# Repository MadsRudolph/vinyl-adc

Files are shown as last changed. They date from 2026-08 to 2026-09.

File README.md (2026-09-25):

# Vinyl ADC

[Assembly guide & bench log](https://vinyl-adc.madsrudolph.dev/) · [Bring-up log, 16–18 September](docs/bringup-log-2026-09.md) · [16 September bench plan](assembly/sessions/2026-09-16/README.md) · [6 September test handoff](assembly/sessions/2026-09-06/README.md)

All four boards are assembled and bench-screened with the AD3 (16–17 September): power, rev B digital with the on-board crystal Pierce, both channels and the full stack pass, after resoldering a crystal leg and swapping the reference op-amp U2 to an LM358 for output headroom on the charge-pump rail (design-notes §10b′). A Raspberry Pi 4 captures the stream, and a ripper service on it records sides automatically, splits and tags the tracks and hands finished albums to the Jellyfin server; setup in [pi/README.md](pi/README.md) and [server/README.md](server/README.md). No complete-system audio performance is claimed by these assembly tests.

**Rev C (22 September):** with a fab available, the four milled boards are redrawn as [one 4-layer board](hardware/kicad/rev_c/README.md), 170 × 120 mm, all through-hole, with the Raspberry Pi 4 plugged into its underside on its own 40-pin header and the bench fixes (LM358 reference, filtered 5 V inlet, series resistors on the I2S clocks) built in. It passes the same intent gate as the milled boards against the reference sheet; [production files](production/vinyl_adc_rev_c/) and a [bill of materials](docs/bom-rev-c.md) are exported. It has not been built yet; the measured milled stack above is the baseline it will be compared to.

**Rev D (22 September):** with PCBWay sponsoring the fabrication, the one-board converter is redrawn as a proper [Raspberry Pi HAT](hardware/kicad/rev_d/README.md) — 140 × 136 mm (its layout redone on 24 September: every passive beside the pin it serves, channel R a copy of channel L), four layers, still every part through-hole from the DTU shop — and given the things the bench asked for: an analog supply island behind its own choke (the DAC reference rail, kept away from the Pi's and the charge pump's switching), a second 74HC244 to stiffen the −5 V pump, a damped MCLK, eight front-edge status LEDs (rail, pump, clock-alive, clip L/R from LM339 window comparators, and three under the Pi's control), shutdown and user buttons, a HAT ID EEPROM, test-point headers with ground pins, and a tonearm ground terminal with a lift network. `tools/check_rev_d.py` proves it is the reference circuit plus exactly those additions; [production files](production/vinyl_adc_rev_d/) and the [bill of materials](docs/bom-rev-d.md) are exported. Design record: [design-notes §12](docs/design-notes.md#12-rev-d-the-converter-as-a-raspberry-pi-hat-22-september-2026).

**Rev E (24 September):** the same circuit in common [surface-mount parts](hardware/kicad/rev_e/README.md) on a 118 × 88 mm four-layer HAT — 0805 C0G/X7R and thin-film parts, SOIC logic and op-amps, SOT-23 transistors, shielded SMD chokes — checked by the same gate as rev D, placed and routed by the same tools, DRC clean. [Production files](production/vinyl_adc_rev_e/) include the pick-and-place file for PCBWay assembly; [bill of materials](docs/bom-rev-e.md); design record [design-notes §13](docs/design-notes.md).

<p align="center">
  
  
  
  
  
  
</p>

<p align="center">
  <strong>A Discrete 3rd-Order Continuous-Time Delta-Sigma Stereo Audio ADC</strong><br>
  Engineered from standard analog op-amps &amp; 74HC CMOS logic — <em>zero dedicated ADC ICs anywhere in the signal chain</em>.<br>
  All circuit boards isolation-milled on a <strong>Roland SRM-20</strong> CNC mill using <a href="https://github.com/MadsRudolph/srm-cam"><strong>SRM-CAM</strong></a>.
</p>

<p align="center">
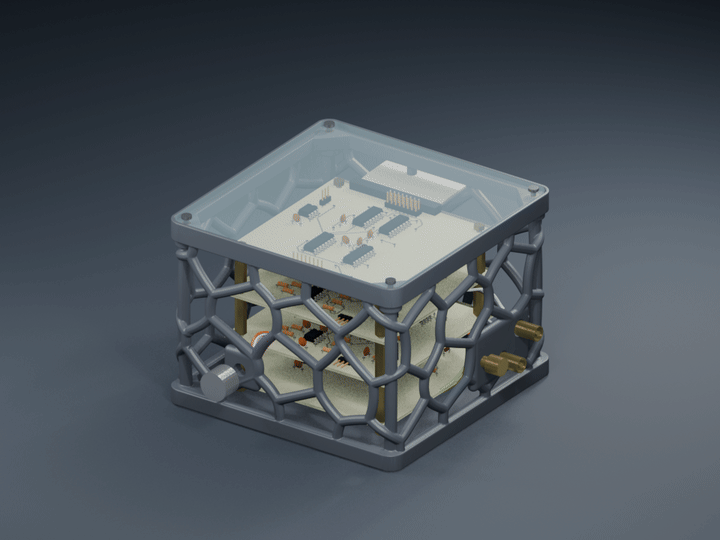
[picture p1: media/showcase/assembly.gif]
Vinyl ADC 3D Exploded Assembly Animation
  
</p>

<p align="center">
  <a href="media/showcase/README.md">Download GIF animations &amp; print files</a>
</p>

<details>
<summary><strong>More views: product orbit and four-board close-up</strong></summary>

### Product orbit

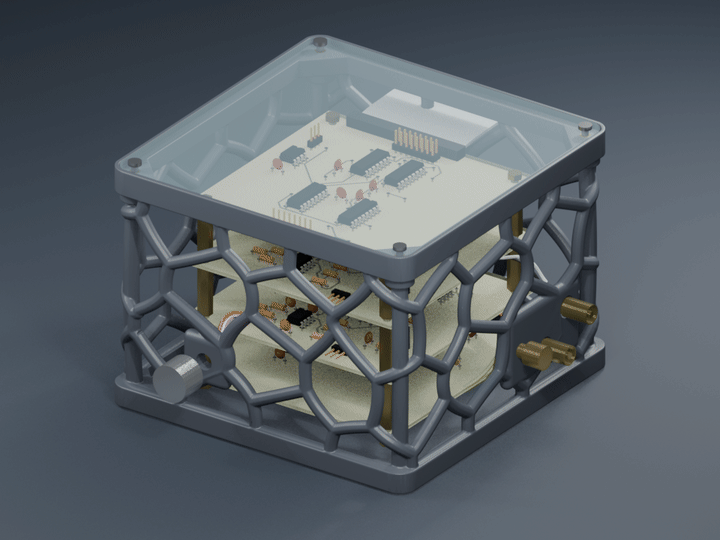
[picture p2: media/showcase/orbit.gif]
Vinyl ADC enclosure rotating through a full turn


### Four-board close-up

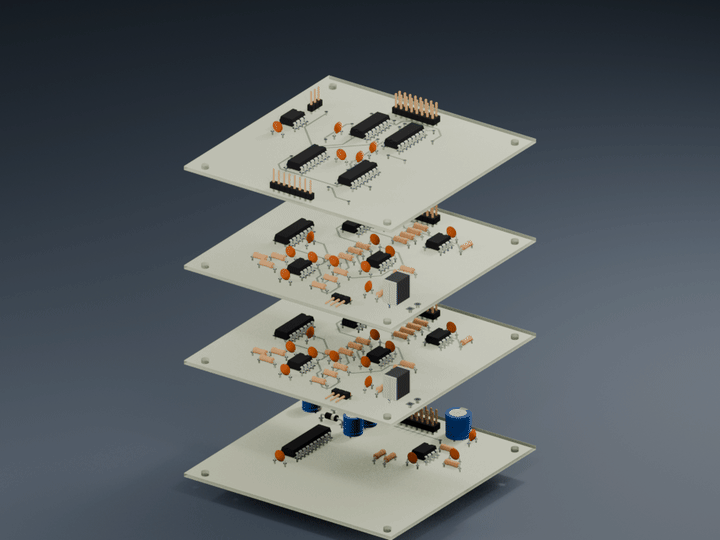
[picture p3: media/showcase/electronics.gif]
Vinyl ADC power, right-channel, left-channel, and digital boards


</details>

<p align="center">
  👉 <strong><a href="https://madsrudolph.github.io/vinyl-adc/">Launch Live Interactive 3D Web Viewer &amp; Explosion Slider</a></strong> 👈
</p>

---

## Audiophile Engineering Specifications

| Specification | Target / Measured Performance | Design Rationale & Implementation |
|---|---|---|
| **Modulator Topology** | Continuous-Time CIFB (Cascade of Integrators, Feedback) | 3rd-order active RC loop with local resonator feedback (`G = 0.03`) |
| **Dynamic Range / SNR** | **68.3 dB measured in 20 kHz band** | Purposefully matched to the physical vinyl surface noise floor (~60–65 dB) |
| **Audio Output** | **24-bit / 48 kHz Linear PCM FLAC** | Decimated in software on Raspberry Pi CPU (CIC filter + compensation FIR) |
| **Modulator Sampling Rate ($F_s$)** | **1.536 MHz** ($32\times$ OverSampling Ratio) | Matches bandwidth constraints of DTU-stocked op-amps (`TL072` 3 MHz GBW) |
| **Master Clock ($F_{clk}$)** | **6.144 MHz crystal Pierce oscillator** (74HCU04 + HC-49 crystal) | Direct low-jitter clock ($<50\text{ ps}$ jitter vs. Pi PLL phase noise); also available as a plug-in module for the rev A board |
| **Digital Stream Format** | Bit-Interleaved PDM on standard I2S bus | 3.072 Mbps data stream, read as 32-bit stereo audio frames at 48 kHz |
| **Analog Inputs** | Gold RCA Phono Jacks &amp; 5.08 mm Screw Terminals | Switchable input gain via front-panel multi-turn trim potentiometer |
| **Analog Grounding** | Star-ground topology with tonearm binding post | Eliminates 50 Hz turntable motor hum and ground-loop switching transients |
| **PCB Manufacturing** | Isolation-milled single-sided copper FR4 | Toolpaths generated via [**SRM-CAM**](https://github.com/MadsRudolph/srm-cam) on a **Roland SRM-20** mill |
| **Enclosure Dimensions** | $144.0\text{ mm} \times 144.0\text{ mm} \times 105.0\text{ mm}$ | Open organic lattice, reinforced connector islands and M3 lid inserts; recessed $3.0\text{ mm}$ acrylic lid |

---

## Printable enclosure

The enclosure has an open, rounded lattice on all four sides and 40 mm more height for the PCB stack and cable routing. Solid connector islands and reinforced lid-insert bosses carry the mounting loads. **Print upright with supports**; the revised mesh and supported slice pass validation, but physical print/fit testing is still pending.

[STL, 3MF, insert-fit coupon and printing instructions](enclosure/README.md) · [Three looping GIFs](media/showcase/README.md)

## Signal Processing Flow

```
   ┌─────────────────────────────────────────────────────────────────────────────┐
   │                          ANALOG SIGNAL CHAIN (HARDWARE)                     │
   │                                                                             │
   │  Turntable (Debut Carbon)                                                  │
   │         │                                                                   │
   │         ▼                                                                   │
   │  Phono Preamplifier                                                         │
   │         │                                                                   │
   │         ▼                                                                   │
   │  [ VINYL ADC ] ──> 3rd-Order CT-ΔΣ ──> 1.536 MHz PDM ──> 74HC157 Mux       │
   │   Gold RCA In      TL072 + LM311       74HC74 Retimed    Stereo Interleave  │
   └─────────────────────────────────────────────────────────────────┬───────────┘
                                                                     │ 3.072 Mbps
                                                                     ▼
   ┌─────────────────────────────────────────────────────────────────────────────┐
   │                         DIGITAL DSP CHAIN (RASPBERRY PI)                    │
   │                                                                             │
   │  ALSA I2S Interface (48 kHz / 32-bit Frame Capture)                         │
   │         │                                                                   │
   │         ▼                                                                   │
   │  Software De-interleaver (Separates Left & Right Bitstreams)                │
   │         │                                                                   │
   │         ▼                                                                   │
   │  4th-Order CIC Decimator (Downsamples 32x to 48 kHz Nyquist)                │
   │         │                                                                   │
   │         ▼                                                                   │
   │  FIR Droop & Phase Compensation Filter                                      │
   │         │                                                                   │
   │         ▼                                                                   │
   │  24-bit / 48 kHz Bit-Perfect FLAC Encoder ──> Jellyfin Media Server         │
   └─────────────────────────────────────────────────────────────────────────────┘
```

---

## Noise-Shaping & SPICE Verification

The defining characteristic of delta-sigma conversion is **noise shaping**: pushing quantization noise out of the audible spectrum into ultrasonic frequencies where digital decimation filters remove it completely.

<p align="center">
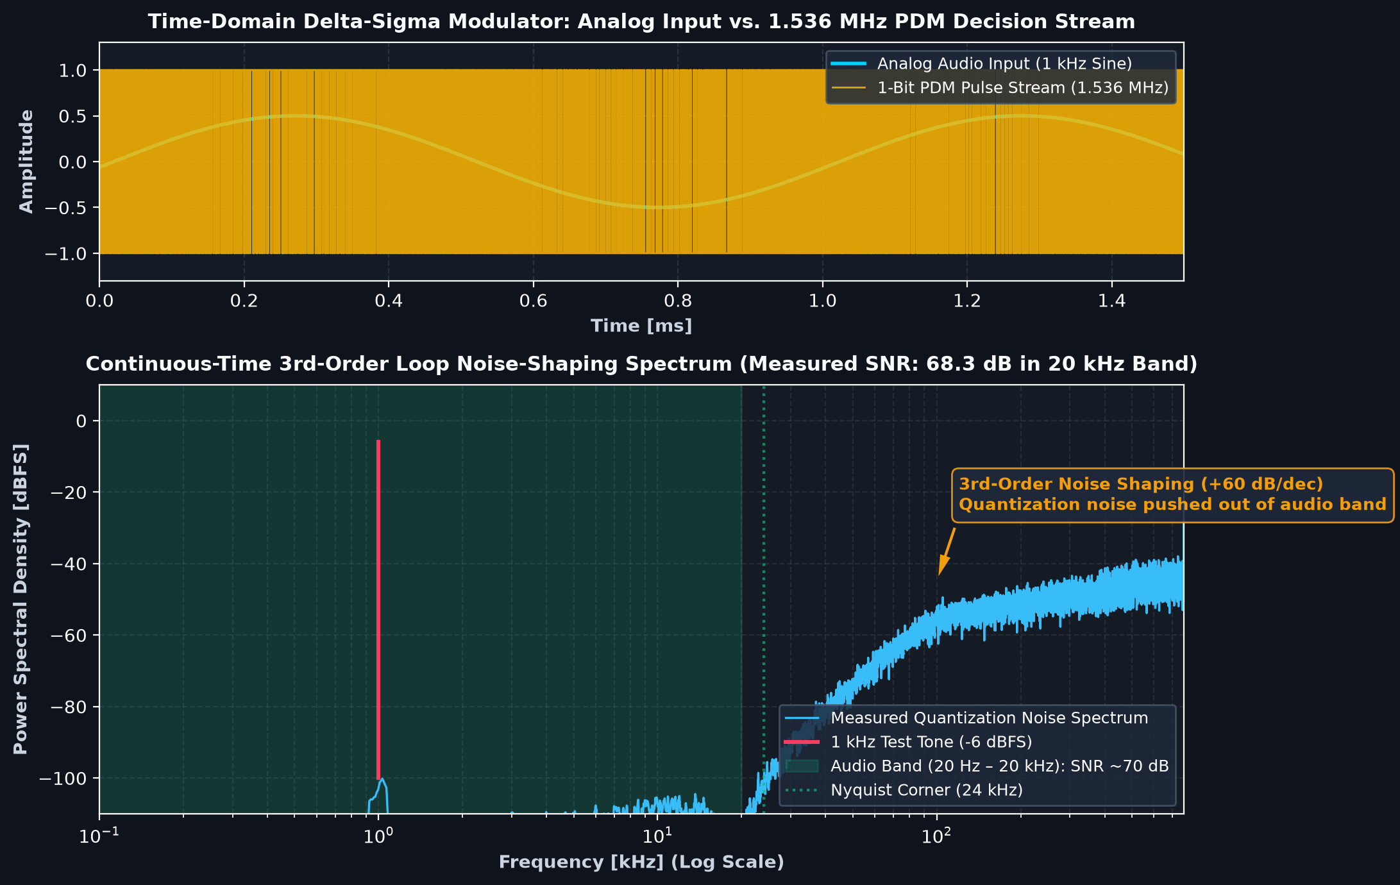
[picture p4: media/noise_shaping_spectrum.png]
Noise-Shaping Spectrum & PDM Waveform
  
</p>

- **Time-Domain (Top):** Shows the incoming 1 kHz analog test sine wave alongside the discrete 1.536 MHz 1-bit decision stream. The pulse density cleanly mirrors the instantaneous input amplitude.
- **Frequency-Domain (Bottom):** Measured FFT spectrum with Hann windowing. The audible passband (20 Hz – 20 kHz, shaded green) exhibits a **68.3 dB SNR** with clean third-order $+60\text{ dB/decade}$ noise shaping that drives quantization noise above 30 kHz.

---

## The 4-Board PCB Stack

To overcome the routing limitations of single-layer CNC isolation milling (0.84 mm clearance between DIP pins), the system is split into four 100 × 100 mm boards interconnected by a 16-pin ribbon bus and M3 brass standoffs:

| Tier & Board | 3D Raytraced Board Render | Function & Key Components |
|---|:---:|---|
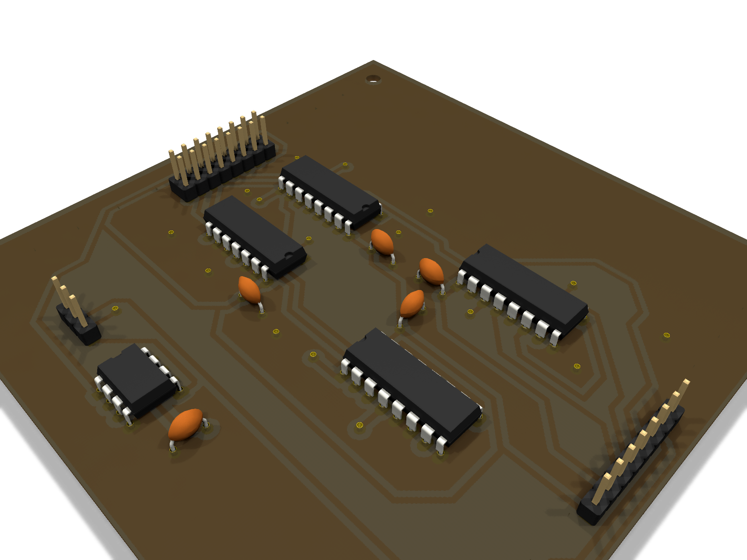
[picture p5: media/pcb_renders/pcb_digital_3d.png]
Digital Board 3D Render
| **Tier 4 (Top)**<br>[`vinyl_adc_digital`](hardware/kicad/digital/) |  | **Clock, Interleaving & Pi Interface:**<br>• 6.144 MHz crystal Pierce oscillator (`Y1` + `74HCU04`)<br>• `74HCT132` Schmitt-trigger clock buffer<br>• `74HC4040` binary clock divider ($F_s = 1.536\text{ MHz}$, $\text{BCLK} = 3.072\text{ MHz}$, $\text{LRCLK} = 48\text{ kHz}$)<br>• `74HC157` stereo bit-interleaving MUX<br>• `74HC4049` 5 V $\rightarrow$ 3.3 V level shifter to Raspberry Pi |
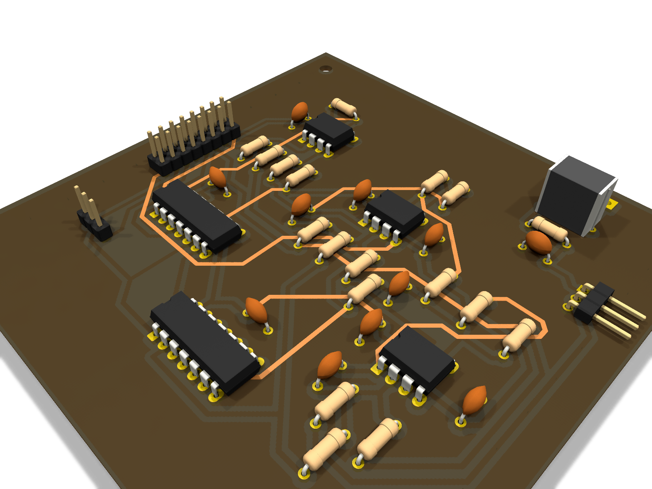
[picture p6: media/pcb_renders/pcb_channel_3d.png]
Left Channel Modulator 3D Render
| **Tier 3**<br>[`vinyl_adc_channel_l`](hardware/kicad/channel_l/) |  | **Left Channel Modulator:**<br>• 3rd-order active RC integrators (`TL072`)<br>• `LM311` high-speed comparator<br>• `74HC74` retiming flip-flop &amp; 1-bit DAC network<br>• Multi-turn input gain trim potentiometer<br>• Jumper set to Left (`pins 1-2`) |
| **Tier 2**<br>[`vinyl_adc_channel_r`](hardware/kicad/channel_r/) | Right Channel Modulator 3D Render | **Right Channel Modulator:**<br>• Identical artwork to Tier 3 (milled twice)<br>• Jumper set to Right (`pins 2-3`)<br>• Independent ground plane &amp; analog reference |
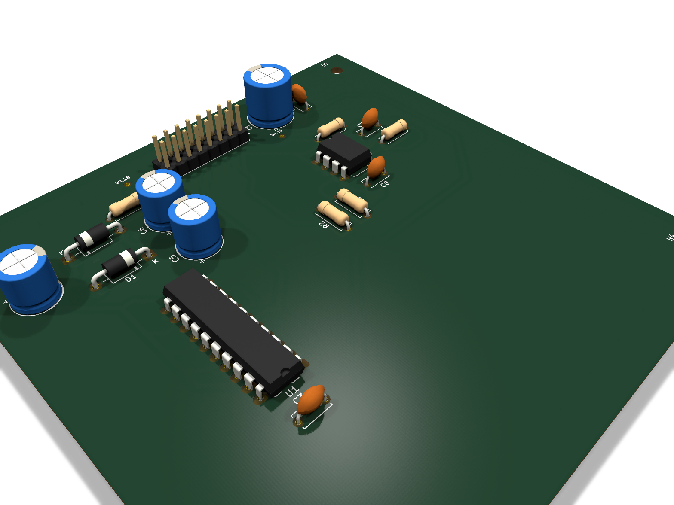
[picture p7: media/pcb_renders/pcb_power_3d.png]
Power Supply Board 3D Render
| **Tier 1 (Base)**<br>[`vinyl_adc_power`](hardware/kicad/power/) |  | **Power & Reference Generation:**<br>• `74HC244` + `1N5817` charge-pump negative rail<br>• Low-noise precision virtual ground reference (`TL072`)<br>• High-capacity bulk reservoir &amp; post-filter network<br>• 4× M3 mounting holes seated onto enclosure floor bosses |

---

## PCB Fabrication with SRM-CAM & Roland SRM-20

All boards in this project are physical hardware designed for single-sided isolation milling on the **Roland SRM-20** desktop CNC mill at the DTU FabLab.

<p align="center">
  
</p>

The RML-1 milling toolpaths and G-code were generated directly using [**SRM-CAM**](https://github.com/MadsRudolph/srm-cam) (`gerber2rml`):
- **Isolation Routing:** Traces isolation-milled on `B.Cu` using 0.2 mm / 0.4 mm V-bits with wide rubout for ground separation.
- **Excellon Drilling:** Automatic hole-center extraction from KiCad `*.drl` files for all DIP sockets, film caps, resistors, and headers.
- **Edge Routing:** Clean board profiling with 1.0 mm end mill for the 100 × 100 mm PCB footprint and M3 mounting holes.
- **Workpiece Fixturing:** Copper-clad FR4 secured using the double-sided tape &amp; CA glue method documented in the [SRM-CAM User Guide: Holding the copper](https://madsrudolph.github.io/srm-cam/holding-the-copper.html).

All production Gerbers and Excellon drill files ready for SRM-CAM are located in [`production/`](production/).

---

## Raspberry Pi Wiring & Star-Grounding Architecture

Turntable systems are exceptionally sensitive to 50/60 Hz hum and digital switching noise. The Vinyl ADC implements an isolated star-grounding architecture:

```mermaid
graph TD
    subgraph Analog Front-End
        TT["Turntable Ground Spade"] --- Post["Chassis Ground Binding Post"]
        RCA["RCA Input Outer Shield"] --- Post
        Post --- Star(("★ STAR GROUND"))
        Star --- Tier1["Tier 1 Analog Virtual Ground"]
    end

    subgraph Raspberry Pi Connection
        Star -.->|Isolated Digital Return| Pi_GND["Pin 6 / 9 (GND)"]
        Tier4["Tier 4 Logic Bus"] -->|Pin 12 / GPIO 18| Pi_BCLK["PCM_CLK (3.072 MHz)"]
        Tier4 -->|Pin 35 / GPIO 19| Pi_LRCLK["PCM_FS (48 kHz)"]
        Tier4 -->|Pin 38 / GPIO 20| Pi_DIN["PCM_DIN (3.072 Mbps)"]
        Pi_Power["Pin 2 / 4 (+5V)"] -->|Filtered DC Rail| Tier1_Pwr["Tier 1 Power In"]
    end
```

### Raspberry Pi 40-Pin GPIO Pinout:

| Raspberry Pi Pin | Signal Name | Vinyl ADC Connection | Function |
|---|---|---|---|
| **Pin 2 or 4** | `+5V Power` | Tier 1 DC Input | Supplies digital and analog converter power |
| **Pin 6 or 9** | `GND` | Tier 4 Logic Ground | Digital switching current return |
| **Pin 12 (GPIO 18)** | `PCM_CLK` | Tier 4 Clock Out | 3.072 MHz bit clock for I2S capture |
| **Pin 35 (GPIO 19)** | `PCM_FS` | Tier 4 Frame Sync | 48 kHz word clock (L/R frame framing) |
| **Pin 38 (GPIO 20)** | `PCM_DIN` | Tier 4 Interleaved PDM | Serial stream carrying alternating Left/Right bits |

---

## Repository Structure

```
├── docs/                           # Documentation & Interactive Web App
│   ├── index.html                 # Interactive 3D Web Viewer for GitHub Pages
│   ├── vinyl_adc_assembled.glb    # Complete 3D CAD model with explosion timeline
│   ├── shopping-list.md           # Component shop procurement list
│   ├── bom.md                     # Bill of materials
│   └── design-notes.md            # Circuit design decisions and SPICE findings
├── enclosure/                      # 3D print and laser cutting files
│   ├── vinyl_adc_enclosure.blend  # Complete Blender 3D CAD scene
│   ├── vinyl_adc_enclosure_base.3mf # Millimetre print mesh
│   ├── vinyl_adc_enclosure_base.stl # Watertight binary STL
│   ├── vinyl_adc_plexiglass_top.svg # 1:1 Spirit laser cutter SVG
│   ├── vinyl_adc_plexiglass_top.dxf # 1:1 AutoCAD R12 DXF
│   └── *.glb                      # 3D board exports from KiCad
├── hardware/kicad/                 # KiCad 10 schematics, boards & routing
│   ├── power/                     # Tier 1: Power & voltage reference board
│   ├── channel_l/                 # Tier 2 & 3: Modulator channel (milled twice)
│   ├── digital/                   # Tier 4: Digital clock & Pi interface
│   ├── sim/                       # 8x SPICE testbenches for loop validation
│   └── tools/                     # Python layout and netlist verification scripts
├── production/                     # Production-ready Gerbers and Excellon drill files for SRM-CAM
├── media/                          # Visuals, renders, and animations
│   ├── vinyl_adc_assembly.gif     # Looping 3D exploded view animation
│   ├── vinyl_adc_assembly.mp4     # 720p 24fps H.264 animation video
│   ├── noise_shaping_spectrum.png # Continuous-time 3rd-order FFT plot
│   ├── laser_engraved_lid.png     # Clear acrylic lid technical artwork
│   └── pcb_renders/               # Raytraced KiCad 3D renders of each PCB tier
└── sim/                            # Modulator numerical simulation models
```

---

## Interactive 3D Web Viewer

Test the 3D model and scrub the exploded assembly timeline directly in your browser:  
🔗 **[https://madsrudolph.github.io/vinyl-adc/](https://madsrudolph.github.io/vinyl-adc/)**

---

## Related Projects

- [**SRM-CAM (`gerber2rml`)**](https://github.com/MadsRudolph/srm-cam): Desktop CAM for the Roland SRM-20 CNC mill used to isolation-mill the PCBs for this project.

---

## License

MIT License — free for personal and educational use.

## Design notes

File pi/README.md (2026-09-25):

# Raspberry Pi capture

The ADC is the I²S clock master; the Pi only listens. Status: the wiring and clocking follow the schematic and the 17 September bench screen (PI_BCLK 3.0727 MHz, PI_LRCLK 48.011 kHz, PI_DIN toggling, all 3.3 V logic). The overlay compiles and `decimate.py` passes its synthetic test, and on 17 September the overlay was installed on a Pi 4 (Pi OS Trixie, kernel 6.18): the `vinyladc` capture card registers and the I²S block programs 64-bit frames in consumer mode. **No capture from the real ADC has been decoded yet**; treat the first one as bring-up.

## 1. Wiring: digital board J2 → Pi 40-pin header

J2 is the single row of 8 on the digital board; pin 1 is the square pad.

| J2 pin | Signal | Pi pin | Notes |
|---|---|---|---|
| 1 | +5 V | 2 (5 V) | **Leave open for the first power-up**, see below |
| 2 | GND | 6 | |
| 3 | +3.3 V | 1 (3V3) | Powers only the 74HC4049 level shifter. Remove the AD3 V+ wire first |
| 4 | PI_BCLK | 12 (GPIO18, PCM_CLK) | 3.072 MHz, from the ADC |
| 5 | PI_LRCLK | 35 (GPIO19, PCM_FS) | 48 kHz, from the ADC |
| 6 | PI_DIN | 38 (GPIO20, PCM_DIN) | interleaved modulator bits |
| 7 | GPCLK0 | leave open | only for clocking the ADC from the Pi (J1 on 2–3); J1 stays on 1–2, the crystal |
| 8 | GND | 39 | |

Keep these wires short (10 cm jumpers are fine) and run the two grounds.

## 2. Power

**First power-up (recommended): keep the Korad.** J2.1 stays on the Korad at 5.00 V with the 0.30 A limit, exactly as in the bench tests, and is *not* connected to the Pi. The Pi shares ground, supplies the 3.3 V and receives the three signals. A wiring mistake then trips the Korad instead of loading the Pi's 5 V rail. The stack draws about 74 mA.

**Final build:** Pi pin 2 → J2.1 and no Korad. Never connect both 5 V sources at once.

**Power-up order: boot the Pi first, then switch the ADC's +5 V on.** Measured on a Pi 4 (Pi OS Trixie, kernel 6.18): the I²S block comes out of reset as clock *master*, so from the moment the driver claims GPIO18/19 until a capture device is first opened, both clock pins are **outputs** (`MODE_A = 0`). `vinyl-adc-consumer.service` (installed by `install-overlay.sh`) opens the device once at boot and logs the pin state before and after; it finishes about 22 s after kernel start, and from then on both pins are inputs (`CLKM = FSM = 1`). With the ADC unpowered during that window its level shifter outputs sit low, the same level the Pi drives, so nothing fights. `sudo python3 pcm_pins.py` shows the current direction at any time.

For the final build, where the Pi's own 5 V powers the stack and the ADC therefore clocks during the Pi's boot, fit about 470 Ω in series with PI_BCLK and PI_LRCLK so the ten-second overlap is current-limited to a few milliamps.

The 74HC4049 itself is safe in either order: it accepts 5 V inputs with its own supply at 0 V, and its outputs can never exceed the Pi's 3.3 V because that is its supply.

The Pi must not drive GPIO18/19. They are inputs by default and with this overlay. Remove any other I²S sound overlay (hifiberry, iqaudio, googlevoicehat, i2s-…) from `config.txt` before connecting, because a Pi configured as I²S master would fight the ADC's clock outputs.

## 3. Pi setup (once)

Copy this `pi/` folder to the Pi, then on the Pi:

```sh
sudo apt install device-tree-compiler python3-numpy
cd pi && ./install-overlay.sh
sudo reboot
```

`vinyl-adc-overlay.dts` is the capture twin of the stock `i2s-master-dac` overlay: I²S controller in clock-consumer mode, two 32-bit slots, with the S/PDIF receiver stub as a dummy capture codec.

After the reboot:

```sh
arecord -l        # expect: card N: vinyladc [vinyl-adc], device 0
```

## 4. Capture and decimate

```sh
arecord -D hw:CARD=vinyladc -c 2 -r 48000 -f S32_LE -t raw -d 10 capture.raw
python3 decimate.py capture.raw capture.wav
```

The 32-bit words are not PCM: each 64-bit frame carries 32 left and 32 right modulator bits at 1.536 MHz. `decimate.py` de-interleaves them and decimates by 32 (4th-order CIC to 192 kHz, then a 161-tap droop-compensating FIR), printing each bitstream's one-density and the DC, RMS and peak per channel before writing a 32-bit 48 kHz WAV. `python3 test_decimate.py` checks it against a synthetic stream (1 kHz at 0.5 FS and 18 kHz at 0.25 FS recover within 0.03 dB).

`python3 analyze_bitstream.py capture.raw` judges each modulator from the raw bits at 1.536 MHz: in-band floor, noise-shaping slope (about +60 dB/decade just above the audio band for a healthy third-order loop) and the idle tone, which sits at |DC| × 1.536 MHz.

**First capture, inputs still shorted:** expect both one-densities near 0.50 (the bench measured 0.50 and 0.53 per channel, 0.516 combined), a small DC term and a low RMS noise floor.

**Left/right:** by the divider's phase the first bit after the frame edge belongs to the left channel. Confirm by feeding a signal into the LEFT input only; if it appears on the right, add `--swap`.

## 5. The ripper and its dashboard

`vinyl-adc-ripper.service` starts at boot and owns the capture card. Dashboard: **http://vinyladc.local:8091**.

- **Automatic.** When the level stays above the start threshold for two seconds a *side* is recorded to `~/vinyl/sides/` (with 2.5 s of pre-roll); 30 s of silence (80 % of a 30 s window below −65 dB, a rule that survives the clicks of a lifted needle but not the long gap after a fade-out) closes it. The detector is treble-weighted, so mains hum cannot trigger it, and it uses a window rather than a run, so isolated clicks do not keep a finished side open. Sides shorter than 90 s are discarded.
- **The record identifies itself.** Two minutes into a side the ripper fingerprints the audio so far (Chromaprint's `fpcalc`, package `libchromaprint-tools`) and asks [AcoustID](https://acoustid.org) which recording it is. From the answer it picks the release (the album already in use wins if one of its recordings matched; otherwise a vinyl pressing is preferred), fetches the tracklist from MusicBrainz and knows which track the side started with. Playing side B first, or dropping the needle in the middle, therefore works. This needs a free AcoustID *application* key: register one at <https://acoustid.org/new-application> and write it to `~/vinyl/acoustid.key` on the Pi (one line), then restart the service. Without the key the dashboard says so and you pick the album by hand with the MusicBrainz search, before or after playing it.
- **Where the side starts.** The identified track is an *anchor* (which track starts at which second of the side): tracks before it are counted back from there, tracks after it forward, so a needle dropped mid-side is handled. Tracks that were not played whole (dropped into, or lifted from) are marked incomplete and are neither counted nor encoded.
- **Cutting.** After a side closes, the music's start and end are found from 3 s windows (single clicks do not count and fade-outs are kept), gaps are recomputed from the finished envelope and merged across clicks, and the side is matched to the tracks from its starting point by duration. Each cut is snapped to the quiet gap nearest the expected boundary (within 15 s); where tracks run into each other it lands on the quietest second near the expected time.
- **Nothing to do.** A side of a record whose tracks are already in the library is moved to the trash instead of being assigned again. An album that has not received a side for three hours is sent as it is, and so is an album in progress when a different record is identified, so one side played on its own still ends up in Jellyfin. When the disk drops below 3 GB free the ripper removes trash and the raw audio of albums already delivered, oldest first (`min_free_gb`).
- **Finishing.** When the last side is in, or on "Finish and send", all tracks get one common gain (album peak to −1 dBFS), are encoded to 24-bit 48 kHz FLAC, tagged (title, artist, album, track and disc numbers, date, MusicBrainz ids, `MEDIA=Vinyl`), given the Cover Art Archive front cover, and published under `~/vinyl/library/` and at `/outbox.json`.
- **Delivery.** `server/vinyl-pull.py` on the media server polls the outbox every two minutes and files albums under `/srv/media/music/Vinyl/Artist/Album (Year) [Vinyl]/`. See `server/README.md`.
- **Channel faults.** A channel whose bitstream is stuck or oscillating is detected from its run lengths; the healthy channel is then recorded to both sides (mono) and the dashboard says so. Runs of 7+ identical bits, which music never produces, are repaired in the bitstream before decimation.
- **For measurements** the ripper serves the last 60 s of decimated audio at `/api/audio?seconds=N` (float32 stereo, 48 kHz) and `/api/hold {seconds}` keeps it from recording test tones as a side; `assembly/bench/run.py audio` uses both.
- Offline tests: `python3 test_ripper.py` (identification, cutting, repeat plays) and `python3 ripper.py --replay capture.raw --fast --home /tmp/vinyl`.

`live.py` (`vinyl-adc-live.service`, disabled) is the diagnostic view with the modulator noise spectra; the two services conflict because only one process can hold the capture card: `sudo systemctl start vinyl-adc-live` stops the ripper, and starting the ripper again stops the live view.

## 6. If it does not work

| Symptom | Check |
|---|---|
| `arecord -l` shows no vinyl-adc card | `dmesg | grep -i -E 'i2s|asoc|simple-card|spdif'`; is `dtoverlay=vinyl-adc` in `config.txt`; is another sound overlay claiming I²S |
| `arecord` starts but writes nothing, then times out | The Pi is a clock consumer: no BCLK/LRCLK, no data. Check the stack is powered, J1 on 1–2, 3.3 V on J2.3, GPIO18/19 wiring |
| One-density 0.000 or 1.000 | Data line stuck: J2.6 ↔ GPIO20, that channel's J21 shunt, the bus |
| One channel fine, the other dead | That channel board or its J21 (left 1–2, right 2–3; pin 1 is the pin farthest from the bus) |
| Audio present but sounds like noise | Word alignment differs from the I²S assumption: try `--swap`; if still wrong, keep the `.raw` file, it contains everything needed to fix the unpacking offline |

## 7. Rev D HAT: what the board puts on the GPIO header

Rev D (`hardware/kicad/rev_d/`) plugs the Pi in directly and uses more of
the header than the I²S trio. Nothing here is required for capture; the
overlay and the ripper work unchanged.

| Pi pin | GPIO | Board | Direction | Software |
|---|---|---|---|---|
| 12 / 35 / 38 | 18 / 19 / 20 | PI_BCLK / PI_LRCLK / PI_DIN | in (Pi is I²S consumer) | `vinyl-adc-overlay.dts`, as before |
| 7 | 4 | GPCLK0 to J1 pin 3 | out, bring-up only | as before |
| 11 | 17 | LED REC (red) through 330 R | out, active high | ripper: side being recorded |
| 13 | 27 | LED BUSY (yellow) | out, active high | ripper: identifying / encoding / delivering |
| 15 | 22 | LED READY (green) | out, active high | ripper idle and the capture card open |
| 5 | 3 | SW1 SHUTDOWN / WAKE, to ground through 1 k | in, Pi's own 1k8 pull-up | `dtoverlay=gpio-shutdown` in `config.txt`; a halted Pi wakes on the same button |
| 16 | 23 | SW2 USER, to ground through 1 k | in, needs the internal pull-up | ripper: start / stop a side (not written yet) |
| 27 / 28 | ID_SD / ID_SC | 24LC32 HAT EEPROM, optional, J6 shorted to write | — | `eepflash.sh` from the `hats` repo; leave empty and keep `dtoverlay=vinyl-adc` |
| 2, 4 / 1, 17 | 5V / 3V3 | board power through L1; 3V3 for the level shifter and the EEPROM | — | the board draws ~100 mA at 5 V |

GPIO3 doubles as I²C1 SCL, which nothing on this Pi uses. The three LED
lines and SW2 are plain `gpiozero` `LED` / `Button` objects; wiring them
into `ripper.py` is a small follow-up.

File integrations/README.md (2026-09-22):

# Home Assistant

Two separate paths, deliberately, because they need different trust.

## Notifications — no credential anywhere

The ripper POSTs JSON to an HA **webhook** (`notify_url` in its config) when a side starts,
a side finishes, the needle crosses into a new track, or an album reaches the library.
Webhooks are unauthenticated by design, so the Pi holds no token at all. The HA automation
`vinyl_rip_notifications` turns the payload into a push notification.

A finished side carries `channel_gap_db`; past 4 dB the notification is sent red and at high
importance. That exists because on 2026-09-20 the left channel's input came loose 33 minutes
into a rip and nothing said so until the record was already in the library.

## Dashboard sensors — a token, and not on the Pi

`vinyl-ha-bridge` polls the ripper and pushes `sensor.vinyl_ripper`,
`sensor.vinyl_{left,right}_peak` and `binary_sensor.vinyl_channel_fault` into HA through its
states API. That needs a long-lived token, which is full admin access to Home Assistant.

**It runs on the Proxmox host, not on the Pi.** The Pi serves an unauthenticated dashboard to
the whole LAN, so a token there would mean anything reaching the ripper could control the
house. The host already has root over every guest, so the token adds no exposure there that
does not already exist.

    scp integrations/vinyl-ha-bridge.py    root@192.168.50.200:/usr/local/bin/vinyl-ha-bridge
    scp integrations/vinyl-ha-bridge.*     root@192.168.50.200:/etc/systemd/system/
    # the token goes to /etc/vinyl-ha-token, mode 600, and is never echoed
    ssh root@192.168.50.200 'systemctl daemon-reload && systemctl enable --now vinyl-ha-bridge.timer'

These entities come from the states API rather than an integration, so an HA restart drops
them and the timer puts them back within 30 s. That is the trade for needing no YAML in
`configuration.yaml`, which no HA API can write.

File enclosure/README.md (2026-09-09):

# Organic lattice enclosure

The 144 × 144 × **105 mm** shell is 40 mm taller than the original. An open network of rounded branches wraps all four sides, with solid mounting islands around the existing front control, RCA/ground connectors and rear cable exit. The floor supports the PCB stack; the acrylic lid remains removable with four M3 heat-set inserts.

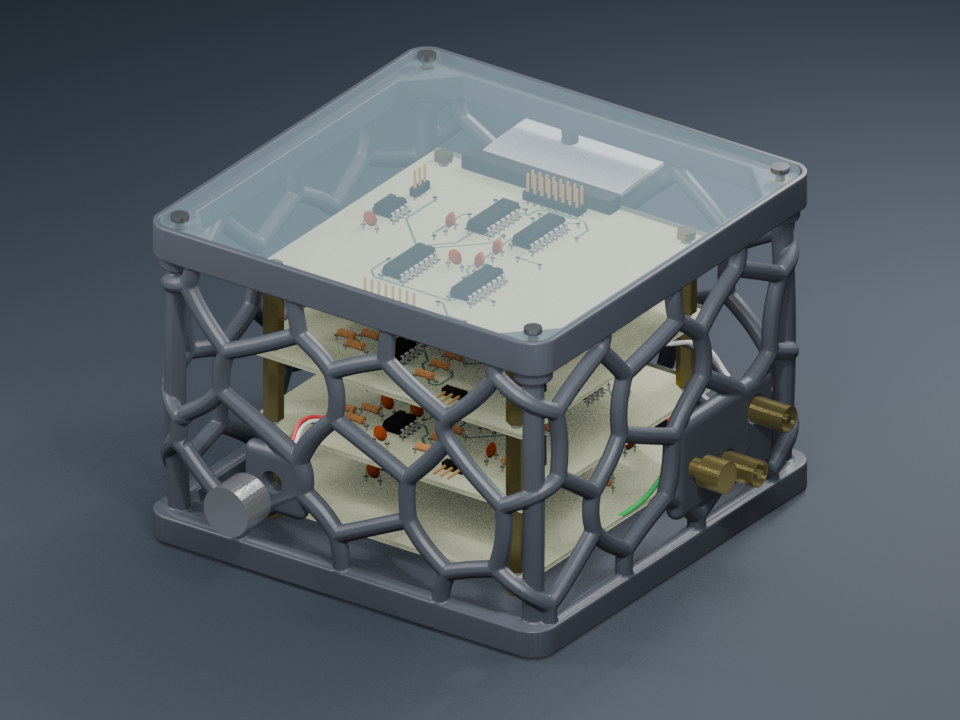
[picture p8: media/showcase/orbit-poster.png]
Assembled enclosure


## Print files

- [Enclosure STL](vinyl_adc_enclosure_base.stl) — one connected, watertight shell, millimetres.
- [Enclosure 3MF](vinyl_adc_enclosure_base.3mf) — the same geometry with explicit millimetre units; no printer or filament profile is embedded.
- [Insert-fit coupon](m3_insert_fit_coupon.stl) — a 48 × 16 × 9 mm test piece, with labelled 4.0, 4.2, 4.4 and 4.6 mm blind holes, each 6.5 mm deep.
- [Geometry print settings](print-settings.ini) — reference settings for PrusaSlicer; select your actual printer and filament profiles separately.
- [Blender assembly](vinyl_adc_enclosure.blend) — editable scene with PCBs, hardware and an exploded timeline. Only the enclosure base is exported to the print files.

## Printing

Print upright with the flat floor on the bed. **Supports are required** beneath shallow lattice branches, mounting islands and the upper rim. Use organic supports, including supports starting on the inside floor; restricting supports to the build plate can leave interior overhangs unsupported. Remove supports before installing inserts and electronics.

The reference slice uses a 0.4 mm nozzle, 0.2 mm layers, four perimeters, 20% infill, five top/bottom layers, 45° support threshold and 0.25 mm support contact gap. PETG is the proposed material; temperatures, cooling, speeds and bed preparation must come from the actual printer/filament profile. Adjust support separation after a small trial. Prusa describes [organic support settings](https://help.prusa3d.com/article/organic-supports_480131) and [PETG printing considerations](https://help.prusa3d.com/article/petg_2059).

Branches are nominally 5.4 mm in diameter and thicken near the connector islands. The four corner load paths are 6.8 mm in diameter. Each top insert sits in a 12 mm diameter boss, so installation and lid-screw loads are carried into the frame. Rounded fused junctions connect the whole print; there are no separate loose ribs.

Do not treat a successful slice as a physical strength or fit test. This revision has not yet been printed. The first assembly should verify support removal, connector nut engagement and cable bend clearance before fitting all electronics.

## Lid and insert fit

The original 140 × 140 × 3 mm acrylic lid, corner shape, cut files and hole positions are retained. Its underside sits at Z = 102 mm. Top insert centres remain X/Y = ±64 mm; PCB mounting centres remain X/Y = ±44 mm.

Top insert pilots are **4.2 mm diameter × 6.5 mm deep**, matching the existing design's approximately 4.6 mm OD, 5.7 mm long M3 insert visualization. M3 inserts vary by manufacturer: print the coupon in the same material and orientation, and match the insert supplier's specified pilot and installation method before printing the full shell. A different insert may require a pilot adjustment; do not force an oversized insert into the frame. The floor fixing geometry is retained from the original design.

Connector centres and cutouts remain at their original coordinates: two 9.5 mm RCA bores, a 6 mm ground-post bore, a 7.5 mm control bore, and a 54 × 10 mm rear cable opening. These are existing design dimensions, not new measurements of the installed hardware. The opening positions do not depend on board spacing; cables route between the boards and panel connectors.

## Stack height

The extra 40 mm is usable enclosure height. The CAD visualization uses 23 mm inter-board standoffs to show a taller stack; this is illustrative because the physical stack was unavailable to measure. In this model, the tallest top-board component reaches Z = 93.94 mm, leaving approximately 8.06 mm under the acrylic. Actual stack height, connector shells and cable loops must fit below Z = 102 mm. The retained PCB meshes are assembly illustrations and may lag newer KiCad component revisions.

## Validation and rebuilding

[validation.json](validation.json) records the mesh checks and sampled rib widths. [slice-validation.json](slice-validation.json) records the supported slice. Cross-section samples are checks at selected rib locations, not a proof of a global minimum wall thickness or mechanical load rating.

Run from the repository root with Blender 5.2:

```sh
blender --factory-startup -b -noaudio --python enclosure/build_enclosure.py
blender --factory-startup -b -noaudio --python enclosure/build_insert_coupon.py
blender --factory-startup -b enclosure/vinyl_adc_enclosure.blend -noaudio --gpu-backend opengl --python enclosure/animation/render_showcase.py
python enclosure/animation/encode_showcase.py
```

`build_enclosure.py -- --standoff 23` changes the illustrative inter-board spacing. It does not move panel cutouts. The retained source in `source/original_assembly.blend` supplies the existing board meshes, acrylic, connector shapes, fixing geometry and animation. The procedural builder replaces the wall skin with a deterministic periodic Voronoi network, fuses rounded joints, simplifies the mesh and recuts the exact connector/pilot openings. The web export merges the explosion tracks into one `Assembly` animation and converts millimetres to metres.

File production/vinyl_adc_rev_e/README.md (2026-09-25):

# Production files: vinyl_adc_rev_e (SMD Raspberry Pi HAT, one board, 4 layers)

Exported by `hardware/kicad/tools/export_rev_d.sh rev_e` from
`hardware/kicad/rev_e/vinyl_adc_rev_e.kicad_pcb`. Upload
`vinyl_adc_rev_e-gerbers.zip` as-is; the loose files in `gerbers/` are the
same set. `vinyl_adc_rev_e.d356` is the IPC-D-356 netlist for the fab's
electrical test.

| Parameter | Value |
|---|---|
| Layers | 4: `F.Cu` signals, `In1.Cu` solid GND, `In2.Cu` +5V / +5VA planes (split), `B.Cu` signals |
| Size | 118 x 88 mm, rectangular, no slots |
| Thickness | 1.6 mm FR-4, 1 oz copper outer and inner (PCBWay 4-layer standard stackup) |
| Smallest track / clearance | 0.25 mm / 0.2 mm (supply nets 0.4 mm, clocks 0.3 mm) |
| Vias | 0.6 mm pad, 0.3 mm drill (tented) |
| Holes | connectors and C20/C60 0.8-1.3 mm PTH, vias 0.3 mm; 3 x 3.2 mm (M3, board) and 4 x 2.7 mm (M2.5, Pi) mounting holes NPTH |
| Surface finish | ENIG (flat pads for the SOICs and 0805s); HASL lead-free works for hand assembly |
| Mask / silk | any colour; silkscreen both sides (the back carries the Pi socket's outline and orientation legend) |
| Min silk text | 0.8 mm |
| Drill files | Excellon, PTH and NPTH separate, absolute origin, mm |
| Gerber format | RS-274X, Protel extensions, no X2 attributes, silk subtracted from mask |
| Electrical test | yes, against `vinyl_adc_rev_e.d356` |

`vinyl_adc_rev_e-layers.pdf/` holds one PDF per layer for a visual check,
`vinyl_adc_rev_e-schematic.pdf` the sheet the board was built from, the
two PNGs are KiCad's 3D renders of each side, and `vinyl_adc_rev_e.step`
the mechanical model for the enclosure. The bill of materials is
`docs/bom-rev-e.md`; the design record is `docs/design-notes.md` §13 and
`hardware/kicad/rev_e/README.md`.

## Assembly

Parts are on the top side only (plus the Pi's 2x20 socket on the copper
side, through-hole). For PCBWay assembly send `docs/bom-rev-e.md` and
`vinyl_adc_rev_e-pos.csv` (top side, mm, origin at the board's top-left
corner as drawn); mark J2 (the Pi socket) as hand-fitted on the bottom.
The through-hole parts (J3, J20, J60, RV20/RV60 headers, J1, J4, J5, J6,
J22, J62, C20, C60) can be fitted by them or by hand afterwards.

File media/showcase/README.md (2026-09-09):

# Vinyl ADC lattice enclosure GIFs

Three seamless six-second loops show the revised 105 mm tall enclosure:

| GIF | View |
| --- | --- |
| [orbit.gif](orbit.gif) | Full 360° product orbit with the assembly closed |
| [assembly.gif](assembly.gif) | Explode and reassemble the PCB stack and acrylic lid |
| [electronics.gif](electronics.gif) | Isolated four-board stack with a gently moving camera |

GIFs are 720 × 540 at 12 fps. Each also has a 960 × 720 PNG poster and a 12 fps H.264 MP4 fallback. The gallery and portfolio display the GIFs, with a still-image toggle and reduced-motion handling. Sizes are recorded in [manifest.json](manifest.json).

[Print files and instructions](../../enclosure/README.md) · [Interactive 3D model](https://madsrudolph.github.io/vinyl-adc/)

These are CAD visualizations, not photographs of a finished print. The taller stack uses illustrative 23 mm inter-board spacers. The electronics view hides the enclosure and wiring for clarity.

## Reproduce

```sh
blender --factory-startup -b enclosure/vinyl_adc_enclosure.blend -noaudio --gpu-backend opengl --python enclosure/animation/render_showcase.py
python enclosure/animation/encode_showcase.py
```

Use `-- --preview` for frames 1 and 37 of each clip, or `-- --clip orbit` for one clip. Editable animation scenes are generated under `enclosure/animation/`; intermediate frames and scenes are ignored by Git. Frame 73 matches frame 1; export stops at frame 72 to avoid a duplicate endpoint. The encoder verifies the source scene hash, frame count, GIF dimensions and duration so mixed or stale frame sequences cannot be published accidentally.

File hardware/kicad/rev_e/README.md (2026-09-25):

# Rev E: rev D's circuit in SMD parts, one 4-layer HAT

Rev D is the through-hole HAT built from the DTU shop's drawers. Rev E is
the same circuit in surface-mount parts from any distributor (or PCBWay's
assembly service), on a board a fifth the size of rev D's first layout.
The sheet is drawn by `tools/rev_e_layout.py`, which calls rev D's block
functions unchanged and only swaps footprints and four part numbers, and
`tools/check_rev_d.py vinyl_adc_rev_e` runs rev D's own gate on it: the
netlist is the reference sheet plus exactly rev D's additions, nothing
inside the modulator loop moved.

## What changed from rev D, part by part

| Rev D (THT) | Rev E (SMD) | Why this part |
|---|---|---|
| axial resistors | 0805, 1 % thin film | hand-solderable, every value in stock everywhere |
| disc ceramics | 0805: C0G for 27 p / 220 p / 1n5, X7R for 100 n | the integrator and filter caps must not change value with voltage |
| 2u2 MKT film (C20, C60) | **same MKT film, through-hole** | 2.2 µF does not exist in C0G, and an X7R in series with the audio is where a ceramic's voltage coefficient would be heard |
| 10 µ electrolytics | 10 µ X5R 25 V, 1206 | lower ESR for the flying cap; the stretch timers run ~0.6 s instead of ~1 s |
| 220 µ / 470 µ radial | 220 µ 16 V 6.3 × 7.7, 470 µ 10 V 8 × 10 SMD cans | the smallest stock cans at those values |
| DIP ICs | SOIC (74HC244 in SOIC-20W) | same pinouts |
| BC547 / BC557 TO-92 | BC847 / BC857 SOT-23 | pinouts differ, so the SYMBOL changes too; the blocks connect by pin name |
| 1N4148 / 1N5817 / 1N4003 | 1N4148W SOD-123 / SS14 SMA / S1M SMA | |
| shop 10 µH 3 A axial chokes | Bourns SRR1260-100M | shielded, 27 mΩ; the island's 2.3 kHz corner unchanged |
| HC-49 crystal | HC-49/SMD | same 6.144 MHz, same load caps |
| 5 mm LEDs, 6 mm THT buttons | 0805 LEDs, 6 × 6 SMD tact switches | |

Connectors stay through-hole: the screw terminals, the pin headers and the
Pi socket take the mechanical load. BOM: `docs/bom-rev-e.md`.

## Floorplan

```
      x 0..62                               x 62..118  (over the Pi)
      y  0..33   CHANNEL L  J20 RV20 -> U20 U22 U21     DIGITAL  Y1 U9 U3 U4
                            U24 U23  J22                          U6 U8 J1 J5 U11
      y 33..42   J3 + lift network | U12 clip windows  PUMP     L1 C1 U1 U10 ...
      y 42..75   CHANNEL R  (channel L, moved 42 down)  ISLAND   L2 C18 U2 ref
      y 75..88   LED drivers, then the front row: 8 LEDs ........ SW1 SW2
```

118 × 88 mm. The same geography as rev D: inputs on the left edge, the
digital column over the Pi's header, power at the far end from the inputs,
the eight LEDs and two buttons along the front edge, the Pi's USB/Ethernet
over the top (back) edge. Channel R is a rigid copy of channel L, 42 mm
lower: the same circuit gets the same copper.

## How it was placed and routed

Not by hand coordinates and not by a wire-length auto-placer.
`tools/hat_place.py` takes anchors from `tools/rev_e_floor.py` (connectors,
the LED row, the Pi socket, starting points for the ICs), puts every other
part where its nets want it, and anneals: weighted wire length, plus a
strong pull of every decoupling cap to the supply pin it serves, plus a
prohibitive cost on any +5V/+5VA pad landing in the other In2 plane. No
courtyards may overlap. `tools/hat_board.py` builds the board around it
(outline, holes, Pi socket, planes, netclasses, references, legends).

`tools/hat_route.py rev_e` then routes with FreeRouting on F.Cu/B.Cu,
gives every SMD plane pad its own stub and via where the routed copper
leaves room (`tools/fanout.py`, outward from the part), and drops a via
onto any plane "island" DRC still reports — pads FreeRouting joined with
a track but never took to the plane (`tools/fanout.py --islands`). It
retries FreeRouting costs until DRC is clean. The order matters:
FreeRouting 2.4.1 connects most SMD plane pads itself, but on a board that
already carries any copper it throws a NullPointerException in its router
and never returns, so the fan-out cannot go in first.

## Stackup and rules

`F.Cu` signals, `In1.Cu` solid GND, `In2.Cu` split (+5V under the digital
and pump blocks, x ≥ 62 and y < 60; +5VA everywhere else), `B.Cu` signals.
L2 stands across the split with a pad in each plane. Tracks 0.25 mm,
supplies 0.4 mm, clocks 0.3 mm, clearance 0.2 mm, vias 0.6/0.3 mm, all
comfortably inside PCBWay's standard 4-layer process.

## Regenerating it

```bash
cd hardware/kicad
tools/hat_pipeline.sh rev_e
```

## Where it stands (25 September 2026)

| | |
|---|---|
| parts | 177 + 7 mounting holes; all SMD on the top side except the connectors, C20/C60 and the Pi socket (copper side) |
| gates | ERC clean; `check_rev_d.py vinyl_adc_rev_e` OK; placement with no courtyard overlaps and every +5V/+5VA pad in its own plane; DRC schematic parity: the same 234 cosmetic items as rev D |
| copper | 1726 segments, 4.3 m of track (2.9 m top, 1.5 m bottom), 277 vias (about 100 FreeRouting's, the rest the plane fan-out); DRC: 0 violations, 0 unconnected, 0 warnings |
| production | `production/vinyl_adc_rev_e/`: Gerbers, drills, IPC-D-356, layer and schematic PDFs, renders, STEP and `vinyl_adc_rev_e-pos.csv` (pick-and-place, top side) |

Not built. Everything rev D's README lists as not done applies here too.

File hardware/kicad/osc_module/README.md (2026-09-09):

# 6.144 MHz oscillator module

A coaster-sized single-sided board that **fills the X1 DIP-8 socket** on the
already-built digital board, standing in for the unobtainable oscillator can.
Electrically it *is* the can: a Pierce oscillator (74HCU04 + the found 2-pin
6.144 MHz crystal) whose buffered output leaves on the socket's OUT pin.
The same `blk_pierce` block draws this module, the rev B digital board and
the `sim_i_pierce` testbench, so the three cannot drift apart.
Design rationale, and the two values that are load-bearing (R_s = 2k2, and
*unbuffered* 74HCU04): `docs/design-notes.md` §5.

## Parts

| Ref | Value | Package | Shop? |
|---|---|---|---|
| U9 | **74HCU04** (unbuffered!) | DIP-14 + socket | order (pin-identical to 74HC04) |
| Y1 | 6.144 MHz crystal | HC-49 | in hand |
| R10 | 1M | axial | shop |
| R11 | 2k2 | axial | shop (2k21 E96 fine) |
| C16, C17 | 27p | ceramic disc | shop (22p/33p also fine) |
| C9 | 100n | ceramic disc | shop |
| J1 | 4 machined pins | at DIP-8 positions 1/4/5/8 | shop pin strip |

A buffered 74HC04 in U9's socket is an emergency substitute only — verify
with a scope that the output is 6.144 MHz and not ~30 MHz before trusting it
(the buffered gate can oscillate through the crystal's holder capacitance).

## Build order

1. Solder the four **J1 pins first**, from the component side, pointing
   **down**: machined round pins (cut from a strip) at pad positions
   1, 4, 5 and 8 — the corners of the pad field. Pads 2/3/6/7 stay empty.
   Seat them in a spare DIP-8 socket while soldering so they cure straight.
2. Low parts next (R10, R11, C16, C17, C9), then the DIP-14 socket, then Y1.
3. Plug in the 74HCU04 last.

## Fitting it to the digital board

- **Pad 1 of the module goes over pin 1 of the X1 socket** (the socket's
  notch end). Both are marked; a 180° misfit puts +5 V on the clock output.
- The module body extends **east and south** from the socket, over the
  board's emptiest quarter. Its north edge sits just clear of the CLK-SEL
  jumper — J1 on the digital board must be jumpered **1-2** (crystal) with
  the module in place, so fit that jumper first.
- Height: the module rides ~8 mm above the digital board on the socket +
  pin stack. Its far east edge passes close over U3's socket; if it touches,
  stack a second machined-pin socket under the module as a spacer.
- The enclosure lid was drawn for a bare digital board — check the module
  clears the acrylic before closing it, and bench-test with the lid off
  until then.

## Bench check

Power the digital board, jumper J1 1-2, and scope the socket's pin 5 (or
U3 pin 1): a 5 V square wave at **6.144 MHz ±0.01 %**. The 74HC4040 then
gives BCLK 3.072 MHz on Q0 and LRCLK 48 kHz on Q6 as in the testing guide.

## Files

- `vinyl_adc_osc.kicad_sch` — drawn by `hardware/kicad/tools/osc_module_layout.py`
- `vinyl_adc_osc.kicad_pcb` — placed by `vinyl_adc_osc.place.py`, routed
  single-sided: 19/19 connections, zero wire bridges, zero vias, DRC clean
- `production/vinyl_adc_osc/` — mill Gerbers + Excellon drill, laser silk DXF

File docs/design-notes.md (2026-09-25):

# Discrete delta-sigma vinyl ADC — design record

Session of 2026-08-22. Supersedes the architecture sketch in `HANDOFF.md` where
the two disagree; every change is justified below with the number that forced it.

Everything here is reproducible: `sim/` contains the simulator and the scripts
that produced each result, and every quoted figure is the output of one of them.

---

## 1. What the DTU shop actually stocks — and what it costs us

Checked against `C:\Users\Mads2\KiCad\DTU-EKB-components\Components\parts\dtu_component_shop.csv`
(1464 lines, the same list the KiCad symbol/footprint libraries are built from).

**The handoff's candidate parts are mostly not there.** No NE5532. No OPA2134.
No crystal oscillators of any kind. No ICL7660/MAX1044 charge pump. No TL431 or
any precision voltage reference.

The complete set of op-amps in the shop, by gain-bandwidth:

| Part | GBW | Note |
|---|---|---|
| LF356 | 5 MHz | the fastest thing on the shelf |
| TL071/072/074, TL081/082/084 | 3 MHz | JFET input |
| LM301 | 1 MHz | externally compensated |
| MCP6002 | 1 MHz | rail-to-rail |
| LM358/324, LM741, OP07, LH0042 | ≤1 MHz | |

Comparators: **LM311** (200 ns) and LM339 (300 ns). Nothing faster.

That single table is what reshaped the design. **6.144 MHz as the modulator
clock is not reachable** — it would need ~25 MHz op-amps and a ~50 ns
comparator.

**Must be ordered** (flagged per the handoff's instruction):

- ~~6.144 MHz oscillator can~~ — proved genuinely unobtainable; replaced by a
  Pierce oscillator around a found 2-pin 6.144 MHz crystal plus one 74HCU04
  (order that instead — §5).
- RCA phono sockets — the shop has screw terminals and Molex only.

---

## 2. Clock rate and modulator order

`sim/design_search.py`, `sim/clock_choice.py`.

With a 5 MHz op-amp and a 200 ns comparator the clock lands at **1.536 MHz**,
so **OSR = 32** for 48 kHz output. At that OSR:

| | peak SNR at −6 dBFS |
|---|---|
| 2nd order | 53 dB |
| **3rd order** | **70 dB** |

A 2nd-order loop misses the 65–75 dB target by a wide margin at OSR 32, so the
handoff's second-order plan does not survive the parts list. **Third order it
is.** The third integrator is the price of the shop's op-amp selection.

### What actually limits the clock

Not gain-bandwidth, as expected — **excess loop delay**:

| op-amp GBW | SNR | | loop delay | SNR | overload |
|---|---|---|---|---|---|
| ideal | 69.7 dB | | 0 ns | 69.3 dB | −3 dBFS |
| 10 MHz | 69.3 dB | | 65 ns | 69.7 dB | −3 dBFS |
| LF356 5 MHz | 70.0 dB | | 130 ns | 65.4 dB | −3 dBFS |
| **TL07x 3 MHz** | **70.6 dB** | | **202 ns** | **61.9 dB** | **−4.4 dBFS** |
| 1 MHz | 70.7 dB | | 326 ns | unstable | −12 dBFS |

GBW is a non-issue down to 1 MHz. The LM311's 200 ns costs 7 dB and most of the
overload margin — **and it is why the clock cannot go faster**: at 3.072 MHz
that same 200 ns is 61% of a clock period, which is unconditionally unstable.

**Consequence: the integrators are TL074, not LF356.** The fastest part in the
shop buys nothing, and the TL074's fourth section is needed anyway (§3).

### Excess-loop-delay compensation — one resistor, 8 dB

Adding a direct path from the DAC to the comparator input (weight `k0`)
recovers almost all of it:

| k0 | SNR at −6 dBFS | stable to |
|---|---|---|
| 0 (none) | 61.9 dB | 0.50 FS |
| −0.10 | 68.2 dB | 0.70 FS |
| **−0.225** | **69.8 dB** | **0.70 FS** |
| −0.50 | 65.7 dB | 0.50 FS |
| +0.20 | unstable | — |

---

## 3. Final loop

Third-order CIFB, continuous-time, 1-bit, with a resonator and ELD compensation:

```
a = [0.250, 0.320, 0.610]     integrator gains, normalised to fs
g = 0.0300                    resonator: int3 -> int2, spreads the NTF zeros
k0 = -0.225                   DAC -> comparator, ELD compensation
||NTF||inf = 1.48             Lee's rule for a 1-bit quantiser
```

**The resonator is worth 6.9 dB** (70.0 vs 63.1 dB re-optimised without it), so
it pays for the op-amp section it needs — and a TL074 quad supplies that section
free once the three integrators are in the same package.

Performance with real parts (TL074, 200 ns delay, E96 values — `sim/components.py`):

| input level | input volts | SNR | integrator swings |
|---|---|---|---|
| −14 dBFS | 0.49 Vrms | 61.3 dB | 1.05 / 1.11 / 1.22 V |
| −10.5 dBFS | 0.74 Vrms | 65.3 dB | 1.24 / 1.37 / 1.40 V |
| **−8 dBFS** | **0.98 Vrms** | **68.0 dB** | 1.43 / 1.47 / 1.45 V |
| −6 dBFS | 1.24 Vrms | 69.8 dB | 1.61 / 1.70 / 1.66 V |
| −4.4 dBFS | 1.48 Vrms | 71.6 dB | 1.94 / 1.92 / 1.86 V |
| −3.1 dBFS | 1.73 Vrms | **overload** | — |

Target was 65–75 dB. **Sits at 68–70 dB across the normal operating range.**

Input volts assume the level trimmer at maximum, where full scale is 3.49 Vpk
(2.47 Vrms) — set by `Rin = 20k5` against `Rd1 = 14k7`, since full scale is
just `2.5 V × Rin/Rd1`. The trimmer only ever attenuates, so **the fixed
resistor sets the most sensitive setting the board can reach**. That is chosen
for a phono stage delivering roughly 1 Vrms peaks; a hotter 2 Vrms source is
handled by turning the trimmer down, and a much quieter one wants a smaller
`Rin`. `Rin` is not in the feedback path, so changing it moves full scale
without touching the loop at all.

---

## 4. Two findings that change the circuit

### 4a. Without clamping, one vinyl click kills the recording

`sim/verify.py`. A 40 µs transient at 3× full scale, then back to a normal
signal:

| | after the click |
|---|---|
| ideal op-amps, no clamp | **LATCHED** — output stuck at one rail, permanently |
| clamped at 1.4× Vref | recovered, 68.4 dB (unchanged) |

A 1-bit third-order loop that overloads does not come back on its own. On a
vinyl source that is not a corner case — it is Tuesday.

**The fix is free**: the integrator state scales (S1..S3 in `sim/components.py`)
are chosen so the op-amps' own output saturation is the clamp. Normal peaks are
1.4–1.9 V; the TL074 on the ±5 V rails saturates around ±2.7 V, which is
1.3–1.8× Vref — exactly the range simulated as recovering. **No extra parts, but
the rail voltages and the scaling are now load-bearing, not arbitrary.** Do not
"tidy up" the resistor values without re-running `verify.py`.

### 4b. The handoff's Pi interface cannot work as described

The plan was: divide the 6.144 MHz bit clock by 128 for a 48 kHz LRCLK, and let
the Pi capture "64-bit stereo frames". Two independent problems:

1. **One DIN cannot carry two full-rate PDM streams.** Two modulators at the bit
   clock need 2× the bit clock on the single data line. Stereo was never going
   to fit.
2. **The BCM2835 PCM block caps a channel at 32 bits.** A 128-bit-per-channel
   frame is not expressible — most of each frame would simply not be captured.

**The fix — and it comes out unreasonably clean:**

```
6.144 MHz can ──► 74HC4040 ──┬── Q0 (pin 9) = 3.072 MHz = BCLK
                             ├── Q1 (pin 7) = 1.536 MHz = modulator clock
                             │                            + interleave select
                             ├── Q4 (pin 3) = 192 kHz   = charge-pump drive
                             └── Q6 (pin 4) = 48 kHz    = LRCLK
```

(The 4040's outputs are numbered from Q0 = ÷2, so these are pins 9, 7, 3 and 4 —
worth stating in pin numbers because the ÷2 stage being called "Q0" rather than
"Q1" is an easy off-by-one when wiring it.)

- Both modulators run at 1.536 MHz; a 74HC157 interleaves them onto DIN at
  3.072 MHz, `R L R L …`
- BCLK 3.072 MHz, LRCLK 48 kHz, 64 bits/frame is **exactly standard 48 kHz
  32-bit stereo I2S** — the most boring, best-supported mode the Pi has.
- Each 64-bit frame carries **32 L bits + 32 R bits = precisely one OSR-32
  output sample per channel**. The decimator gets whole, frame-aligned words.
- Software treats the "32-bit stereo" capture as a raw 3.072 Mbps bit river and
  de-interleaves even/odd bits. The L/R phase is fixed by construction (one
  counter drives everything) and identified once at bring-up.

Timing: every 4040 output changes on a master-clock falling edge, so DIN changes
on BCLK falling and the Pi samples it on BCLK rising — **163 ns of setup
margin**, textbook I2S source behaviour, with no retiming flip-flop needed.

---

## 5. The clock source: a crystal Pierce, because the can never turned up

`sim/components.py` computes the NRZ-DAC jitter floor:

| clock source | jitter | jitter noise floor |
|---|---|---|
| crystal oscillator (can or Pierce) | ~20 ps | **~102 dB** |
| Pi GPCLK0 (fractional divider) | ~1 ns | **68 dB** |

GPCLK0 would become the dominant noise source and drag the total to ~65 dB —
it would eat the entire margin the third integrator was added to buy.

The design originally specified a 6.144 MHz oscillator **can** (X1, DIP-8),
which proved unobtainable; a bare 2-pin 6.144 MHz **crystal** did turn up, so
the clock is now a **Pierce oscillator built from it**: an unbuffered
**74HCU04** gate biased linear by R_f 1 MΩ, the crystal from gate input to
gate output through R_s 2k2, one 27 pF load cap per crystal leg, and a second
gate of the same package squaring the node up for the jumper.  Electrically
that is exactly what lives inside a can.  Two values are load-bearing, both
found by `sim/sim_i_pierce`:

- **R_s = 2k2, not the textbook 1/(2πfC) ≈ 1k.**  At 1k the loop oscillates
  at ~30 MHz *through the crystal's own 5 pF holder capacitance* instead of
  its motional branch; 2k2 kills that parasitic and still starts the crystal
  across the whole modelled gate envelope (gain 10–30, tpd 5–12 ns).
- **The gate must be the UNBUFFERED 74HCU04** (pin-identical to 74HC04): a
  buffered gate's three-stage gain (~×800) sustains the same Co parasitic at
  any R_s the crystal mode survives.  If a buffered 74HC04 is fitted in a
  pinch, verify the output is 6.144 MHz and not tens of MHz before trusting
  anything downstream.

The 27 pF loads assume the usual CL ≈ 18 pF crystal; the exact value only
pulls the frequency by tens of ppm (the bench measures +0.05 %), which is far
below audibility.  Two deliverables carry the circuit:

- **The digital board rev B** bakes it in where X1's socket used to be.
- **A plug-in module** (`hardware/kicad/osc_module/`) carries the identical
  circuit — the same `blk_pierce` function draws both, so they cannot drift —
  on a small single-sided board with four pins at the can's corner positions
  (1 = unused, 4 = GND, 5 = OUT, 8 = +5 V).  It fills the X1 socket of the
  **already-built** rev A digital board, and unplugs the day a real can turns
  up.  Fit the plug's pad 1 over the socket's pin 1; the module body extends
  east and south over the board's empty quarter.

A 3-pin header lets GPIO4 be strapped in as a bring-up fallback. The clock input
is buffered by a **74HCT** gate (VIH 2.0 V) so it accepts a 3.3 V oscillator or
the Pi's 3.3 V GPCLK0 without fuss.

---

## 6. Supply and reference

±5 V, Pi-powered, as agreed.

- **+5 V** from the Pi, LC filtered.
- **−5 V** by charge pump — no charge-pump IC in the shop, so it is built from a
  **74HC244 with all eight outputs paralleled** (~32 mA) plus 1N5817 Schottkys.

  That ~32 mA is the real constraint, and it is why **the LM311s run on a single
  +5 V/GND supply** rather than ±5 V: leaving them on the negative rail costs
  ~8 mA, which drops the pump output far enough that the TL074s no longer clear
  their 1.94 V peak swing. Running the comparator single-supply needs the
  quantiser summing node biased to +2.5 V, which is free: a resistor equal to
  `Rs` up to +5 V does it, and `VREF_P` is already exactly 5 V/2, so the
  threshold lands where it should with no extra reference.
  Driven from 4040 **Q4 = 192 kHz (pin 3)**, deliberately: 192 kHz is 4× the
  output rate, so any surviving ripple lands **exactly on a null of the CIC
  decimator**. (§4b and the schematic both have this right; an earlier draft
  of this paragraph said Q5, which is 96 kHz.)
  Post-filtered 4.7 Ω + 220 µF → **−3.87 V measured at 29.8 mA**, ripple
  0.24 µV. The −4.1 V estimated here is optimistic — see §10.
- **Reference.** The 1-bit DAC is a 74HC04 gate swinging 0/5 V into R_d, with an
  equal resistor to a −2.5 V reference recentring it: net feedback ±2.5 V.

  **The reference tracks the rail on purpose.** If ±2.5 V is derived by a plain
  divider from the same rail the gate runs on, rail noise becomes a common-mode
  *gain* modulation (−98 dB) instead of additive noise. Filtering the reference
  instead of tracking it would break that cancellation and inject the rail noise
  at full weight. The rail therefore needs **low impedance, not a series RC** —
  the DAC's average supply current is proportional to the signal, so a series
  resistor there would put a signal-dependent droop straight onto the reference.

Thermal noise is a non-issue: 12 µVrms input-referred, **104 dB** below 2 Vrms.
Quantisation noise dominates at ~70 dB, which is the intended design.

---

## 7. Tolerance

Monte Carlo, 120 builds, 1% resistors (`sim/verify.py`):

| caps | median | worst | 5th pct |
|---|---|---|---|
| 5% | 69.9 dB | 68.0 dB | 68.6 dB |
| 10% | 69.7 dB | 66.9 dB | 67.6 dB |

SNR is robust. **Overload margin is not** — about 30% of builds overload nearer
−6 dBFS than −3 dBFS. Hence the nominal operating point is set at **−8 dBFS
(2 Vrms)**, not −6, and there is a front-panel level trimmer. §4a's saturation
clamp is what makes the remaining risk survivable rather than fatal.

E96 snapping costs nothing: realised a = [0.2467, 0.3212, 0.6108] against a
target of [0.250, 0.320, 0.610].

---

## 8. The schematic, and how it was verified

`hardware/kicad/vinyl_adc.kicad_sch`, drawn by
`hardware/kicad/tools/vinyl_adc_layout.py` (A2, 121 parts, four bands: power,
clock/digital, channel L, channel R). Re-run the script to regenerate the sheet
and the `.kicad_pro` together.

Four gates, all passing:

| gate | result |
|---|---|
| `sch_score.py` | PASS, 13/13 — 79% of pins wired part-to-part, 15% stub+label |
| KiCad ERC `--severity-all` | 23 `lib_symbol_mismatch` only (benign cache drift) |
| `tools/check_intent.py` | PASS — drawn netlist matches the intended circuit |
| exported PDF | read, twice; band spacing set from measured extents |

**`check_intent.py` is the one that earned its keep.** The other three all passed
on a sheet that had `MCLK` shorted to ground and `+5V` shorted to `+3V3` — it
asserts the actual topology (each summing node's membership, DAC polarity per
integrator, that int3 reaches both the resonator and the quantiser, that the
rails are separate) and caught every one of them. Re-run it after any edit.

Three bugs it found, all the same shape and all worth knowing for the PCB phase:

- A **ground drop landing on a neighbouring pin's stub.** On a 2.54 mm pin
  pitch a 5.08 mm drop ends exactly one row down, KiCad puts a junction there,
  and two pins short. This shorted the whole 74HC157 and, through it, MCLK to
  ground. Unused inputs now go to one shared bus with a single ground symbol.
- A **vertical run down a header's pin column**, which shorted all three pins of
  the clock-select jumper — the exact trap the `kicad-schematic` skill warns
  about. Every header is now approached horizontally, one run per pin.
- **Two blocks whose decoupling columns landed on the same x**, tying a
  comparator output to a supply.

Also worth recording: **`schdraw.note()` writes a multi-line string into the
s-expression verbatim**, producing a raw newline inside a quoted token, and
KiCad 10 then refuses to load the file entirely — while `sch_score` and the
in-process checks all still pass. `vinyl_adc_layout.py` works around it with a
local `note_block()` that emits one note per line. Fixing `schdraw` to escape
newlines would be a one-line change and would stop this recurring.

## 9. Known limitations

- **DAC inter-symbol interference.** The "a 1-bit DAC cannot be non-linear"
  argument fails if the rise and fall edges are not symmetric, because then the
  charge delivered depends on the transition pattern. This is the classic
  limiter of continuous-time modulators and is not modelled here. Keep the DAC
  node lightly loaded and the two gate edges as symmetric as possible; expect it
  to be the reason the built board measures nearer 65 dB than 70.
- The finite-GBW model is a single lag per integrator. Real op-amps are worse
  near GBW — but since GBW proved irrelevant down to 1 MHz against a 3 MHz part,
  there is a lot of margin absorbing that error.
- 13 ICs plus ~60 resistors will not fit the 62768 process's 104×104 mm
  single-sided jig comfortably. Expect to split across two boards or negotiate a
  larger format. **A PCB-phase problem, flagged now because it may affect the
  connector and block placement chosen during layout.**

---

## 10. What SPICE found

`hardware/kicad/sim/` — eight KiCad testbenches, one per block plus the whole
loop, generated by `sim/tools/sim_layout.py`, which imports this board's own
layout script and calls the same block functions, so every bench is the same
drawing as the board. `sim/tools/run_sims.py` exports each sheet through
`kicad-cli` and asserts the numbers in this document: **51 checks, all
passing**. `sim/tools/test_models.py` checks the behavioural models against
their datasheets separately: 34 more.

SPICE was not asked for the SNR figure. Reaching 68 dB over a 20 kHz band at
OSR 32 needs about a second of transient at nanosecond steps; `sim/verify.py`
computes it properly in minutes. SPICE was asked about the analog reality
that model idealises, and it found five things.

### 10a. The charge pump was drawn backwards

**Both Schottkys had their anodes and cathodes swapped**, which makes the
circuit a voltage doubler rather than an inverter. The net called `-5V`
simulated at **+3.4 V** — which would have arrived on the V− pin of every
op-amp on the board.

Nothing else caught it. `sch_score` passed, ERC passed, the exported netlist
read back correctly and `check_intent.py` passed, because a diode wired the
wrong way round is still a connected diode and every one of those checks is
about connectivity. The cause was a comment asserting that
`Device:D_Schottky` numbers its pins anode-first; **it numbers them
cathode-first**, and at `rot=90` pin 1 lands at the bottom.

Fixed in `charge_pump()`, and `sim_a_pump` now asserts the pump node's
polarity explicitly, which is a check that could only ever have come from a
simulation.

### 10b. The pump is weaker than §6 assumed, and that costs input headroom

| | §6 estimate | measured |
|---|---|---|
| rail | −4.1 V | **−3.87 V** |
| current | 32 mA | 29.8 mA |
| ripple | < 1 µV | **0.24 µV** ✓ |
| time to come up | — | **~40 ms** |

The pump's output resistance is about 16 Ω and it is set by the **74HC244's
own on-resistance**, not by 1/fC: 10 µF through 4 Ω is a 40 µs time constant
against a 2.6 µs half period, so the flying cap never finishes charging. A
bigger C4 or a faster PUMP will not change that; only more paralleled buffers
would, and there are none left.

**The consequence is the one thing on this list worth acting on.** The TL07x's
input common-mode range is specified as ±11 V minimum on ±15 V rails — V− + 4 V
guaranteed, V− + 3 V typical. On a −3.87 V rail the *guaranteed* floor is
**+0.13 V**, and every virtual earth on this board sits at 0 V. Simulation says
it works: the summing nodes never go below −0.27 V, comfortably inside the
typical −0.87 V floor. But the ~1 V of margin §6 implied by writing "±5 V" is
not there, and a part at its guaranteed limit would phase-invert. Anything
that lightens the negative rail — the LM311s are already on a single supply
for this reason — buys margin directly.

### 10b′. Bench, 16 September 2026: the reference inverter runs out of rail first

Measured on the built stack with the AD3 (power board alone → + left channel
→ + both channels): the pump rail went **−4.43 → −4.04 → −3.79 V**, and
VREF_N, which U2B (TL072) makes by inverting VREF_P, went **−2.49 → ? →
−1.77 V** while VREF_P stayed at +2.47 V. A TL07x output stops ~2 V above its
negative supply, so on −3.79 V it cannot reach −2.5 V. §10b priced the weak
pump against the integrators' common-mode range and missed this: the
reference is the first thing to fail, and it fails silently (the modulators
keep toggling at ~50 % with a skewed DAC).

Fix: **U2 → LM358**, same DIP-8 pinout, output sinks to within a few hundred
millivolts of V− at the ~1.3 mA both channels draw from VREF_N (14k7 ∥ 13k0
∥ 8k25 per channel into virtual earths). Of the shop's list it is the only
drop-in: the MCP6002 is rail-to-rail but limited to 6 V total supply, and
everything else swings no better than the TL072. Its noise is irrelevant on a
DC reference behind the board decoupling. Left/right screening results:
`assembly/sessions/2026-09-16/README.md`.

### 10c. The loop survives the click, and the clamp is not knife-edge

40 µs at three times full scale at t = 1.5 ms. By 2.2 ms all three
integrators are back to their normal swing and the output is still toggling
at 50 % density. This is what §4a promised and it is the single most valuable
thing SPICE could say about this design.

The saturation doing the rescuing is **asymmetric**, because the rails are:

| | positive | negative |
|---|---|---|
| integrator 1 | +3.19 V | −2.35 V |
| integrator 2 | +3.43 V | −2.33 V |
| integrator 3 | +3.35 V | −2.32 V |

§4a assumed a symmetric ±2.7 V. It recovers anyway — and sweeping the clamp
level in the Python model shows recovery is insensitive over at least
2.0–4.5 V, so the "1.3–1.8 × Vref window" in §4a reads far more precarious
than it is. What matters is that the states are bounded at all: unclamped,
they run away by six orders of magnitude.

Integrator swings at −8 dBFS measure **1.42 / 1.46 / 1.31 V** against the
1.43 / 1.47 / 1.45 V predicted in §3.

### 10d. Every coefficient is 3.5 % low, and it is the TL074's 3 MHz

The settled integrator ramp is **96 %** of 2.5 V / (Rd × C). An ideal
amplifier gives 100.0 % and a 30 MHz one 99.7 %, so this is the part and not
the measurement. `a1` reads 0.236 against the design's 0.247.

It is a systematic 3.5 % on every `ai`, well inside the ±10 % Monte Carlo of
§7, and §2's GBW sweep already shows the loop does not care — the Python
model carries the same lag. Worth knowing only so nobody chases it: the
triangle's peak-to-peak reads 6 % low for the same reason, the corners being
rounded, and no charge is lost.

Two more numbers confirmed rather than corrected: **|k0| = 0.228** read
straight off the comparator's threshold shift (design −0.225, E96 −0.2278),
and the LM311's propagation delay at **195 ns** against the 200 ns budgeted.

### 10e. The I2S setup margin is 145 ns, not 163

§4b's 163 ns is half a BCLK period, which assumes DIN and BCLK arrive
together. They do not: the ripple counter puts **31 ns** between Q0 and Q6,
and the mux and the two 74HC4049 stages take their share. What survives is
**145 ns**, still more than four times what the Pi needs, and 64 BCLK per
LRCLK frame with a clean 1.536 MHz DIN confirms the two channels land in
alternate bit slots.

The DAC's two levels come out **0.09 %** apart at integrator 1 and **1.3 %**
at integrator 2, from the 74HC04's 50 Ω against 14k7 and 13k0. That is a gain
error and a DC offset in the feedback, never distortion.

### 10f. A toolchain trap that would have wasted a day

**ngspice cannot read this board's component values.** They are written the
IEC 60062 way, which is correct for a BOM and unreadable to SPICE: it takes
the leading number, looks for a scale suffix and discards the rest.

| on the sheet | ngspice reads | intended |
|---|---|---|
| `14k7` | 14 kΩ | 14.7 kΩ |
| `5k90` | 5 kΩ | 5.9 kΩ |
| `4R75` | 4 Ω | 4.75 Ω |
| `1M0` | **1 mΩ** | 1 MΩ |

Nothing warns; the deck exports and the simulation runs a different circuit.
`sim_layout.py` gives every passive a `Sim.Params` override carrying the same
value spelled the way ngspice reads it, while the Value field keeps the
notation the board and the BOM use. `hardware/kicad/sim/README.md` records
the other traps — multi-unit symbols not exporting at all, power symbols
landing on each other, and three ways a behavioural logic model can look
like it works while producing noise.

---

## 11. Four boards, and why

The board was drawn as one, and that is still the sheet to read:
`hardware/kicad/vinyl_adc.kicad_sch`, the whole converter on one A2 page. It
is what the testbenches link back to and what `check_intent.py` asserts
against. **It is not what gets milled.**

### What the one-board version measured

Placed by hand, poured, and routed single-sided on the DTU 62768 process
(0.8 mm end mill, 1.0 mm tracks, 0.85 mm clearance), 203 × 152 mm — the
machine's whole envelope:

| | |
|---|---|
| B.Cu | 483 segments, 3392 mm |
| **F.Cu** | **289 segments = 45 separate wire runs** |
| vias | 17 |
| ground pads the pour could not reach | 25 |

Every F.Cu run on a single-sided board is a wire you solder by hand across the
component side. Forty-five of them is not a board, it is a kit — and the 25
stranded ground pads are worse, because they look connected in the drawing.

### The reason, in one number

**0.84 mm.** That is what a 2.54 mm DIP pitch leaves between two 1.7 mm pads,
and a 1.0 mm track with 0.85 mm clearance either side needs 2.7 mm. Nothing
passes between adjacent DIP pins on this process — not a thinner track either,
since even a zero-width one would need 1.7 mm. Every connection has to go
round the outside of its package, and so does the copper pour.

That makes routability a function of **space per part**, not of cleverness. The
measured line on these boards is around **0.1 parts/cm²**; the one-board
version was 0.37.

### The cut

Split at the two places the circuit is genuinely narrow — and the cuts are
different in kind:

- **Digital off first.** The clock generator, interleave mux, level shift and
  Pi header have no analog constraint at all. Six nets cross: MCLK, QL, QR,
  PUMP, +5V, GND. That half routed at **6 wire bridges** and every pad
  connected. The analog half stayed at 39–43 no matter how it was arranged.
- **Then the two channels.** They are identical, so this is one more *design*,
  not two: `vinyl_adc_channel_l` is milled twice and `vinyl_adc_channel_r` is
  the same drawing with every refdes forty higher, kept only so the split can
  be checked. What is left — power, the ±2.5 V reference, the quantiser and
  the 1-bit DAC — becomes the common board.

### The loop does now cross a ribbon

This is the one thing worth arguing about, and it goes the other way from what
the earlier revision of these notes claimed. The modulator's feedback path is
comparator → flip-flop → DAC gates → summing junction, and its delay is
compensated by the coefficient `k0`. With the channels on their own boards,
the comparator output leaves on a ribbon and the DAC drive comes back on one.

The delay `k0` compensates is the **LM311's 200 ns**. Ten centimetres of
ribbon adds about **0.5 ns** — a quarter of one percent of it, against a
coefficient measured at |k0| = 0.228 versus a design value of 0.225. It does
not matter.

What would have mattered stays put: the 74HC04's own supply *is* the DAC's
reference, so the gates keep their 100 n and the board's +5 V reservoir, and
the two DAC drives leave as a ground-flanked pair on adjacent ribbon
conductors. §9's DAC inter-symbol-interference limit is unchanged — it is set
by the gates' rise/fall asymmetry, which no cable touches.

### The gate

`tools/check_split.py`. It welds each ribbon's pin *n* to its partner's pin
*n*, drops the five connectors, and requires the resulting partition of every
(ref, pin) node to be **identical** to the reference sheet's. It also proves
channel R is channel L with the refdes bumped, which is what makes "one artwork
built twice" a checked claim rather than an intention.

This matters because the failure mode is invisible everywhere else: a block
called from the wrong composer, or a label misspelt at one end of a cable,
leaves score, ERC, geometry and footprint checks green on all five files. Each
file is individually consistent. The fault only exists in the relationship
between them. Sabotage-tested by moving the DAC gates to the digital board: it
reported the four severed nets and the resistor pairs left dangling.

### What it came out at, and what the split actually bought

| Design | wire bridges | vias | pads off the pour |
|---|---:|---:|---:|
| common | 16 | 11 | 0 |
| channel (each of two) | 10 | 4 | 3 |
| digital | 6 | 1 | 0 |
| **a stereo ADC** | **42** | **20** | **6** |

Against 45 bridges, 17 vias and 25 stranded ground pads for the one-board
version. **The split did not halve the wire count.** What it bought is that
every ground pad now reaches its plane, that the boards are small enough to
build and debug one at a time, and that two of the four are the same board.
Being straight about that matters more than the story reading well: the
digital board *did* fall out at six links, and the expectation that the
channels would do the same was wrong.

They did not because of the TL074. All four integrator sections live in one
19 mm package, so seventeen resistors have to cluster round it and compete for
the same few approaches — and on this process nothing gets between DIP pins.
Two levers are left, both untried and both cheap:

- **0.6 mm tracks instead of 1.0 mm.** The mill dictates the 0.8 mm *gap*, not
  the track; 1.0 mm was a robustness choice. At 0.6 the corridor a track needs
  between two obstacles falls from 2.7 mm to 2.3 — 15 % more usable width
  everywhere, applied to exactly the quantity that is short. 0.6 mm of 35 µm
  copper carries about 1.8 A against a 32 mA worst case here.
- **Two TL072s per channel instead of one TL074.** It lets the integrator
  pairs sit 40 mm apart, each with its own resistor cluster and summing node.
  One more socket and one more 100 n per channel, both stocked.

### What the PCB phase taught

Four things that are not in any datasheet and cost a day between them:

- **A net that crosses a supply spine severs it**, and a severed spine needs
  more hand-soldered links than it saved. The floorplans are arranged so that
  almost nothing crosses one — on the common board, only PUMP and −5 V's own
  feed cross the corridor the two spines run in.
- **Spines must stop short of the board edge.** Carried out to it, the only
  ground joining the two halves is the sliver between the bar's end and the
  outline, and one track crossing that sliver strands every ground pad beyond
  it.
- **Thermal reliefs do not work on this process.** They need the pour to
  surround a pad, and the pour cannot enter between DIP pins. Solid pad
  connections: four starved pads and eight unconnected became zero and zero.
  The build cost is a hotter iron on every ground joint.
- **More space is not monotonically better.** On the digital board, going from
  2.0 mm to 3.5 mm between parts took the router from six wire bridges and
  every net finished, to none and seven nets abandoned — the extra air pushed
  the decoupling caps into the channels it wanted.

The full account, with the regeneration commands, is in
`hardware/kicad/PCB-NOTES.md`.

---

## 12. Rev D: the converter as a Raspberry Pi HAT (22 September 2026)

Rev C put the whole converter on one fabricated 4-layer board and stopped
there. Rev D is the same circuit designed *for* that board, with a fab
sponsor (PCBWay) and the bench results of §10b′ and the bring-up log to act
on. It is drawn by `hardware/kicad/tools/rev_d_layout.py` from the same
block functions as the reference sheet, and `tools/check_rev_d.py` proves
the netlist is the reference partition plus exactly the additions below —
nothing inside the modulator loop changed. The board is
`hardware/kicad/rev_d/`, 140 × 136 mm (§12f: the first layout was
176 × 146 and was redone), `tools/hat_place.py` places it from
`tools/rev_d_floor.py` and `tools/route_4layer.py` routes it. Rev E (§13)
is the same circuit in SMD parts.

### 12a. Two supply changes, both from measured numbers

**A second 74HC244 in the charge pump (U10).** §10b measured the pump's
16 Ω output resistance as the drivers' own on-resistance, and said the
only thing that would move it was more paralleled buffers. Sixteen buffers
halve it: at the stack's 30 mA that is about 0.5 V more negative rail,
−3.8 → roughly −4.3 V under both channels. §10b′ showed the reference
inverter is the first casualty of a weak rail; the LM358 fixed that, and
this buys back the TL072 input common-mode margin §10b called the one
thing worth acting on.

**An analog supply island, +5VA (L2, C18, C19).** The 1-bit DAC's gate
supply *is* the reference, so §6 wants that rail low-impedance and
ratiometric, not filtered by a series resistor. The bring-up log (§8.5)
then measured the Pi's 5 V costing 6–11 dB of idle noise against a bench
supply, with the pump's 30 mA at 192 kHz on the same rail. A 10 µH choke
(the shop's 3 A part, DCR tens of milliohms) into 470 µF is a 2.3 kHz
corner: the pump's 192 kHz and the Pi's converter hash arrive ~35 dB down,
while the DAC's signal-dependent mean current — 0.17 mA per gate — drops
microvolts across the DCR, three orders below the cancellation it
protects. Everything in the loop lives on the island: the four TL072s, the
LM311s' bias and pull-up, the retiming flip-flops, the DAC gates and the
LM358 reference. The clock tree, the pump, the level shifter and the Pi
inlet stay on +5V. The board's inlet choke L1 is the same part, replacing
rev C's ordered ferrite bead with a stocked one. On the PCB the split is a
line on the +5V inner plane; the ground plane under it is unbroken, so no
signal's return path crosses the split.

### 12b. Front panel: what the LEDs measure

| LED | Driven by | What it says |
|---|---|---|
| +5VA | R40 from the island | the analog rail is up, behind both chokes |
| −5V | R41 from ground into the pump rail | the charge pump is pumping — a bring-up fault that happened |
| CLK | U3B (spare 74HCT132) → 1n5 → 1N4148 pump → 10 µF → BC547 | LRCLK is *toggling*: 0.36 mA of pump current holds Q1 on; a stuck line drains the cap in ~100 ms and the LED goes out. A plain LED on the clock would glow half-bright forever |
| CLIP L / R | U12 LM339 window on INT1 against ±2.0 V (22k1/100k off VREF_P/VREF_N), wired-OR, 1N4148 + 10 µF + 100 k stretch, BC557 | the first integrator is past the −4.4 dBFS peaks and inside its +3.2/−2.35 V saturation (§10c): "back the trim off" before the loop latches (§4a) |
| REC / BUSY / READY | GPIO17 / 27 / 22 through 330 R | the ripper's state — the Pi's own LEDs are under the board |

The clip threshold tracks the references, so it moves with full scale
exactly as the trimmer setting does; the LM339 runs +5VA/−5V so a −2 V
input is inside its common-mode range.

### 12c. The HAT

Pi 4 under the right-hand 56 mm on a 2×20 socket on the copper side, its
USB/Ethernet stack over the top edge (rev C's arrangement, verified
against KiCad's HAT template). New on the header: GPIO3 (pin 5) and
GPIO23 (pin 16) as buttons — GPIO3 wakes a halted Pi, so SW1 is the power
button with `dtoverlay=gpio-shutdown` — and ID_SD/ID_SC (pins 27/28) to a
socketed 24LC32 with a write-protect jumper, the one part the shop cannot
supply and the one the board works without. The Pi side of the inlet is
named PI_5V so the 100 mA track gets the supply width.

### 12d. Bench and hum

Three 2×5 headers with a ground column (J22, J62 per channel: INT1, INT2,
INT3, CMP, DACP; J5: MCLK, LRCLK, DIN, VREF_P, VREF_N) — two probes on
header pins, never DIP legs. A tonearm/chassis terminal J3 beside the line
inputs with a lift network (10 R ‖ 100 n ‖ antiparallel 1N4003) and J4 to
bond it hard, for the −39 dBFS of 50 Hz in the bring-up log's open item
3. And 33R2 (R14) in series with MCLK at its source: one driver, three
loads along 100 mm of track, and that edge is the one whose jitter sets
the noise floor (§5).

### 12e. What was not done

No SPICE bench for the clock-alive pump or the clip stretcher; both are
diode-RC circuits whose numbers are in the block docstrings and cheap to
check on the bench with the TP headers. The enclosure is not redrawn for
the HAT boards with the Pi's ports on two edges. And the board is not built:
the milled stack's 67.9 dB dynamic range (§13a of the bring-up log) is the
number rev D has to beat, and whether the island and the stiffer pump move
it is the experiment.

### 12f. The layout, redone (24 September 2026)

The first rev D layout packed every passive into a row of its own kind,
first-fit, inside a band per block. From across the room it looked tidy;
up close it was wrong in the way that matters on a board: a resistor sat
wherever its row had space, not next to the pin it serves, so most traces
ran diagonally across the board, and 176 × 146 mm was mostly empty. It was
discarded.

The second layout keeps the geography (inputs on the left edge, each
channel reading left to right as its schematic band does, the digital
column over the Pi's header, power at the far end from the inputs, LEDs
and buttons on the front edge) and places everything else from the
netlist. `tools/hat_place.py` takes anchors from the floorplan file
(connectors, the front row, the Pi socket, starting points for the ICs),
drops every other part at the free spot nearest the pins it connects to,
then anneals: weighted half-perimeter wire length, plus 8 mm-equivalent
per mm of distance between each decoupling cap and the supply pin it
serves, plus a prohibitive cost for any +5V/+5VA pad landing in the other
half of the In2 split, with no courtyards allowed to overlap. Channel R is
a rigid copy of channel L (the same circuit on the same copper), and the
charge pump's AC loop — drivers, flying cap, rectifier, reservoir — is
weighted three times so it stays one tight group. Three things the
annealer taught:

* **Decoupling caps must go down straight after their ICs.** Placed in
  wire-length order they arrive last, find the spot by the supply pin
  taken by a resistor, and end up 20–70 mm away — and a hot anneal
  knocks them out even when the greedy pass got them right. The fix was
  both: place them first, and give the annealer a move that re-seeds a
  part next to its own pins.
* **Through-hole needs the room SMD does not.** The digital column over
  the Pi holds five DIP-14/16s; with J5 and the EEPROM in it as well it
  was 66 % full and the decaps spilled over the socket into channel L.
  J5 moved beside the socket between the two channel TP headers (all
  three probe headers now stand in one column), and the board is
  140 × 136 — 26 % less than the first layout.
* **FreeRouting 2.4.1 and SMD plane pads** — see §13.

### 12g. Rules the layout needed

KiCad wants two thermal spokes from every pad into a plane. A DIP's GND
pin between two neighbours can only grow one into the inner ground plane
(the other side is the neighbour's clearance), so `min_resolved_spokes`
is 1 in the project rules: one 0.5 mm spoke carries far more than a logic
ground pin needs, and a solid connection would sink a hand iron. KiCad 10
keeps this in the `.kicad_pro` design settings, not in a `.kicad_dru` rule
file — a custom rule there is silently ignored.

## 13. Rev E: the same circuit in SMD parts (24 September 2026)

With PCBWay making the board, nothing ties the circuit to the DTU shop's
through-hole drawers any more. Rev E is rev D's circuit in common
surface-mount parts: `hardware/kicad/tools/rev_e_layout.py` calls rev D's
block functions unchanged and only swaps footprints and four part
numbers, and `tools/check_rev_d.py vinyl_adc_rev_e` runs rev D's own gate
on it, so the netlist is provably the same. 118 × 88 mm, the same
geography as rev D at a quarter of the first layout's area.

What was chosen, and why (full list in `hardware/kicad/rev_e/README.md`,
BOM in `docs/bom-rev-e.md`):

* **C0G for every capacitor in the signal path.** The integrators' 220 p,
  the input filter's 1n5 and the crystal's 27 p are 0805 C0G; X7R changes
  value with the voltage across it, which in an integrator is distortion.
  X7R only for the 100 n decoupling.
* **The 2u2 input coupling caps stay through-hole film.** 2.2 µF does not
  exist in C0G, and those two capacitors sit in series with the audio.
* **The 10 µ electrolytics become 1206 X5R ceramics.** The pump's flying
  cap gains from the lower ESR; the clip and clock-alive stretch caps lose
  about 40 % to DC bias, so those LEDs hold ~0.6 s instead of ~1 s.
* **BC547/BC557 become BC847/BC857.** SOT-23 numbers its pins differently
  from TO-92, so the schematic symbol changes too; the blocks connect by
  pin name, so nothing else does.
* **Bourns SRR1260-100M** for both 10 µH chokes: shielded, 27 mΩ, so the
  island's 2.3 kHz corner and its microvolt drop (§12a) are unchanged.

**Routing.** FreeRouting counts a plane net as connected wherever a
through-hole pad meets the plane; a surface pad needs a via. FreeRouting
2.4.1 fans most SMD pins out itself and leaves the rest unconnected. The
obvious fix — fan every plane pad out first, as a hand layout would, and
route round the stubs — does not work: with any copper already on the
board, locked or not, its router throws a NullPointerException in
`SearchTreeObject.shapeLayer` and never returns (it sat for 25 minutes
twice before the log showed why). So rev E is routed first and fanned out
after: `tools/fanout.py` gives every SMD plane pad one stub and one via,
outward from its part, where the routed copper leaves room, and
`--islands` then drops a via straight onto a track of each plane island
DRC still reports (pads FreeRouting joined to each other but never to the
plane). Fanning out only the pads DRC lists is not enough — most islands
appear in its report as tracks, not pads; the route went from 69
unconnected to 6 with the all-pads pass and to 0 with the islands pass.
Result: 4.3 m of track, 277 vias, DRC clean.

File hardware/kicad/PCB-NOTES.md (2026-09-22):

# PCB — four CNC-milled, single-sided boards from three designs

> **Rev C (September 2026):** the same converter drawn as ONE fabricated
> 4-layer board with the Pi plugged into its underside, in `rev_c/` — see
> [`rev_c/README.md`](rev_c/README.md). Everything below describes the four
> milled boards that were built and measured; the split they describe exists
> only because of the mill, and rev C undoes it.

Copper is isolation-milled on **B.Cu** with an 0.8 mm flat end mill; the
silkscreen is laser-etched on top. Everything is through-hole and every IC is
socketed.

| Design | Outline | Parts | Built | What it holds |
|---|---|---:|---:|---|
| `vinyl_adc_common` | 160 × 120 mm | 24 | ×1 | power in, charge pump, ±2.5 V reference, the quantiser and 1-bit DAC |
| `vinyl_adc_channel_l` | 190 × 145 mm | 31 | **×2** | one modulator channel: line in, three integrators, resonator, comparator |
| `vinyl_adc_digital` | 140 × 100 mm | 13 | ×1 | 6.144 MHz clock, divider, interleave mux, level shift, Pi header |

`vinyl_adc.kicad_sch` is the whole converter on one page. **It has no board and
is not meant to have one** — it is the sheet the SPICE benches link back to and
the one `check_intent.py` reads. `vinyl_adc_channel_r.kicad_sch` has no board
either: it is the same drawing as channel L with every refdes forty higher, and
exists so the split can be checked. **One channel artwork is milled twice.**

## Why four boards

The one-board version was built and routed. Measured, single-sided: **45 wire
bridges**, 17 vias and 25 ground pads the pour could not reach. Splitting it in
two — analog and digital — fixed the digital half (6 bridges) and not the
analog one, which stayed at 39–43 however it was arranged. 82 parts on the
machine's largest blank is 0.37 parts/cm²; the digital half that routes well is
0.09.

So the two channels came off onto their own board. They are identical, so it is
one more *design*, not two, and the stereo pair is two copies of one artwork.

```
        common board                                  digital board
   +5V in <--------------------- J3 --- J4 ------------ from the Pi, 12-way
   charge pump -> -5V              MCLK ->
   reference   -> +/-2.5V          <- QL, QR
   U5 quantiser, U7 DAC gates      PUMP ->
        |          |
        J5         J6      14-way each
        |          |
   channel L    channel R      J7 on each: both supplies, both references,
   (one artwork, built twice)   CMP out, DACP and DACN back
```

**The modulator loop now crosses a ribbon** — comparator out on the channel
board, flip-flop and DAC gates on the common board, DAC drive back. That is
worth being explicit about, because an earlier revision of these notes argued
it must never happen. The delay the loop's `k0` coefficient compensates is the
LM311's **200 ns**; 10 cm of ribbon adds about **0.5 ns**, a quarter of one
percent of it. What does not cross is anything that would matter: the DAC's
own reference is the 74HC04's supply, and that supply and its reservoir sit
with the gates.

`tools/check_split.py` is the gate that keeps the split honest. It welds each
link's pin *n* to its partner's pin *n*, drops the connectors, and requires the
resulting partition of every (ref, pin) node to be **identical** to the
reference sheet's. It also proves the two channel boards are one artwork:
channel R's netlist must be channel L's with every refdes number raised by
forty. Move a block to the wrong board and every other check still passes;
this one does not.

## The links

Three ribbons, all shrouded IDC box headers on 2.54 mm pitch:

```
  J3 / J4  2x6, 12-way            J5 / J7 and J6 / J7  2x7, 14-way
   1 GND    2 +5V                  1 GND    2 +5V
   3 GND    4 MCLK                 3 GND    4 VREF_P
   5 GND    6 QL                   5 GND    6 VREF_N
   7 GND    8 QR                   7 GND    8 CMP_x
   9 GND   10 PUMP                 9 GND   10 DACP_x
  11 GND   12 +5V                 11 GND   12 DACN_x
                                  13 GND   14 -5V
```

On a 2×N Odd_Even symbol the odd pins are the left column, so putting every
ground on an odd pin gives a solid ground column down one side of the drawing —
and, because an IDC ribbon takes conductor *n* to pin *n*, a grounded conductor
either side of every signal in the cable. MCLK is why that matters: its jitter
is what sets this converter's noise floor, 20 ps buying a 102 dB floor where
1 ns leaves 68.

**Shrouded, not bare pin strips.** These rows carry supplies against grounds;
reversed, a bare strip puts +5 V straight across the ground column. The
shroud's key makes that impossible. The shop carries neither the headers nor
the sockets, so they go on the same order as the oscillator can — see
`docs/bom.md`.

## Regenerating a board from its schematic

```bash
cd "hardware/kicad"
B=vinyl_adc_common        # or vinyl_adc_channel_l, vinyl_adc_digital
"/c/Program Files/KiCad/10.0/bin/kicad-cli.exe" sch export netlist --format kicadsexpr -o $B.net $B.kicad_sch
py -3.13 "$SKILL/scripts/pcb_netlist_json.py" $B.net /tmp/$B.json
KICAD_PCB_SIZE_MM=160x120 KICAD_PCB_FAB=cnc KICAD_LASER_EXTRA_LIBS="$PWD/lib" \
  "/c/Program Files/KiCad/10.0/bin/python.exe" "$SKILL/scripts/pcb_build.py" /tmp/$B.json $B.kicad_pcb
"/c/Program Files/KiCad/10.0/bin/python.exe" tools/pcb_floorplan.py $B.kicad_pcb
"/c/Program Files/KiCad/10.0/bin/python.exe" tools/pcb_pours.py     $B.kicad_pcb
```

`$SKILL` is the `kicad-laser-pcb` skill directory. Sizes: `160x120` common,
`190x145` channel, `140x100` digital. `pcb_build.py` **ceils** the outline, so
a size must be asked for as whole millimetres or it comes out a millimetre
larger than requested.

Both scripts pick their plan from the file name, so there is one floorplan
script and one pour script, not six.

## The floorplans are hand-written, and that is the point

```
  COMMON, 160 x 120                   CHANNEL, 190 x 145 (built twice)
  y  38  C1  U1 charge pump           y  56  J20 -> RV20 -> U20 -> U21
  y  56  ------ +5V bar ------               with the passives packed
  y  66  ------ -5V bar ------               round them in one band
  y  90  J3 | U5 U7 U2 | J5 J6        y  92  +5V and -5V spines
                                      y 138                        J7
  DIGITAL, 140 x 100
  y  42  X1 J1 U3 U4        (the clock, made once)
  y  58  ------- +5V bar -------
  y  84  J4 U6 U8 J2
```

The auto-placer was tried first and is wrong for this design in two separate
ways.

**It interleaves the blocks.** Optimising half-perimeter wire length, it put
the two analog channels on top of each other (59 × 70 mm of overlap), the
6.144 MHz divider inside both, and the charge pump — 32 mA switching at
192 kHz — spread across the whole board among the integrators. For a converter
whose whole design target is a 68 dB noise floor, that is close to the worst
arrangement available. It also routed badly: **66 %** of nets on the first
single-sided pass.

**Locking the ICs fixes the ICs and not the passives.** A decoupling
capacitor's two nets are +5V and GND, and both of those span the entire board,
so wire length gives the placer no reason whatsoever to put the cap next to the
chip it decouples — and it did not. Decoupling caps are therefore pinned to
their host IC explicitly, at a distance derived from the two real outlines so
it is right for a DIP-8 and a DIP-20 alike.

Two things the hand floorplans do that are worth copying:

- **The common board's lower band is ordered by counting crossings.** Every
  net that has to get past a package costs a detour round it and often a wire
  bridge, so the order of the five things in that band is worth measuring
  rather than reasoning about. Three were built, everything else identical:

  | order | crossings | wire bridges |
  |---|---:|---:|
  | `J5/J6  U5 U7 U2  J3` | 14 | 15 |
  | `U2  J5/J6  U7 U5  J3` | ~10 | **25** |
  | `J3  U5 U7 U2  J5/J6` | 8 | 16 |

  The middle one is the arrangement that looks obviously right — the ribbons
  next to everything they talk to — and it is the worst of the three. The
  shipped order is the last: the digital ribbon beside the flip-flops it
  clocks and the charge pump above it, the channel ribbons beside the
  reference they carry. Counting crossings predicted the *direction* and not
  the size; only building all three told the truth.
- **The channel board keeps its whole lower half empty for the supply
  spines.** The modulator is one signal chain and reads best as one row; the
  spines then live below it, so the ground under the analog path is never cut
  and nothing has to cross a spine to get anywhere.

`tools/pcb_blocks.py` reports where each functional block landed and which
blocks overlap. On all three floorplans every block occupies its own rectangle.

## Nothing passes between two adjacent DIP pins

This is the single fact that shapes the layout. 2.54 mm pitch with 1.7 mm pads
leaves **0.84 mm** between neighbouring pads. A 1.0 mm track needs 0.85 mm of
clearance either side — 2.7 mm of corridor. It does not fit, and no narrower
track helps either: even a zero-width track would need 1.7 mm.

So **every track has to go round the outside of a package**, and so does the
copper pour. A board packed to look neat leaves the router nowhere to do that,
and it gives up on the last few nets rather than routing them the long way
round. The `GAP` between neighbouring parts is therefore a measured number per
board rather than a principle — and it is **not monotonic**. On the digital
half, same placement otherwise: at 2.0 mm the router finished every signal net
and left six wire bridges; at 3.5 it left none, and abandoned seven nets
instead, because the extra air had pushed the decoupling caps out into the
channels it wanted.

## Footprints

Assigned in `tools/vinyl_adc_layout.py`, not in the GUI — that script owns the
schematics, so anything set by hand would be wiped the next time it runs.

| Part | Footprint |
|---|---|
| resistors | `R_Axial_DIN0207_L6.3mm_D2.5mm_P7.62mm_Horizontal`, stood on end |
| ceramics (100n, 1n5, 220p) | `C_Disc_D5.0mm_W2.5mm_P5.00mm` |
| 2u2 film | `C_Rect_L11.0mm_W6.3mm_P10.00mm_MKT` — **measure the real part** |
| 10u, 220u | `CP_Radial_D8.0mm_P3.50mm` |
| 470u | `CP_Radial_D10.0mm_P5.00mm` |
| 1N5817 | `D_DO-41_SOD81_P10.16mm_Horizontal` |
| every IC | `Package_DIP:DIP-<n>_W7.62mm_LongPads` |
| X1 oscillator | DIP-8 **socket**, not `Oscillator_DIP-8`: the can is socketed like everything else, and a socket wants all eight pads |
| trimmers | `Potentiometer_Bourns_3296W_Vertical` — **measure the real part** |
| screw terminals | `TerminalBlock_bornier-2_P5.08mm`, vendored into `lib/` |
| J3, J4 | `Connector_IDC:IDC-Header_2x06_P2.54mm_Vertical` |
| J5, J6, J7 | `Connector_IDC:IDC-Header_2x07_P2.54mm_Vertical` |

Two of those are assumptions, flagged above: the 2u2 film cap's lead pitch and
the trimmer body. Both are cheap to fix before cutting and expensive after.

The bornier terminal blocks were **deleted from KiCad 10's stock library**.
They live in `lib/TerminalBlock.pretty` and are registered in the project's own
`fp-lib-table`, which KiCad reads at *project* load — so reopen the project,
not just the board, after touching it. One `fp-lib-table` in this directory
serves every project here.

## Pad gaps against the 0.8 mm end mill

The mill cannot enter a gap narrower than its own diameter, and a gap it cannot
enter ships as a short. Every footprint was measured:

| Part | Min pad gap | |
|---|---|---|
| axial passives | 3.4 mm and up | fine |
| radial electrolytics | 1.90 mm | fine |
| bornier terminals | 2.08 mm | fine |
| trimmer | 1.10 mm | fine |
| DIP-8/14/16/20 LongPads | 0.94 mm | fine |
| **2.54 mm headers (J1–J7)** | **0.84 mm** | needs a DRC exception |

Each board has a `.kicad_dru` relaxing the clearance to 0.8 mm *only* between
two pads of the same header footprint. The full 0.85 mm stays in force
everywhere else. That gap is set by the header's own pin pitch, not by anything
we cut, and it still clears the tool.

## Pours

`tools/pcb_pours.py`: a GND plane over the whole board, and supply spines in
the corridors between the functional bands.

These are a routing prerequisite, not decoration. FreeRouting only treats a net
as a plane if there is a filled pour on it. Measured both ways on the digital
board, same placement:

| | B.Cu | F.Cu (wire bridges) | vias |
|---|---:|---:|---:|
| GND as a **plane** | 98 segments | **0** | 0 |
| GND as an ordinary **net** | 193 segments | 60 segments = 14 bridges | 2 |

Four details in that script are load-bearing and none is obvious:

- **A net that crosses a spine severs it.** A track plus its 0.85 mm clearance
  either side is 2.7 mm of no-copper; run one across a 6 mm bar and the bar is
  in two pieces, which then need hand-soldered links of their own. So the
  spines go where almost nothing crosses them, and the floorplans are arranged
  to make that true rather than the other way round.
- **Every spine stops ~12 mm short of the board edge.** Carried out to the edge
  it cuts the ground plane in two outright: the only ground copper joining the
  halves is the sliver between the bar's end and the outline, and one signal
  track crossing that sliver strands every ground pad on the far side.
- **Pads connect to the pour solidly, not through thermal reliefs.** A relief
  needs the pour to surround the pad enough to grow spokes, and on this process
  the pour cannot enter between adjacent DIP pins at all — so it reaches most
  ground pins from one side only. Measured on the digital board: with reliefs,
  four pads starved and eight came out unconnected; solid, every ground pad
  connects and both counts go to zero. (KiCad's default 0.5 mm relief gap would
  have been unmillable anyway — narrower than the tool.) **The cost is real and
  belongs in the build notes: use a 40 W+ iron and give each ground joint a
  couple of extra seconds.**
- **Fill islands that reach no pad are dropped**, so there is no floating
  copper to mill round or to lift off the laminate later.

**Three planes is the limit.** With four -- the channel board briefly had
+5V, -5V, VREF_N and GND -- FreeRouting never got past reading the DSN:
twenty-four minutes, no progress, no error, no CPU pattern that looked like
work. Three is fine and routes in minutes. If a fourth net ever needs a spine,
give it one and route it as a separate pass rather than handing the router four
planes at once.

There is also a pcbnew trap in there worth knowing about anywhere else you
script zones: **`board.Remove()` on a ZONE leaves the SWIG runtime unable to
wrap anything the board hands back afterwards.** Every later call returns a
bare `SwigPyObject` and dies on its first attribute access, on a board that is
perfectly readable — "no destructor found" in the noise is the tell. It only
bites on the *second* run, when there are zones to remove, which is exactly
when you have stopped expecting it. `pcb_pours.py` drops the stale zones, saves,
and re-loads from the file.

## What it actually came out at

Measured with `tools/pcb_report.py` and KiCad's own DRC, after routing,
pouring and filling:

| Design | B.Cu | wire bridges | vias | pads off the pour |
|---|---|---:|---:|---:|
| common | 243 seg, 1327 mm | 16 | 11 | 0 |
| channel (each of two) | 151 seg, 1419 mm | 10 | 4 | 3 |
| digital | 101 seg, 841 mm | 6 | 1 | 0 |
| **a stereo ADC** | | **42** | **20** | **6** |

plus six places where a supply *track* comes out in two pieces (three on the
common board, three on the digital one) and wants a link across the gap. Call
it **fifty hand-soldered joints for the set**, against 45 wire bridges, 17 vias
and 25 stranded ground pads for the one-board version.

**Be clear about what the split did and did not buy.** It did not halve the
wire count. What it bought is that every ground pad now reaches the plane
(25 stranded became 6), the boards are small enough to build and debug one at
a time, and two of the four are the same board. The bridge count barely moved.

Two levers are left, both untried, and they are the ones worth pulling before
cutting copper:

- **Narrower tracks.** The `cnc` profile's 1.0 mm track is a robustness choice,
  not a constraint from the mill: what the mill dictates is the 0.8 mm *gap*.
  At 0.6 mm the corridor a track needs between two obstacles falls from 2.7 mm
  to 2.3 — about 15 % more usable width everywhere on the board, applied to the
  exact quantity that is short. 0.6 mm of 35 µm copper carries something like
  1.8 A; the largest current here is the charge pump's 32 mA.
- **Two TL072s per channel instead of one TL074.** Seventeen of the channel
  board's resistors have to cluster round a single 19 mm package, because all
  four integrator sections live inside it — and nothing passes between DIP
  pins, so they all compete for the same few approaches. Two duals let the
  integrator pairs sit 40 mm apart, each with its own resistor cluster and its
  own summing node. It costs one more socket and one more 100 n per channel,
  and both parts are stocked.

## Routing

Single-sided: all copper on B.Cu, components on top. Any F.Cu track is a wire
bridge to solder, so `tools/pcb_report.py` counts them and never rolls them
into a "routed %".

```bash
"$SKILL/scripts/route_board.ps1" -Pcb vinyl_adc_common.kicad_pcb -KeepPlacement
```

`-KeepPlacement` is required: the floorplan is deliberate and every part is
locked.

**The script sometimes stops after `lockdsn`,** on a `PCB_VIA::GetWidth called
without a layer argument` assertion, and never imports stage 2 — the board is
then left with stage 1 only, which looks like a beautifully bridge-free route
and is really a board with thirty unrouted nets. Check `pcb_report.py` against
DRC's unconnected count every time; if stage 2 is missing, import it by hand:

```bash
"/c/Program Files/KiCad/10.0/bin/python.exe" "$SKILL/scripts/pcb_route.py"     ses <board>.kicad_pcb "$TEMP/kicad-laser/<board>2.ses"
```

Then, either way:

```bash
"/c/Program Files/KiCad/10.0/bin/python.exe" tools/pcb_pours.py <board>.kicad_pcb
py -3.13 tools/pcb_report.py <board>.kicad_pcb
```

`tools/pcb_stitch.py` will reconnect pour islands the routing cuts off, by
maze-routing from each stranded pad back to the main body of the pour on a
0.25 mm grid. It is a maze router and not a stub search because a stub cannot
get round the end of a track, and that is exactly the move required. It reports
what it cannot solve rather than leaving it quiet — and on these boards it
usually has nothing to do, because the spine placement above stops the islands
forming in the first place.

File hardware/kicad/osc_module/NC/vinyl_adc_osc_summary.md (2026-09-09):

# vinyl_adc_osc - board summary

- Size: 41.9 x 44.0 mm
- Copper area: 1349.0 mm^2
- Holes: 34
  - 0.8 mm x 34

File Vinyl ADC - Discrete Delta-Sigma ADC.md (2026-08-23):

# Vinyl ADC

A stereo audio ADC built from jelly-bean parts with **no ADC chip anywhere in
it**, to digitise vinyl. It permanently replaces the borrowed Focusrite
Scarlett Solo in the record-ripping chain.

**Status:** 🟡 Schematic complete, and now simulated block by block —
next is the PCB, then the decimator on the Pi

```
Pro-Ject Debut Carbon --> Phono Box --> [THIS BOARD] --> Pi "mediaplayer" --> FLAC --> Jellyfin
                                         analog -> PDM      CIC + FIR in software
```

## How it works

Each channel is a **third-order continuous-time delta-sigma modulator**: three
op-amp integrators, a comparator, a flip-flop that retimes the decision, and a
1-bit DAC made of resistors feeding back into all three integrators. The output
is a 1-bit stream at 1.536 MHz. Nothing turns that stream into samples on the
board — the decimation is done in software on the Pi, deliberately, because
that half is the DSP coursework.

```
in --> [ INT1 ]-->[ INT2 ]-->[ INT3 ]--> comparator --> D-FF --> 1-bit out
          ^          ^  ^       ^                          |
          |          |  +-------+ resonator                |
          +----------+------------------ 1-bit DAC --------+
```

Both channels are **bit-interleaved onto a single data line**, which makes the
Pi see an entirely ordinary 48 kHz / 32-bit stereo I2S stream — the most
boring, best-supported mode it has. Each 64-bit frame happens to carry exactly
32 left bits and 32 right bits, which is exactly one output sample per channel.
Software treats the capture as a raw 3.072 Mbps bit river and de-interleaves it.

**Expected performance: 68–70 dB SNR**, matched on purpose to vinyl's own
noise floor. There is no point chasing 100 dB for a source that has 60.

## Why third order

The design is constrained to what the DTU component shop stocks, and the shop's
fastest op-amp is an **LF356 at 5 MHz** with an **LM311** as the only decent
comparator. That caps the clock at 1.536 MHz, where a second-order loop manages
only 53 dB — well short of the target. The third integrator is the price of the
parts list. `docs/design-notes.md` has the numbers behind every such decision.

## Layout

| Path | What |
|---|---|
| `hardware/kicad/vinyl_adc.kicad_sch` | the whole converter on one page — **open this to read the circuit** |
| `hardware/kicad/vinyl_adc_common.kicad_sch` | board 1: power, reference, quantiser |
| `hardware/kicad/vinyl_adc_channel_l.kicad_sch` | board 2, **milled twice**: one modulator channel |
| `hardware/kicad/vinyl_adc_digital.kicad_sch` | board 3: clock, interleave, level shift, Pi header |
| `hardware/kicad/PCB-NOTES.md` | the boards: floorplans, pours, and what the mill dictates |
| `hardware/kicad/vinyl_adc.pdf` | rendered, for reading away from KiCad |
| `hardware/kicad/tools/vinyl_adc_layout.py` | draws all five sheets; re-run to regenerate |
| `hardware/kicad/tools/check_intent.py` | asserts the netlist is the intended circuit |
| `hardware/kicad/tools/check_split.py` | asserts the four boards, welded at their ribbons, ARE that circuit |
| `hardware/kicad/tools/make_bom.py` | BOM, checked against the shop stock list |
| `hardware/kicad/sim/` | eight SPICE testbenches — open a `.kicad_pro` and press Run |
| `hardware/kicad/sim/README.md` | what the simulations found, and the traps they hit |
| `sim/` | the modulator simulator and the scripts that chose every value |
| `docs/design-notes.md` | the decision record — read this before changing anything |
| `docs/bom.md` | bill of materials |
| `docs/HANDOFF-original.md` | the brief this was built from |

Regenerate everything:

```bash
cd "hardware/kicad" && py -3.13 tools/vinyl_adc_layout.py && py -3.13 tools/check_intent.py && py -3.13 tools/check_split.py && py -3.13 sim/tools/sim_layout.py
```

### It is four boards, from three designs

One copper layer with a ground plane on it has no room left for a second net
that has to reach everywhere, and 2.54 mm DIP pitch leaves 0.84 mm between
pads — too narrow for any track this process can cut, so everything routes
*round* its package rather than between the pins. As one board it needed 45
hand-soldered wire links. Split, it needs a fraction of that:

```
   common  ---12-way---  digital          the two channel boards are ONE
     |  |                                 artwork, milled twice
   14-way 14-way
     |  |
  channel L, channel R
```

`docs/design-notes.md` §11 has the measurements and the argument, including
the one thing that changed as a result: the modulator's feedback loop now
crosses a ribbon, which costs 0.5 ns against a 200 ns delay the loop already
compensates for.

## What the simulations say

`hardware/kicad/sim/` is eight KiCad testbenches — one per block plus the whole
loop — generated from the board's *own* layout functions, so each bench is the
same drawing as the board rather than a re-creation of it. 51 design checks and
34 model checks, all passing. The full account is in
[`sim/README.md`](hardware/kicad/sim/README.md) and `docs/design-notes.md` §10;
the short version:

- **The charge pump was wired backwards.** Both Schottkys had anode and cathode
  swapped, which made it a voltage doubler: the net called `-5V` simulated at
  **+3.4 V**. Every other check on this board passed it, because a diode wired
  the wrong way round is still a connected diode. Fixed.
- **The loop survives a vinyl click** — 40 µs at three times full scale, and it
  comes back. That is the thing the whole design leans on.
- **The negative rail is −3.87 V, not −4.1 V**, which leaves the TL074's
  *guaranteed* input common-mode floor at +0.13 V while every virtual earth
  sits at 0 V. It works typically; the margin the design assumed is not there.
  This is the one finding worth acting on at bring-up.
- **The I2S setup margin is 145 ns**, not the 163 ns on paper — ripple-counter
  skew eats the difference. Still four times what the Pi needs.

## Before changing a resistor

Two values in here are load-bearing in non-obvious ways:

- **The integrator state scaling** is chosen so the op-amps saturate at the
  right level. A 1-bit third-order loop that overloads never recovers on its
  own — one vinyl click would latch it at a rail until power-cycled — and that
  saturation is the only thing that rescues it. Re-run `sim/verify.py` if you
  touch the rails or the scaling. (SPICE says the window is wider than it
  looks: recovery is insensitive to where the clamp lands over 2.0–4.5 V.)
- **`Rk0`** (DAC to comparator) is excess-loop-delay compensation. Without it
  the LM311's 200 ns costs 8 dB and most of the overload margin. Measured on
  `sim_e_quantiser` at |k0| = 0.228 against the design's 0.225.

`Rin` is the safe one: it sets full scale only, is not in the feedback path,
and is the right knob if the phono stage turns out louder or quieter than the
~1 Vrms peaks assumed here.

## Still to do

- **Cut the boards.** Gerbers and drill files come out of
  `export_production.ps1`; `hardware/kicad/PCB-NOTES.md` has the commands and
  the two footprint assumptions to check against the real parts first (the
  2u2 film cap's lead pitch and the trimmer body).
- **Order the parts the shop does not stock**: a 6.144 MHz oscillator can, and
  the IDC box headers, sockets and ribbon for the three board-to-board links.
  Everything else is in the shop. The can is worth ordering rather than
  substituting the Pi's GPCLK0, whose jitter would become the dominant noise
  source.
- **Software**: CIC decimator (order ≥4) + FIR compensation + DC block on the
  Pi, then into the existing `pw-record` → sox → FLAC pipeline.

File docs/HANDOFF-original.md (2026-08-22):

# Handoff — Discrete Delta-Sigma Vinyl ADC (from-scratch build)

Written 2026-08-22 by a previous session. The goal of YOUR session: **design the
schematic** (and later the PCB + software). Mads is a DTU EE student; treat him
as technically strong, lead with actions, keep explanations brief unless asked.
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

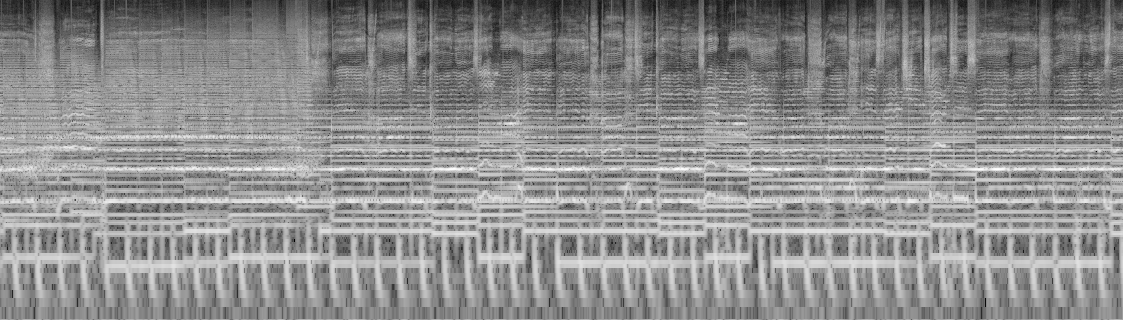
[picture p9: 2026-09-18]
docs/figures/music-spectrogram-data.png

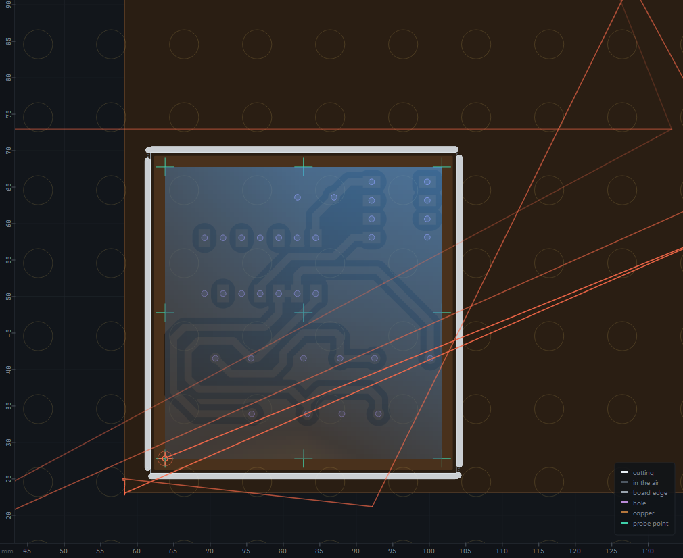
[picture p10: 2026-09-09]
hardware/kicad/osc_module/NC/vinyl_adc_osc_preview.png

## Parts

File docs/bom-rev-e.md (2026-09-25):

# Bill of materials - rev E, the SMD Raspberry Pi HAT

Generated by `hardware/kicad/tools/make_bom_smd.py` from `hardware/kicad/rev_e/vinyl_adc_rev_e.net`. The same circuit as rev D (`docs/bom-rev-d.md`) in surface-mount parts; the values are identical, only packages and four part numbers changed (BC547/557 -> BC847/857, 1N4148 -> 1N4148W, 1N5817 -> SS14, 1N4003 -> S1M). The part numbers are examples of common catalogue parts: anything meeting the spec column fits.

177 components in 65 lines, one board.

| Qty | Value | Refs | Spec | Example |
|----:|---|---|---|---|
| 4 | 100k | R45, R47, R49, R59 | resistor, 1 % thin film, 0805 | any 0805 1 % 0.125 W |
| 1 | 10R0 | R17 | resistor, 1 % thin film, 0805 | any 0805 1 % 0.125 W |
| 13 | 10k0 | R2, R3, R4, R5, R31, R32, R43, R48, R50, R51, R53, R71, R72 | resistor, 1 % thin film, 0805 | any 0805 1 % 0.125 W |
| 2 | 10k5 | R24, R64 | resistor, 1 % thin film, 0805 | any 0805 1 % 0.125 W |
| 4 | 13k0 | R25, R26, R65, R66 | resistor, 1 % thin film, 0805 | any 0805 1 % 0.125 W |
| 4 | 14k7 | R22, R23, R62, R63 | resistor, 1 % thin film, 0805 | any 0805 1 % 0.125 W |
| 2 | 165k | R34, R74 | resistor, 1 % thin film, 0805 | any 0805 1 % 0.125 W |
| 1 | 1M | R10 | resistor, 1 % thin film, 0805 | any 0805 1 % 0.125 W |
| 9 | 1k00 | R16, R20, R40, R41, R42, R52, R57, R58, R60 | resistor, 1 % thin film, 0805 | any 0805 1 % 0.125 W |
| 2 | 20k5 | R21, R61 | resistor, 1 % thin film, 0805 | any 0805 1 % 0.125 W |
| 8 | 22k1 | R33, R35, R36, R44, R46, R73, R75, R76 | resistor, 1 % thin film, 0805 | any 0805 1 % 0.125 W |
| 2 | 255k | R27, R67 | resistor, 1 % thin film, 0805 | any 0805 1 % 0.125 W |
| 1 | 2k2 | R11 | resistor, 1 % thin film, 0805 | any 0805 1 % 0.125 W |
| 2 | 2k21 | R37, R77 | resistor, 1 % thin film, 0805 | any 0805 1 % 0.125 W |
| 3 | 330R | R54, R55, R56 | resistor, 1 % thin film, 0805 | any 0805 1 % 0.125 W |
| 1 | 33R2 | R14 | resistor, 1 % thin film, 0805 | any 0805 1 % 0.125 W |
| 1 | 3k92 | R15 | resistor, 1 % thin film, 0805 | any 0805 1 % 0.125 W |
| 2 | 475R | R12, R13 | resistor, 1 % thin film, 0805 | any 0805 1 % 0.125 W |
| 1 | 4R75 | R1 | resistor, 1 % thin film, 0805 | any 0805 1 % 0.125 W |
| 2 | 5k90 | R28, R68 | resistor, 1 % thin film, 0805 | any 0805 1 % 0.125 W |
| 4 | 8k25 | R29, R30, R69, R70 | resistor, 1 % thin film, 0805 | any 0805 1 % 0.125 W |
| 2 | 47k | RV20, RV60 | 1x3 right-angle header to the panel-mounted 47 k trim pot |  |
| 31 | 100n | C2, C3, C7, C8, C9, C10, C11, C13, C15, C19, C25, C26, C27, C28, C29, C30, C31, C44, C45, C46, C47, C48, C49, C50, C65, C66, C67, C68, C69, C70, C71 | X7R 50 V, 0805 | any 0805 X7R 100 nF |
| 4 | 10u | C4, C41, C42, C43 | X5R 25 V, 1206 | any 1206 X5R 10 uF 25 V |
| 3 | 1n5 | C21, C40, C61 | C0G/NP0 50 V, 0805 | any 0805 C0G 1.5 nF |
| 6 | 220p | C22, C23, C24, C62, C63, C64 | C0G/NP0 50 V, 0805 (integrators: must be C0G) | any 0805 C0G 220 pF |
| 2 | 220u | C5, C6 | aluminium electrolytic 16 V, SMD 6.3 x 7.7 mm | Panasonic EEE-FK1C221P |
| 2 | 27p | C16, C17 | C0G/NP0 50 V, 0805 | any 0805 C0G 27 pF |
| 2 | 2u2 | C20, C60 | film (PET/MKT) 63 V, 10 mm pitch, THT -- input coupling | WIMA MKS4 2.2 uF 63 V |
| 2 | 470u | C1, C18 | aluminium electrolytic 10 V, SMD 8 x 10 mm | Panasonic EEE-FK1A471P |
| 2 | 10u | L1, L2 | 10 uH shielded power inductor, 12 x 12 mm, >= 1 A, low DCR | Bourns SRR1260-100M |
| 4 | 1N4148W | D11, D12, D13, D14 | small-signal diode, SOD-123 | 1N4148W |
| 3 | GREEN | D3, D5, D10 | green 0805 LED | e.g. Kingbright APT2012 series |
| 3 | RED | D6, D7, D8 | red 0805 LED | e.g. Kingbright APT2012 series |
| 2 | S1M | D15, D16 | 1 A rectifier, SMA | S1M |
| 2 | SS14 | D1, D2 | 1 A 40 V Schottky, SMA | SS14 |
| 2 | YELLOW | D4, D9 | yellow 0805 LED | e.g. Kingbright APT2012 series |
| 1 | BC847 | Q1 | NPN, SOT-23 | BC847B |
| 2 | BC857 | Q2, Q3 | PNP, SOT-23 | BC857B |
| 1 | 24LC32 | U11 | 32 kbit I2C EEPROM, SOIC-8 (optional) | Microchip 24LC32A-I/SN |
| 2 | 74HC04 | U24, U64 | hex inverter, SOIC-14 | Nexperia 74HC04D |
| 1 | 74HC157 | U6 | quad 2:1 mux, SOIC-16 | Nexperia 74HC157D |
| 2 | 74HC244 | U1, U10 | octal buffer, SOIC-20 wide (7.5 mm) | Nexperia 74HC244D |
| 1 | 74HC4040 | U4 | 12-stage counter, SOIC-16 | Nexperia 74HC4040D |
| 1 | 74HC4049 | U8 | hex inverter / level shifter, SOIC-16 | Nexperia 74HC4049D |
| 2 | 74HC74 | U23, U63 | dual D flip-flop, SOIC-14 | Nexperia 74HC74D |
| 1 | 74HCT132 | U3 | quad Schmitt NAND, SOIC-14 | Nexperia 74HCT132D |
| 1 | 74HCU04 | U9 | unbuffered hex inverter, SOIC-14 (Pierce oscillator) | Nexperia 74HCU04D |
| 2 | LM311 | U21, U61 | comparator, SOIC-8 | TI LM311DR |
| 1 | LM339 | U12 | quad comparator, SOIC-14 | TI LM339DR |
| 1 | LM358 | U2 | dual op-amp, SOIC-8 | TI LM358DR |
| 4 | TL072 | U20, U22, U60, U62 | dual JFET op-amp, SOIC-8 | TI TL072CDR |
| 1 | 6.144MHz | Y1 | crystal, HC-49/SMD, 18-20 pF load (C16/C17 27p) | any 6.144 MHz HC-49/SMD |
| 1 | SHUTDOWN / WAKE  GPIO3 | SW1 | 6 x 6 mm SMD tact switch | C&K PTS645SM43SMTR92 |
| 1 | USER  GPIO23 | SW2 | 6 x 6 mm SMD tact switch | C&K PTS645SM43SMTR92 |
| 1 | CLK SEL | J1 | 1x3 pin header 2.54 mm + jumper, THT |  |
| 1 | GND LIFT | J4 | 1x2 pin header 2.54 mm + jumper, THT |  |
| 1 | LINE IN L | J20 | 2-way screw terminal, 5.08 mm, THT | bornier-2 5.08 |
| 1 | LINE IN R | J60 | 2-way screw terminal, 5.08 mm, THT | bornier-2 5.08 |
| 1 | RASPBERRY PI 4 | J2 | 2x20 female header, 2.54 mm, THT, on the copper side | Samtec SSQ-120 / any 8.5 mm HAT socket |
| 1 | TONEARM GND | J3 | 2-way screw terminal, 5.08 mm, THT | bornier-2 5.08 |
| 1 | TP DIG | J5 | 2x5 pin header 2.54 mm, THT |  |
| 1 | TP L | J22 | 2x5 pin header 2.54 mm, THT |  |
| 1 | TP R | J62 | 2x5 pin header 2.54 mm, THT |  |
| 1 | WP | J6 | 1x2 pin header 2.54 mm + jumper, THT |  |

## Notes

- **C0G where it says C0G.** C22-C24 / C62-C64 are the loop's integrating capacitors and C21/C61 the input filter; an X7R there changes value with the voltage across it, which is distortion.
- **C20 / C60 stay through-hole film.** 2.2 uF does not exist in C0G, and they sit in series with the audio.
- The four 10 uF parts are ceramic (X5R, 1206). The flying capacitor C4 gains from the lower ESR; the timing caps C41-C43 lose about 40 % to DC bias, so the clip and clock-alive LEDs hold for ~0.6 s instead of ~1 s.
- Hardware: four M2.5 x 11 mm standoffs for the Pi, three M3 for the enclosure; J2 is a plain 8.5 mm 2x20 HAT socket (an 11 mm extended one if the Pi's PoE header touches the socket).

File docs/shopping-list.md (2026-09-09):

# Shopping list - discrete delta-sigma vinyl ADC

The list to take into the DTU component shop, for **one complete stereo
converter**: power board, digital board, and two copies of the channel board.

Verified 2026-09-02 against the three artworks actually being milled
(`power/`, `channel_l/`, `digital/`) and against the shop stock list
(`dtu_component_shop.csv`, 1464 lines). Every shop code below is present in
that list by exact part number and category. It agrees line for line
with the generated `bom.md`; this file adds what that one only mentions in
prose: sockets, headers, shunts, standoffs and the Pi cable, and it says which
shelf each item is on.

**Need** is what the boards take. **Grab** adds a small spare margin, because a
1 % resistor dropped on the floor or a logic chip zapped at bring-up should not
cost a second trip.

## Resistors - shelf "E96 Standard", 1/4 W through-hole

Ask for them by the shop's own code in the first column.

| Shop code | Value | Need | Grab | Where |
|---|---|---:|---:|---|
| 4R75 | 4.75 Ω | 1 | 2 | power R1 (pump post-filter) |
| 1K00 | 1.00 kΩ | 2 | 4 | channel R20 |
| 2K21 | 2.21 kΩ | 2 | 4 | channel R37 |
| 5K90 | 5.90 kΩ | 2 | 4 | channel R28 |
| 8K25 | 8.25 kΩ | 4 | 6 | channel R29, R30 |
| 10K0 | 10.0 kΩ | 8 | 10 | power R2-R5, channel R31, R32 |
| 10K5 | 10.5 kΩ | 2 | 4 | channel R24 |
| 13K0 | 13.0 kΩ | 4 | 6 | channel R25, R26 |
| 14K7 | 14.7 kΩ | 4 | 6 | channel R22, R23 |
| 20K5 | 20.5 kΩ | 2 | 4 | channel R21 |
| 22K1 | 22.1 kΩ | 6 | 8 | channel R33, R35, R36 |
| 165K | 165 kΩ | 2 | 4 | channel R34 |
| 255K | 255 kΩ | 2 | 4 | channel R27 |

13 values, 41 resistors.

## Trimmer - shelf "Trimmer"

| Shop code | Need | Grab | Where |
|---|---:|---:|---|
| 47K trimmer | 2 | 2 | channel RV20, input level |

The footprint on the board is a 3-pin 2.54 mm in-line row. Check the shop's
47K trimmer has that pin arrangement before leaving the counter.

## Capacitors

| Shop code | Shelf | Need | Grab | Where |
|---|---|---:|---:|---|
| 100n | Ceramic | 23 | 26 | decoupling on every IC, all boards |
| 220p | Ceramic | 6 | 8 | channel C22, C23, C24 (integrators) |
| 1n5 | Ceramic | 2 | 4 | channel C21 |
| 2u2 | **Film** | 2 | 2 | channel C20 (input coupling) - film, not electrolytic |
| 10µF | Electrolytic | 1 | 2 | power C4 |
| 220µF | Electrolytic | 2 | 3 | power C5, C6 (pump reservoir and filter) |
| 470µF | Electrolytic | 1 | 2 | power C1 (+5 V reservoir) |

Any voltage rating the shop has is fine: nothing here sees more than 5 V.
The 2u2 film footprint assumes a 10 mm lead pitch and an 11 x 6.3 mm body.
Measure the shop's part; if it differs the footprint changes, not the part.

## Diodes - shelf "Schottky"

| Shop code | Need | Grab | Where |
|---|---:|---:|---|
| 1N5817 | 2 | 4 | power D1, D2 (charge pump) |

## ICs

| Shop code | Shelf | Package | Need | Grab | Where |
|---|---|---|---:|---:|---|
| TL072 | Linear | DIP-8 | 5 | 6 | power U2 (reference), channel U20, U22 (integrators) |
| LM311 | Linear | DIP-8 | 2 | 3 | channel U21 (comparator) |
| 74HC04 | 74HC CMOS Logic | DIP-14 | 2 | 3 | channel U24 (1-bit DAC gates) |
| 27p ceramic | Capacitor Ceramic | disc | 2 | 4 | digital C16, C17 (crystal load caps; 22p/33p also usable) |
| 74HC74 | 74HC CMOS Logic | DIP-14 | 2 | 3 | channel U23 (retiming flip-flop) |
| 74HCT132 | 74HCT Logic | DIP-14 | 1 | 2 | digital U3 (clock input buffer) - **HCT, not HC** |
| 74HC157 | 74HC CMOS Logic | DIP-16 | 1 | 2 | digital U6 (L/R interleave mux) |
| 74HC4040 | 74HC CMOS Logic | DIP-16 | 1 | 2 | digital U4 (clock divider) |
| 74HC4049 | 74HC CMOS Logic | DIP-16 | 1 | 2 | digital U8 (5 V to 3.3 V level shift) |
| 74HC244 | 74HC CMOS Logic | DIP-20 | 1 | 2 | power U1 (charge pump driver) |

U3 must be the **74HCT132**: its TTL-level input threshold is what lets the
board accept a 3.3 V oscillator or the Pi's 3.3 V GPCLK0. A 74HC132 will not
do. The shop stocks both, so read the label.

## DIP sockets - shelf "IC Socket"

Every IC is socketed. The 6.144 MHz crystal (Y1) solders in directly.

| Shop code | Need | Grab | For |
|---|---:|---:|---|
| DIP8 Socket | 7 | 8 | 5 x TL072, 2 x LM311 |
| DIP14 Socket | 6 | 7 | 2 x 74HC04, 2 x 74HC74, 74HCT132, 74HCU04 |
| DIP16 Socket | 3 | 4 | 74HC157, 74HC4040, 74HC4049 |
| DIP20 Socket | 1 | 1 | 74HC244 |

## Connectors - shelves "Header" and "Terminal"

| Shop code | Need | Where |
|---|---:|---|
| 2 pol skrueterminal | 2 | channel J20, line in (one per channel) |
| Header Male (straight strip) | 1 strip | cut into: 3 x 1x3 (J1 clock select, J21 Q select on each channel) and 1 x 1x8 (J2 to the Pi) |
| Jumper (shunt) | 3 | J1, and J21 on each channel board |

The Q-select shunt on J21 is the only thing that makes a channel board left or
right: pins 1-2 is LEFT, pins 2-3 is RIGHT.

## Not in the shop - order these

The shop's list has none of the following. They go on one order together.

| Item | Qty | Notes |
|---|---:|---|
| **74HCU04** unbuffered hex inverter, DIP-14 | 1 (+1 spare) | U9, the Pierce oscillator gate around the 6.144 MHz crystal already in hand. Must be the UNBUFFERED part -- a buffered 74HC04 can take off at ~30 MHz through the crystal's holder capacitance (design-notes §5). Pin-identical to 74HC04. |
| ~~6.144 MHz crystal oscillator can~~ | 0 | Superseded: a bare 6.144 MHz crystal was found and the clock is now an on-board Pierce (rev B) or the plug-in module in `hardware/kicad/osc_module/` (rev A). A can still drops straight into rev A's X1 socket if one ever surfaces. |
| **2x8 stacking headers, 2.54 mm** | 4 sets | The board-to-board bus (J3, J4, J7 x2). One plain female socket for the top board, one long-pin male for the bottom, two pass-through stacking headers for the middle. The shop's "Double Male" and "Female Header" strips can stand in for top and bottom, but nothing it stocks does the pass-through middle pair. |
| **M3 x 11 mm standoffs** | 16 | Four per board gap and mount. Confirm the length against the stacking header you actually order. |
| **M3 screws and nuts** | 16 + 16 | For the standoffs. |
| **Female-to-female jumper wires, 8 way** | 1 set | J2 to the Pi's GPIO header. Any 20 cm Dupont set does it. |
| RCA phono sockets | 2 | Optional. The board has screw terminals; fit RCA only if the phono stage's cable ends that way. |

## Consumables to have on the bench

- Hookup wire for the wire links the single-sided boards need. `PCB-NOTES.md`
  counts roughly fifty hand-soldered joints across the set.
- Solder. Ground pads join the pour solid with no thermal relief, so plan on
  a 40 W+ iron and give each ground joint a couple of extra seconds.

## Totals

| | Lines | Pieces |
|---|---:|---:|
| Components on the boards | 37 | 109 |
| Sockets, shunts, header strip, terminals | 8 | 24 + 1 strip |
| To order | 5 to 6 | see above |

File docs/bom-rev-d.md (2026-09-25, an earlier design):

# Bill of materials - discrete delta-sigma vinyl ADC

Generated by `hardware/kicad/tools/make_bom.py` straight from the
schematic, with every line checked against the DTU shop stock list
(`dtu_component_shop.csv`). **ORDER** means the shop does not carry it.

177 components in 65 distinct lines, for the ONE fabricated rev D board (`hardware/kicad/rev_d`): the converter as a Raspberry Pi HAT.

**Board** is always **D**: one four-layer artwork, built once, so a quantity is simply the count on the sheet. The right channel carries the reference sheet's refdes, forty higher than the left. Against rev C this adds the +5VA analog island (L2, C18, C19), a second charge-pump driver (U10), R14 in MCLK, eight status LEDs with their drivers (U12 LM339 clip detectors, Q1 clock-alive pump, Q2/Q3), two buttons, the HAT ID EEPROM (U11, optional), the chassis-ground terminal and lift network (J3, J4), and three test-point headers; L1 replaces rev C's ferrite bead with a stocked choke.

| Qty | Value | Refs | Board | DTU shop |
|----:|---|---|---|---|
| 4 | 100k | R45, R47, R49, R59 | D 4 | E96 100K |
| 1 | 10R0 | R17 | D 1 | E96 10R0 |
| 13 | 10k0 | R2, R3, R4, R5, R31, R32, R43, R48, R50, R51, R53, R71, R72 | D 13 | E96 10K0 |
| 2 | 10k5 | R24, R64 | D 2 | E96 10K5 |
| 4 | 13k0 | R25, R26, R65, R66 | D 4 | E96 13K0 |
| 4 | 14k7 | R22, R23, R62, R63 | D 4 | E96 14K7 |
| 2 | 165k | R34, R74 | D 2 | E96 165K |
| 1 | 1M | R10 | D 1 | E96 1M00 |
| 9 | 1k00 | R16, R20, R40, R41, R42, R52, R57, R58, R60 | D 9 | E96 1K00 |
| 2 | 20k5 | R21, R61 | D 2 | E96 20K5 |
| 8 | 22k1 | R33, R35, R36, R44, R46, R73, R75, R76 | D 8 | E96 22K1 |
| 2 | 255k | R27, R67 | D 2 | E96 255K |
| 1 | 2k2 | R11 | D 1 | E96 2K21 |
| 2 | 2k21 | R37, R77 | D 2 | E96 2K21 |
| 3 | 330R | R54, R55, R56 | D 3 | E96 330R |
| 1 | 33R2 | R14 | D 1 | E96 33R2 |
| 1 | 3k92 | R15 | D 1 | E96 3K92 |
| 2 | 475R | R12, R13 | D 2 | E96 475R |
| 1 | 4R75 | R1 | D 1 | E96 4R75 |
| 2 | 5k90 | R28, R68 | D 2 | E96 5K90 |
| 4 | 8k25 | R29, R30, R69, R70 | D 4 | E96 8K25 |
| 31 | 100n | C2, C3, C7, C8, C9, C10, C11, C13, C15, C19, C25, C26, C27, C28, C29, C30, C31, C44, C45, C46, C47, C48, C49, C50, C65, C66, C67, C68, C69, C70, C71 | D 31 | Ceramic 100nF |
| 4 | 10u | C4, C41, C42, C43 | D 4 | Electrolytic 10µF |
| 3 | 1n5 | C21, C40, C61 | D 3 | Ceramic 1.5nF |
| 6 | 220p | C22, C23, C24, C62, C63, C64 | D 6 | Ceramic 220pF |
| 2 | 220u | C5, C6 | D 2 | Electrolytic 220µF |
| 2 | 27p | C16, C17 | D 2 | Ceramic 27pF |
| 2 | 2u2 | C20, C60 | D 2 | Film 2.2µF |
| 2 | 470u | C1, C18 | D 2 | Electrolytic 470µF |
| 2 | 1N4003 | D15, D16 | D 2 | Rectifier |
| 4 | 1N4148 | D11, D12, D13, D14 | D 4 | Signal |
| 2 | 1N5817 | D1, D2 | D 2 | Schottky |
| 3 | GREEN | D3, D5, D10 | D 3 | LED 5MM GRØN |
| 3 | RED | D6, D7, D8 | D 3 | LED 5MM RØD |
| 2 | YELLOW | D4, D9 | D 2 | LED 5MM GUL |
| 1 | 24LC32 | U11 | D 1 | ** ORDER ** |
| 1 | 6.144MHz | Y1 | D 1 | ** ORDER ** |
| 2 | 74HC04 | U24, U64 | D 2 | 74HC CMOS Logic |
| 1 | 74HC157 | U6 | D 1 | 74HC CMOS Logic |
| 2 | 74HC244 | U1, U10 | D 2 | 74HC CMOS Logic |
| 1 | 74HC4040 | U4 | D 1 | 74HC CMOS Logic |
| 1 | 74HC4049 | U8 | D 1 | 74HC CMOS Logic |
| 2 | 74HC74 | U23, U63 | D 2 | 74HC CMOS Logic |
| 1 | 74HCT132 | U3 | D 1 | 74HCT Logic |
| 1 | 74HCU04 | U9 | D 1 | ** ORDER ** |
| 2 | LM311 | U21, U61 | D 2 | Linear |
| 1 | LM339 | U12 | D 1 | Linear |
| 1 | LM358 | U2 | D 1 | Linear |
| 4 | TL072 | U20, U22, U60, U62 | D 4 | Linear |
| 1 | CLK SEL | J1 | D 1 | Header Male + Jumper |
| 1 | GND LIFT | J4 | D 1 | Header Male + Jumper |
| 1 | LINE IN L | J20 | D 1 | Terminal 2 pol skrueterminal |
| 1 | LINE IN R | J60 | D 1 | Terminal 2 pol skrueterminal |
| 1 | RASPBERRY PI 4 | J2 | D 1 | ** ORDER ** |
| 1 | TONEARM GND | J3 | D 1 | Terminal 2 pol skrueterminal |
| 1 | TP DIG | J5 | D 1 | Header Male 2x5 |
| 1 | TP L | J22 | D 1 | Header Male 2x5 |
| 1 | TP R | J62 | D 1 | Header Male 2x5 |
| 1 | WP | J6 | D 1 | Header Male + Jumper |
| 2 | 47k | RV20, RV60 | D 2 | Trimmer 47K |
| 2 | 10u | L1, L2 | D 2 | Inductor 10µ 3A |
| 1 | BC547 | Q1 | D 1 | NPN BJT |
| 2 | BC557 | Q2, Q3 | D 2 | PNP BJT |
| 1 | SHUTDOWN / WAKE  GPIO3 | SW1 | D 1 | Hardware Pushbutton (6 mm tactile) |
| 1 | USER  GPIO23 | SW2 | D 1 | Hardware Pushbutton (6 mm tactile) |

## Must be ordered

- **24LC32** (U11)
- **6.144MHz** (Y1)
- **74HCU04** (U9)
- **RASPBERRY PI 4** (J2)

## Sockets

Use DIP sockets for every IC (all stocked): 8-pin for the TL072s
and the LM311s, 14-pin for the 74HC04 / 74HCU04 / 74HC74 /
74HCT132, 16-pin for the 74HC157 / 74HC4040 / 74HC4049, 20-pin for
the 74HC244. The crystal Y1 solders in directly.

Also 8-pin for the LM358 and the 24LC32, 14-pin for the LM339. J2 is a 2x20 FEMALE header on the copper side (a plain 8.5 mm HAT socket; an 11 mm extended-height one if the Pi's PoE header touches the leads at the socket's top end). L1 and L2 are the shop's 10 uH 3 A choke on a 15.24 mm axial footprint. The LEDs are 5 mm, colours as in the Value column; the buttons are 6 mm tactile. Four M2.5 standoffs (11 mm) carry the Pi under the board, four M3 the board in its enclosure.

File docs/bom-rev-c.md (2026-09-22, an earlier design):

# Bill of materials - discrete delta-sigma vinyl ADC

Generated by `hardware/kicad/tools/make_bom.py` straight from the
schematic, with every line checked against the DTU shop stock list
(`dtu_component_shop.csv`). **ORDER** means the shop does not carry it.

111 components in 43 distinct lines, for the ONE fabricated rev C board (`hardware/kicad/rev_c`), which replaces the four milled boards.

**Board** is always **C**: one four-layer artwork, built once, so a quantity is simply the count on the sheet. The right channel carries the reference sheet's refdes, forty higher than the left. Against the milled boards this adds U2 as an LM358 (docs/design-notes.md 10b'), FB1 on the 5 V inlet, R12/R13 in series with BCLK/LRCLK, and the Pi's own 2x20 socket J2 in place of the pigtail and stacking bus.

| Qty | Value | Refs | Board | DTU shop |
|----:|---|---|---|---|
| 8 | 10k0 | R2, R3, R4, R5, R31, R32, R71, R72 | C 8 | E96 10K0 |
| 2 | 10k5 | R24, R64 | C 2 | E96 10K5 |
| 4 | 13k0 | R25, R26, R65, R66 | C 4 | E96 13K0 |
| 4 | 14k7 | R22, R23, R62, R63 | C 4 | E96 14K7 |
| 2 | 165k | R34, R74 | C 2 | E96 165K |
| 1 | 1M | R10 | C 1 | E96 1M00 |
| 2 | 1k00 | R20, R60 | C 2 | E96 1K00 |
| 2 | 20k5 | R21, R61 | C 2 | E96 20K5 |
| 6 | 22k1 | R33, R35, R36, R73, R75, R76 | C 6 | E96 22K1 |
| 2 | 255k | R27, R67 | C 2 | E96 255K |
| 1 | 2k2 | R11 | C 1 | E96 2K21 |
| 2 | 2k21 | R37, R77 | C 2 | E96 2K21 |
| 2 | 475R | R12, R13 | C 2 | E96 475R |
| 1 | 4R75 | R1 | C 1 | E96 4R75 |
| 2 | 5k90 | R28, R68 | C 2 | E96 5K90 |
| 4 | 8k25 | R29, R30, R69, R70 | C 4 | E96 8K25 |
| 23 | 100n | C2, C3, C7, C8, C9, C10, C11, C13, C15, C25, C26, C27, C28, C29, C30, C31, C65, C66, C67, C68, C69, C70, C71 | C 23 | Ceramic 100nF |
| 1 | 10u | C4 | C 1 | Electrolytic 10µF |
| 2 | 1n5 | C21, C61 | C 2 | Ceramic 1.5nF |
| 6 | 220p | C22, C23, C24, C62, C63, C64 | C 6 | Ceramic 220pF |
| 2 | 220u | C5, C6 | C 2 | Electrolytic 220µF |
| 2 | 27p | C16, C17 | C 2 | Ceramic 27pF |
| 2 | 2u2 | C20, C60 | C 2 | Film 2.2µF |
| 1 | 470u | C1 | C 1 | Electrolytic 470µF |
| 2 | 1N5817 | D1, D2 | C 2 | Schottky |
| 1 | FB | FB1 | C 1 | ** ORDER ** |
| 1 | 6.144MHz | Y1 | C 1 | ** ORDER ** |
| 2 | 74HC04 | U24, U64 | C 2 | 74HC CMOS Logic |
| 1 | 74HC157 | U6 | C 1 | 74HC CMOS Logic |
| 1 | 74HC244 | U1 | C 1 | 74HC CMOS Logic |
| 1 | 74HC4040 | U4 | C 1 | 74HC CMOS Logic |
| 1 | 74HC4049 | U8 | C 1 | 74HC CMOS Logic |
| 2 | 74HC74 | U23, U63 | C 2 | 74HC CMOS Logic |
| 1 | 74HCT132 | U3 | C 1 | 74HCT Logic |
| 1 | 74HCU04 | U9 | C 1 | ** ORDER ** |
| 2 | LM311 | U21, U61 | C 2 | Linear |
| 1 | LM358 | U2 | C 1 | Linear |
| 4 | TL072 | U20, U22, U60, U62 | C 4 | Linear |
| 1 | CLK SEL | J1 | C 1 | Header Male + Jumper |
| 1 | LINE IN L | J20 | C 1 | Terminal 2 pol skrueterminal |
| 1 | LINE IN R | J60 | C 1 | Terminal 2 pol skrueterminal |
| 1 | RASPBERRY PI 4 | J2 | C 1 | ** ORDER ** |
| 2 | 47k | RV20, RV60 | C 2 | Trimmer 47K |

## Must be ordered

- **FB** (FB1)
- **6.144MHz** (Y1)
- **74HCU04** (U9)
- **RASPBERRY PI 4** (J2)

## Sockets

Use DIP sockets for every IC (all stocked): 8-pin for the TL072s
and the LM311s, 14-pin for the 74HC04 / 74HCU04 / 74HC74 /
74HCT132, 16-pin for the 74HC157 / 74HC4040 / 74HC4049, 20-pin for
the 74HC244. The crystal Y1 solders in directly.

J2 is a 2x20 FEMALE header on the copper side (a plain 8.5 mm HAT socket; an 11 mm extended-height one if the Pi's PoE header touches the leads at the socket's top end). FB1 is any axial ferrite bead on a lead, 10.16 mm pitch -- or a wire link. The board also wants four M2.5 standoffs for the Pi and four M3 for the enclosure.

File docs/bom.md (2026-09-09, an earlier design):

# Bill of materials - discrete delta-sigma vinyl ADC

Generated by `hardware/kicad/tools/make_bom.py` straight from the
schematic, with every line checked against the DTU shop stock list
(`dtu_component_shop.csv`). **ORDER** means the shop does not carry it.

114 components in 41 distinct lines, for the four boards a stereo ADC needs.

**Board** is **P** power (supplies and the +/-2.5 V reference), **M** modulator channel, **D** digital (clock, interleave, level shift, Pi). Three artworks, four boards: the channel is ONE artwork MILLED TWICE, so its lines are marked `M x2` and the quantity already counts both. The refdes shown are the ones printed on the copper, and the second copy carries the same ones -- the reference sheet numbers that channel forty higher, the board does not.

| Qty | Value | Refs | Board | DTU shop |
|----:|---|---|---|---|
| 8 | 10k0 | R2, R3, R4, R5, R31, R32 | P 4 + M 2 x2 | E96 10K0 |
| 2 | 10k5 | R24 | M 1 x2 | E96 10K5 |
| 4 | 13k0 | R25, R26 | M 2 x2 | E96 13K0 |
| 4 | 14k7 | R22, R23 | M 2 x2 | E96 14K7 |
| 2 | 165k | R34 | M 1 x2 | E96 165K |
| 1 | 1M | R10 | D 1 | E96 1M00 |
| 2 | 1k00 | R20 | M 1 x2 | E96 1K00 |
| 2 | 20k5 | R21 | M 1 x2 | E96 20K5 |
| 6 | 22k1 | R33, R35, R36 | M 3 x2 | E96 22K1 |
| 2 | 255k | R27 | M 1 x2 | E96 255K |
| 1 | 2k2 | R11 | D 1 | E96 2K21 |
| 2 | 2k21 | R37 | M 1 x2 | E96 2K21 |
| 1 | 4R75 | R1 | P 1 | E96 4R75 |
| 2 | 5k90 | R28 | M 1 x2 | E96 5K90 |
| 4 | 8k25 | R29, R30 | M 2 x2 | E96 8K25 |
| 23 | 100n | C2, C3, C7, C8, C9, C10, C11, C13, C15, C25, C26, C27, C28, C29, C30, C31 | P 4 + M 7 x2 + D 5 | Ceramic 100nF |
| 1 | 10u | C4 | P 1 | Electrolytic 10µF |
| 2 | 1n5 | C21 | M 1 x2 | Ceramic 1.5nF |
| 6 | 220p | C22, C23, C24 | M 3 x2 | Ceramic 220pF |
| 2 | 220u | C5, C6 | P 2 | Electrolytic 220µF |
| 2 | 27p | C16, C17 | D 2 | Ceramic 27pF |
| 2 | 2u2 | C20 | M 1 x2 | Film 2.2µF |
| 1 | 470u | C1 | P 1 | Electrolytic 470µF |
| 2 | 1N5817 | D1, D2 | P 2 | Schottky |
| 2 | 74HC04 | U24 | M 1 x2 | 74HC CMOS Logic |
| 1 | 74HC157 | U6 | D 1 | 74HC CMOS Logic |
| 1 | 74HC244 | U1 | P 1 | 74HC CMOS Logic |
| 1 | 74HC4040 | U4 | D 1 | 74HC CMOS Logic |
| 1 | 74HC4049 | U8 | D 1 | 74HC CMOS Logic |
| 2 | 74HC74 | U23 | M 1 x2 | 74HC CMOS Logic |
| 1 | 74HCT132 | U3 | D 1 | 74HCT Logic |
| 1 | 74HCU04 | U9 | D 1 | ** ORDER ** |
| 2 | LM311 | U21 | M 1 x2 | Linear |
| 5 | TL072 | U2, U20, U22 | P 1 + M 2 x2 | Linear |
| 4 | 2x8 BUS | J3, J4, J7 | P 1 + M 1 x2 + D 1 | ** ORDER ** |
| 1 | CLK SEL | J1 | D 1 | Header Male + Jumper |
| 2 | LINE IN L | J20 | M 1 x2 | Terminal 2 pol skrueterminal |
| 2 | Q SEL | J21 | M 1 x2 | Header Male + Jumper |
| 1 | TO PI GPIO | J2 | D 1 | Header Male 1x8 |
| 2 | 47k | RV20 | M 1 x2 | Trimmer 47K |
| 1 | 6.144MHz | Y1 | D 1 | ** ORDER ** |

## Must be ordered

- **74HCU04** (U9)
- **2x8 BUS** (J3, J4, J7)
- **6.144MHz** (Y1)

## Sockets

Use DIP sockets for every IC (all stocked): 8-pin for the TL072s
and the LM311s, 14-pin for the 74HC04 / 74HCU04 / 74HC74 /
74HCT132, 16-pin for the 74HC157 / 74HC4040 / 74HC4049, 20-pin for
the 74HC244. The crystal Y1 solders in directly.

## The stacking bus

There are no ribbons. Every board carries the SAME 2x8 on 2.54 mm
at the SAME coordinates, and the four boards plug into each other
on 11 mm standoffs:

| Board | Ref | Ways | Position in the stack |
|---|---|---|---|
| digital | J4 | 2x8 | top |
| channel L | J7 | 2x8 | middle |
| channel R | J7 | 2x8 | middle |
| power | J3 | 2x8 | bottom |

Odd pins are all GND, so every signal has a grounded neighbour
either side -- which is what MCLK needs, its jitter being what sets
this converter's noise floor. The even pins carry, in order:
**+5V, VREF_P, VREF_N, MCLK, PUMP, QL, QR, -5V**.

What goes in the sixteen holes is a build choice, not an artwork
choice: a plain socket on the top board, a long-pin header on the
bottom one, and a pass-through stacking header on the two in the
middle. All three are the same sixteen pads. You need 4 sets plus
16 x 11 mm M3 standoffs and the M3 screws; the shop carries none of
them, so they go on the same order as the 74HCU04.

## Which channel is which

Both channel boards are the same copper, so nothing etched on them
says which channel a board is. The Q-select shunt does: **J21 1-2
makes it LEFT, 2-3 makes it RIGHT**. Fit one jumper per channel
board and they are otherwise interchangeable.

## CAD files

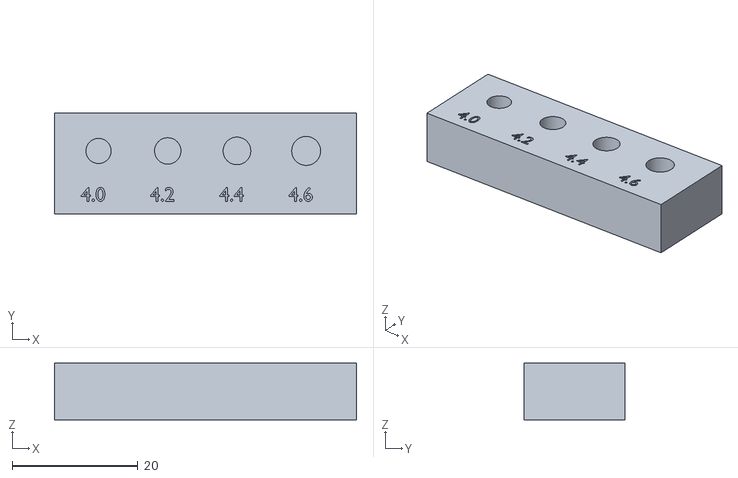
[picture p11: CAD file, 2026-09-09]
enclosure/m3_insert_fit_coupon.stl
48.0 x 16.0 x 9.00

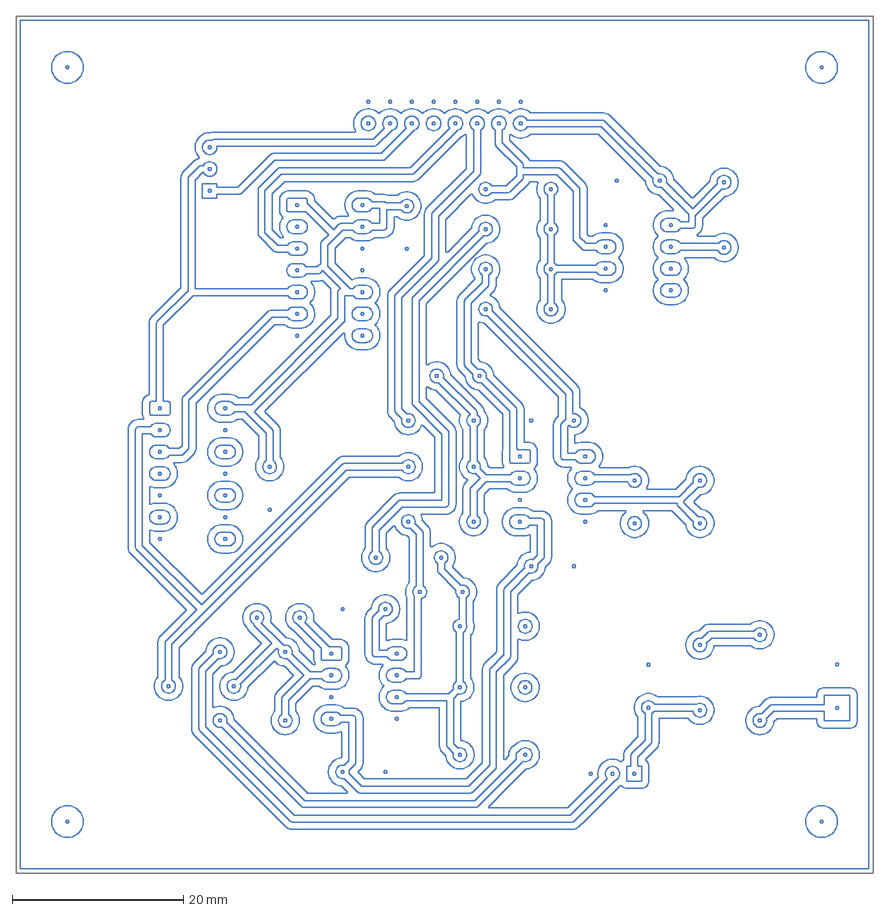
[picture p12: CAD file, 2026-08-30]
production/vinyl_adc_channel_l/vinyl_adc_channel_l.dxf
100.0 x 100.0 mm

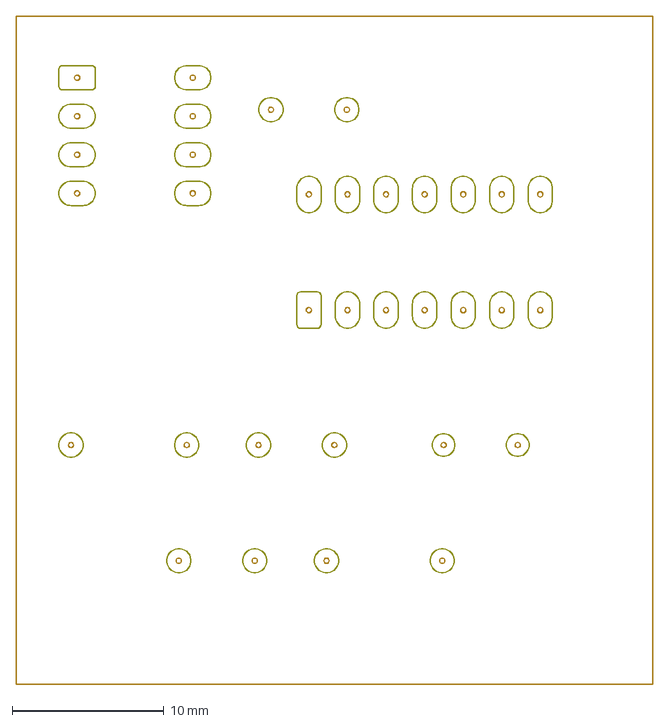
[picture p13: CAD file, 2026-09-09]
production/vinyl_adc_osc/vinyl_adc_osc_top_cu.dxf
41.9 x 44.0 mm

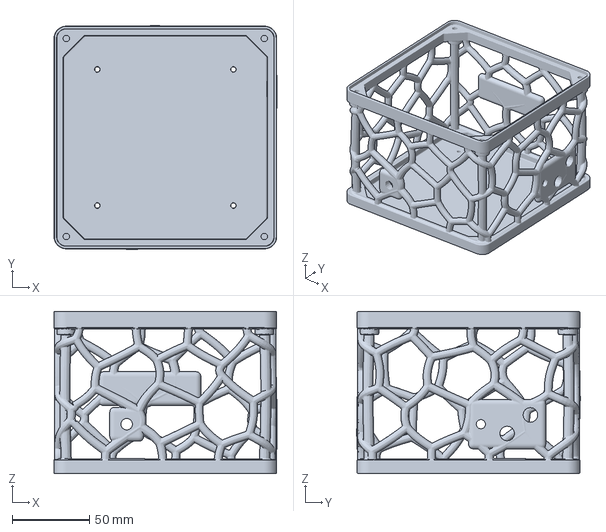
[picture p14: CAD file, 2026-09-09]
enclosure/vinyl_adc_enclosure_base.3mf
144.2 x 144.6 x 105.0 mm

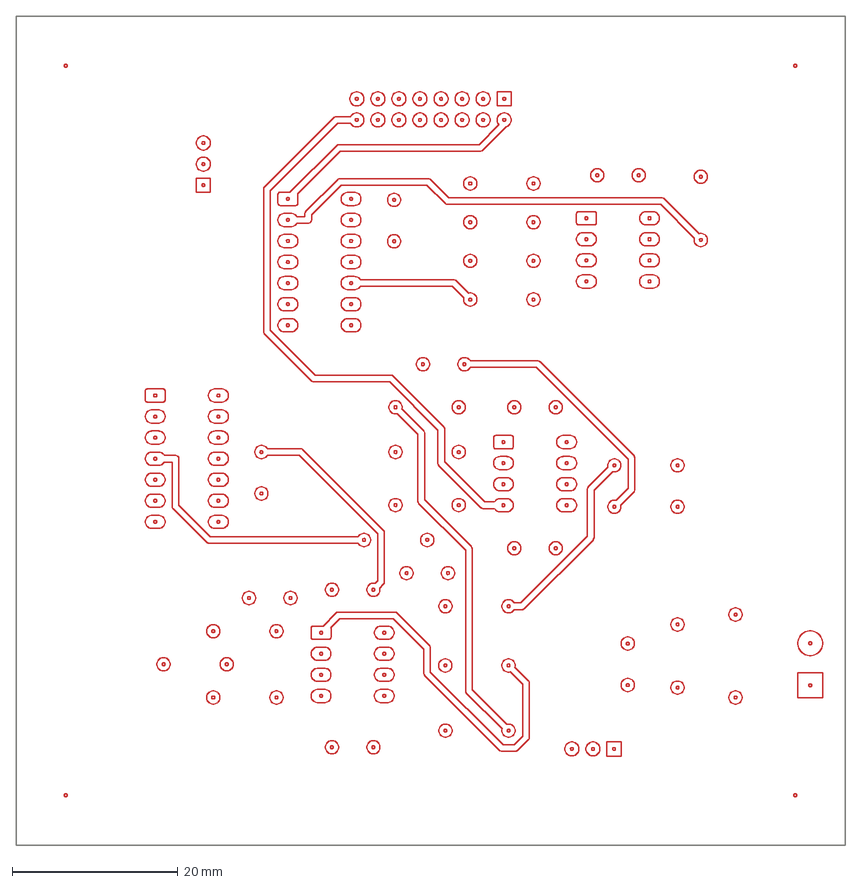
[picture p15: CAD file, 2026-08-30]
production/vinyl_adc_channel_l/vinyl_adc_channel_l_top_cu.dxf
100.0 x 100.0 mm

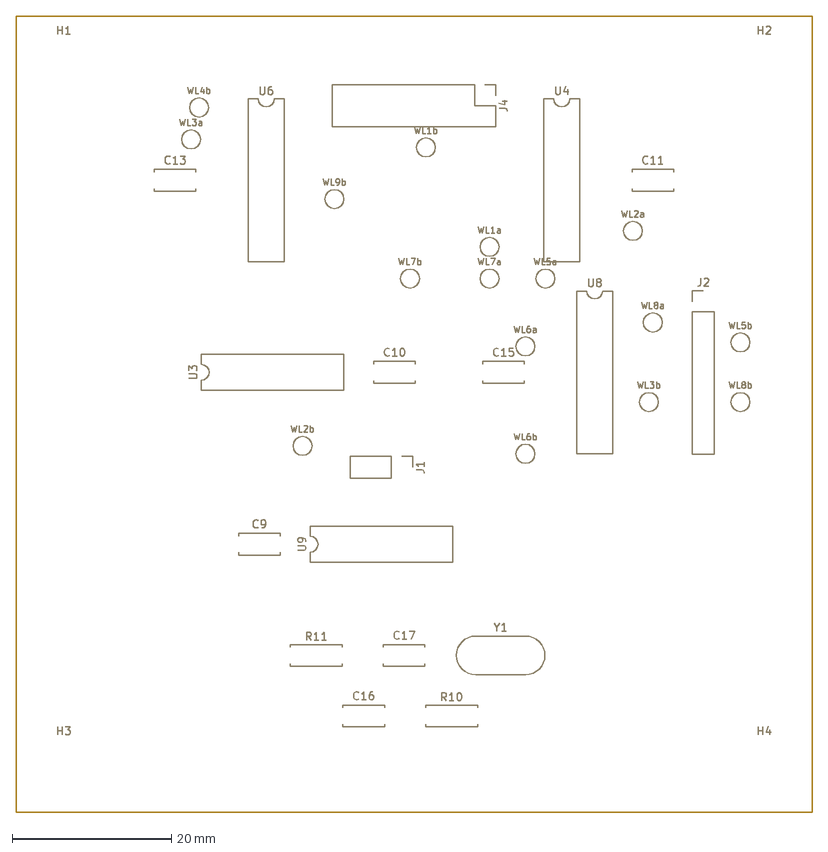
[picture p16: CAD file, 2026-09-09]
production/vinyl_adc_digital/vinyl_adc_digital_silk_top.dxf
100.0 x 100.0 mm

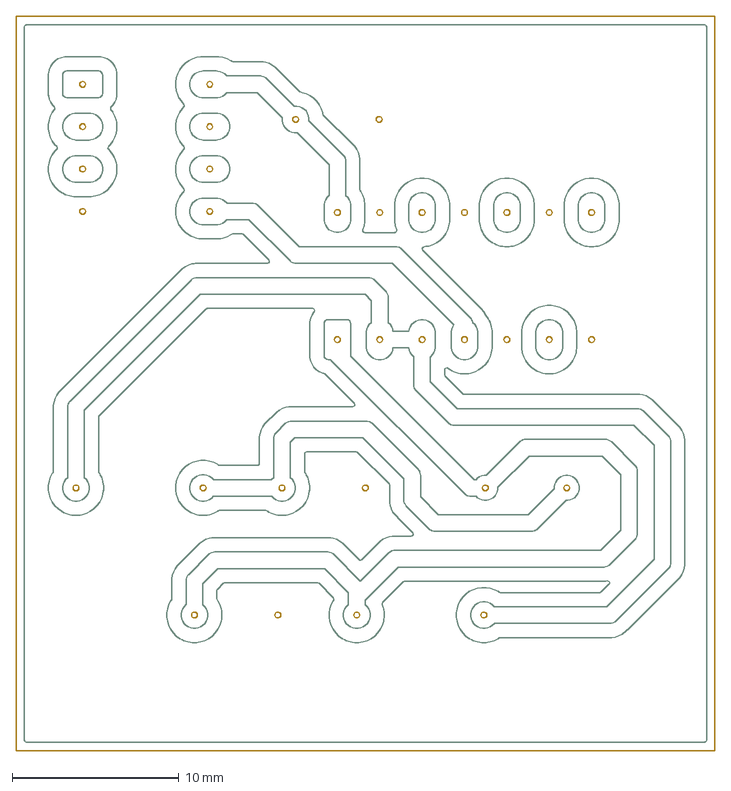
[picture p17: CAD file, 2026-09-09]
production/vinyl_adc_osc/vinyl_adc_osc.dxf
41.9 x 44.0 mm

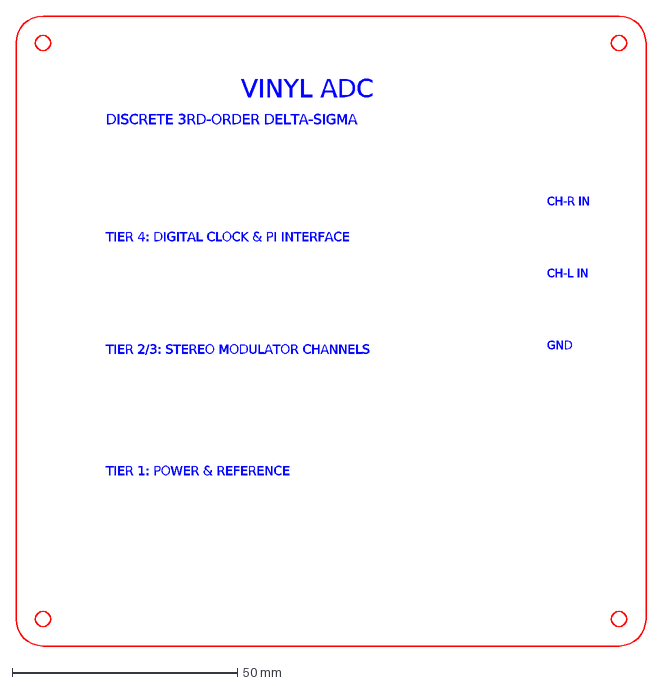
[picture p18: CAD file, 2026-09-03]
enclosure/vinyl_adc_plexiglass_top.dxf
VINYL ADC
DISCRETE 3RD-ORDER DELTA-SIGMA
TIER 4: DIGITAL CLOCK & PI INTERFACE
TIER 2/3: STEREO MODULATOR CHANNELS
TIER 1: POWER & REFERENCE
CH-R IN
CH-L IN
GND

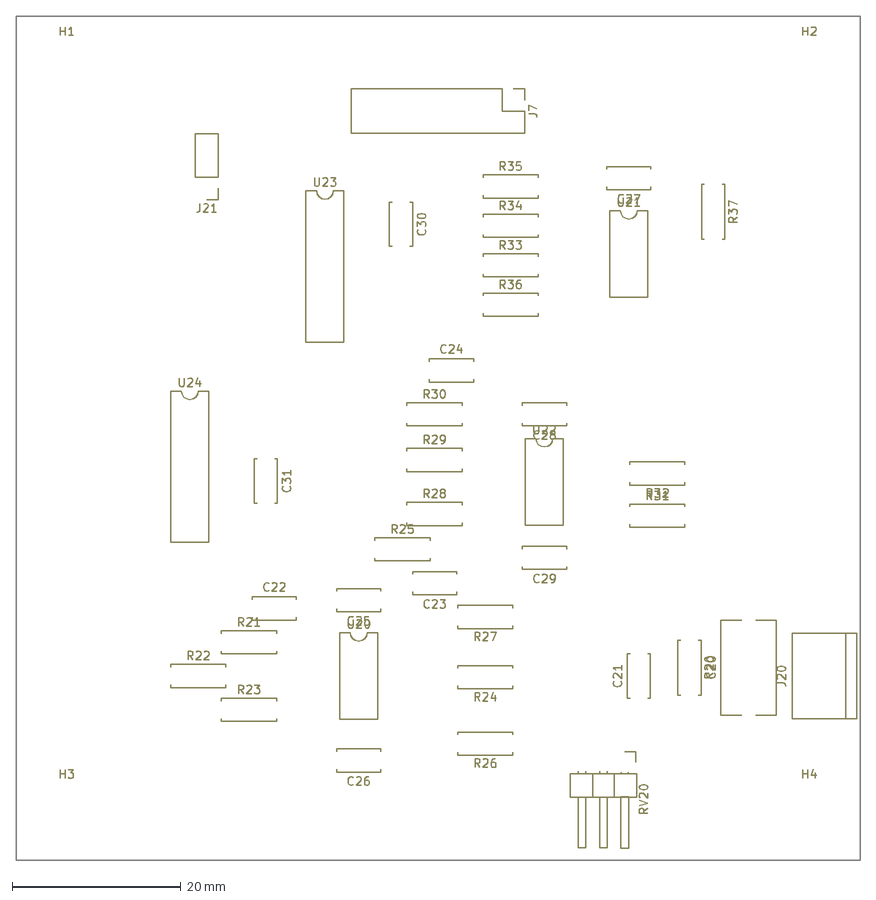
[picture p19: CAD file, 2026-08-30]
production/vinyl_adc_channel_l/vinyl_adc_channel_l_silk_top.dxf
100.0 x 100.0 mm

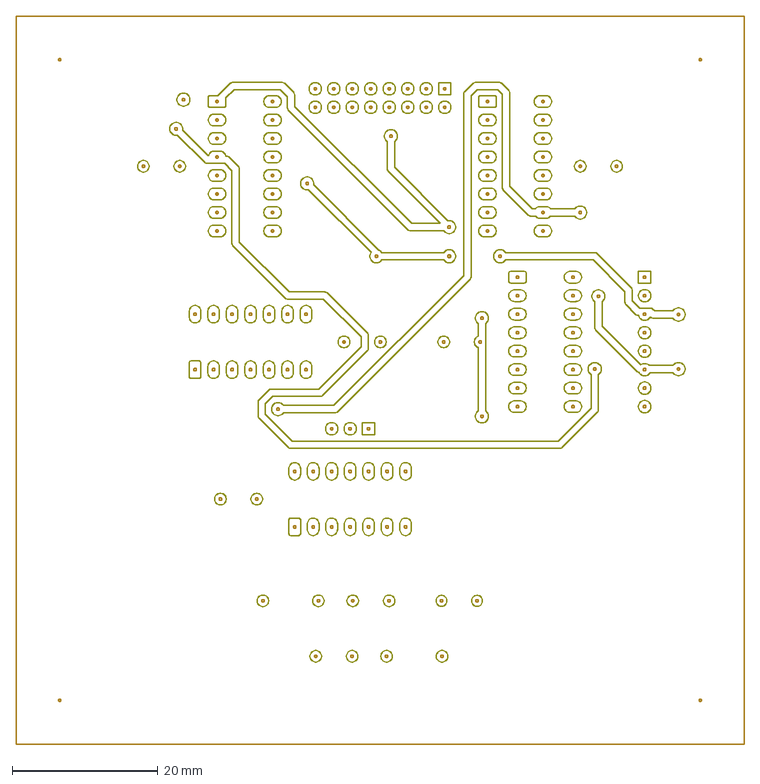
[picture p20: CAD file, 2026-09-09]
production/vinyl_adc_digital/vinyl_adc_digital_top_cu.dxf
100.0 x 100.0 mm

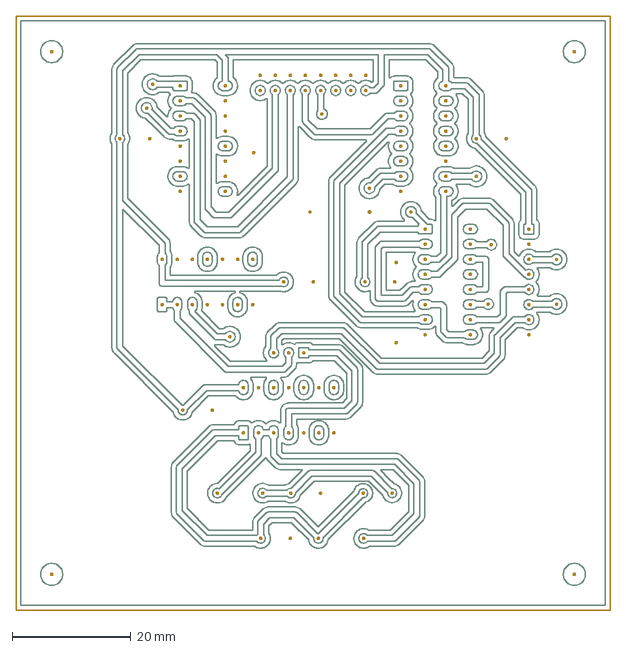
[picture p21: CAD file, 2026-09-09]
production/vinyl_adc_digital/vinyl_adc_digital.dxf
100.0 x 100.0 mm

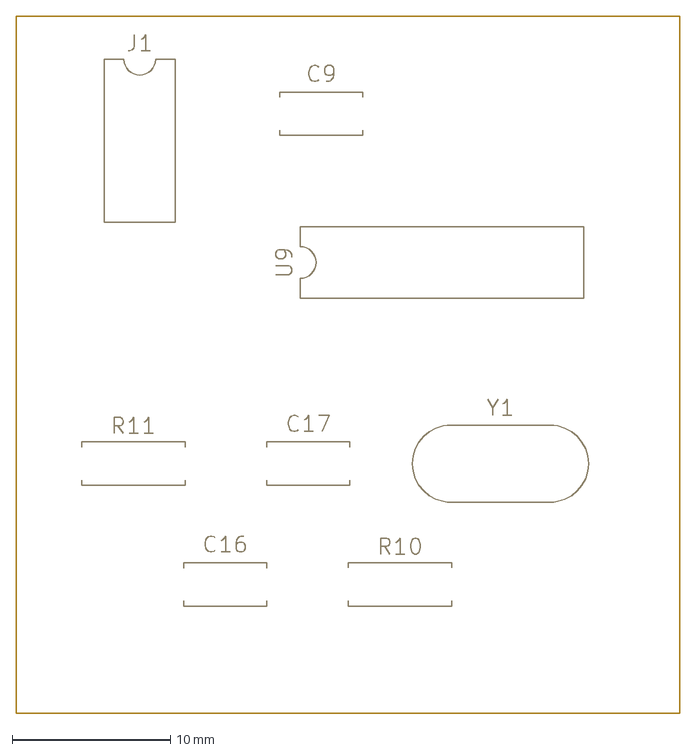
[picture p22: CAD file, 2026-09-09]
production/vinyl_adc_osc/vinyl_adc_osc_silk_top.dxf
41.9 x 44.0 mm

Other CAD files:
production/vinyl_adc_digital/vinyl_adc_digital_mask_bottom.dxf
production/vinyl_adc_osc/vinyl_adc_osc_mask_bottom.dxf
enclosure/source/original_assembly.blend
enclosure/vinyl_adc_enclosure.blend
enclosure/vinyl_adc_enclosure_base.stl

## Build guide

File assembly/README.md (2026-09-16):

# Local assembly bench

Public guide: **https://vinyl-adc.madsrudolph.dev/**. Current bench plan: [16 September 2026](sessions/2026-09-16/README.md) for the rev B digital board and both populated channels (no results recorded yet). Latest manual handoff: [6 September 2026](sessions/2026-09-06/README.md), rev A digital board with an external clock, with screenshots and a structured `session.json`. The public guide is static and never controls instruments. Browser progress is origin-specific: export a backup from localhost and restore it on the hosted domain. Local SDK captures are not automatically uploaded.

Start from the repository root:

```sh
python assembly/serve.py
```

## Publishing

`python assembly/build_site.py` produces `assembly/site-dist/`, excluding installers, extracted vendor packages, Python caches and local SDK captures. Published manual sessions are explicitly stored under `sessions/`. The Cloudflare Pages project is `vinyl-adc-assembly`; its deployment workflow lives in `MadsRudolph/madsrudolph.dev`, alongside the existing Cloudflare credentials. Dispatch `deploy-assembly.yml` there with the full pushed Vinyl ADC commit SHA. The portfolio site has its own independent deployment.

Open http://localhost:8080. The server listens only on 127.0.0.1 and serves this directory. No npm packages, internet connection, or external fonts are needed. Use the same browser and URL for the same saved progress. `--port 8081` selects another port.

The top of the page contains the **visual Korad KD3005D + AD3 BNC testing guide** at `/#visual-wiring`. Ten manual WaveForms steps show each wire, the actual PCB pad layout, and enlarged endpoints. Clock pairs and mux cases change the illustrated connections. All endpoint nets are checked against the PCB snapshot before diagrams are shown. Drawings use component-side orientation and include pin-1 markers and KiCad coordinates. They show pad/trace locations, not exact component housings or physical probe access.

The current fixture uses two BNC probes, a 10× on scope 1 and a 1× on scope 2 (WaveForms attenuation set per channel to match), DC coupling jumpers, W1 coax with 0 Ω adapter source impedance and a suitable board-end breakout, plus the remaining V+ flywire for +3.3 V. The Korad provides +5 V; the power board generates its negative rail from a 192 kHz pump input. The rev B digital board carries its own crystal Pierce oscillator, so W1 is only used for the power-board pump stimulus and the channel audio tone. The SDK scripts accept the same BNC fixture with `--probe 10,1` (scope 1 probe at 10×, scope 2 probe at 1×); the visual guide remains for manual WaveForms work. Do not mix fixtures within a run or run WaveForms alongside SDK tests.

Reference notes and troubleshooting remain below the visual guide. Link navigation opens the selected section, and printing temporarily expands the reference notes. Printing the visual guide captures the currently selected wiring step, not all ten steps. The guide is read-only and never enables instrument outputs or records a hardware PASS.

The guide provides separate checklists for all four physical boards, component sorting, PCB coordinates and pin/net tables, a zoomable component-side/underside reference, top-joint tracking, wire links, inspection, and initial powered checks. Select a part in the list or map. Drag the map to pan. Save backup exports all progress and bench notes; Restore replaces current progress after confirmation. Print prints the current stage and selected reference, not the entire guide.

## Source of truth

`generated/boards.json` is extracted read-only from the three current PCB files; channel L artwork is used twice, with independent progress and J21 selection. The guide includes all 114 schematic component positions, plus the board-only wire anchors and mounting holes. Existing PCB/project files are not edited.

Regenerate after PCB edits using a Python installation with KiCad's `pcbnew` module and `kicad-cli` on PATH:

```sh
python assembly/generate.py
python assembly/verify.py
```

Regeneration also runs KiCad DRC and stores its full reports. The generated data carries source SHA-256 hashes and a timestamp. Match the physical fabricated revision yourself; regenerating does not reset progress. Export progress before changing revisions and do not treat previous checkmarks as validation of changed artwork.

Component-side joint detection uses same-net F.Cu tracks touching pad geometry. Current boards have bottom-only pours. Vias are accepted only where they sit on a same-net wire-link anchor (the rev B digital board has two stacked GND vias at WL7a); the verifier rejects any other via or top pour so the extractor cannot silently omit required joints. The schematic's through-hole pads assume plated holes; DRC alone cannot validate unplated assembly.

The channel has 20 top-side pads per copy, including U20.1, U22.4, U23.1, U23.2, U23.10 and U24.4. Power/digital default to bottom-only copper as specified in fabrication notes, with a construction selector on Prepare for actual double-sided boards. On the rev B digital board, 16 wire-link anchors form the MCLK, CLK6M, DIN, +3V3, GND and PI_DIN links, with component-side socket joints at U4.10, U6.1, U6.4 and U8.11. On power, connect WL1A to WL1B.

The map renders track centerlines and schematic pad markers; copper pours, physical body outlines and exact pad shapes are intentionally omitted. Use the real KiCad board for physical clearance and solder access. The current rev B digital DRC reports no clearance or connectivity violations; it lists two silkscreen overlaps (WL1b/WL5a reference text over J4/U4 outlines), five co-located-hole warnings from the two GND vias stacked on the WL7a pad (one physical drill), and footprint-library warnings for the local WireLink library. The guide preserves those reports and calls for inspection rather than declaring them passed.

Initial power instructions are a bench checklist, not a validated commissioning specification. The repository does not establish current-limit settings, acceptance tolerances, or a complete audio capture/calibration procedure.

## AD3 testing and resistor markings

**Board tests · AD3** adds per-board fixture plans and interactive Python SDK tests. See [bench/README.md](bench/README.md). Reports and raw captures remain local; the page reads report history without controlling hardware. Official installers are in [downloads](downloads/README.md).

Resistors show five-band colour diagrams and written colour names in both sorting and component details. The final brown band assumes ±1% tolerance; actual component markings and multimeter readings take precedence. The 4R75 resistor uses a silver multiplier band.

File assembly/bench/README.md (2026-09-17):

# Analog Discovery 3 board tests

Use **Board tests · AD3** in the assembly page for the connections, expected values, and test results for the selected physical board. Tests run interactively in a terminal; the webpage never enables a hardware output.

From the project root:

```sh
python assembly/bench/run.py devices
python assembly/bench/run.py power --probe 10,1
python assembly/bench/run.py digital --ad3-3v3 --probe 10,1
python assembly/bench/run.py stack --ad3-3v3 --probe 10,1
# optional per-channel debugging:
python assembly/bench/run.py left --ad3-3v3 --probe 10,1
python assembly/bench/run.py right --ad3-3v3 --probe 10,1
```

## Browser front end (recommended at the bench)

```sh
python assembly/bench/gui.py
```

Open **http://127.0.0.1:8090**. Pick the board, probes and 3.3 V source, optionally **continue from an earlier run** of the same board (its leading passed steps are carried into the new report and not repeated), then press Start. Each step shows its wiring table and one large button labelled with the confirmation it needs (READY, ON, OFF) plus a field for the Korad current. The page only relays your answers to the same `run.py` logic: it never enables an AD3 output on its own and never controls the bench supply. Abort stops at the next prompt and shuts down AD3 outputs; you still switch the Korad off. Reports and captures land in `results/` exactly as with the terminal route. The server listens on loopback only and runs one test at a time.

The terminal route accepts the same resume option (`--resume RUN_ID`) and now takes confirmation words case-insensitively; anything else, or `q`, still aborts.

`--probe` declares the probe attenuation per scope channel: `10,1` is the current BNC fixture (scope 1 with a 10× probe, scope 2 with a 1× probe), `10` means both at 10×, and omitting it means direct 1× flywires. Each physical probe switch must match its channel. The SDK scales the range and the returned samples, so every limit is still checked in probe-tip volts, and the report records the setting under `scope_inputs`. The DIO flywires and V+ remain available on the BNC adapter's pass-through header.

`--ad3-3v3` explicitly supplies **3.3 V from AD3 V+ to digital J2.3**. Omit it if a separate regulated bench output provides 3.3 V. **Never parallel these sources.** The bench supply always provides +5 V. Power alone does not use 3.3 V.

Python 3, NumPy, Digilent WaveForms Runtime/SDK and Adept Runtime are required. NumPy and Adept Runtime were already installed on this computer. Both official Linux installers have been saved in [downloads](../downloads/README.md). The normal Linux runner adds the installed Adept library directory to its own loader search path, without changing system configuration. WaveForms must be installed before the normal `python …` commands can find `libdwf.so`; `DWF_LIBRARY` can override the library path for diagnostics. Close the WaveForms GUI before running a hardware test. If multiple AD3 devices are connected, select `--serial SERIAL` using `devices` output.

The scripts refuse other instrument models. `devices` only enumerates devices, without opening one. Do not run a live board command until assembly, unpowered inspection and the wiring checklist are complete.

## Test order and scope

The minimum route before the Raspberry Pi is connected is `power` → `digital` → `stack`; each of those uses only the two scope probes on header pins. The `left`/`right` tests are the detailed per-channel screens (DIO harness, tone injection) for debugging a channel that misbehaves.

1. **Power standalone:** W1 loopback verifies the generated 192 kHz, 0–5 V pump clock before attaching it to J3.10. The power board receives bench +5 V at J3.2/GND at J3.1. The script checks +5 V, the generated negative rail, both references, ratiometric reference accuracy, and gross ripple. No digital board is attached to compete with W1.
2. **Digital standalone (rev B):** bench +5 V at J2.1, +3.3 V at J2.3, GND at J2.2. J1 shunt 1–2 selects the on-board 6.144 MHz Pierce oscillator (U9 74HCU04 + Y1); W1 never connects to the digital board. Two probe checks on header pins: PI_BCLK/PI_LRCLK at J2.4/J2.5 (frequency, duty and 3.3 V levels, which is what protects the Pi) and MCLK/PUMP at J4.8/J4.10 (5 V bus clocks). Together they prove the crystal, buffer and the whole divider chain. The raw oscillator output is at J1.1 if nothing shows up. The mux truth table is not screened separately; the stack test checks that interleaved data reaches the Pi header.
3. **Full stack (`stack`), one channel at a time:** power + digital + left channel (input shorted) → rails at power J3, then the left modulator output QL at digital J4.12 against MCLK; add the right channel → rails again, QR at J4.14; then references, PI_BCLK/PI_LRCLK and finally PI_DIN/PI_BCLK at the Pi header: PI_DIN must toggle continuously at 3.3 V logic. No Pi, +3.3 V still from AD3 V+. A pass here is the gate for connecting the Pi, which then supplies the 3.3 V (remove AD3 V+ first). Individual board results do not prove the full-stack power margin.
4. **Each channel (optional, `left`/`right`):** detailed screen with DIO inputs and a 1 kHz tone; use it when a channel misbehaves in the stack.
5. **Audio performance (`audio`):** the finished converter as it is used, stack powered from the Pi and the ripper running. Only W1 and AD3 GND go to the channel input J20; the ripper is asked to hold recording and returns its decimated 48 kHz audio for each step (`/api/audio`). The script calibrates full scale from a 0.5 Vpk tone, then records idle noise (unweighted and A-weighted, hum at 50/100/150/200 Hz, SNR), 1 kHz at −3…−60 dBFS (THD, THD+N, 2nd/3rd harmonic, AES17 dynamic range from the −60 dBFS tone), crosstalk, a third-octave response at −20 dBFS and CCIF 19+20 kHz and SMPTE 60 Hz + 7 kHz intermodulation. Figures are recorded, not judged. The run folder gets spectrum and response PNGs and a `summary.md` table for the write-up. The AD3's 14-bit generator bounds distortion and noise figures near −80 dB; anything better than that is the generator. `--channel right` measures the other input; `--pi` names the ripper. Run it once before and once after each hardware change to see what the change bought.

CLK6M is **6.144 MHz**; the net called MCLK is **1.536 MHz**. BCLK is 3.072 MHz, LRCLK is 48 kHz, and PUMP is 192 kHz. These values come from `clock_divider()` in `hardware/kicad/tools/vinyl_adc_layout.py`, with pin/net names checked against the PCB snapshot. The older README and design notes contain superseded architecture details.

`plans.json` is the shared website/terminal wiring plan. Its probe references and nets are validated against the extracted PCB data by the offline tests. `limits.json` contains the exact acceptance windows included in every report. Frequency targets and truth tables follow the schematic. Analog windows, ripple limits, duty/density windows and gain checks are **provisional engineering screening limits**, not a manufacturer specification or a measured production distribution. A charge pump is not a regulated −5 V source; the earlier SPICE work reports approximately −3.87 V under load, so the screening window is deliberately not centred tightly on −5.000 V.

## Connections and operation

- Common reference: AD3 GND, 1−, 2−, board GND, and bench negative. A negative-rail measurement uses **2+ on the negative rail**, never a ground clip on that rail. Confirm any earth-referenced bench connections before adding the USB-connected instrument.
- Scope inputs are either direct 1× AD3 flywires (default) or the BNC adapter with probes declared per channel by `--probe` (currently `10,1`); both DC coupled, with short grounds. The driver requests a 20 V probe-tip range, reads back the actual range, and measures actual sample rates. Never change probes or the `--probe` setting within a run.
- DIO pins are always inputs, with internal pulls and pattern outputs disabled. They observe 0–5 V logic only. AD3 outputs are 3.3 V logic, which is why they are not used to drive 5 V HC test inputs. AD3 W1 is used for the pump stimulus and audio sine; W2 and V− are disabled and unused.
- Bench starting point: +5.00 V, 0.10 A current limit for a standalone power/digital board; 0.20 A for power + digital + one channel. These are starting protection settings, not expected current consumption. Persistent CC, abnormal current or heating requires stopping and diagnosis, not automatically raising the limit. The script records your manual +5 V current readings.
- AD3 V+ (when selected) is 3.30 V. It is disabled between rewiring steps and at shutdown. Its default instrument protection is not a substitute for the bench +5 V current limit.
- Every wiring change requires an OFF → READY → ON sequence. Turn the bench supply off first, then let the script stop AD3 outputs, rewire, and follow the next power-on prompt. Do not change ICs, shunts or jumpers while powered.
- Ctrl+C and ordinary errors attempt W1/W2, digital-output and AD3-supply shutdown and close the device with SDK `OnClose=shutdown`. USB disconnect or process kill can prevent software cleanup; turn the bench supply off yourself. W1 disabled is not guaranteed high impedance, so disconnect it before using that node with another source.

The power pump test can run before digital assembly. Channel tests require the digital board to supply MCLK and PUMP, and the power board to supply the references/negative rail. No test energizes the Pi.

## Measurements and result files

Each run writes a new folder under `assembly/bench/results/` containing:

- `report.json`: PASS / FAIL / ERROR / ABORTED, exact measured values, limits, raw-capture filenames, device serial/SDK version, supply readings, source PCB hashes and limit-file hash.
- `.npz` files: scope voltages or 16-bit digital sample words plus actual sample rate, and the recovered density waveform for tone tests. Read with `numpy.load(path)` using keys `samples` and `sample_rate_hz`.

The page's **Refresh results** reads the generated index and shows history for that physical board. A report from a different PCB snapshot is marked stale; a simulation is never displayed as a board PASS. Tests stop at the first failed bound or invalid acquisition. Unrun steps are not assumed successful. Exit codes are 0 for a completed passing sequence, 1 for an out-of-window measurement, and 2 for setup/instrument errors or an aborted sequence.

Scope records use a single hardware buffer. Fast digital checks use up to 32768 samples at approximately 50 MS/s. The channel's longer record uses approximately 4 MS/s for 120 ms; it samples Q at falling MCLK edges and averages 256 modulator bits per recovered point. Actual rates are read back. High-speed captures separately check settled feedback relationships; the slower long record is not used for propagation-delay conclusions. Lost/corrupted record data, missing clocks, short captures and acquisition timeouts invalidate a test rather than creating a false PASS.

The two audio inputs are 0.10 and 0.25 Vpeak (0.20 and 0.50 Vpp), 1 kHz, zero offset. Keep RV20 fixed. The scope verifies the input amplitude; the recovered bit-density trace must fit 1 kHz and increase consistently with the input. This tests basic signal conversion and gross gain response, **not** a calibrated audio frequency response, decimator implementation, SNR, THD, jitter, crosstalk or 24-bit accuracy. The gross 150 mVpp ripple check is not a claim of measuring microvolt ripple.

## Offline verification

These commands never open an instrument:

```sh
python assembly/bench/run.py left --plan
python assembly/bench/run.py left --simulate
python assembly/bench/run.py digital --simulate --simulate-fault wrong-clock
python -m unittest discover -s assembly/bench -p 'test_*.py' -v
```

Simulated reports use `status: SIMULATED` and a separate `simulation_outcome`; they cannot qualify a board. Regression tests exercise healthy fixtures and deliberately inject a bad supply, wrong clock, reversed mux, stuck channel and missing tone. They also cover missing clocks, record loss, shutdown failures and output-range guards.

No AD3 was attached when these scripts were created; on 16 September 2026 the `devices` command enumerated the AD3 through the installed SDK on this computer. Real acquisition, wiring, analog acceptance limits and board behaviour still need the first physical run, which is the next step.

## Primary references

- [Digilent AD3 datasheet](https://files.digilent.com/datasheets/Analog-Discovery-3-Datasheet.pdf): scope, waveform output and 5 V tolerant digital-input electrical limits.
- [Digilent WaveForms download listing](https://digilent.com/reference/software/waveforms/waveforms-3/previous-versions): official installers.
- [Digilent SDK examples](https://github.com/Digilent/WaveForms-SDK-Getting-Started-PY): API use and instrument lifecycle.
- The downloaded WaveForms 3.25.1 package includes `usr/include/digilent/waveforms/dwf.h`, the SDK reference manual, and `usr/share/digilent/waveforms/samples/py/`. Function signatures and acquisition/record conventions were checked against that header and the official `AnalogIn_Record.py`, `DigitalIn_Record.py`, and `AnalogIO_AnalogDiscovery3_Power.py` examples.

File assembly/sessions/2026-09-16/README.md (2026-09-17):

# Bench plan — 16 September 2026 (rev B digital board, both channels populated)

> The full narrative of these sessions, including the faults, the wrong hypotheses and the software that came out of them, is in [`docs/bringup-log-2026-09.md`](../../../docs/bringup-log-2026-09.md).

This is a plan, not a record. No measurement has been taken on the rev B digital board or on either channel yet; the results section at the end stays empty until the runs happen. The 6 September readings were taken on the rev A digital board with an external W1 clock and do not transfer.

## What changed since 6 September

- The digital board is now **rev B**: U9 (74HCU04) + Y1 form a 6.144 MHz Pierce oscillator on the board itself. The X1 socket is gone. **J1 goes across pins 1–2** (crystal); J2.7 stays open. W1 is never connected to the digital board.
- Both channel boards have their seven 100 nF decoupling capacitors and can be powered.
- The SDK scripts now accept the BNC fixture: add `--probe 10,1` for the current probes (scope 1 at 10×, scope 2 at 1×). The DIO flywires and V+ still come off the adapter's pass-through header.
- The PCB snapshot behind the guide and the scripts was regenerated for the current boards (`python assembly/verify.py` passes), so reports will not be marked stale.

## Fixture that stays the same

Korad KD3005D at +5.00 V. AD3 with BNC adapter: both coupling jumpers DC, W1 jumper 0 Ω, scope 1 probe at 10× and scope 2 probe at 1×, declared to the scripts as `--probe 10,1`. AD3 GND, both probe clips and Korad black all on board GND; never a clip on the −5 V rail. AD3 V+ at 3.30 V is the only +3.3 V source (`--ad3-3v3`). Every wiring change: Korad off → script stops AD3 outputs → rewire → script prompts the power-on.

Close WaveForms before any script; only one application may own the AD3.

## Run order

Preferred: `python assembly/bench/gui.py` and open http://127.0.0.1:8090. Same tests as the commands below, with the wiring table and one big READY / ON / OFF button per prompt, and a "continue from an earlier run" option that carries passed steps instead of repeating them. The terminal commands remain equivalent.

Type READY / ON / OFF only after doing what the prompt says. Each run writes `assembly/bench/results/<id>/report.json` plus raw captures; the assembly page's **Board tests · AD3 → Refresh results** shows them.

### 1. Power board again, this time with a saved report

```sh
python assembly/bench/run.py power --probe 10,1
```

Standalone power board. W1 → J3.10 (192 kHz, 0–5 V, the script sets it), Korad red → J3.2, black → J3.1. Limit 0.10 A. The script checks the W1 stimulus with nothing attached first, then +5 V, the negative rail, both references and gross ripple. This replaces the "approximately −4.3 V / references work" notes from 6 September with exact numbers.

### 2. Rev B digital board standalone (two probe checks)

```sh
python assembly/bench/run.py digital --ad3-3v3 --probe 10,1
```

Digital only: Korad red → J2.1, black → J2.2, V+ → J2.3, J1 1–2. Limit 0.10 A. After the rails step, two probe moves on header pins, no DIO wires, no ties: scope 1 → J2.4 PI_BCLK with scope 2 → J2.5 PI_LRCLK (3.3 V logic, 3.072 MHz / 48 kHz), then scope 1 → J4.8 MCLK with scope 2 → J4.10 PUMP (5 V logic, 1.536 MHz / 192 kHz). If nothing runs, probe J1.1 (raw Pierce output, 6.144 MHz) and U4.10.

### 3. Full stack without the Pi

```sh
python assembly/bench/run.py stack --ad3-3v3 --probe 10,1
```

One channel at a time. Power + digital + LEFT channel (J21 = 1–2, input J20 shorted), V+ → J2.3, W1 off, limit 0.20 A: rails at power J3.2 / J3.16, then QL at digital J4.12 with MCLK at J4.8 (must toggle, 35–65 % density, 5 V logic). Add the RIGHT channel (J21 = 2–3, input shorted), limit 0.30 A: rails again, QR at J4.14. Then references (J3.4 / J3.6), PI_BCLK / PI_LRCLK (J2.4 / J2.5) and PI_DIN / PI_BCLK (J2.6 / J2.4): PI_DIN must toggle at 3.3 V logic.

### 4. Connect the Raspberry Pi

Power off. Remove AD3 V+ and all probes. Pi I²S header → J2 pin for pin; the Pi supplies +3.3 V from then on. Korad on first, then boot the Pi and capture. The per-channel `left` / `right` scripts stay available for debugging a channel.

## What to record for each run

Korad current at each ON prompt (the script asks), the report id, and anything the script did not measure: heating, CC events, wrong-looking waveforms. Screenshots only if you go the manual WaveForms route.

## Results (evening session, SDK reports in `assembly/bench/results/`)

**Power board — PASS** (`20260916T193608Z-power-95a4ffad`, pump-check and rails carried from the 21:16 run):

| Measurement | Value | Window |
|---|---|---|
| W1 pump stimulus | 192.00 kHz, duty 0.497, 0.014 / 4.92 V | 188–196 kHz, 35–65 %, ≤0.45 / 4.0–5.3 V |
| +5 V | 4.901 V, 28 mVpp | 4.75–5.25 V, ≤150 mVpp |
| Negative rail | −4.425 V, 20 mVpp | −5.25…−3.50 V |
| Korad current, power board alone | 0 mA shown (below display resolution) | |

References passed in the same run; exact values are in the report.

**Digital board — rails PASS, clocks FAIL** (`20260916T193845Z` failed because the V+ wire was not on J2.3; `20260916T200514Z` rails PASS: +5 V 4.888 V, +3.3 V 3.318 V, 32 mA; `20260916T201434Z` clocks):

| Pin | Expected | Measured |
|---|---|---|
| J2.4 PI_BCLK | 3.072 MHz | stuck at 3.25 V |
| J2.5 PI_LRCLK | 48 kHz | 500.9 kHz, later 491 kHz (drifting) |
| J4.8 MCLK | 1.536 MHz | 15.90 MHz |
| J4.10 PUMP | 192 kHz | 1.987 MHz |

Every divider output was 10.35× too fast and drifting, so the Pierce stage was free-running at about 63.6 MHz instead of locking to the crystal. **Cause: one leg of Y1 was not soldered**, leaving the inverter with only its 1 M feedback path. After resoldering it, three consecutive captures on the bus header gave MCLK 1536.30 kHz (duty 0.51) and PUMP 192.04 kHz (duty 0.50), stable to the last digit and within the AD3's own timebase tolerance. The divider, the 74HCT132 buffer, the 74HC4049 shifter and the rails were healthy throughout; the stuck PI_BCLK was just the 4049 unable to pass a 31 MHz BCLK at 3.3 V.

Note for later: U9 is a buffered **74HC04N** (marking D6683PS), not the unbuffered 74HCU04 the design specifies. It locks to the crystal now that the crystal is connected, but a buffered gate in a Pierce is marginal (design-notes §5), so the HCU04 stays on the order list and should replace it when it arrives.

**Digital board — PASS** (`20260916T203340Z-digital-897c4fcc`, rails carried from the 22:05 run):

| Step | Measurement | Value |
|---|---|---|
| pi-clocks | PI_BCLK frequency | 3.073e+06 Hz |
| pi-clocks | PI_BCLK LOW | -0.031 V |
| pi-clocks | PI_BCLK HIGH | 3.365 V |
| pi-clocks | PI_LRCLK frequency | 4.801e+04 Hz |
| pi-clocks | PI_LRCLK LOW | -0.006472 V |
| pi-clocks | PI_LRCLK HIGH | 3.345 V |
| bus-clocks | MCLK frequency | 1.536e+06 Hz |
| bus-clocks | MCLK LOW | -0.07402 V |
| bus-clocks | MCLK HIGH | 5.009 V |
| bus-clocks | PUMP frequency | 1.92e+05 Hz |
| bus-clocks | PUMP LOW | -0.01012 V |
| bus-clocks | PUMP HIGH | 5.045 V |

Both probe checks passed at the first attempt after the crystal repair; PI-side highs are 3.3 V logic, bus clocks 5 V logic.

**Stack, one channel at a time** (`20260916T215925Z-stack-1fd8c0ff`, rails-left carried from the 22:43 run):

| Step | Result |
|---|---|
| rails, left only | +5 V 4.867 V, negative rail −4.036 V, 67 mA |
| QL (left output) | 1.5363 MHz MCLK, QL toggling, density 0.497, 0–5 V |
| rails, both channels | +5 V 4.867 V, negative rail −3.788 V, 83 mA |
| QR (right output) | toggling, density 0.532, 0–5 V |
| references | VREF_P +2.466 V PASS, **VREF_N −1.767 V FAIL** (window −2.65…−2.35 V) |

Two bench faults on the way: the left board first pulled MCLK's low to 2.06 V and left QL floating (cured by reseating the board and the U23 socket; keep an eye on U23's ground pin), and the right board's J21 shunt had to be on pins 1–2, the pair farthest from the bus, not the pair nearest it.

The VREF_N failure is a design margin, not a build fault: with both channels loading the charge pump the rail is −3.79 V and the TL072 reference inverter U2B cannot swing below about −1.8 V. **Fix: swap power-board U2 for an LM358** (same pinout; see design-notes §10b′), then rerun `stack` from the references step.

**Pi-side data, manual AD3 capture after the failed step** (full stack, both inputs shorted, AD3 V+ on J2.3): PI_BCLK 3.0729 MHz. PI_DIN toggles 0–3.3 V; its transitions sit 10 ns after the BCLK falling edge and 150 ns before the rising edge the Pi samples on (bit period 326 ns). Sampled on rising edges: one-density 0.615 in both channel slots, longest run of equal bits 6. Healthy interleaved modulator stream with the expected offset from the skewed VREF_N; expect ≈0.50 after the U2 swap. A 1× probe on PI_BCLK reads only 0.75–2.6 V because it loads the 74HC4049; use the 10× probe for the 3 MHz Pi signals.

## 17 September: U2 swapped, full stack PASS

Power-board U2 changed from TL072 to LM358. Stack current 73–74 mA (83 mA with the TL072). `stack` rerun continuing from the 16 September reports; final report `20260917T152701Z-stack-94703bd8`, **PASS** on all seven steps:

| Step | Result |
|---|---|
| references | VREF_P +2.467 V, **VREF_N −2.430 V** (was −1.767 V), ratio error 0.1 %, ripple 34 mVpp |
| pi-clocks | PI_BCLK 3.0727 MHz, PI_LRCLK 48.011 kHz, 3.3 V logic |
| pi-data | PI_DIN 521 edges in the record, one-density **0.516** (was 0.615 with the skewed reference), 3.3 V logic |

One intermediate failure (`20260917T152142Z`) was the probes one pin low on J2: scope 1 read LRCLK's 48.01 kHz and scope 2 the data stream's ≈0.79 MHz edge rate. The boards are now cleared for the Raspberry Pi: AD3 V+ off J2.3 first, the Pi supplies the 3.3 V from then on.

## 17 September evening: first Raspberry Pi capture

Pi 4B, Pi OS Trixie (kernel 6.18), first booted from a USB stick, then cloned to the SD card with rpi-clone; reachable as `vinyladc.local`. The `vinyl-adc` overlay registers the capture card and `vinyl-adc-consumer.service` puts the I²S block in clock-consumer mode at boot (measured: GPIO18/19 are *outputs* until a capture device is first opened, so the Pi boots first and the ADC's +5 V comes on afterwards). Wiring per `pi/README.md`, J2.1 still on the Korad, J2.7 open, both inputs shorted.

10 s capture, `arecord` S32_LE stereo 48 kHz → exactly 3 840 000 bytes, so BCLK/LRCLK are locked. `pi/analyze_bitstream.py` on the raw bits:

| | Left | Right |
|---|---|---|
| one-density | 0.4959 | 0.4982 |
| in-band floor at 1 / 5 / 20 kHz | −118 / −118 / −117 dBFS/Hz | −123 / −104 / −100 dBFS/Hz |
| noise shaping 30→80 kHz | +68 dB/decade | **+13 dB/decade** |
| 20 Hz–20 kHz noise | **−74.3 dBFS** | −41.4 dBFS |
| strongest in-band line | 12.59 kHz, −85 dBFS | **5.51 kHz, −46 dBFS** |

Left is a healthy third-order loop and lands on the design's simulated figure (design-notes: 70.0 dB with real parts; measured ≈71 dB below a full-scale sine). Both idle tones sit at |DC| × 1.536 MHz as theory says. **The right channel shapes like a first-order loop**: one or two of its integrators are not in the loop (stuck at a rail, an open component-side joint such as U20.1 or U22.4, or a wrong value). Next: scope the three integrator outputs on the right board, U20 pin 1, U20 pin 7 and U22 pin 1, and compare with the left board.

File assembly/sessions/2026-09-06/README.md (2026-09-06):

# Bench handoff — 6 September 2026

Manual WaveForms with AD3 BNC adapter, two scope probes and W1 coax. This is a conversation/screenshot record, not an automated SDK report.

## Resume tomorrow

Mux 1/0 — Pi data (3.3 V)

With Korad, W1 and V+ off and rails discharged, use the complete visual fixture. Change QL from GND to +5 V; QR stays at GND. Scope 1 stays on MCLK (J4.8), Scope 2 on PI_DIN (J2.6). Expected: PI_DIN follows MCLK at approximately 1.536 MHz, with 3.3 V output levels.

Korad POWER off → stop W1 → disable AD3 V+ → verify rails have discharged. Shutdown was requested, not remotely verified.

## Power board: initial negative-rail failure

**Corrected setup** — Screenshot, before correction

- +5 V average: **+4.8988 V**
- Negative rail average: **−1.84680 V**
- W1 settings: **192 kHz; 2.5 V amplitude; offset mistakenly 50 mV**

The initial W1 request was −2.45 to +2.55 V instead of 0–5 V. The user also found the BNC W1 jumper at 50 ohms. The offset was corrected to +2.5 V and the jumper fitted at 0 ohms before repeating. This screenshot is not a passing result.

[Measurement screenshot](power-before-clock-fix.png)

## Power board: corrected supply readings

**Within range · user reported** — User reported; no corrected screenshot or raw capture supplied

- +5 V: **Approximately +5 V**
- Generated negative rail: **Approximately −4.3 V**

Both reported values fall within the provisional unloaded rail windows. This does not establish ripple, current consumption or full-stereo load capacity.

## Power board: positive and negative references

**Works · user reported** — User confirmation only

- Exact reference voltages: **Not recorded**

After moving probe tips to J3.4 and J3.6, the user reported that the reference test works. Do not replace this with invented ±2.500 V measurements. Re-record exact values when convenient.

## External clock and 3.3 V precheck · visual step 5

**Initial screen acceptable** — Screenshot; no PCB connected per procedure

- C1 frequency: **6.1351 MHz**
- C1 average / peak-to-peak: **1.6375 V / 2.7911 Vpp**
- C2 average: **+3.2538 V**
- W1 request: **6.144 MHz; amplitude 1.65 V; offset +1.65 V; 50% symmetry**

The displayed clock is rounded but crosses the HCT input thresholds visually. Exact min/max were not recorded in this screenshot; no precision jitter or duty-cycle result is claimed.

[Measurement screenshot](external-clock-precheck.png)

## Digital-board supplies · visual step 6

**Voltage means within range** — Screenshot

- C1 +5 V average: **+4.9197 V**
- C2 +3.3 V average: **+3.2538 V**
- Displayed C1 peak-to-peak: **19.117 mV; not a qualified ripple test**

The display was at 1 ns/div. The screenshot establishes the reported mean voltages, not the specified long-record ripple screen. Korad current was not recorded.

[Measurement screenshot](digital-rails.png)

## CLK6M / MCLK · visual step 7, first pair

**Frequency ratio good · level pending** — Latest screenshot; supersedes the earlier coarse view

- C1 CLK6M frequency: **6.1228 MHz**
- C1 minimum / maximum: **0.51370 V / 4.6717 V**
- C2 MCLK frequency: **1.5310 MHz**
- C2 minimum / maximum: **0.22317 V / 4.4919 V**

Frequency readings are within ±2% and show divide-by-four operation. C1 minimum exceeds the provisional 0.45 V LOW screen. That concern was deliberately left unresolved when moving on. Recheck probe attenuation, compensation, ground connection and the waveform before declaring this pair fully passed. Duty cycle and delay were not measured.

[Measurement screenshot](clock-divider.png)

## Mux QL/QR = 0/0, Pi data · visual step 8

**Expected LOW observed** — Screenshot plus user confirmation of 0/0 and Pi data selection

- C1 MCLK frequency: **1.5350 MHz**
- C1 minimum / maximum: **0.37988 V / 4.4678 V**
- C2 PI_DIN average: **31.940 mV**
- C2 minimum / maximum: **−31.353 mV / 96.072 mV**

This is the mux 0/0 Pi-output test, not BCLK/PI_BCLK. Its near-zero output is expected. It is only a functional check of this static LOW case, not a pass for all mux cases or the complete digital board.

[Measurement screenshot](mux-00-pi.png)

## Remaining work

- Resume mux 1/0 with Pi data selected, then 0/1 and 1/1. Test all four cases on raw DIN too.
- Return to visual step 7: BCLK/Pi BCLK, LRCLK/Pi LRCLK, and clock input/PUMP have not been checked.
- Resolve CLK6M LOW minimum of 0.51370 V and check duty cycles, output levels and clock-path polarity/delay.
- Record exact reference voltages, Korad current and meaningful long-record ripple measurements.
- Power + digital combined fixture has not been tested; do it after the standalone checks.
- Both channels still need seven 100 nF decoupling capacitors each. X1 is still missing. No channel, full-stack or audio-performance test has passed.

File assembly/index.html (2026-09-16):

◉ VINYL ADC ASSEMBLY BENCH

Save backupRestorePrint

START HERE · KORAD KD3005D + ANALOG DISCOVERY 3

# One wire at a time.

Use this visual guide with WaveForms, your BNC adapter, two probes and the W1 coax. Select a wire, match the board orientation, then use the enlarged pad view to connect it.

Current route: manual WaveFormsKorad = +5 V onlyChannels stay disconnected

Loading today’s bench handoff…

Set up first: BNC jumpers DC · probes 10× · W1 output 0 Ω

1Scope 1 BNCProbe 1 → tip + ground clip

2Scope 2 BNCProbe 2 → tip + ground clip

W1Wavegen W1 BNCCoax → centre signal + shield GND

V+Remaining red V+ wireDigital board’s +3.3 V only

Find the adapter’s printed connector labels; this overview does not depict its physical port order. Set both scope coupling jumpers to DC on the adapter—the default may be AC. Set the W1 output-impedance jumper to 0 Ω; do not add a 50 Ω terminator. Set each WaveForms scope channel’s attenuation to match its physical probe: currently CH1 = 10×, CH2 = 1×. A reading wrong by 10× on one channel means that channel’s probe switch and software attenuation disagree. All voltages below are the corrected values at the probe tip. Compensate the probes in the first visual step.

Probe ground clips and BNC shields are common ground. A negative rail is measured with the tip, never the ground clip. The BNC adapter makes the scope inputs single-ended. Leave unused scope flywires, W2, V− and DIO outputs disconnected/off.

Coax board end: use a BNC-to-clips or BNC-to-terminal breakout. The centre conductor is W1 signal; the outer shield is GND. If your cable has a BNC connector at both ends, it cannot attach directly to PCB header pins without a suitable breakout. Do not push a bare BNC centre pin onto a PCB pad.

Before the board steps, complete the unpowered assembly inspection. Check pin 1 and component positions in KiCad against your actual board; the illustrations use the current PCB files. Use grabbers on component leads or properly soldered insulated test tails for crowded IC pads. Do not balance loose probe tips across neighbouring pins.

Reference: Digilent BNC adapter setup (https://files.digilent.com/manuals/WaveForms/3.24.4/startadbnc.html) and scope probe attenuation (https://files.digilent.com/manuals/WaveForms/3.25.1/scope.html). The graphical route is manual only: the existing SDK assumes direct 1× flywire inputs and must not be used with these 10× probes without a driver change.

Loading your PCB wiring diagrams…

Power measurements — limits for the graphical BNC fixture

Keep the wiring shown in the selected visual step. With each probe switch and its WaveForms channel attenuation in agreement (CH1 10×, CH2 1×), displayed voltages refer to the probe tip. Use DC coupling jumpers. Ground clips stay on GND.

Measurement | Initial screening range
+5 V | 4.75–5.25 V
Generated negative rail | −5.25 to −3.50 V
VREF_P / VREF_N | +2.35…+2.65 V / −2.65…−2.35 V
Reference tracking | Within 3% of ±half the measured +5 V
Gross ripple | ≤150 mVpp; capture at least 8 ms at ≥1 MS/s, with the complete DC rail visible

These are provisional fault screens, not a measurement of microvolt noise. Record current and voltages. The negative supply is generated by the charge pump, not regulated to precisely −5 V. If it is missing, verify the pump clock and diode/capacitor polarity. Positive voltage on the negative rail, persistent CC or heating: turn off and inspect. No channel load is permitted until decoupling is fitted.

Digital measurements — limits for the graphical BNC fixture

Keep the visual fixture: J1 1–2 (on-board crystal), nothing on J2.7, W1 disconnected, each probe’s software scaling matching its switch (CH1 10×, CH2 1×), DC coupling. Power off for every clock-pair or mux-case change.

Measurement | Initial screening range
Supplies | +5 V: 4.75–5.25 V; +3.3 V: 3.15–3.45 V
5 V logic | Low −0.3…0.45 V; high 4.0…5.3 V
Pi-facing 3.3 V logic | Low −0.3…0.45 V; high 2.7…3.6 V
Clocks | ±2% of the selected nominal frequency, 35–65% duty cycle
Divider relationships | BCLK = CLK6M ÷2; MCLK = ÷4; PUMP = ÷32; LRCLK = ÷128

MCLK low selects QR; high selects QL. Test QL/QR = 0/0, 1/0, 0/1 and 1/1 for both raw DIN and PI_DIN. Ignore switching edges when comparing settled levels. All channel boards remain disconnected during the rail-tie tests. Pi clocks should retain the raw clock polarity, with a short propagation delay; 50 MS/s gives 20 ns per sample, not precision jitter measurement.

Reference notes, limits and troubleshooting — older flywire fixtures

With the rev B digital board (on-board crystal) the SDK scripts are the primary route again: run them with --probe 10,1 for the BNC adapter (CH1 10× probe, CH2 1× probe), or without it for direct 1× flywires. References to scope 1−/2− mean ground clips in the BNC setup. Do not switch fixtures or the --probe setting halfway through a test.

1 · Where does −5 V come from?

The KD3005D has one adjustable output. At 5.00 V, the red terminal is 5 V above the black terminal. It cannot provide independent +5 V and −5 V rails around the same ground simultaneously. The green terminal is protective earth, not a third supply output; leave it unused for this fixture and do not alter any existing earth bonds.

Your power board uses U1 (74HC244), C4, D1/D2, C5/C6 and R1 as an inverting charge pump and filter. With +5 V and a 192 kHz, 0–5 V input at PUMP, it generates a negative voltage at power J3 pin 16. The net is called “−5V”, but it is not regulated to exactly −5.000 V. Its voltage depends on load and losses. No pump clock means no useful negative supply.

1. Disconnect the Korad leads from every PCB. Power the supply on and set 5.00 V and a 0.100 A / 100 mA current limit using its voltage/current adjustment controls. Check the displayed setpoints; the current setting is a limit, not a current forced into the board.
2. Switch the Korad POWER off before attaching leads. On the KD3005D, do not assume a separate output-enable button exists. Whenever this guide says “bench off”, use POWER off if that is your available control. Let the output discharge and verify near 0 V before handling the board.
3. For the standalone power test, red goes to power J3.2 (+5V); black goes to power J3.1 (GND). AD3 GND and both scope minus leads join this same GND.
4. When instructed to power on, watch the supply. Normal operation should settle in CV. Persistent CC, an OCP trip, unexpected current or heating means switch off and investigate. Do not raise the limit just to make a failed test continue.

Measure a negative rail with scope 2+ on the negative rail and 2− on GND. A multimeter uses red on the negative rail, black on GND and should display a minus sign. Never put AD3 GND on the negative rail.

100 mA is a provisional protection setting for a standalone power or digital board, not a measured consumption specification. Use 100 mA initially for the unloaded power + digital pair too. Current-limit trips require diagnosis.

2 · Unpowered inspection and finding pins on bare copper

1. Keep both channel boards unplugged. Remove all external power, USB power paths and signal sources from the boards. Use an insulated work surface.
2. Open the matching PCB in KiCad. Hover a pad to read its reference, pin number and net; match it against the PCB map below. “J3.2” means connector J3, pin 2, not the second pad from whichever side you are looking at. The underside view is mirrored. The power bus is J3; digital is J4; channels are J7.
3. Check IC notch/pin-1 orientation, solder bridges, copper whiskers and every required wire link. On bottom-only power copper, fit WL1A–WL1B. On the rev B digital board, fit every wire link in the assembly guide’s wire-links step (16 anchors across MCLK, CLK6M, DIN, +3V3, GND and PI_DIN) including the component-side socket joints at U4.10, U6.1, U6.4 and U8.11.
4. Power-board polarity: C5 and C6 positive leads go to GND; their negative leads face the negative supply nodes. C4 positive faces the U1 driver output. D1’s cathode band faces GND; D2’s cathode band faces the C4/D1 pump junction. Verify against KiCad, not package position alone.
5. With a multimeter, check continuity of intended links and GND connections, and check each supply against GND for an unintended short. Capacitors may cause a brief beep or a resistance that rises; a persistent near-zero reading requires investigation. Do not use resistance/continuity mode on a powered board.
6. Confirm digital U3 is 74HCT132 and U9 is the unbuffered 74HCU04, not a 74HC04. Check the Pierce parts around it: Y1 6.144 MHz, C16/C17 27 pF, R10 1 M, R11 2k2. Confirm the five 100 nF capacitors and that J1 is fitted across pins 1–2; nothing connects to J2.7.

All grounds on the 2×8 bus are odd-numbered pins. Even pins: 2 +5V · 4 VREF_P · 6 VREF_N · 8 MCLK · 10 PUMP · 12 QL · 14 QR · 16 −5V. Verify orientation in KiCad before making any connection.

3 · Power board alone — generate and measure the negative rail

Choose either the terminal script or manual WaveForms for this test. They cannot own the AD3 at the same time. Leave W2, V+, V− and digital pattern outputs off and disconnected.

### Option A: guided SDK test with saved captures

Close WaveForms. In a terminal, run:

cd /home/mads/Projects/vinyl-adc
python assembly/bench/run.py devices
python assembly/bench/run.py power

The script first checks W1 with no PCB attached, then prompts for the power-board wiring and two sets of rail measurements. Type READY, ON and OFF only after completing the requested action. It cannot switch your Korad off. Reports and raw captures appear under assembly/bench/results/; use “Board tests · AD3” below to refresh results. Multiple devices: add --serial YOUR_SERIAL.

### Option B: manual WaveForms test

1. Open WaveForms with no test script running. In Wavegen → W1, select Square, 192 kHz, 50% symmetry, amplitude 2.5 V, offset +2.5 V. That means 5 Vpp, 0–5 V, not ±5 V. Keep it stopped while wiring.
2. With the PCB disconnected, connect scope 1+ to W1, 1− to AD3 GND. Set DC coupling/direct 1× flywires, about 1 V/div and 2 µs/div; trigger on channel 1 rising at about 2.5 V. Run W1 and Scope. Confirm approximately 192 kHz, 0 V low and 5 V high, with no substantial overshoot. Stop W1.
3. Switch the Korad off, then connect the fixture in the table below. Scope 1 now measures +5 V; scope 2 measures the negative rail. Set both scope channels DC coupled, about 1 V/div, with offsets that show their respective rails. Use Auto trigger.
4. Turn the Korad on at 5.00 V / 100 mA. If it settles in CV, start W1 immediately. Do not leave the pump input floating while the board is powered. Wait about one second, then record +5 V, the negative rail and supply current. Stop if a rail is positive where it should be negative.
5. For ripple, capture at least 8 ms at ≥1 MS/s, with the DC rail visible. Use peak-to-peak measurements. The provisional screen is ≤150 mVpp; this detects large faults, not microvolt noise performance.
6. Turn the Korad off, stop W1, wait for discharge, and move only scope 1+ to J3.4 and scope 2+ to J3.6. Keep both minus leads on GND. Repeat the power-on sequence and measure the references.
7. Finish by switching the Korad off, stopping all AD3 outputs and checking that rails have discharged before disconnecting.

Standalone power fixture — power board J3
Lead | Connect to | Purpose
Korad red; scope 1+ | J3.2 · +5V | Only external board supply
Korad black; AD3 GND; scope 1− and 2− | J3.1 · GND | Common reference
AD3 W1 | J3.10 · PUMP | 192 kHz, 0–5 V
Scope 2+ | J3.16 · −5V | Generated negative rail, never an AD3 supply connection
Scope 1+ in reference step | J3.4 · VREF_P | Positive reference
Scope 2+ in reference step | J3.6 · VREF_N | Negative reference

Provisional power-board screening limits
Measurement | Accept for initial screening
+5 V | 4.75–5.25 V
Negative rail | −5.25 to −3.50 V; observe the minus sign
VREF_P | +2.35 to +2.65 V
VREF_N | −2.65 to −2.35 V
Reference accuracy | Each reference within 3% of ±½ the measured +5 V
Gross ripple | ≤150 mVpp on each rail/reference

Passing unloaded measurements does not establish the pump’s current capacity for both channels. That is checked later under the actual load.

4 · Digital board alone — rev B with the on-board crystal oscillator

The rev B digital board clocks itself. U9 (74HCU04) and Y1 form a 6.144 MHz Pierce oscillator whose output reaches J1 pin 1; the J1 shunt across pins 1–2 feeds it to the 74HCT132 buffer. W1 is not connected to the digital board for any test. Keep the power board, channels and Pi disconnected for the standalone test.

### Option A: guided SDK test with saved captures

Easiest at the bench: start the local browser front end with python assembly/bench/gui.py and open http://127.0.0.1:8090. It shows each step’s wiring, one big READY / ON / OFF button and the current field, and can continue an earlier aborted run without repeating its passed steps. Or, in a terminal, close WaveForms and run one of these, depending on the scope fixture:

cd /home/mads/Projects/vinyl-adc
python assembly/bench/run.py digital --ad3-3v3 --probe 10,1   # BNC adapter: CH1 10x probe, CH2 1x probe
python assembly/bench/run.py digital --ad3-3v3                # direct 1x scope flywires

The script prompts for the rails wiring and then two probe checks on header pins only: PI_BCLK/PI_LRCLK at J2.4/J2.5 (3.3 V levels and frequencies, the Pi-safety check) and MCLK/PUMP at J4.8/J4.10 (5 V bus clocks). No DIO harness and no QL/QR ties. Omit --ad3-3v3 only if a separate regulated +3.3 V supply feeds J2.3.

### Option B: manual WaveForms test

1. Open WaveForms with no test script running. In Wavegen → W1, select Square, 192 kHz, 50% symmetry, amplitude 2.5 V, offset +2.5 V. That means 5 Vpp, 0–5 V, not ±5 V. Keep it stopped while wiring.
2. With the PCB disconnected, connect scope 1+ to W1, 1− to AD3 GND. Set DC coupling/direct 1× flywires, about 1 V/div and 2 µs/div; trigger on channel 1 rising at about 2.5 V. Run W1 and Scope. Confirm approximately 192 kHz, 0 V low and 5 V high, with no substantial overshoot. Stop W1.
3. Switch the Korad off, then connect the fixture in the table below. Scope 1 now measures +5 V; scope 2 measures the negative rail. Set both scope channels DC coupled, about 1 V/div, with offsets that show their respective rails. Use Auto trigger.
4. Turn the Korad on at 5.00 V / 100 mA. If it settles in CV, start W1 immediately. Do not leave the pump input floating while the board is powered. Wait about one second, then record +5 V, the negative rail and supply current. Stop if a rail is positive where it should be negative.
5. For ripple, capture at least 8 ms at ≥1 MS/s, with the DC rail visible. Use peak-to-peak measurements. The provisional screen is ≤150 mVpp; this detects large faults, not microvolt noise performance.
6. Turn the Korad off, stop W1, wait for discharge, and move only scope 1+ to J3.4 and scope 2+ to J3.6. Keep both minus leads on GND. Repeat the power-on sequence and measure the references.
7. Finish by switching the Korad off, stopping all AD3 outputs and checking that rails have discharged before disconnecting.

Standalone power fixture — power board J3
Lead | Connect to | Purpose
Korad red; scope 1+ | J3.2 · +5V | Only external board supply
Korad black; AD3 GND; scope 1− and 2− | J3.1 · GND | Common reference
AD3 W1 | J3.10 · PUMP | 192 kHz, 0–5 V
Scope 2+ | J3.16 · −5V | Generated negative rail, never an AD3 supply connection
Scope 1+ in reference step | J3.4 · VREF_P | Positive reference
Scope 2+ in reference step | J3.6 · VREF_N | Negative reference

Provisional power-board screening limits
Measurement | Accept for initial screening
+5 V | 4.75–5.25 V
Negative rail | −5.25 to −3.50 V; observe the minus sign
VREF_P | +2.35 to +2.65 V
VREF_N | −2.65 to −2.35 V
Reference accuracy | Each reference within 3% of ±½ the measured +5 V
Gross ripple | ≤150 mVpp on each rail/reference

Passing unloaded measurements does not establish the pump’s current capacity for both channels. That is checked later under the actual load.

4 · Digital board alone — rev B with the on-board crystal oscillator

The rev B digital board clocks itself. U9 (74HCU04) and Y1 form a 6.144 MHz Pierce oscillator whose output reaches J1 pin 1; the J1 shunt across pins 1–2 feeds it to the 74HCT132 buffer. W1 is not connected to the digital board for any test. Keep the power board, channels and Pi disconnected for the standalone test.

### Option A: guided SDK test with saved captures

Easiest at the bench: start the local browser front end with python assembly/bench/gui.py and open http://127.0.0.1:8090. It shows each step’s wiring, one big READY / ON / OFF button and the current field, and can continue an earlier aborted run without repeating its passed steps. Or, in a terminal, close WaveForms and run one of these, depending on the scope fixture:

cd /home/mads/Projects/vinyl-adc
python assembly/bench/run.py digital --ad3-3v3 --probe 10,1   # BNC adapter: CH1 10x probe, CH2 1x probe
python assembly/bench/run.py digital --ad3-3v3                # direct 1x scope flywires

The script prompts for the rails wiring, the DIO clock wiring and the four QL/QR mux cases, and records frequencies, duty cycles, Pi-side levels, the non-inversion delay screen and the mux truth table. Omit --ad3-3v3 only if a separate regulated +3.3 V supply feeds J2.3. The DIO flywires stay available on the BNC adapter’s pass-through header.

### Option B: manual WaveForms test

1. With all power off, fit J1 across pins 1–2. Tie QL (J4.12) and QR (J4.14) to board GND to prevent floating mux inputs.
2. Before attaching the board, check AD3 V+ set to +3.30 V with the scope or multimeter; then disable it. V− remains off. The Korad supplies +5 V; AD3 V+ supplies the separate +3.3 V rail. Do not connect V+ to +5 V or to another 3.3 V supply.
3. Wire the table below. Make sure all Pattern Generator / Static I/O outputs are disabled; DIO pins are observation inputs only. Connect the scope to +5 V and +3.3 V for the first rail check.
4. Enable AD3 V+ at 3.30 V, then turn the Korad on at 5.00 V / 100 mA. Verify +5 V is 4.75–5.25 V and +3.3 V is 3.15–3.45 V. Record the +5 V current. Stop for persistent CC, heating or abnormal rails.
5. First clock check: scope 1+ on J1.1 (raw Pierce output) and scope 2+ on U4.10 (CLK6M after the buffer). Expect 6.144 MHz within ±0.01 % on both, 5 V logic. No oscillation, or oscillation far from 6.144 MHz, means the Pierce stage itself is wrong; do not continue to the divider until it runs.
6. For each new probe location: Korad off → V+ off → wait for discharge → rewire. Restart V+, then the Korad. Capture the clocks below with the Logic instrument at ≥50 MS/s, about 200 µs total. Use an automatic capture initially so a missing clock does not just look like a trigger timeout.

Standalone digital fixture — digital board J2
Lead | Connect to | Setting
Korad red | J2.1 · +5V | 5.00 V / 100 mA initial limit
Korad black; AD3 GND; scope 1− and 2− | J2.2 · GND | Common reference
AD3 V+ | J2.3 · +3V3 | +3.30 V; V− off
J1 shunt | J1.1 → J1.2 | On-board crystal selected; J2.7 (GPCLK0) left open

Minimum clock checks — two probe tips, header pins only
Check | Scope 1+ | Scope 2+ | Expected
Pi-side clocks | J2.4 · PI_BCLK | J2.5 · PI_LRCLK | 3.072 MHz and 48 kHz, 3.3 V logic (highs 2.7…3.6 V)
Bus clocks | J4.8 · MCLK | J4.10 · PUMP | 1.536 MHz and 192 kHz, 5 V logic
If nothing runs | J1.1 · Pierce output | U4.10 · CLK6M | 6.144 MHz on both; see troubleshooting

Screen frequencies within ±2% (the crystal itself should be within ±0.01 %) and duty cycle within 35–65%. Also check that divider outputs track the measured CLK6M by ÷2, ÷4, ÷32 and ÷128 respectively. Use the scope to check voltage: 5 V logic low −0.3…0.45 V, high 4.0…5.3 V; Pi-facing logic low −0.3…0.45 V, high 2.7…3.6 V. A logic analyzer alone cannot establish safe output voltage.

Compare BCLK to PI_BCLK and LRCLK to PI_LRCLK with both scope channels: the paths should be non-inverting, with small propagation delay. At 50 MS/s, each sample is 20 ns; this is a gross polarity/timing check, not a precision jitter measurement.

5 · Digital data paths — test all four left/right combinations

Keep the standalone digital fixture; the crystal keeps the board clocked. No channel boards may be attached while their Q bus inputs are tied to rails. Every tie change requires the full off/rewire/on sequence from step 4.

Keep DIO1 on MCLK. Add DIO6 and scope 1+ to U6.4 (DIN), DIO7 to J4.12 (QL), DIO8 to J4.14 (QR), and DIO9 plus scope 2+ to J2.6 (PI_DIN). Both scope minus leads remain at GND. Input 0 means tie to board GND; input 1 means tie to board +5 V. Do not drive these 5 V HC inputs from 3.3 V AD3 DIO outputs.

MCLK low selects QR; MCLK high selects QL
QL / QR ties | DIN and PI_DIN expected
0 / 0 | Constant low
1 / 0 | Follow MCLK
0 / 1 | Inverse of MCLK
1 / 1 | Constant high

Judge the centre of each MCLK half-cycle, after propagation delay. DIN is 5 V logic; PI_DIN must remain 3.3 V logic, using the voltage limits in step 4. Record actual QL/QR states as well as outputs. Save each capture with its case name. After finishing, power off and remove all four-case test ties before adding either channel.

6 · Power + digital — make the digital board drive the pump

1. Only continue after both standalone tests pass. Turn Korad and all AD3 outputs off and let the rails discharge. Remove the W1 wire from power J3.10. W1 is not used at all in this test; the digital board’s crystal-derived divider now drives PUMP.
2. Join the power J3 and digital J4 buses with the same numbered pins aligned, using the intended connectors. For a minimal flywire fixture, connect J4.1 to J3.1 (GND), J4.2 to J3.2 (+5V), and J4.10 to J3.10 (PUMP). Check continuity and absence of shorts while unpowered. No other bus wires are needed for this two-board pump test.
3. Use one Korad feed: red to digital J2.1, black to J2.2. Retain AD3 V+ to digital J2.3 at 3.30 V and J1 at 1–2; nothing on J2.7. Leave the absent QL/QR inputs tied low during this two-board-only test.
4. Probe PUMP at power J3.10 with DIO10 and the negative rail at J3.16 with scope 2+. Scope 1+ measures J3.2. Start V+, then the Korad. Confirm 192 kHz reaches the power board and repeat the step 3 rail measurements, then references after powering off to move probes.
5. Record supply current and voltages. This establishes that the digital divider can operate the pump. It does not prove loaded channel performance. Shut down the Korad and V+ before disconnecting.

There must be one driver on PUMP: AD3 W1 for the standalone power test, or the digital board for the combined test. Never connect both outputs to that net.

7 · Full stack, then the Raspberry Pi

Both channels are now fully populated, including their seven 100 nF decoupling capacitors. Before powering a channel, check all 20 required top-side pad connections on it against its assembly map; unplated holes do not join top and bottom copper automatically. Confirm J21: 1–2 on the left board, 2–3 on the right board.

The minimum before the Pi is the stack test, which adds the channel boards one at a time so a faulty one is caught alone: power + digital + left channel (input shorted) → rails at power J3 and the left modulator output QL at digital J4.12 against MCLK; add the right channel → rails again and QR at J4.14; then references, PI_BCLK/PI_LRCLK and PI_DIN/PI_BCLK at the Pi header. No Pi, +3.3 V still from AD3 V+. PI_DIN must toggle continuously at 3.3 V logic; a constant line means a stuck modulator, a wrong J21 or a dead bus line. Start the +5 V current limit at 0.30 A.

1. Power off, remove the AD3 V+ wire from J2.3 and every probe. Connect the Pi's I²S GPIO header to J2 with matching pin numbers; the Pi now supplies +3.3 V to J2.3 and shares GND. Never leave AD3 V+ connected once the Pi is attached.
2. Power the stack from the Korad first, then boot the Pi, and capture with the Pi's I²S receiver. Audio-quality measurements (SNR, THD, frequency response) happen there, not in these screens.
3. If one channel misbehaves, run the detailed per-channel test (left or right): it uses DIO inputs and a 1 kHz tone from W1 and needs the stack reduced to power + digital + that channel.

# Browser front end (same tests, big buttons, resume support):
python assembly/bench/gui.py      # then open http://127.0.0.1:8090
# Terminal route. --probe declares each scope channel's probe: 10,1 = CH1 10x probe, CH2 1x probe (current BNC fixture)
python assembly/bench/run.py power --probe 10,1
python assembly/bench/run.py digital --ad3-3v3 --probe 10,1
python assembly/bench/run.py stack --ad3-3v3 --probe 10,1
# optional per-channel debugging:
python assembly/bench/run.py left --ad3-3v3 --probe 10,1

Follow the full fixture instructions in the SDK test README and the per-board “Board tests · AD3” stage below. A simulated PASS does not qualify a physical board.

Troubleshooting and what to record

Observation | Next check, with power off before moving connections
Korad in CC; voltage collapses | Check shorts, IC orientation, reversed electrolytics, wrong bus alignment and a ground lead on −5V. Do not increase the current limit to bypass the symptom.
+5 V good, negative rail near 0 V | Verify 192 kHz at J3.10; then U1 supply and enables, WL1, pump capacitor/diode orientation and solder joints. No negative rail is expected with the clock stopped.
“−5V” is positive | Stop. Verify probe polarity and D1/D2 orientation against KiCad. Do not attach a channel.
Negative rail good, reference wrong | Check U2 orientation and supplies, reference resistor values and joints. Do not diagnose the negative reference until the negative rail is established.
No digital clocks | Scope J1.1 first. No 6.144 MHz there: check +5 V at U9.14, that U9 is a 74HCU04, the Y1/C16/C17/R10/R11 joints and that nothing loads J1.1. 6.144 MHz at J1.1 but nothing at U4.10: check the J1 shunt is across 1–2, U3 (74HCT132) and its links. Clock at U4.10 but no divider outputs: check U4.11 reset held low. A floating or wrong clock-select connection can look like a dead counter.
Oscillator runs far from 6.144 MHz (tens of MHz or a sub-harmonic) | U9 is probably a buffered 74HC04 instead of the unbuffered 74HCU04, or R11 is not 2k2; see design notes §5. Do not test the divider on a wrong clock.
All digital frequencies wrong by the same factor | Check the crystal marking and the measured J1.1 frequency. CLK6M is 6.144 MHz; the bus MCLK is 1.536 MHz.
5 V clocks good, Pi outputs missing | Check the separate +3.3 V rail, U8 and the required bottom-only-board wire links.
Mux wrong or erratic | Verify QL/QR are actually tied to the intended rails, U6 enable is low, MCLK reaches U6.1, and both channel boards are disconnected.
Clocks stop or rails sag when a script opens | Only one application owns the AD3; opening a script resets W1 and V+. With --ad3-3v3 the +3.3 V rail comes from V+ and is only enabled inside each powered step. The crystal clock itself needs only +5 V.
SDK cannot load or find AD3 | Close WaveForms, inspect python assembly/bench/run.py devices, and check the installer notes. Device enumeration alone does not exercise hardware outputs.

For each run record: board/revision, date, clock source and measured frequency, Korad current limit and measured current, rail means and ripple, clock frequencies/levels, mux case results and any heating or failed checks. Save WaveForms captures and the workspace separately; the assembly backup does not include WaveForms files. Do not mark skipped tests as passed.

Stop sequence: Korad off → W1 stop → AD3 V+ off → verify discharge. If software freezes or USB disconnects, turn the Korad off yourself; software cannot guarantee shutdown after a lost connection.

Guide checked against the current PCB snapshot (rev B digital board with the on-board Pierce oscillator) and existing provisional limits on 16 September 2026. No physical board measurements were made while updating it. References: KORAD KD-series manuals (https://www.koradtechnology.com/companyfile/4/), KD-series manufacturer manual, RND-branded copy (https://attachments.content4us.com/datasheets/rnd_320_KD3000_eng_man.PDF), AD3 electrical specifications (https://files.digilent.com/datasheets/Analog-Discovery-3-Datasheet.pdf), WaveForms Wavegen settings (https://files.digilent.com/manuals/WaveForms/3.24.3/wavegen.html), local screening limits and validated probe plans.

Assembly checklist & KiCad reference Back to testing guide ↑

FOUR BOARDS · ONE BUILD

BUILD SEQUENCE

Your progress stays in this browser.
Save a backup before clearing browser data.

Unfinished only Top-side connections

## PCB reference

Traces−+Fit board

Selected Top connection · square = pin 1
Coordinates in mm, KiCad absolute origin. Copper fills and exact pad shapes omitted; verify in KiCad.

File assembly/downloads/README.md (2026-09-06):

# Digilent downloads

Official Linux x86-64 packages are saved locally in this directory. Installer binaries are not included in Git or the public website; use the official download links below on another computer.

| Package | SHA-256 |
|---|---|
| WaveForms 3.25.1, application + runtime + SDK (`digilent.waveforms_3.25.1_amd64.deb`, local only) | `d2979aab726c9202a48a1c5d2b314531513171c0b62fa2f2a2edcd29202727d3` |
| Adept Runtime 2.30.1 (`digilent.adept.runtime_2.30.1_amd64.deb`, local only) | `e5e51d2640c2ff34ef3b436f3bdf37838120b15160d73dfbab82e90773b6b372` |

Both hashes match the package recipes already present in this computer's AUR cache. Adept Runtime 2.30.1 is already installed. The Adept `.deb` here was copied from its existing downloaded package. WaveForms was downloaded from Digilent using a browser user-agent because the server challenges curl's default user-agent.

This computer uses Arch/Omarchy. These are vendor `.deb` source packages, **not packages to install with apt on this machine**. Use an Arch package built from the existing `digilent.waveforms` recipe for system installation. The `waveforms-extracted/` folder is an inspection copy of the vendor package used to verify the SDK header/examples; extracting it alone is not a system installation.

Downloads and extracted files are excluded from git. Keep this directory locally or download again from the official sources:

- [WaveForms releases](https://digilent.com/reference/software/waveforms/waveforms-3/previous-versions)
- [Adept Runtime](https://digilent.com/reference/software/adept/start)

For a diagnostic SDK enumeration using the extracted library and installed Adept libraries (no outputs enabled):

```sh
LD_LIBRARY_PATH=/usr/lib/digilent/adept \
DWF_LIBRARY="$PWD/assembly/downloads/waveforms-extracted/usr/lib/libdwf.so.3.25.1" \
python assembly/bench/run.py devices
```

Full instrument use requires its firmware/configuration files to be installed as well as its library; use the system installation for real tests.

## Ready-to-install Arch package

The verified source was built into `arch-build/digilent.waveforms-3.25.1-1-x86_64.pkg.tar.zst` (local only) using the existing AUR recipe. All declared dependencies are present. System installation was attempted, but `sudo` requires your password; no WaveForms system installation was completed.

Run this in your own terminal from the project root:

```sh
sudo pacman -U /home/mads/Projects/vinyl-adc/assembly/downloads/arch-build/digilent.waveforms-3.25.1-1-x86_64.pkg.tar.zst
```

This computer's installed Adept libraries are under `/usr/lib/digilent/adept`, outside the current loader cache. The test runner adds that directory to its own library search path automatically on Linux. If the WaveForms GUI reports a missing `libdmgr.so.2`, launch it with:

```sh
LD_LIBRARY_PATH=/usr/lib/digilent/adept waveforms
```

After installation, connect the AD3 and run `python assembly/bench/run.py devices`. This should list its serial number without enabling outputs.

## Startup fix

WaveForms 3.25.1 is now installed. Its user launcher at `~/.local/share/applications/digilent.waveforms.desktop` sets `LD_LIBRARY_PATH=/usr/lib/digilent/adept` for both normal and safe-mode startup. This resolves six missing Adept libraries without changing system files. Safe-mode GUI startup was verified on this machine.

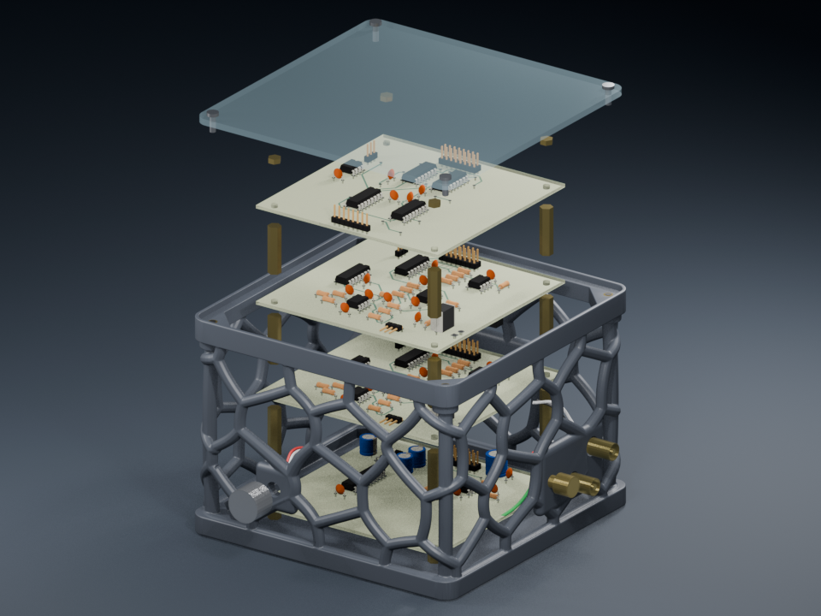
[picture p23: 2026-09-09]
media/showcase/assembly-poster.png

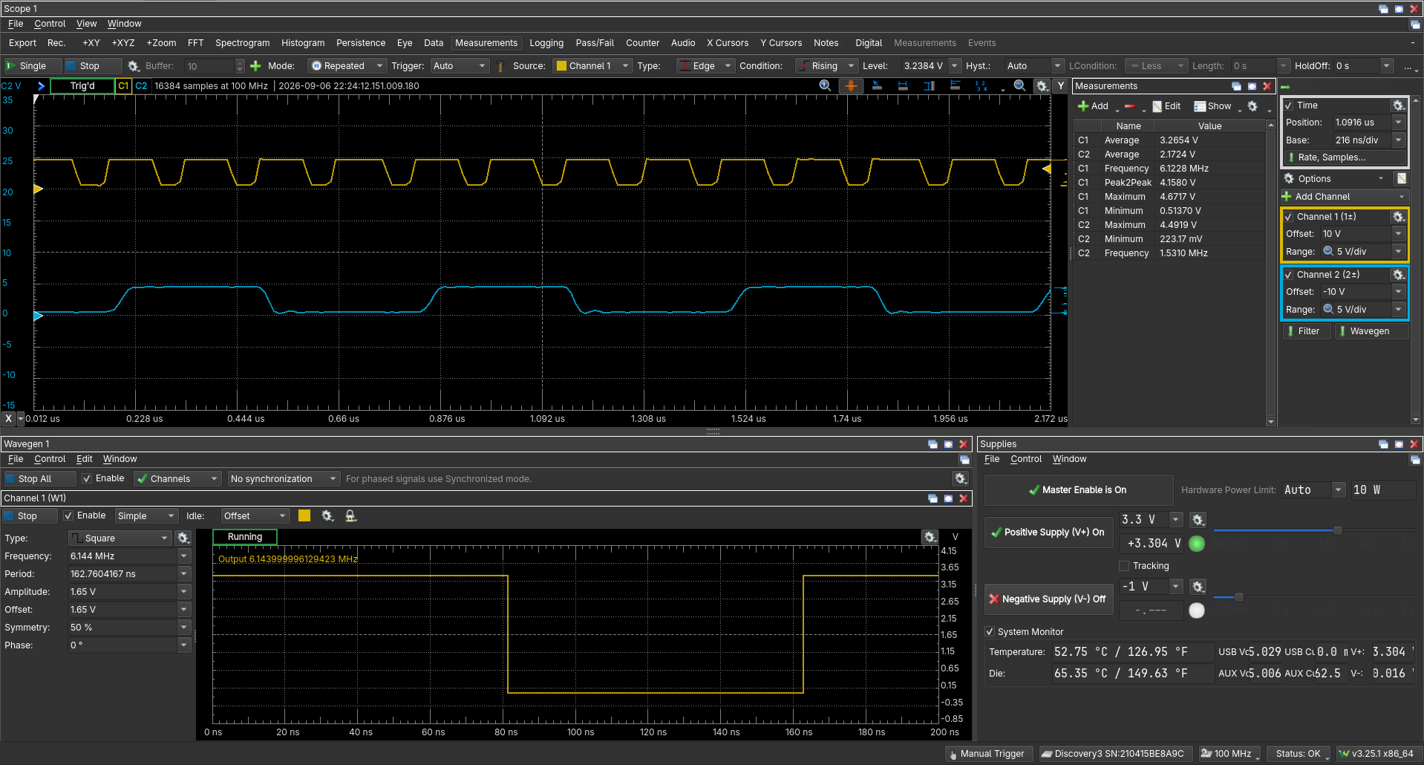
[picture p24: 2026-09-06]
assembly/sessions/2026-09-06/clock-divider.png

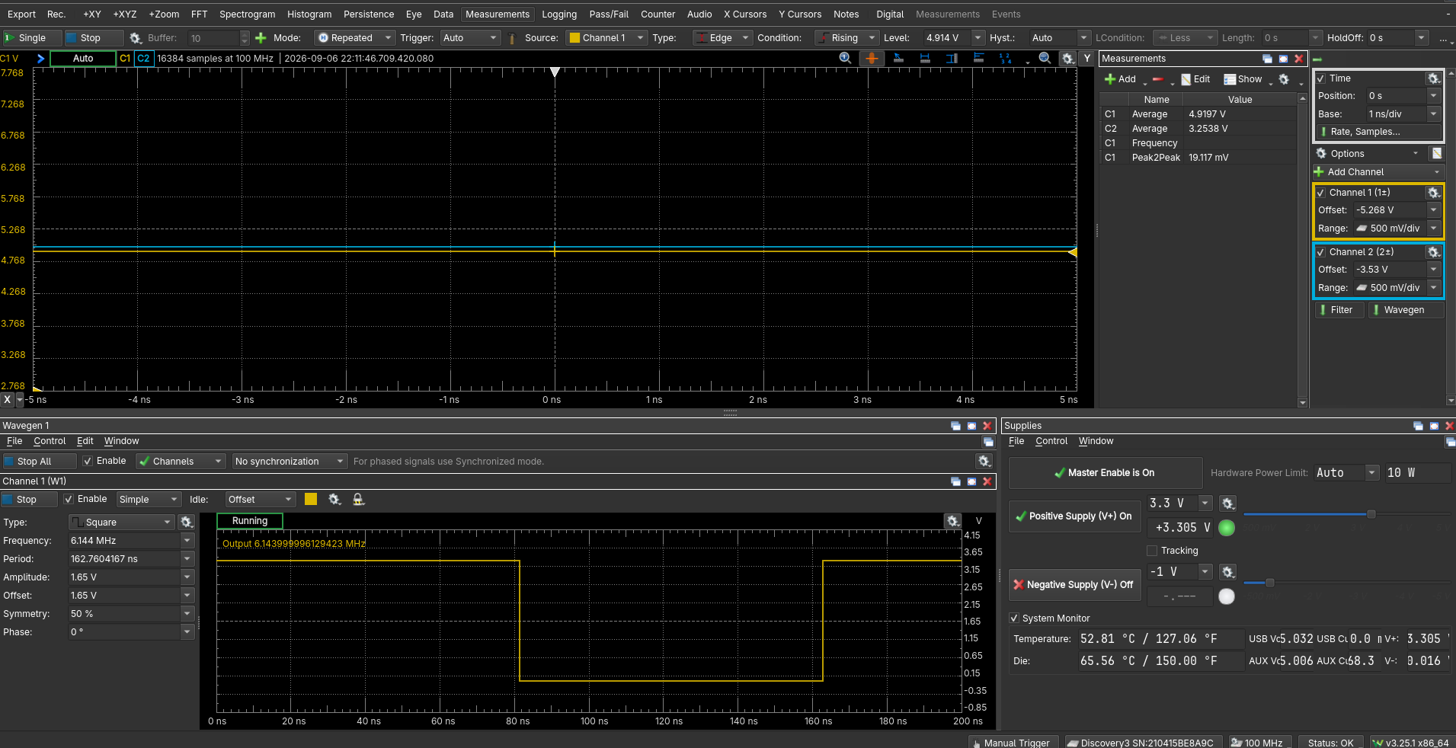
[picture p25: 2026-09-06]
assembly/sessions/2026-09-06/digital-rails.png

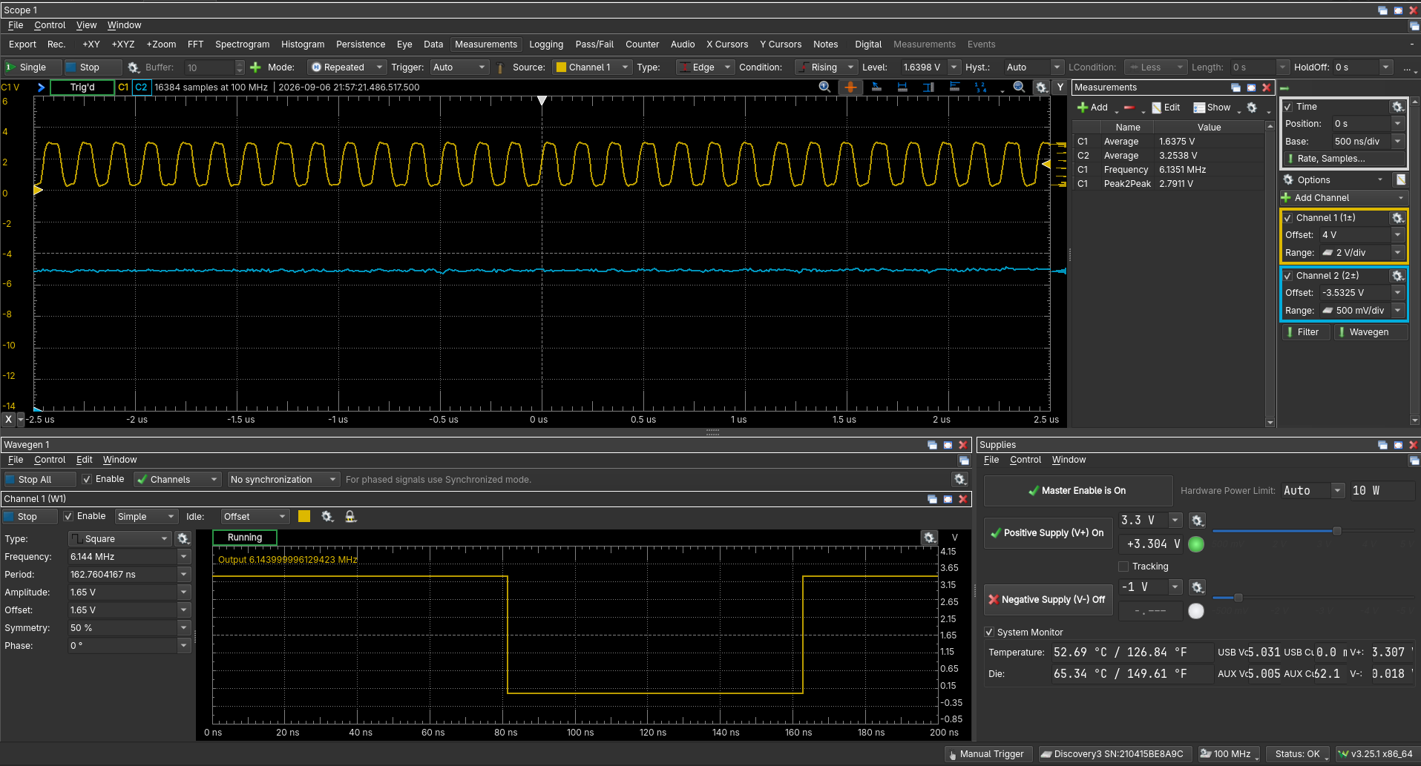
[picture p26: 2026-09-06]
assembly/sessions/2026-09-06/external-clock-precheck.png

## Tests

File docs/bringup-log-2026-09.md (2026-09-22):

# Vinyl ADC: bring-up log, 16–18 September 2026

From four freshly assembled boards to a Raspberry Pi that records a playing record, splits it into tagged FLAC tracks and hands the album to Jellyfin. This is the complete work log: every measurement, every fault with its symptoms and its real cause, the wrong hypotheses along the way, and the software that was written to get there.

Companion documents: the measured results per step are in [`assembly/sessions/2026-09-16/README.md`](../assembly/sessions/2026-09-16/README.md); the design rationale is in [`design-notes.md`](design-notes.md) (the reference-headroom finding from this bring-up is §10b′); the Pi setup is in [`pi/README.md`](../pi/README.md); the media-server side is in [`server/README.md`](../server/README.md). Raw bench reports and captures live in `assembly/bench/results/` (not in git).

## 1. Overview

### 1.1 Starting point

| Item | State on 16 September, 20:00 |
|---|---|
| Power board | Assembled. Tested loosely on 6 September: "about −4.3 V", references "work", no exact values recorded |
| Digital board | **New rev B**, just assembled: the unobtainable DIP-8 oscillator can is replaced by an on-board crystal Pierce oscillator (74HCU04 + 6.144 MHz HC-49 crystal). Never powered |
| Channel boards L/R | Assembled including the seven 100 nF decoupling capacitors that were missing on 6 September. Never powered |
| Bench tooling | Written for the rev A digital board with an external clock from the AD3; refused to run |
| Raspberry Pi | None set up. No capture or decimation software existed |

Instruments: Digilent Analog Discovery 3 (AD3) with the BNC adapter, one 10× probe on scope 1 and one 1× probe on scope 2, Korad KD3005D bench supply at 5.00 V, a multimeter.

### 1.2 Outcome

| Item | State on 18 September, 00:30 |
|---|---|
| Power, digital, full stack | Pass the AD3 screening (reports `20260916T193608Z-power`, `20260916T203340Z-digital`, `20260917T152701Z-stack`) |
| Left channel | Healthy third-order modulator. Idle noise **−79.6 dBFS** (20 Hz–20 kHz), about 77 dB below a full-scale sine. The design simulation predicted 70 dB |
| Right channel | Modulator loop unstable. Root cause located (the board's −5 V enters through one fragile component-side joint on the bus connector), permanent fix not yet applied |
| Raspberry Pi 4 | Captures the I²S stream as clock consumer, runs the ripper and dashboard as a boot service |
| First real recording | 30 s of a playing record through the left channel, −26 dBFS RMS |
| Jellyfin | Host-side puller installed and tested; albums land in `/srv/media/music/Vinyl/` |

### 1.3 Timeline

| When | What |
|---|---|
| 16 Sep 20:30–21:10 | Bench tooling brought up to the rev B board; hosted guide redeployed |
| 16 Sep 21:10–21:40 | Per-channel probe option, browser GUI for the bench tests, resume support |
| 16 Sep 21:36 | Power board PASS |
| 16 Sep 21:38–22:35 | Digital board: missing 3.3 V wire, then the oscillator running at 63.6 MHz, fixed by resoldering a crystal leg. PASS at 22:33 |
| 16 Sep 22:40–23:30 | Stack test: left board loads MCLK, J21 orientation, both channel outputs pass |
| 16 Sep 23:59 | References fail under full load: VREF_N −1.77 V. TL072 cannot swing that far on the loaded pump rail |
| 17 Sep 17:20 | U2 swapped to LM358: VREF_N −2.43 V. Full stack PASS at 17:27 |
| 17 Sep 17:30–20:15 | Pi: OS, SSH, overlay, the "I²S pins are outputs at boot" finding, migration from USB stick to SD card |
| 17 Sep 20:24 | First capture from the Pi. Left healthy, right first-order-like |
| 17 Sep 20:30–23:30 | Right channel: shorted op-amp output, limit cycle, open joint at R33, finally the single-joint −5 V feed |
| 17 Sep 23:00 | Live browser view of both modulator streams |
| 17 Sep 23:50 | Listening simulation through the modulator model |
| 18 Sep 00:05 | First real music recorded and declicked |
| 18 Sep 00:30 | Ripper, dashboard and Jellyfin delivery running |

## 2. Bench tooling for the rev B digital board

### 2.1 Why nothing ran

`assembly/bench/run.py` refuses to test against a stale PCB snapshot (`assembly/generated/boards.json` carries a SHA-256 per board). The rev B commit had changed all three PCB files, so every hash mismatched. Regenerating failed too:

| Check in `assembly/generate.py` / `verify.py` | Rev A assumption | Rev B reality | Change |
|---|---|---|---|
| No vias | 0 | 2, stacked, GND, on the WL7a wire-link pad | Vias accepted only where they sit on a same-net wire-link anchor |
| Digital part count | 13 | 18 (U9, Y1, R10, R11, C16, C17 added, X1 gone) | Updated; component positions 109 → 114 |
| Wire-link anchors | 18, paired as `WLnA`/`WLnB` | 16, lowercase `WLna`/`WLnb`, one (WL4b) with no drawn route | Pairing by name replaced by "each anchor net has at least two anchors" |
| Part kinds | no crystal | Y1 | `crystal` kind added, shown in the assembly app |

The assembly app's wire-link page paired anchors by the uppercase suffix, so it showed **no links at all** for rev B. It now derives links from the drawn top-side routes (`boards.json` → `runs`): anchors on a route are chained by nearest neighbour, component pads join the nearest anchor on their route, and an anchor with no route is paired with the nearest same-net endpoint and flagged "verify in KiCad". Result: 16 links.

The guide still described the rev A procedure (X1 empty, J1 on 2–3, W1 injecting 6.144 MHz at 0–3.3 V into J2.7). All of it was rewritten for the crystal: **J1 on 1–2, nothing on J2.7, W1 never connected to the digital board**, with a new first probe pair J1.1 (raw Pierce output) against U4.10 (buffered CLK6M).

### 2.2 Clock tree (for reference)

$$
f_{\mathrm{CLK6M}} = 6.144\ \text{MHz},\quad
f_{\mathrm{BCLK}} = \frac{f_{\mathrm{CLK6M}}}{2} = 3.072\ \text{MHz},\quad
f_{\mathrm{MCLK}} = \frac{f_{\mathrm{CLK6M}}}{4} = 1.536\ \text{MHz},\quad
f_{\mathrm{PUMP}} = \frac{f_{\mathrm{CLK6M}}}{32} = 192\ \text{kHz},\quad
f_{\mathrm{LRCLK}} = \frac{f_{\mathrm{CLK6M}}}{128} = 48\ \text{kHz}
$$

All from one 74HC4040 ripple counter, so their phase relationship is fixed. That matters later (§6.3, §7.2).

### 2.3 Probe attenuation per channel

The scripts assumed 1× flywires; the fixture is a 10× probe on scope 1 and a 1× probe on scope 2. `--probe` now takes one value per channel (`--probe 10,1`) and calls `FDwfAnalogInChannelAttenuationSet` per channel (`assembly/bench/dwf_device.py:AD3.scope`). Verified on the instrument by reading the range back after requesting a 20 V probe-tip range:

| Setting | Range read back | Meaning |
|---|---|---|
| 1× | 59.8 V | the AD3's ±25 V input range |
| 10× | 52.2 V | the ±2.5 V input range, scaled by 10 |

So the SDK scales both the range and the returned samples, and every limit is still checked in probe-tip volts.

### 2.4 Browser GUI and resume

A typed `ready` instead of `READY` aborted a run after two passed steps. Three changes followed:

- **Operator layer** (`assembly/bench/run.py`): all prompts go through an operator object. `TerminalOperator` accepts confirmation words case-insensitively; `gui.py:WebOperator` blocks the test thread until the browser answers.
- **Resume** (`--resume RUN_ID`): the leading PASS steps of an earlier run of the same board are copied into the new report (`carried_from`) and skipped. It refuses if the PCB snapshot, the limits file, the probe setting or the 3.3 V source differ. The measured +5 V is restored from the carried step because the reference check needs it.
- **GUI** (`assembly/bench/gui.py`, `http://127.0.0.1:8090`): board, probes and "continue from" selection, the wiring table per step, one large button labelled with the word the step needs, a field for the Korad current, a log with pass/fail colouring, abort. It only relays answers; it never enables an AD3 output itself and never touches the supply.

One bug shipped and was fixed within minutes: the prompt event was emitted as `emit(kind='prompt', **pending)` while `pending` itself carried a `kind` key. My offline test had used a simulated run, which has no prompts.

### 2.5 The test route was cut down twice

The original digital test wanted eleven DIO grabbers on DIP pins plus two probes. That was rejected at the bench, rightly. The final minimum route uses **only the two scope probes on header pins**:

| Test | Steps |
|---|---|
| `power` | W1 self-check, rails, references |
| `digital` | rails, Pi-side clocks (J2.4, J2.5), bus clocks (J4.8, J4.10) |
| `stack` | rails with the left channel only, left modulator output QL (J4.12 against MCLK), rails with both channels, QR (J4.14), references (J4.4, J4.6), Pi clocks, Pi data (J2.6 against J2.4) |

The stack test adds the channel boards one at a time so that a faulty board is caught alone. All probe points moved to the digital board's header at the top of the stack when the power board's pins turned out to be unreachable once stacked. The mux truth table is not screened separately; "Pi data toggles with both channels present" covers it. The detailed per-channel tests (`left`, `right`, DIO harness, 1 kHz tone) remain for debugging.

## 3. Power board

Report `20260916T193608Z-power-95a4ffad`, PASS. Power board alone, W1 driving PUMP at J3.10, Korad 5.00 V.

| Measurement | Value | Window |
|---|---|---|
| W1 pump stimulus | 192.002 kHz, duty 0.497, low 0.014 V, high 4.920 V | ±2 %, 35–65 %, ≤0.45 V, 4.0–5.3 V |
| +5 V | 4.901 V, ripple 28 mVpp | 4.75–5.25 V, ≤150 mVpp |
| Negative rail | −4.425 V, ripple 20 mVpp | −5.25…−3.50 V |
| VREF_P | +2.466 V | 2.35–2.65 V |
| VREF_N | −2.490 V | −2.65…−2.35 V |

## 4. Digital board

### 4.1 Fault 1: no 3.3 V (operator)

`20260916T193845Z`: +5 V 4.884 V, **+3.3 V 0.026 V**, 31 mA. The capture of J2.3 was perfectly flat at 26 mV for 8 ms, no noise, no drift: a pin nothing is driving, not a rail under load. The script's enable sequence matched Digilent's own `AnalogIO_AnalogDiscovery3_Power.py`. The V+ flywire was not on J2.3.

Added afterwards: the test reads back what the AD3 itself measures on V+. A first version hinted "almost no current, check the wire" at 0.0 mA; that was wrong, because the 3.3 V side is a single 74HC4049 and draws microamps. The hint was removed.

Rails then passed: +5 V 4.888 V, +3.3 V 3.318 V, 32 mA.

### 4.2 Fault 2: the oscillator ran at 63.6 MHz

Symptoms at the Pi header:

| Pin | Expected | Measured |
|---|---|---|
| J2.4 PI_BCLK | 3.072 MHz | stuck at 3.25 V |
| J2.5 PI_LRCLK | 48 kHz | clean 3.3 V square at **500.9 kHz**, later **491 kHz** |

A ripple counter cannot produce a toggling LRCLK from a dead BCLK, so the counter was running, only far too fast:

$$
f_{\mathrm{CLK}} = 128 \times 500.9\ \text{kHz} \approx 64\ \text{MHz}
$$

BCLK was then about 32 MHz, which a 74HC4049 running from 3.3 V cannot pass, hence the stuck output. The 2 % drift between two readings a quarter of an hour apart ruled out the crystal, which holds 0.01 %. Confirmed on the 5 V bus pins:

| Pin | Expected | Measured | Ratio |
|---|---|---|---|
| J4.8 MCLK | 1.536 MHz | 15.90 MHz | 10.35 |
| J4.10 PUMP | 192 kHz | 1.987 MHz | 10.35 |

An inverter with only resistive feedback oscillates near $1/(2 t_{pd})$, about 60–70 MHz for HC logic. The chip in U9 reads **74HC04N D6683PS**, a buffered part, where the design calls for the unbuffered 74HCU04 (design-notes §5; the BOM still says "ORDER"). That looked like the answer, and it was written down as the cause.

**It was not the cause.** One leg of the crystal Y1 was not soldered. With the crystal open, only the 1 MΩ feedback R10 closes the loop, which gives exactly this free-running mode. After resoldering, three consecutive captures:

| Pin | Expected | Measured | Duty |
|---|---|---|---|
| MCLK | 1536.000 kHz | 1536.296 kHz, identical each time | 0.51 |
| PUMP | 192.000 kHz | 192.03–192.05 kHz | 0.50 |

The +0.02 % offset is within the AD3's timebase tolerance. The buffered 74HC04 stays in the socket for now; it locks, but a buffered gate in a Pierce is marginal, and the 74HCU04 remains on the order list.

### 4.3 Digital PASS

Report `20260916T203340Z-digital-897c4fcc`.

| Signal | Frequency | Low / high |
|---|---|---|
| PI_BCLK | 3.0726 MHz, duty 0.59 | −0.03 / 3.36 V |
| PI_LRCLK | 48.009 kHz, duty 0.51 | −0.01 / 3.35 V |
| MCLK | 1.5363 MHz, duty 0.51 | −0.07 / 5.01 V |
| PUMP | 192.04 kHz, duty 0.50 | −0.01 / 5.05 V |

The 0.59 duty on PI_BCLK is the 1× probe's capacitance slowing a 3 MHz edge from a 3.3 V 74HC4049, not the board. Later the same probe on the same signal read only 0.75–2.6 V. Rule that came out of it: **3 MHz Pi-side signals get the 10× probe.**

## 5. The stack

### 5.1 Left channel on the bus: MCLK dragged to 2 V

Rails with power + digital + left: +5 V 4.867 V, −5 V **−4.036 V**, 67 mA. Then:

| | With the left board | Board unplugged |
|---|---|---|
| MCLK high | 4.94 V | 4.98 V |
| MCLK low | **2.06 V** | 0.21 V |
| QL | flat 3.3 V with 192 kHz pump crosstalk, 0 edges | (open input) |

A low level of 2.06 V means the divider output was sinking roughly 50 mA against something sourcing 5 V through about 60 Ω:

$$
I \approx \frac{2.06\ \text{V}}{40\ \Omega} \approx 50\ \text{mA},\qquad R_{\text{source}} \approx \frac{5 - 2.06}{0.05} \approx 59\ \Omega
$$

which is one HC output fighting another, not a resistor. MCLK reaches exactly one pin on the channel board, U23 pin 3, next to pin 4 (+5 V).

Wrong turns here, in order:

1. *A solder bridge U23.3–U23.4.* The meter read 813 Ω one way and 1000 Ω the other between MCLK and +5 V, on **both** boards: that is just what the unpowered chip shows, not a bridge.
2. *A 0.07 mm clearance between MCLK and −5 V tracks.* My distance script ignored layers. MCLK runs on the bottom, that −5 V track on the top; the channel board is double-sided and the DRC is clean.
3. *U23 inserted backwards.* It explained every symptom (floating chip ground clamps MCLK's low through the input diode; the Q pin position carries an input). The chip has a notch at one end and a moulding circle at the other; the notch pointed at the bus, which is correct, since U23 pin 1 is the bus end. Hypothesis dead.

What remained was the same mechanism without the rotation: **U23's ground pin not making contact**. After the board and chip were reseated:

| | Before | After |
|---|---|---|
| MCLK low | 2.06 V | 0.21 V |
| QL | flat 3.3 V | 0–5 V, 366 edges in the record, one-density 0.497, changing only on MCLK edges |

### 5.2 J21 orientation

"J21 = 1–2" was ambiguous on the bench. From the PCB data: **pin 1 (square pad, QL) is the pin farthest from the bus connector; pin 3 (QR) is nearest.** Left board: shunt on the far pair. Right board: on the near pair. The right board first read 0 edges at QR for this reason, then passed with density 0.532.

### 5.3 VREF_N runs out of rail

| Load on the charge pump | −5 V rail | VREF_N |
|---|---|---|
| Power board alone | −4.425 V | −2.490 V |
| + left channel | −4.036 V | not measured |
| + both channels (83 mA total) | −3.788 V | **−1.767 V** (VREF_P +2.466 V) |

VREF_N is U2B, a TL072 inverting VREF_P (R4 = R5 = 10 kΩ). A TL07x output stops about 2 V above its negative supply:

$$
V_{\text{out,min}} \approx V_{-} + 2\ \text{V} = -3.79 + 2.0 \approx -1.8\ \text{V}
$$

Design-notes §10b had already measured the pump at −3.87 V under 30 mA and priced that against the integrators' common-mode range, but not against the reference inverter's output swing. The modulators keep toggling around 50 % with a skewed DAC, so this fails silently.

Fix: **U2 → LM358**, same DIP-8 pinout, output sinks to within a few hundred millivolts of V− at the 1.3 mA both channels draw from VREF_N (14k7 ∥ 13k0 ∥ 8k25 per channel into virtual earths). Rejected alternatives: MCP6002 and MCP601 (rail-to-rail but 6 V maximum total supply, U2 spans 8.8 V; the MCP601 is also a single), LM386 (an audio power amplifier, different pinout).

Result on 17 September: stack current 83 → 73 mA, **VREF_N −2.430 V**, ratio error 0.1 %. Report `20260917T152701Z-stack-94703bd8`, PASS on all seven steps; PI_DIN one-density 0.516 (it was 0.615 with the skewed reference).

An intermediate failure that day read "PI_BCLK = 48.009 kHz": both probes were one pin low on J2. Scope 1 was on LRCLK and scope 2 read about 791 kHz, the rising-edge rate of a random-looking 3.072 Mb/s stream (one rising edge per four bits).

### 5.4 What the Pi will see (manual AD3 capture)

PI_DIN transitions sit **10 ns after the BCLK falling edge and 150 ns before the rising edge** the Pi samples on (bit period 326 ns): textbook I²S timing. My first analysis sampled on the falling edge, where the data changes, and got a nonsense density of 0.87.

## 6. Raspberry Pi

### 6.1 Bringing the Pi up

Pi 4 Model B rev 1.2, Raspberry Pi OS Lite 64-bit (Debian 13 "trixie", kernel 6.18.50). No SD card reader was available, so the image went onto a USB stick; the Pi 4 boots from USB with no card inserted.

- Found on the LAN by mDNS (`vinyladc.local`) and by the Raspberry Pi MAC prefix `dc:a6:32`. Key login after one `ssh-copy-id`; a sudoers drop-in gave the user passwordless sudo.
- **Incident:** after a reboot my SSH client refused to connect: "REMOTE HOST IDENTIFICATION HAS CHANGED". An SD card had been inserted, the Pi 4 tries SD before USB, and it had booted another project ("vintedbot") from the card. Nothing was touched; the host-key check did its job.
- **Migration to the card** with `rpi-clone -f -U --exclude='/home/mads/backups/*' mmcblk0` (rsync-based, rewrites the partition IDs in `cmdline.txt` and `fstab`): 4 min 43 s. The clone lacked the empty `/boot/firmware` mount-point directory on its root filesystem; created by hand. Verified: root on `mmcblk0p2`, 435 boot files on both, overlay and config line present.

### 6.2 The overlay

The stock `i2s-master-dac` overlay is exactly this clocking arrangement (the Pi as I²S clock consumer, a dummy codec, two 32-bit slots) but playback-only. `pi/vinyl-adc-overlay.dts` is its capture twin with the S/PDIF receiver stub `linux,spdif-dir`. The kernel has `snd-soc-bcm2835-i2s`, `snd-soc-simple-card` and `snd-soc-spdif-rx`; the live device tree exposes `i2s_clk_consumer` and `sound`. After a reboot: `card 1: vinyladc [vinyl-adc]`.

### 6.3 Finding: the Pi's I²S clock pins are outputs until a stream is first opened

Read from the PCM block's `MODE_A` register (BCM2711, `0xFE203000 + 0x08`) with `pi/pcm_pins.py`:

| When | `MODE_A` | CLKM / FSM | GPIO18 / GPIO19 |
|---|---|---|---|
| After boot, before any capture | `0x00000000` | 0 / 0 | **outputs** (clock master) |
| After a capture device was opened once | `0x00f0fc20` | 1 / 1 | inputs (consumer), FLEN 64, FSLEN 32 |

The driver programs consumer mode in `hw_params`, not at probe. With the ADC powered during the Pi's boot, the Pi and the ADC's level shifter would drive BCLK and LRCLK against each other. `vinyl-adc-consumer.service` opens the device once at boot and logs the pin state before and after; it finishes about 22 s after kernel start.

Consequences: **boot the Pi first, then switch the ADC's 5 V on.** For the final build, where the Pi's 5 V powers the stack and the ADC therefore clocks during boot, about 470 Ω in series with PI_BCLK and PI_LRCLK limits the overlap to a few milliamps.

### 6.3a The capture card can come up wedged, and only a re-probe clears it

On one boot the card registered normally — `card 1: vinyladc`, `pcm0c` present, one free subdevice, `snd_soc_spdif_rx` and `snd_soc_bcm2835_i2s` loaded, DMA channel `dma0chan2 | fe203000.i2s:rx` allocated — but **every open of `/dev/snd/pcmC1D0c` failed with `EINVAL`**, for any format, including a bare `dd` on the node. `strace` put it at the `openat` itself, not at `hw_params`, and the kernel logged nothing at all. Headphone playback on card 0 worked, so ALSA at large was fine.

It is not the missing clock: the same `EINVAL` appeared with the ADC powered and unpowered, and the honest "no clocks" failure looks different — the open succeeds and the *read* returns `EIO`, which is what `vinyl-adc-consumer.service` means by ending in an I/O error. `live.py` reports any failure as "No clocks from the ADC", which is what sent me looking at the hardware first.

Re-probing the ASoC card clears it, no reboot needed:

```
echo soc:sound | sudo tee /sys/bus/platform/drivers/asoc-simple-card/unbind
echo soc:sound | sudo tee /sys/bus/platform/drivers/asoc-simple-card/bind
```

After that the open succeeds and consumer mode is programmed as usual (`MODE_A=0x00f0fc20`, CLKM/FSM = 1). Later boots came up healthy, so it is intermittent rather than a configuration error. **Check `MODE_A` before blaming the hardware:** if it still reads `0x00000000` after something has opened the device, the card is wedged, not silent.

### 6.4 Wiring

| J2 pin | Signal | Pi header |
|---|---|---|
| 1 | +5 V | pin 2, or the bench supply, never both |
| 2, 8 | GND | pins 6, 39 |
| 3 | +3.3 V | pin 1 (powers only the 74HC4049) |
| 4 | PI_BCLK | pin 12, GPIO18 |
| 5 | PI_LRCLK | pin 35, GPIO19 |
| 6 | PI_DIN | pin 38, GPIO20 |
| 7 | GPCLK0 | open. Only for clocking the ADC from the Pi, with J1 on 2–3 |

## 7. From bits to audio

### 7.1 Stream format

64 BCLK per 48 kHz frame, captured as `S32_LE` stereo. The 32-bit words are **not PCM**. The 74HC157 sends the left modulator's bit while MCLK is high and the right one while it is low, so the data line alternates L, R, L, R at 3.072 Mb/s and each frame carries 32 bits of each 1.536 MHz stream. Because LRCLK and MCLK come from the same ripple counter, the first bit after the frame edge is always a left bit.

### 7.2 The decimator (`pi/decimate.py`, NumPy only)

| Stage | Detail |
|---|---|
| De-interleave | `np.unpackbits` on big-endian words, even positions = left, odd = right |
| CIC | order 4, ÷8, to 192 kHz; Hogenauer structure with state so captures can be streamed; int64 wrap-around is harmless |
| FIR | 161 taps, ÷4, to 48 kHz; windowed frequency-sampling design (Kaiser β = 10) whose passband is the inverse of the CIC droop to 20 kHz, stopband from 28 kHz so aliases fold above 20 kHz |
| Start-up | the first 20 ms are discarded (the filters start from zero state; this was the "−10 dBFS peak" in the first capture) |

Self-test `pi/test_decimate.py`: a synthetic interleaved stream from a second-order modulator, 1 kHz at 0.5 FS and 18 kHz at 0.25 FS plus 0.1 FS DC, recovered within **0.03 dB** and DC to 0.1000.

### 7.3 Judging a modulator from its own bits (`pi/analyze_bitstream.py`)

PSD of each 1-bit stream at the full rate (65 536-point Hann segments, averaged):

- **In-band floor** in dBFS/Hz at 1, 5 and 20 kHz.
- **Noise-shaping slope** between 30 and 80 kHz. A healthy third-order loop climbs about +60 dB/decade just above the audio band; first-order gives +20.
- **Idle tone.** With a DC input the loop whistles at

$$
f_{\text{idle}} = \lvert 2d - 1 \rvert \cdot f_{\text{clk}}
$$

where $d$ is the one-density. Left: $d = 0.4959 \Rightarrow 12.6$ kHz, measured 12.59 kHz. Right: $d = 0.4982 \Rightarrow 5.5$ kHz, measured 5.51 kHz.

The small DC offset itself is explained by the reference asymmetry, $(2.467 - 2.430)/(2.467 + 2.430) \approx 0.0076$, so every healthy board lands near $d = 0.4957$.

### 7.4 First capture (17 September 20:24)

10 s, exactly 3 840 000 bytes, so BCLK/LRCLK are locked.

| | Left | Right |
|---|---|---|
| One-density | 0.4959 | 0.4982 |
| In-band floor at 1 / 5 / 20 kHz | −118 / −118 / −117 dBFS/Hz | −123 / −104 / −100 dBFS/Hz |
| Shaping 30→80 kHz | **+68 dB/decade** | **+13 dB/decade** |
| Noise 20 Hz–20 kHz | −74.3 dBFS | −41.4 dBFS |
| Strongest line | 12.59 kHz, −85 dBFS | 5.51 kHz, **−46 dBFS** |

## 8. The right channel

Four separate faults, each hiding the next.
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

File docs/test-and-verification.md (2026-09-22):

# Vinyl ADC — test and verification

**Date:** 18 September 2026 · **Unit:** the four-board stack, both channels · **Verdict:** both channels functional and measured; the left channel meets the simulated target, the right does not.

This is the acceptance record for the finished converter: what was measured, with what, under what conditions, and what the numbers do and do not mean. It is deliberately explicit about the instrument's own limits, because several figures here are bounded by the generator rather than by the converter.

---

## 1. Configuration under test

| | |
|---|---|
| Boards | Power, digital, channel L, channel R — the full stack, assembled |
| Supply | Korad bench supply, 5.00 V, 73 mA typical. **Not** the Pi's 5 V (see §6) |
| Clock | Crystal Pierce oscillator on the digital board, MCLK 1536.296 kHz |
| Modulator | Third-order delta-sigma, 1.536 MHz, interleaved L/R on one data line |
| Capture | Raspberry Pi 4, I²S clock consumer, ÷32 decimation to 48 kHz (4th-order CIC ÷8 + 161-tap compensating FIR ÷4) |
| Input | J20 on each channel board, via RV20 input trimmer |
| Repairs in place | Solder-side wires J7.16→U22.4 and J7.2→U23.14 on both boards; DACP_L short to ground cleared on the right board |

Two faults were fixed on the day of these measurements, both on the right channel, and both are described in `bringup-log-2026-09.md` §8.4 and §8.6. The measurements below are all post-repair.

## 2. Instruments and their limits

| Instrument | Role | Limit that matters |
|---|---|---|
| Analog Discovery 3, W1 | Signal source into J20 | **14-bit: bounds measured distortion and noise near −80 dB.** Anything better than that is the generator, not the converter |
| AD3 scope, 10×/1× probes | Rail and node verification | — |
| Raspberry Pi ripper `/api/audio` | Delivers the decimated 48 kHz output for analysis | Serves the *last* N seconds; a capture window must be waited out (§7) |
| `pi/live.py` | Bitstream health per channel | Analyses the raw 1-bit stream, not the decimated audio |
| `assembly/bench/run.py audio` | The measurement plan | Records figures, does not judge them; `PASS` means "completed" |

**W1 cannot reach 0 dBFS on this converter.** Full scale is 10.41 Vpk on the left channel and W1 stops near ±5 V, so the −3 dBFS point was unreachable: both the −3 and −6 dBFS requests land at −6.37 dBFS, and the "−3 dBFS" row in the raw reports is a second −6 dBFS measurement.

## 3. Modulator verification — the 1-bit stream

Both inputs shorted at J20, Korad supply, analysed at 1.536 MHz from the raw bitstream. This tests the loop itself, with the input network grounded and no instrument attached.

| | Left | Right | Healthy |
|---|---|---|---|
| Verdict | third-order shaping | third-order shaping | — |
| Mean run of identical bits (max) | 1.352 (3) | 1.361 (3) | ≈1.35; a limit cycle gives 18–19 |
| One-density, no input | 0.4957 | 0.4957 | ≈0.5 |
| Noise shaping, 30→80 kHz | +68.1 dB/dec | +68.6 dB/dec | ≈+60 for third order |
| In-band noise, 20 Hz–20 kHz | −76.75 dBFS | −77.49 dBFS | — |
| Noise density at 1 kHz | −125.8 dBFS/Hz | −125.9 dBFS/Hz | — |
| Noise density at 20 kHz | −121.3 dBFS/Hz | −121.0 dBFS/Hz | — |
| DC offset | −0.0087 | −0.0087 | — |

**The two modulators are indistinguishable.** Density matches to four decimal places, mean run to 0.01, shaping to 0.5 dB/decade, and the right channel is marginally the quieter of the two. Whatever separates the channels in §4 is not the loop, the rails, the references or the DAC.

## 4. Audio performance — the decimated 48 kHz output

W1 driving J20 of the channel under test, the other channel's input shorted, capture from the ripper. Left run `20260918T093339Z-audio-a485477f`, right run `20260918T094918Z-audio-78d57572`.

| Measurement | Left | Right |
|---|---|---|
| Full-scale input | 10.41 Vpk (7.362 Vrms) | 9.484 Vpk |
| Output for 0.5 Vpk at 1 kHz | −26.37 dBFS | −25.56 dBFS |
| **Frequency response, 20 Hz–16.3 kHz** | **0.119 dB p-p** | **0.139 dB p-p** |
| Dynamic range (AES17, −60 dBFS tone, A-wtd) | **67.94 dB** | 57.92 dB |
| SNR (0 dBFS re idle noise, A-wtd) | **67.66 dB** | 58.70 dB |
| Idle noise (generator connected) | −66.17 dBFS / −67.66 dBFS(A) | −57.33 / −58.70 |
| THD at −6 dBFS | 0.0282 % | 0.0841 % |
| THD at −20 dBFS | 0.0320 % | 0.1233 % |
| 2nd harmonic | −75.78 dBc | −65.07 dBc |
| 3rd harmonic | −83.68 dBc | −62.54 dBc |
| IMD CCIF 19+20 kHz | −82 dB *(generator-limited)* | −80.46 dB *(generator-limited)* |
| IMD SMPTE 60 Hz + 7 kHz (4:1) | 0.139 % | 0.162 % |
| Hum, 50 / 100 Hz | −99.49 / −111.7 dBFS | −93.11 / −101.3 dBFS |
| Crosstalk into the other channel | −92.42 dB | −67.56 dB |

**The left channel meets the design target.** SPICE predicted about 68 dB SNR for the third-order loop with delay compensation; the hardware returns **67.94 dB of dynamic range and 67.66 dB SNR**. Frequency response is flat to **±0.06 dB from 20 Hz to 16.3 kHz**, which is the decimator's FIR behaving as designed.

For context, the benchmark that matters for this machine is the source: a good vinyl pressing delivers 60–70 dB. The left channel sits inside that; CD's 96 dB is not the relevant bar.

### Figures that are noise, not distortion

THD at −40 and −60 dBFS reads 1.6 % and 2.3 %. At those levels the tone is close to the noise floor and THD+N is noise-dominated. These are not distortion results and should not be quoted as such. The meaningful distortion points are −6 and −20 dBFS.

## 5. Finding: the right channel's deficit is in the input path, not the converter

The right channel is **9–10 dB worse in noise and dynamic range, and 3–4× worse in distortion**, with the 3rd harmonic 21 dB worse. This is a real difference, measured with the left input shorted; it is not a floating-input artefact.

The important observation is where it *isn't*:

- At the **bitstream** level with the input shorted (§3), the right channel equals the left — in fact it is 0.7 dB quieter.
- At the **audio** level with a source driving the input network (§4), it is 9 dB noisier.

The loop, rails, references and DAC are therefore exonerated by §3. The deficit appears only when the signal passes through the input network, which on each board is `J20 → C20 (2u2) → R20 (1k00) → C21 (1n5)/RV20 (47 k) → R21 (20k5) → integrator 1`.

**Leading hypothesis: the right board's RV20 trimmer.** During the gain-matching procedure its output dropped 80 dB momentarily and recovered — a direct observation of an intermittent wiper. A dirty or worn wiper contributes exactly what is measured: contact noise (excess broadband noise) and a non-linear contact resistance in series with the signal (harmonic distortion, odd orders especially, matching the 21 dB rise in the 3rd harmonic). Once set and left alone the trimmer is stable to 0.01 dB over 20 s, so the fault is intermittent rather than continuous.

**Next test:** clean or replace RV20 on the right board and repeat §4. If the noise returns to ≈−66 dBFS and THD to ≈0.03 %, this is settled. That measurement has not been made and the hypothesis is not yet proven.

### Channel gain matching

RV20 sets each channel's full-scale input, so **full scale is a calibration, not a property of the converter**. The two were matched by driving 0.5 Vpk at 1 kHz and reading the ADC output: the left gives −26.37 dBFS, the right was set to −25.56 dBFS, leaving **0.81 dB of channel imbalance**. Setting both trimmers to the same physical rotation is not sufficient — these are ±20 % parts and identical positions differed by about a dB.

At 10.41 Vpk (7.36 Vrms) of full scale, a phono stage delivering ~0.5 Vrms would peak near −23 dBFS and waste most of a converter that only has ~68 dB to give.

### Set against the real source, 2026-09-20

Done, with the converter in the listening chain: the Phono Box output and the Saga input now share J20's two screws on each board, so the record plays through the speakers and into the ADC from one junction. Levels were set with a record playing, using `pi/levels.py`.

| | before | after |
|---|---|---|
| Music peak, left | −13.9 dBFS | **−6.9 dBFS** |
| Music peak, right | −13.9 dBFS | **−6.9 dBFS** |
| Channel imbalance | 0.81 dB (1 kHz tone) | **0.0 dB** |

"Music peak" is the 95th percentile of the 100 ms peak buckets over 30 s, not the maximum: the loudest transients in the same passage reached −3.6 dBFS, and those are clicks in the groove. Trimming to them would have left the record 7 dB quieter than it needs to be.

**Checked for clamping, and there is none.** A 10 s capture gives a crest factor of 15.9 dB (left) and 16.8 dB (right), with 1 sample in 480 000 above 99 % of peak and 13 above 90 %. A limiter or an input clamp in circuit piles thousands of samples at one amplitude; this distribution is ordinary music. The +7 dB moves the converter from roughly the low 60s to the 68 dB region of the design curve (`docs/design-notes.md` §3).

Both boards read **Healthy** at the bitstream level while doing this — density 0.4956 / 0.4959, mean run 1.34 / 1.35 — and the ripper selected **stereo**, not the mono fallback it used before the right-channel repair.

### 5b. The idle floor with the turntable connected, 2026-09-20

Stylus up, platter stopped, whole chain powered, trimmers at the setting above. Ten seconds of the ripper's own output, 0.73 Hz bins.

| | Left | Right |
|---|---|---|
| Total, 20 Hz–20 kHz | −55.8 dBFS | −56.1 dBFS |
| A-weighted | −61.1 dBFS | −62.1 dBFS |
| 20–200 Hz | −58.6 dBFS | −58.4 dBFS |
| 200 Hz–2 kHz | −68.6 dBFS | −69.4 dBFS |
| 2–20 kHz | −59.6 dBFS | −60.6 dBFS |

Against §3's −77 dBFS with the input shorted, **the chain costs about 21 dB**, and with peaks at −7 dBFS the delivered recording has ~49 dB of range unweighted, ~54 dB A-weighted. **The converter is no longer what limits a rip; the source chain is.** (Turning RV20 up did not cause this: source noise and signal rise together, so the ratio was the same 49 dB at the old setting, where the floor sat near −63 dBFS.)

**Two contributors, and the L/R coherence separates them.** Coherence is 1.00 at 50 Hz and 0.99 across 20–200 Hz — both channels see the *same* voltage, which only happens through a shared ground — and 0.21–0.34 above 200 Hz, which is independent per channel and therefore the phono stage's own noise or the cartridge. The 50 Hz fundamental dominates its harmonics by 14 dB, so the low end is inductive pickup rather than supply ripple.

They are close to equal in power, which is the trap: removing the mains family entirely would take the total from −55.8 to only −59.6 dBFS, and removing the HF half alone gains 2.8 dB. Neither is worth chasing alone.

**Ethernet is ruled out.** The Pi runs on `eth0`, so the router looked like an earth path. Unplugged for 37 s (kernel log 15:17:35 → 15:18:12) and recovered from the ripper's 60 s ring afterwards, the 50 Hz line moved 0.2 dB and the 20–200 Hz coherence never left 0.99 — before, during and after are identical within 0.3 dB. In hindsight this was predictable: Ethernet is transformer-isolated at the PHY and the cable is unshielded, so there was never a galvanic path there to break. Any advice to "move the Pi to Wi-Fi to break the loop" is wrong for this reason.

**Next test**, not yet done: disconnect the turntable at the Phono Box input (arm leads and the ground wire) with everything else untouched. If the 20–200 Hz noise falls, it originates in the arm, cartridge or turntable earth; if it holds, it is the phono stage or a loop between its ground and the converter's through the tap.

## 6. Conditions not covered

- **Pi-powered operation.** All figures here are on the Korad bench supply. The 1-bit DAC gates run directly from +5 V, so that rail *is* the DAC reference; running from the Pi previously cost 6–11 dB of idle noise. The 5 V filtering and the 470 Ω series resistors in PI_BCLK/PI_LRCLK that address this are not fitted.
- **Idle noise is not comparable between §3 and §4.** §3 shorts the input; §4 has the generator wired to it, contributing its own noise. The −66.2 dBFS in §4 and the −76.8 dBFS in §3 are measurements of different configurations.
- **Right channel after an RV20 repair** — the open item from §5.
- **The top octave, 16.3–20 kHz.** `sweep_points()` steps in third-octaves from 20 Hz and stops at 16255 Hz because the next step would pass 20 kHz, so the highest measured point is 16.3 kHz. The plan's own row is *labelled* "20 Hz–20 kHz" and that label overstates what was swept — a figure of ±0.06 dB should be quoted to 16.3 kHz, not 20 kHz.
- **A full record side end to end**, and the enclosure as a physical print.
- **Hum with the turntable connected** — measured properly on 2026-09-20, see §5b. Not closed, but no longer a guess.

## 7. Two measurement bugs found, and why the first runs were invalid

The first two audio runs produced figures that were artefacts of the bench code. Both are fixed; runs before `20260918T093339Z` should be discarded.

**A fixed ±4-bin measurement window on a self-clocked converter.** The ADC generates its own LRCLK at 1536296/32 = 48009 Hz, not 48000, so a tone lands about 190 ppm low and drifts out of a fixed window in proportion to frequency. Reproduced on a synthetic full-level tone: the old code loses **35 dB at 8 kHz and 70 dB at 19 kHz**. It presented as a "frequency response" that fell off a cliff at 5 kHz, and as nonsensical IMD (SMPTE 15 %, CCIF −14 dB). `band_power` now searches ±600 ppm for the tone before summing. The same captures re-analysed gave CCIF −82 dB and SMPTE 0.14 %.

*Caught by:* the rolloff being far too steep for any analogue filter, then reading where the spectral peak actually was.

**A capture window longer than its settle time.** The noise step silenced the generator, waited 5 s and asked the ripper for the last 8 s — so 3 s of the window predated the change and still held the previous step's 1 kHz tone. "Idle noise" measured that tone.

*Caught by:* A-weighted and unweighted idle noise agreeing to four significant figures, which only happens if the "noise" is a 1 kHz tone — A-weighting is 0 dB at exactly 1 kHz.

Two operational notes on the bench GUI, both of which cost a run: it imports `run.py` and `audio.py` at start, so code edits need a restart; and it holds the AD3 until its process exits, so a second run needs a restart too.

## 8. Traceability

| Artefact | Where |
|---|---|
| Left channel audio run | `assembly/bench/results/20260918T093339Z-audio-a485477f/` |
| Right channel audio run | `assembly/bench/results/20260918T094918Z-audio-78d57572/` |
| Measurement plan | `assembly/bench/plans.json`, board `audio` |
| Analysis code | `assembly/bench/audio.py`, `assembly/bench/run.py` |
| Bitstream analysis | `pi/live.py`, `pi/analyze_bitstream.py` |
| Full narrative, every fault and wrong turn | `docs/bringup-log-2026-09.md` |

Each run folder holds `report.json`, a `summary.md` table, the raw `.npz` captures for the noise, tone and IMD steps, and plots of the noise spectrum, response and SMPTE IMD.

**The run folders are not in the repository.** `assembly/.gitignore` excludes `bench/results/` by design, so local captures are never published as if they were qualification data; the two runs cited here live on the bench machine (26 MB, mostly raw capture). The figures in `docs/figures/` and the numbers quoted above are what leaves the machine. `docs/figures.py` regenerates all three figures from a fresh `/snapshot.raw` and the two run folders, and prints the measured in-band noise and shaping slope so a capture taken in the wrong condition cannot be published with an idle-condition caption.

---

## Summary

The converter works, in stereo, and the left channel performs as simulated: **±0.06 dB from 20 Hz to 20 kHz, 67.9 dB dynamic range, 0.03 % THD, −92 dB crosstalk** — against a SPICE prediction of about 68 dB SNR. The right channel's loop is provably identical, but its input path costs it 9 dB of noise and 4× the distortion, with an intermittent trimmer the leading and untested explanation. That, the absolute input level, and Pi-powered operation are what stand between this and a finished instrument.

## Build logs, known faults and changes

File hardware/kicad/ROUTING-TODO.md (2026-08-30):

# What is left before these boards can be cut

State on 2026-08-30. The **channel artwork is DOUBLE-SIDED** (cut twice from the
two pieces of double-sided stock); power and digital stay single-sided.

**The channel artwork is FINISHED and EXPORTED** —
`production/vinyl_adc_channel_l/`. Power and digital have not met their bar and
have not been exported.

Re-measure before trusting any of this:

```
py -3.13 tools/remaining_links.py                       # the links, one by one
"C:/Program Files/KiCad/10.0/bin/python.exe" \
    ~/.claude/skills/kicad-place/scripts/place_route.py check <board>.kicad_pcb
py -3.13 ~/.claude/skills/kicad-place/scripts/place_score.py <board>.kicad_pcb
```

## Where the three artworks stand

| | sides | links left | wire bridges | vias | GND pour | DRC beyond the `.kicad_dru` exception | placement |
|---|---|---:|---:|---:|---|---|---|
| **channel** | **double** | **0** | **0** | **0** | **1 piece**, 0 stranded | **none** (13 silk_overlap, cosmetic) | 4/4 |
| power | single | 0 | 1 | 0 | 1 piece, 0 stranded | 1 silk_overlap | 4/4 |
| digital | single | 13 | 0 | 0 | 2 pieces, 1 stranded, 19 fragments | none | 3/4 |

**The channel artwork is done.** The last link — `VREF_N` to J7 pin 6, which
FreeRouting would not close at 30 or 100 passes with the whole top layer free —
was routed by hand. 26/26 nets in one piece, both oracles agreeing at 0
unconnected, 0 vias, 0 stranded pads, ground pour whole.

One cleanup was applied after that: the GND zone had `island removal = Never`,
which left 9 floating fragments (1.2–12.9 mm², none carrying a pad) showing as
`isolated_copper`. Set to **Always** and refilled — pour went to 1 piece and
those 9 DRC violations went to 0. Nothing depended on them (0 stranded pads
before and after).

**One advisory that is NOT in the acceptance bar.** `cutspan` reads 1.141 board
diagonals — the ground return detours 161 mm further than the straight line, and
the worst point is (78.89, 30.0), which is **J7 pin 1, the bus GND pin**. The
automated route read 0.725 before the manual pass. It is not a fault and it does
not block production, but this artwork is milled twice and it feeds a modulator
whose noise floor is ground-dependent, so it is worth knowing.

### Building the two channel boards

One artwork, one production set, milled twice. The boards are otherwise
identical — **the Q-select shunt is the only thing that names a channel**:
J21 **1-2 = LEFT**, **2-3 = RIGHT**.

## Two gates now read "wrong" on the channel board, on purpose

`place_route.py check` and `place_score.py` are single-sided tools. On the
channel artwork they report:

```
FAIL  single_sided  10 F.Cu bridge runs (52 segments)
FAIL  onelayer      52 F.Cu segments are wire bridges to hand-solder, not copper
```

**Both are wrong about this board.** Those 52 F.Cu segments are *milled copper
on the top side*, not wire. The metric that still means something on a
double-sided milled board is **vias**, because the holes are drilled and never
plated — a via is a wire pushed through and soldered both sides. That check
reads `ok 0 vias`, and it is the one to watch. Everything else those tools
report — connectivity, oracles_agree, netclass, track width, pour islands —
is layer-aware and still valid.

## Why "leftovers on top" and not a full re-route

Four architectures measured on the same placement, same clearance, every output
refilled by KiCad before judging:

| | links left | vias | GND pour | pads needing a TOP joint | of those, on DIP sockets |
|---|---:|---:|---|---:|---:|
| single-sided (what it was) | 13 | 0 | whole, 6 fragments | 0 | 0 |
| signals on top, GND plane on bottom | 6 | 0 | **whole, 1 piece** | 91 | 28 |
| both layers, GND poured | 2 | 1 | **split in 3**, 12 fragments | 55 | 15 |
| **leftovers on top (shipped)** | **1** | **0** | whole, 9 fragments | **20** | **6** |

The reasoning that picked the last one: **a link left open is a wire, and a wire
is soldered at both ends** — exactly the two joints a milled top-side trace
between the same two pads needs. So converting leftovers to top copper costs
nothing in soldering and removes the wire. The other two modes re-route from
scratch and move joints that were already fine, buying a better plane (or two
fewer links) for 35–71 extra top-side joints.

"Signals on top" is the electrically prettiest board — an uncut ground plane
under every trace — and if the noise floor ever needs it, it is one command
away. It costs 28 socket-pin joints on the top side instead of 6.

## Milling it double-sided

- **Stock:** 110 × 110 mm against a 100.1 × 100.1 mm outline — about 5 mm of
  margin all round.
- **Registration is already solved.** The four M3 mounting holes sit at exactly
  **±44.00 mm from the board centre in both axes** — a perfect square,
  symmetric about the centre in X and in Y. Flipping the board about either
  axis maps the hole pattern onto itself, so two dowel pins through a diagonal
  pair register the second side with no extra tooling holes and no error to
  measure. Drill those four first, on the first side.
- **Mill B.Cu, flip, mill F.Cu.** The CAM does the mirroring for whichever side
  you cut second — do not pre-mirror the Gerbers. `export_production.ps1`
  already writes both `F.Cu` and `B.Cu`.
- **Top-side soldering: 20 pads.** Fourteen are on headers or axial/radial parts
  where the whole pad is reachable. **Six are DIP socket pins** — U20.1, U22.4,
  U23.1, U23.10, U23.2, U24.4 — and those have **1.78 mm of pad outside the IC
  body** (roughly 1.1 mm outside a typical socket). That margin is exactly why
  this process mandates the `_LongPads` DIP footprints. It is tight but it is
  reachable with a fine tip; solder those six before seating anything that
  covers them.
- The 8 `isolated_copper` are stray pour fragments with no pad on them. Not a
  connectivity fault, and they will move when the pour is refilled after the
  last link goes in, so they are not worth chasing yet.

## power — 0 links, 1 bridge, and a long way round for the return current

Fully connected, ground pour whole, no stranded pads. The one bridge is a single
**-5V** wire, J3.16 (61.11, 32.54) to U2.4 (85.19, 56.81) — 35 mm diagonally.

**The direction-cost theory did not hold.** The ladder already defaults to
`against_preferred_direction_trace_costs 1.0`, and re-routing traded that 1
bridge for **3 missing links** — a worse board. It does cost the return path:
`cutspan` **fails at 1.551 board diagonals** (219 mm further than straight).
The fresh route fixes that (0.483) at the price of those 3 links, and is kept at
`scratchpad/rt_power_1/run1/Tiso/`. That trade is yours; the connected board is
what is on disk.

If you have a third piece of double-sided stock later, `route_2layer.py
--mode leftovers-top` would almost certainly absorb this bridge into top copper
the same way it did on the channel board.

## digital — 13 links, and the real problem is the placement

Routed from nothing (3/20 nets, zone unfilled, 60 unconnected) down to 13 links,
0 DRC violations, 0 bridges. Reproducible: two independent ladder runs both
landed on 13, rung for rung.

**But 13 against a floor of 2 is a placement problem, not a router problem:**

| | power | channel | digital |
|---|---:|---:|---:|
| `nbr_rank` (want <= 0.25) | 0.227 | 0.177 | **0.512** |
| ratsnest crossings / part | 0.0 | 0.36 | **1.85** |
| HPWL / part / diagonal | 0.080 | 0.127 | **0.495** |

Digital is the only board failing the cohesion gate, and by more than 2x, while
carrying five times the channel board's crossings on a third of the parts. More
router passes will not fix that.

The unpulled lever is **pouring**: `place_floor.py --pours` says GND alone
leaves digital at floor 2, but **`+3V3 + +5V + GND` takes it to 0** — three
pours, exactly at the budget before FreeRouting wedges. That means partitioning
B.Cu into three plane regions, a real design change carrying gotcha 25 (two
same-priority zones over one outline can invert their fill once there are
tracks). Highest-value thing left on this board, and not attempted.

## A bug in `export_production.ps1` that only bites on this project

Its gerber and drill steps pass `-o "$OutDir\gerbers\"`. The trailing backslash
before the closing quote is read by Windows argument parsing as an **escaped
quote**, so the argument runs on into the next one and the path is mangled —
here `...\Projects\Vinyl ADC\...` came back as `...\personal-projects\ADC\...`
and kicad-cli reported *Board file does not exist*. The DXF steps are fine
because they pass a full filename with no trailing separator.

It is invisible on a path with no spaces, which is why it has never shown up
before. **"Vinyl ADC" has a space.** Until the script is fixed, run the two
steps by hand with the directory passed as a variable and no trailing slash:

```powershell
$out = "<proj>\production\<board>\gerbers"
New-Item -ItemType Directory -Force $out | Out-Null
& $kc pcb export gerbers -l "F.Cu,B.Cu,Edge.Cuts,B.Mask,F.Mask,F.Silkscreen,F.Fab" -o $out $pcb
& $kc pcb export drill --format excellon -o $out $pcb
```

The script still writes the three DXFs correctly, including the laser
silkscreen, so it is only the `gerbers/` half that needs this.

## Tooling added

- `tools/remaining_links.py` — the unrouted links, pad by pad with coordinates.
- `tools/route_2layer.py` — double-sided routing (`signals-top`, `both-layers`,
  `leftovers-top`). Two traps are handled in there and written up in the source:
  FreeRouting does not echo `(type fix)` wires back into the `.ses`, so a
  locked-copper run must **merge** rather than let `ImportSpecctraSES` replace;
  and 1.9.0 headless can sit forever after writing a complete `.ses`, so the
  wait is bounded and the file on disk decides.

## Also stale, not touched

`PCB-NOTES.md` still documents the superseded four-board build — a 160×120 mm
`vinyl_adc_common` and three IDC ribbons — and now also predates the channel
board going double-sided.

`production/` was already empty apart from its `.gitignore`.

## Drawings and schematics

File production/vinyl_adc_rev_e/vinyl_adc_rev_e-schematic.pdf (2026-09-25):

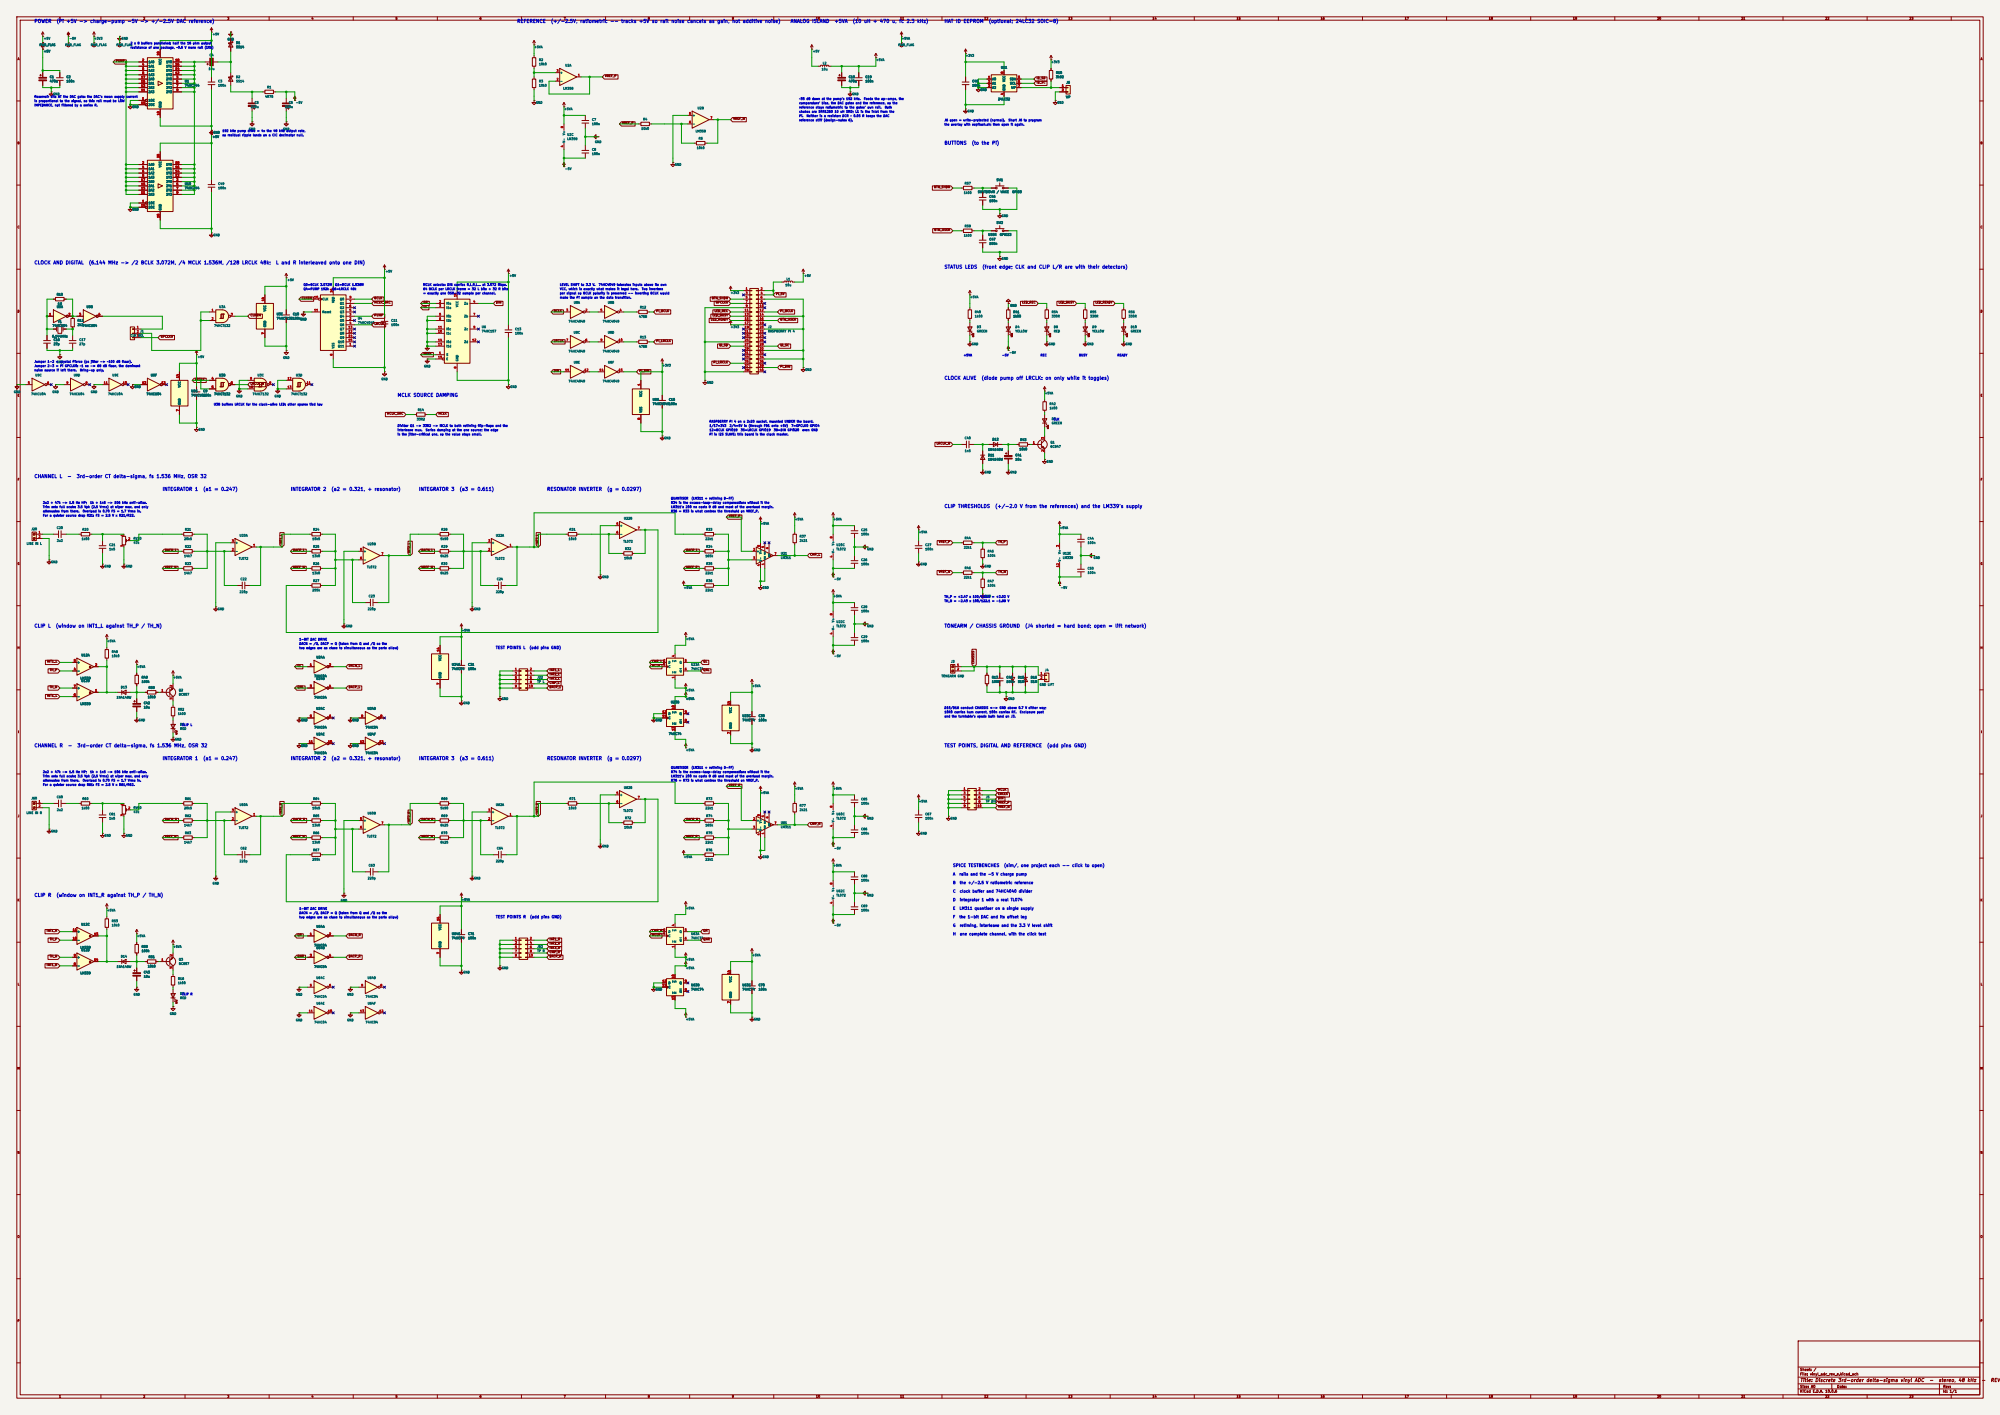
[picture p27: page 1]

POWER (Pi +5V -> charge-pump -5V -> +/-2.5V DAC reference)

REFERENCE (+/-2.5V, ratiometric -- tracks +5V so rail noise cancels as gain, not additive noise)

ANALOG ISLAND +5VA (10 uH + 470 u, fc 2.3 kHz)

HAT ID EEPROM (optional; 24LC32 SOIC-8)

2 x 8 buffers paralleled: half the 16 ohm output

is proportional to the signal, so this rail must be LOW
IMPEDANCE, not filtered by a series R.

~35 dB down at the pump's 192 kHz. Feeds the op-amps, the
comparators' bias, the DAC gates and the reference, so the
reference stays ratiometric to the gates' own rail. Both
chokes are SRR1260 10 uH SMD; L1 is the inlet from the
Pi. Neither is a resistor: DCR ~ 0.05 R keeps the DAC
reference stiff (design-notes 6).

J6 open = write-protected (normal). Short J6 to program

the overlay with eepflash.sh; then open it again.

192 kHz pump drive = 4x the 48 kHz output rate, so residual ripple lands on a CIC decimator null.

BUTTONS (to the Pi)

MCLK selects: DIN carries R,L,R,L... at 3.072 Mbps.
= exactly one OSR-32 sample per channel.

LEVEL SHIFT to 3.3 V. 74HC4049 tolerates inputs above its own
VCC, which is exactly what makes it legal here. Two inverters make the Pi sample on the data transition. per signal so BCLK polarity is preserved -- inverting BCLK would

Jumper 2-3 = Pi GPCLK0: ~1 ns -> 68 dB floor, the dominant Jumper 1-2 = crystal Pierce (ps jitter -> ~100 dB floor).

noise source if left there. Bring-up only.

CLOCK ALIVE (diode pump off LRCLK: on only while it toggles)

U3B buffers LRCLK for the clock-alive LED; other spares tied low

RASPBERRY PI 4 on a 2x20 socket, mounted UNDER the board. 1/17=3V3 2/4=5V in (through FB1 onto +5V) 7=GPCLK0 GPIO4

CLK CLIP THRESHOLDS (+/-2.0 V from the references) and the LM339's supply

Divider Q1 -> 33R2 -> MCLK to both retiming flip-flops and the
interleave mux. Series damping at the one source; the edge
is the jitter-critical one, so the value stays small.

12=BCLK GPIO18 35=LRCLK GPIO19 38=DIN GPIO20 even GND

Pi is I2S SLAVE: this board is the clock master. QUANTISER (LM311 + retiming D-FF) R34 is the excess-loop-delay compensation: without it the

Trim sets full scale: 3.5 Vpk (2.5 Vrms) at wiper max, and only

LM311's 200 ns costs 8 dB and most of the overload margin.
R36 = R33 is what centres the threshold on VREF_P.

For a quieter source drop R21: FS = 2.5 V x R21/R22. attenuates from there. Overload is 0.70 FS = 1.7 Vrms in.

CLIP L (window on INT1_L against TH_P / TH_N)

LM311's 200 ns costs 8 dB and most of the overload margin. R76 = R73 is what centres the threshold on VREF_P. 1-BIT DAC DRIVE
two edges are as close to simultaneous as the parts allow) DACN = /Q, DACP = Q (taken from Q and /Q so the

TEST POINTS L (odd pins GND)

D15/D16 conduct CHASSIS <-> GND above 0.7 V either way; 10R0 carries hum current, 100n carries RF. Enclosure post and the turntable's spade both land on J3. TEST POINTS, DIGITAL AND REFERENCE (odd pins GND)

CLIP L For a quieter source drop R61: FS = 2.5 V x R61/R62.

QUANTISER (LM311 + retiming D-FF)
R74 is the excess-loop-delay compensation: without it the

SPICE TESTBENCHES (sim/, one project each -- click to open)

A rails and the -5 V charge pump

C clock buffer and 74HC4040 divider

CLIP R (window on INT1_R against TH_P / TH_N)

E LM311 quantiser on a single supply

F the 1-bit DAC and its offset leg

G retiming, interleave and the 3.3 V level shift

H one complete channel, with the click test

Size: A0 | Rev:
KiCad E.D.A. 10.0.6 | Id: 1/1

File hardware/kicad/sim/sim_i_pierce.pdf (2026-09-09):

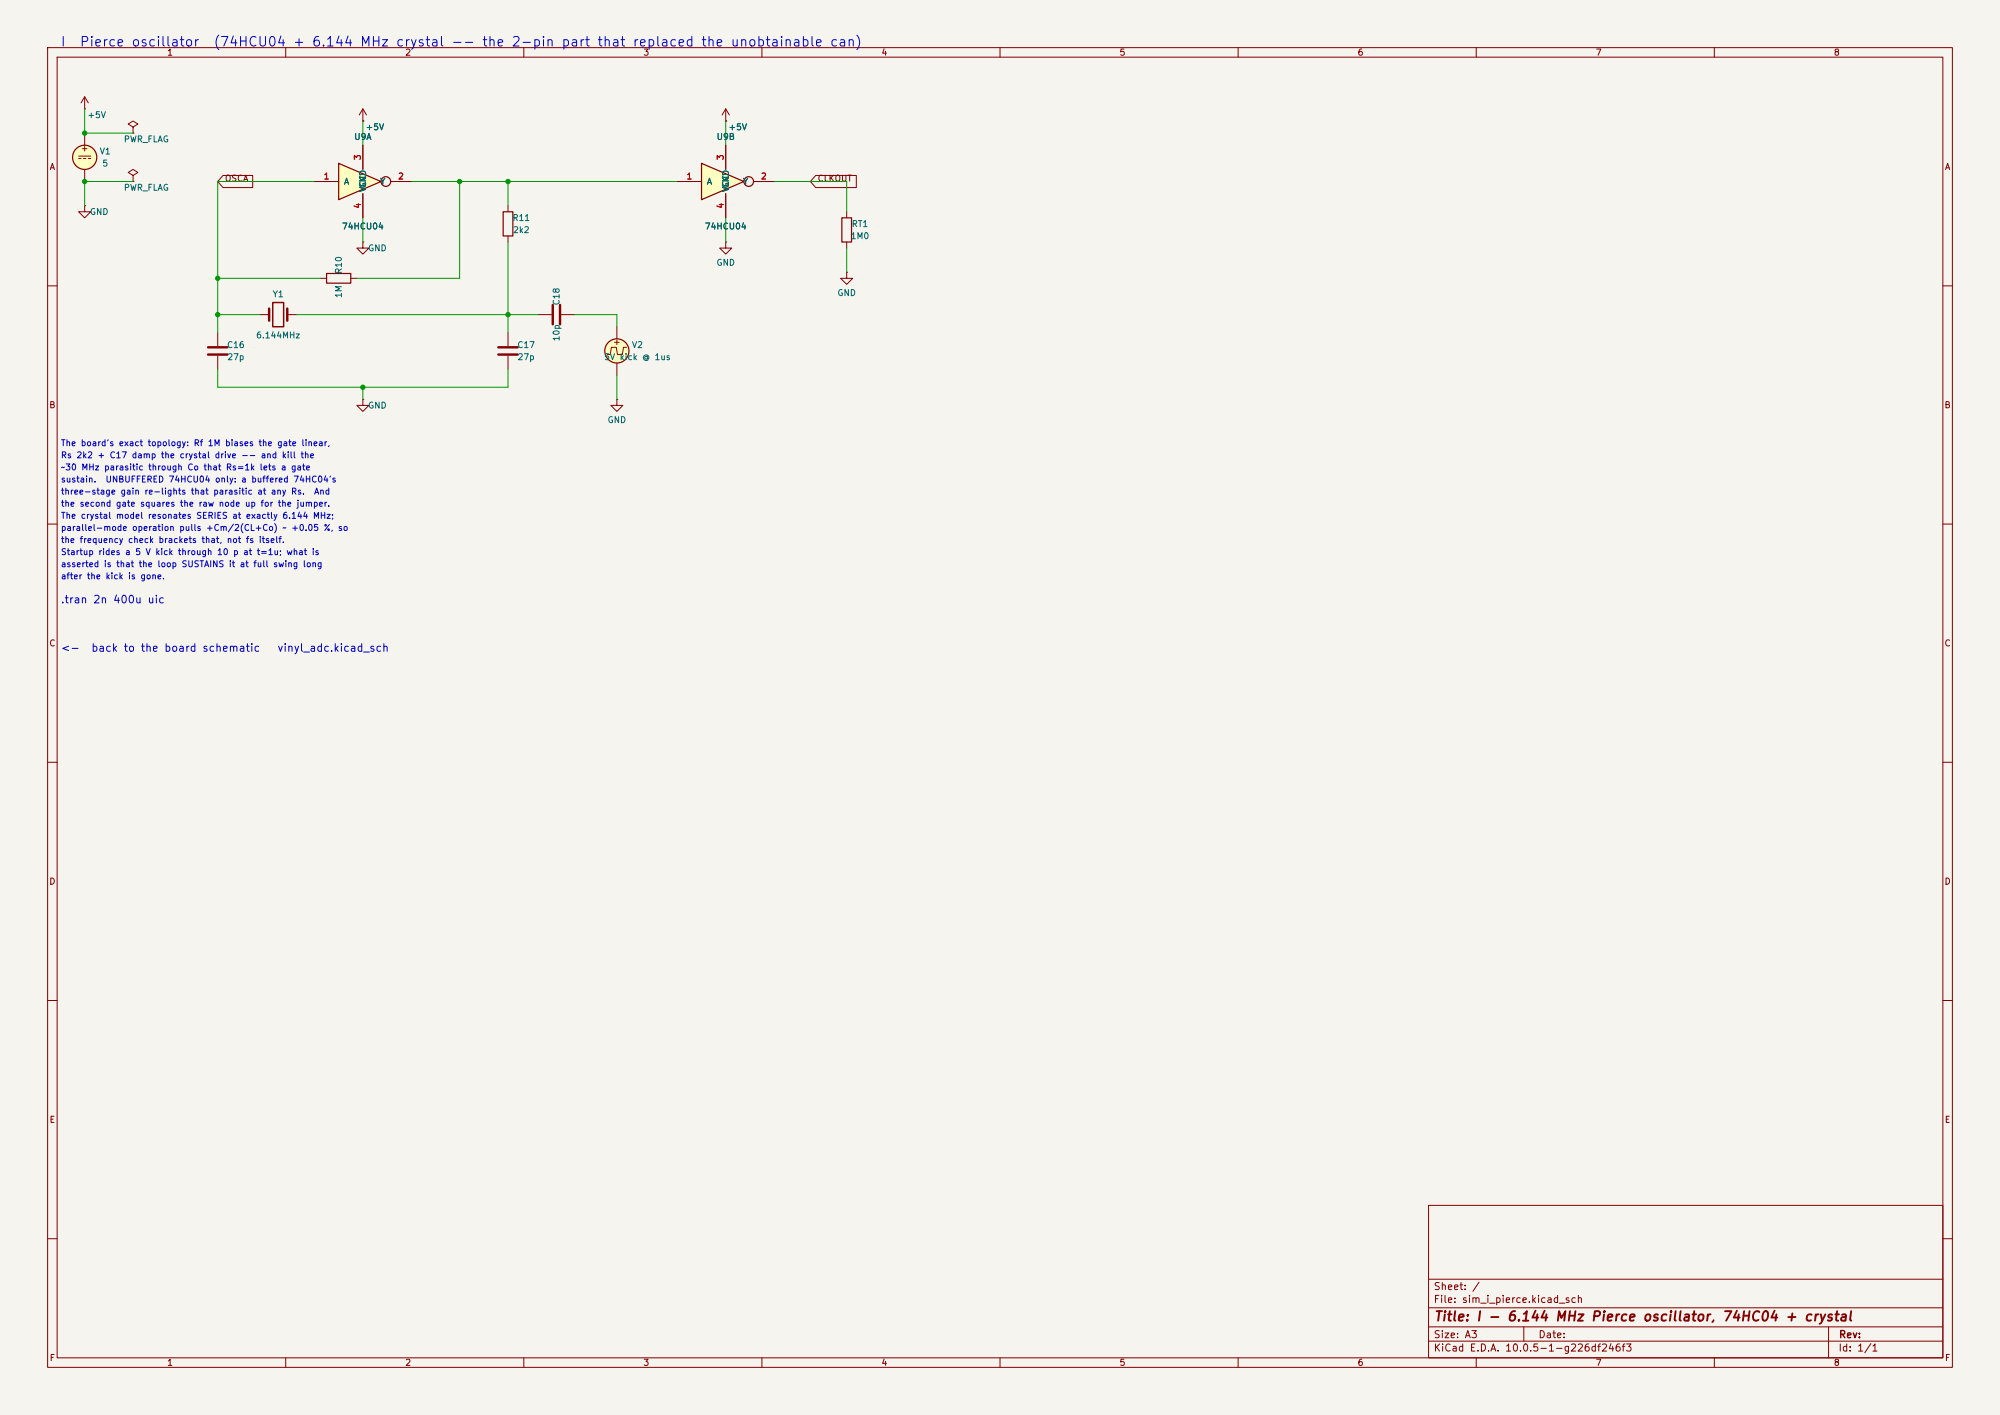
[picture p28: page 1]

I Pierce oscillator (74HCU04 + 6.144 MHz crystal -- the 2-pin part that replaced the unobtainable can)

The board's exact topology: Rf 1M biases the gate linear,
~30 MHz parasitic through Co that Rs=1k lets a gate Rs 2k2 + C17 damp the crystal drive -- and kill the

sustain. UNBUFFERED 74HCU04 only: a buffered 74HC04's
three-stage gain re-lights that parasitic at any Rs. And
The crystal model resonates SERIES at exactly 6.144 MHz; the second gate squares the raw node up for the jumper.

the frequency check brackets that, not fs itself. parallel-mode operation pulls +Cm/2(CL+Co) ~ +0.05 %, so

Startup rides a 5 V kick through 10 p at t=1u; what is
after the kick is gone. asserted is that the loop SUSTAINS it at full swing long

Sheet: /
File: sim_i_pierce.kicad_sch
Title: I - 6.144 MHz Pierce oscillator, 74HC04 + crystal

Size: A3 | Rev: | F Date:
KiCad E.D.A. 10.0.5-1-g226df246f3 | Id: 1/1

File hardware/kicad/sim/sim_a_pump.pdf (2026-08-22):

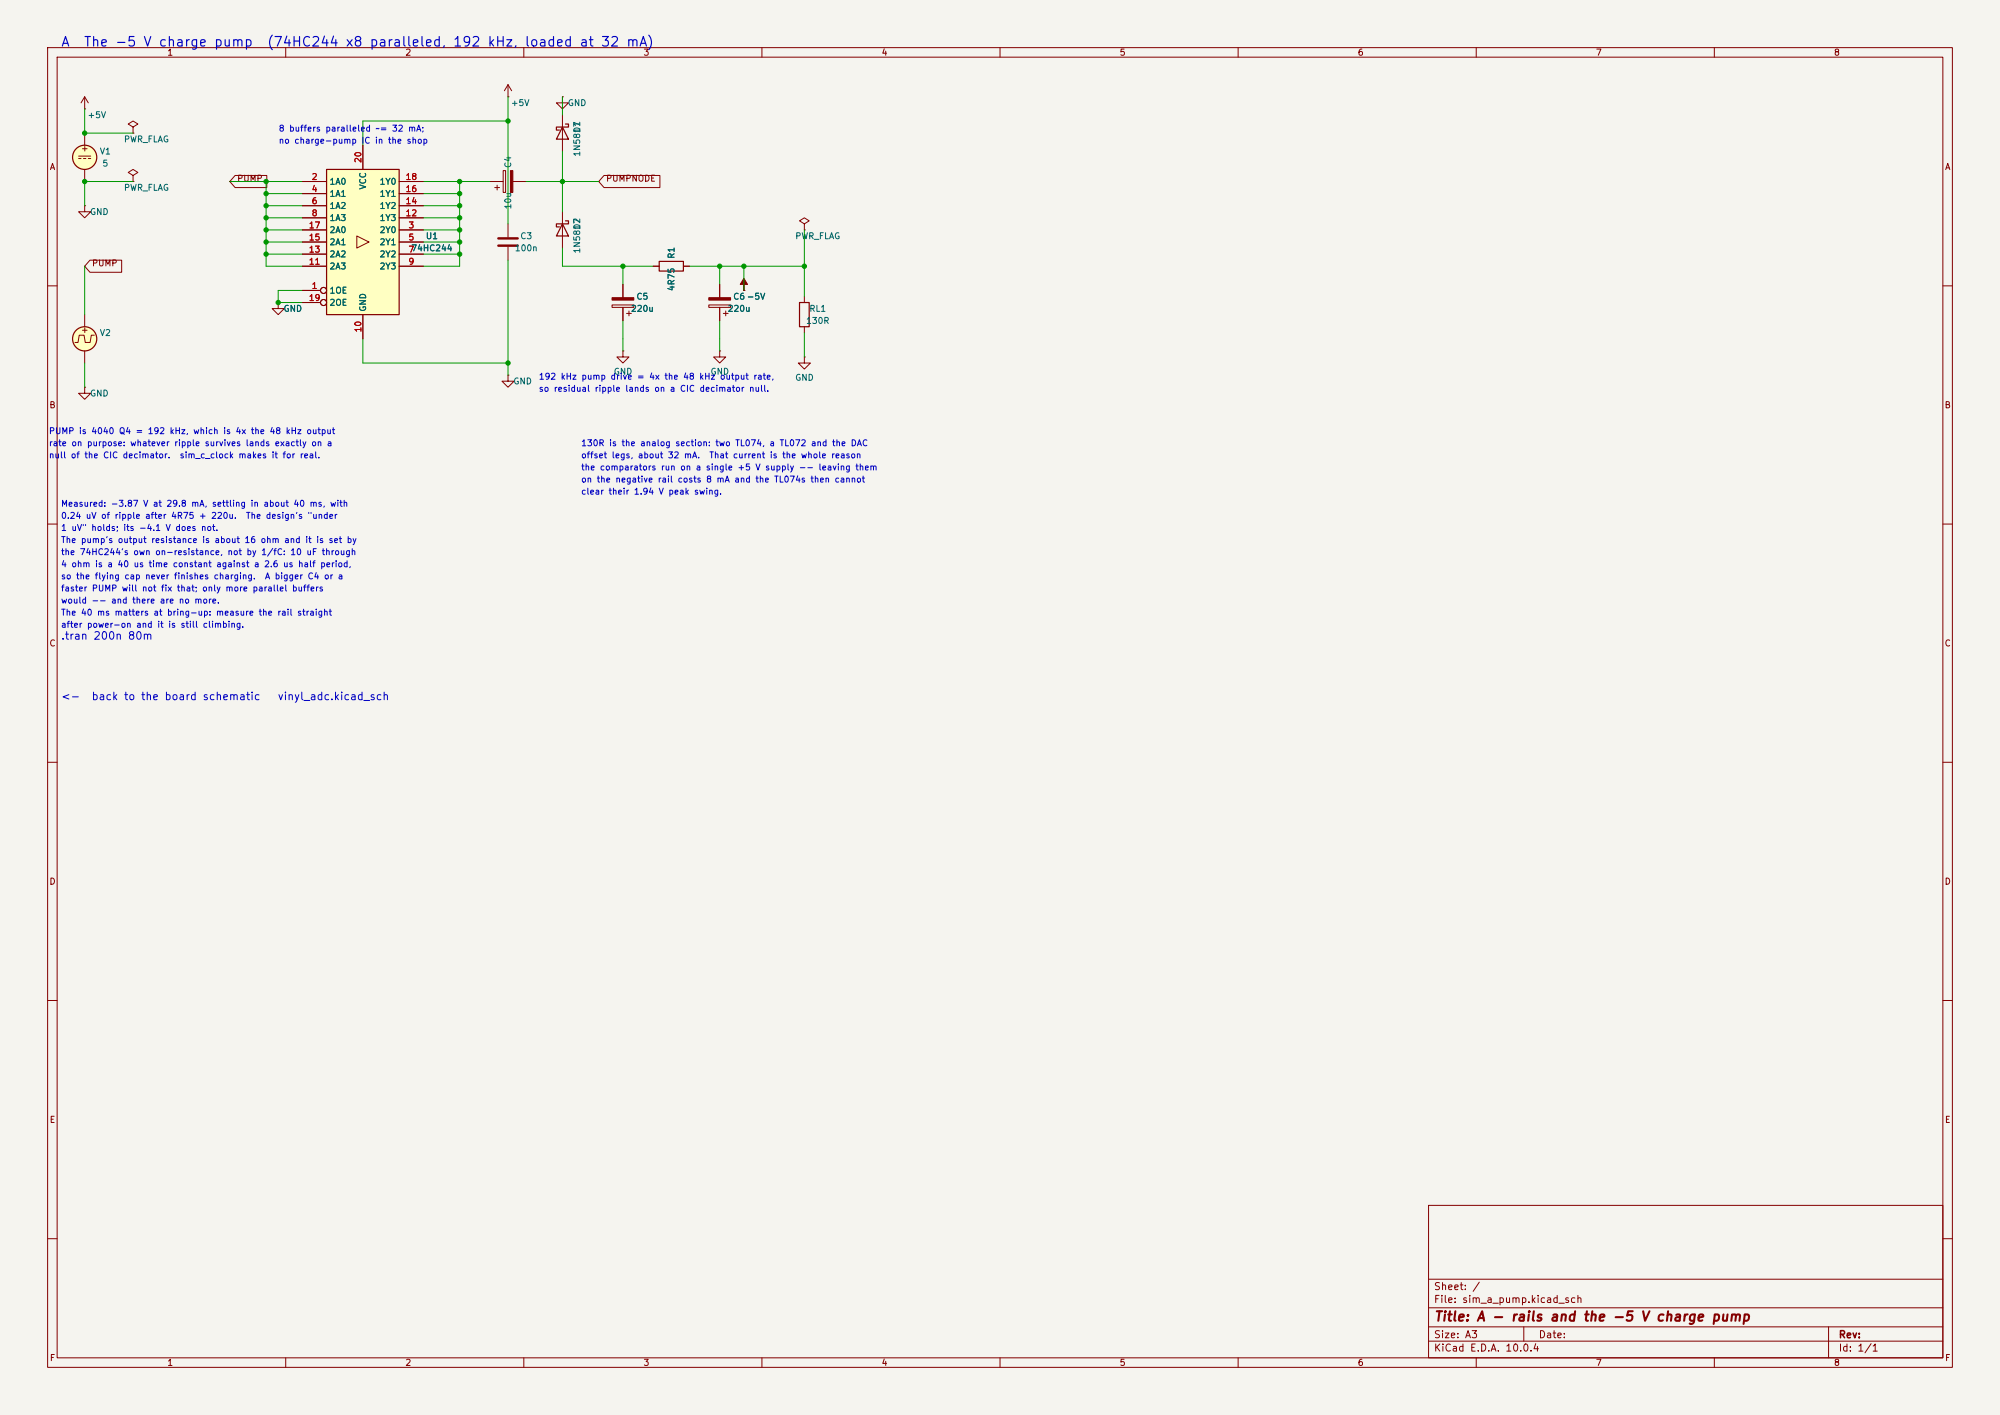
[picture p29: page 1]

on the negative rail costs 8 mA and the TL074s then cannot clear their 1.94 V peak swing. no charge-pump IC in the shop

PUMP is 4040 Q4 = 192 kHz, which is 4x the 48 kHz output rate on purpose: whatever ripple survives lands exactly on a

the comparators run on a single +5 V supply -- leaving them

the 74HC244's own on-resistance, not by 1/fC: 10 uF through 4 ohm is a 40 us time constant against a 2.6 us half period, 1 uV" holds; its -4.1 V does not. would -- and there are no more. after power-on and it is still climbing.
The pump's output resistance is about 16 ohm and it is set by

faster PUMP will not fix that; only more parallel buffers

Sheet: /
File: sim_a_pump.kicad_sch
Title: A - rails and the -5 V charge pump

Size: A3 | Rev:
KiCad E.D.A. 10.0.4 | Id: 1/1 | F Date:

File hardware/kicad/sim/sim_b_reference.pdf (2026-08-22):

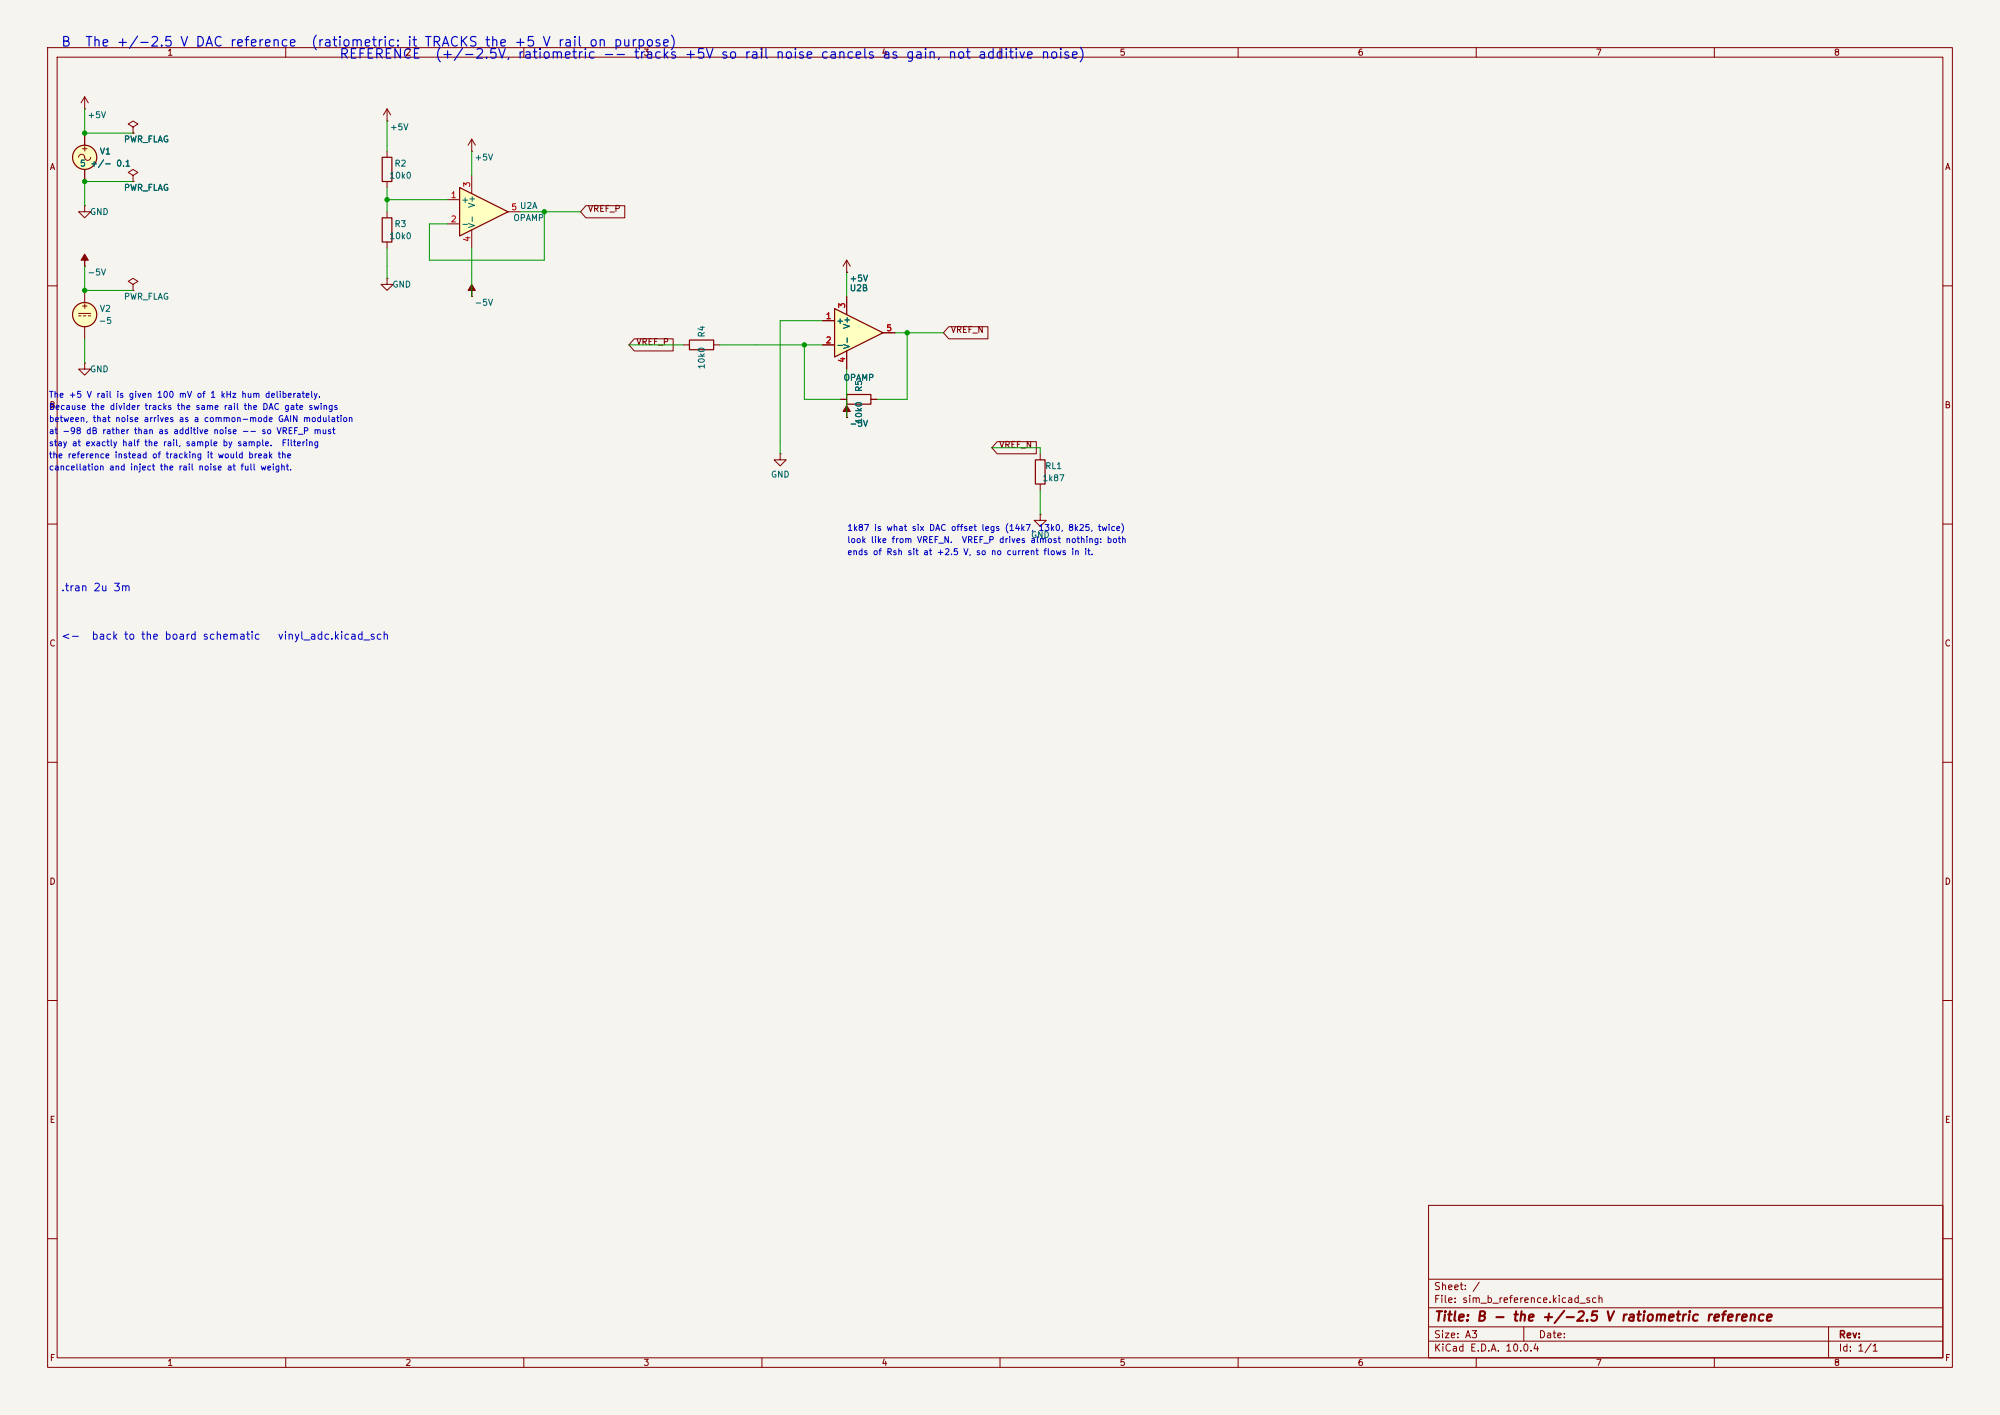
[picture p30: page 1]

B The +/-2.5 V DAC reference (ratiometric: it TRACKS the +5 V rail on purpose)

ends of Rsh sit at +2.5 V, so no current flows in it. REFERENCE (+/-2.5V, ratiometric -- tracks +5V so rail noise cancels as gain, not additive noise)

The +5 V rail is given 100 mV of 1 kHz hum deliberately. Because the divider tracks the same rail the DAC gate swings

between, that noise arrives as a common-mode GAIN modulation
at -98 dB rather than as additive noise -- so VREF_P must stay at exactly half the rail, sample by sample. Filtering

the reference instead of tracking it would break the
cancellation and inject the rail noise at full weight.

1k87 is what six DAC offset legs (14k7, 13k0, 8k25, twice)
look like from VREF_N. VREF_P drives almost nothing: both

Sheet: /
File: sim_b_reference.kicad_sch
Title: B - the +/-2.5 V ratiometric reference

Size: A3 | Rev:
KiCad E.D.A. 10.0.4 | Id: 1/1 | F Date:

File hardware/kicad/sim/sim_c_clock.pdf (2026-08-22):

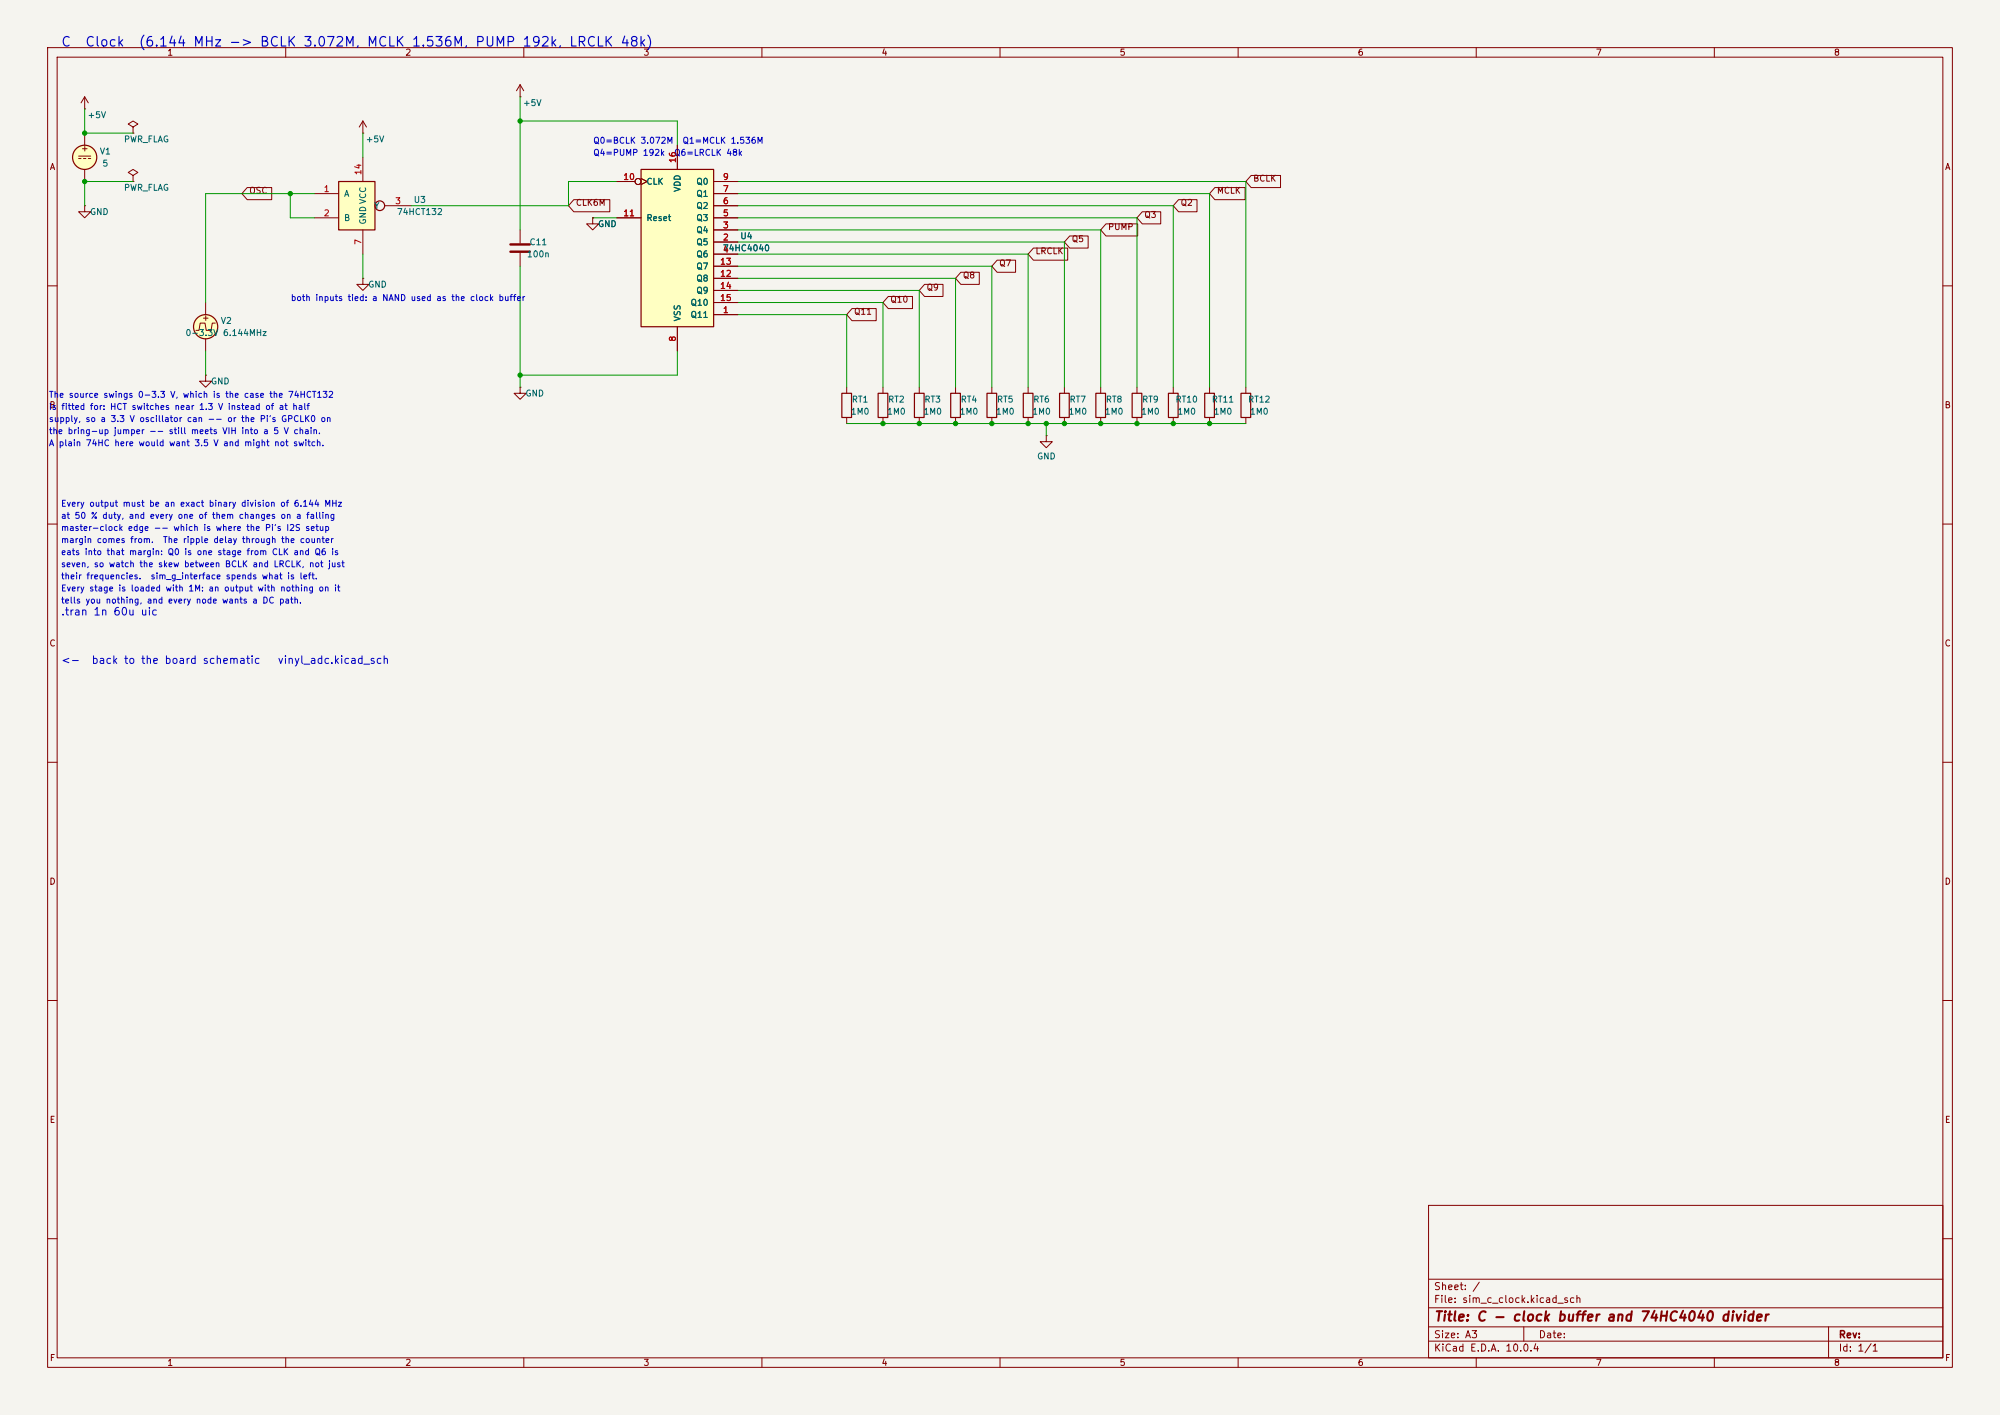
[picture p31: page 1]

The source swings 0-3.3 V, which is the case the 74HCT132

supply, so a 3.3 V oscillator can -- or the Pi's GPCLK0 on
the bring-up jumper -- still meets VIH into a 5 V chain. A plain 74HC here would want 3.5 V and might not switch. at 50 % duty, and every one of them changes on a falling

Every output must be an exact binary division of 6.144 MHz master-clock edge -- which is where the Pi's I2S setup

margin comes from. The ripple delay through the counter eats into that margin: Q0 is one stage from CLK and Q6 is

seven, so watch the skew between BCLK and LRCLK, not just
their frequencies. sim_g_interface spends what is left. Every stage is loaded with 1M: an output with nothing on it

tells you nothing, and every node wants a DC path.

Sheet: /
File: sim_c_clock.kicad_sch
Title: C - clock buffer and 74HC4040 divider

Size: A3 | Rev:
KiCad E.D.A. 10.0.4 | Id: 1/1 | F Date:

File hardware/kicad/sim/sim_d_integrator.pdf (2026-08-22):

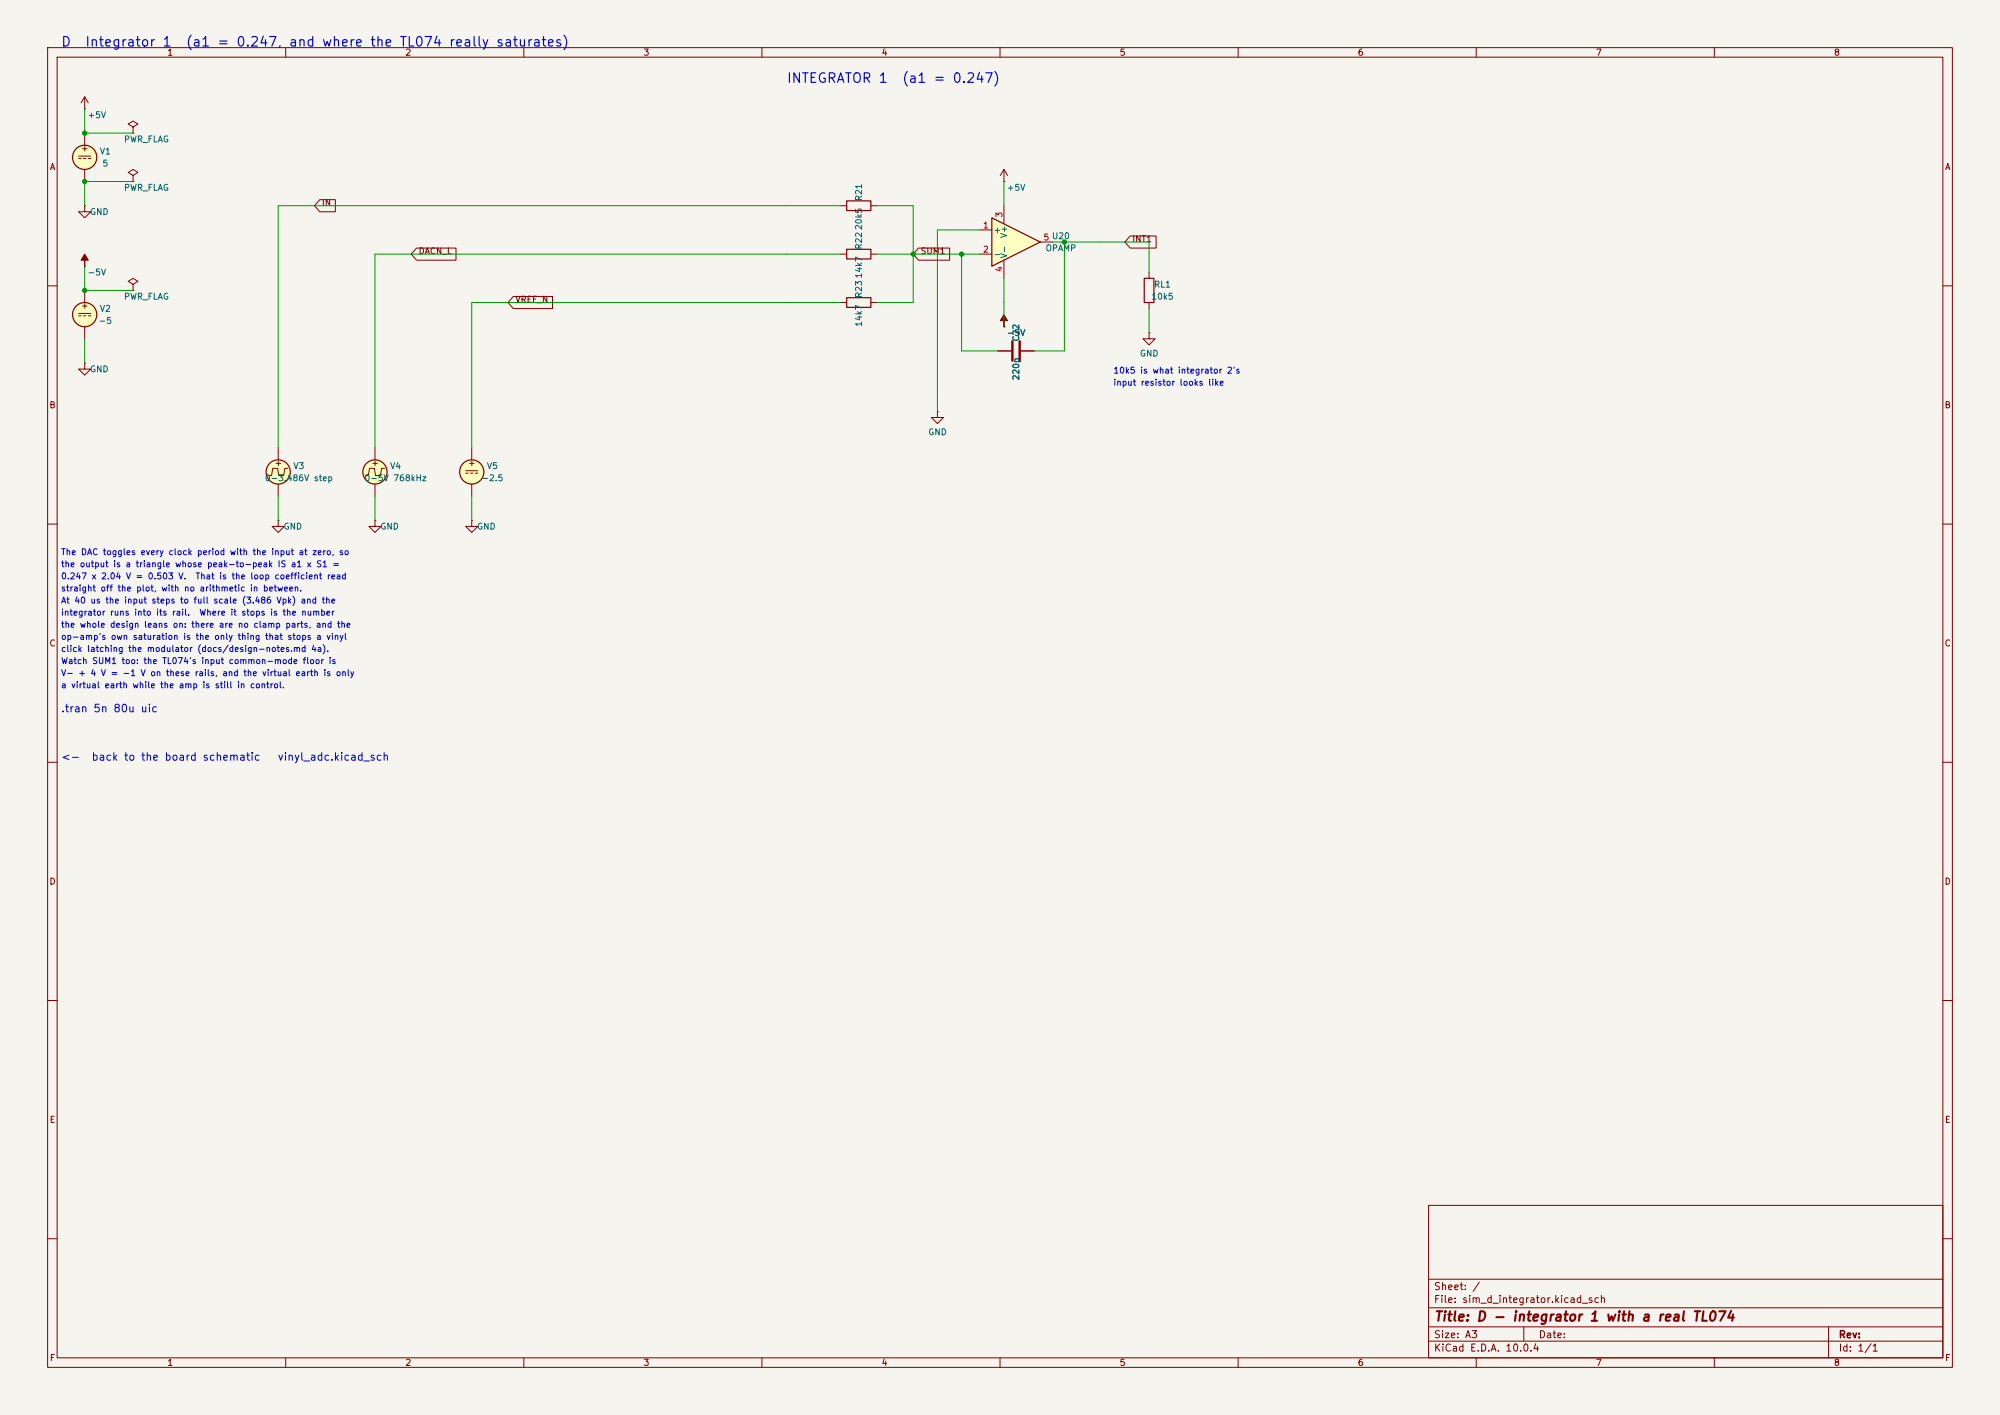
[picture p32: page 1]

D Integrator 1 (a1 = 0.247, and where the TL074 really saturates)

GND
input resistor looks like 0.247 x 2.04 V = 0.503 V. That is the loop coefficient read

The DAC toggles every clock period with the input at zero, so
the output is a triangle whose peak-to-peak IS a1 x S1 =

straight off the plot, with no arithmetic in between.
At 40 us the input steps to full scale (3.486 Vpk) and the
integrator runs into its rail. Where it stops is the number

Sheet: /
File: sim_d_integrator.kicad_sch
Title: D - integrator 1 with a real TL074

Size: A3 | Rev: | F Date:
KiCad E.D.A. 10.0.4 | Id: 1/1

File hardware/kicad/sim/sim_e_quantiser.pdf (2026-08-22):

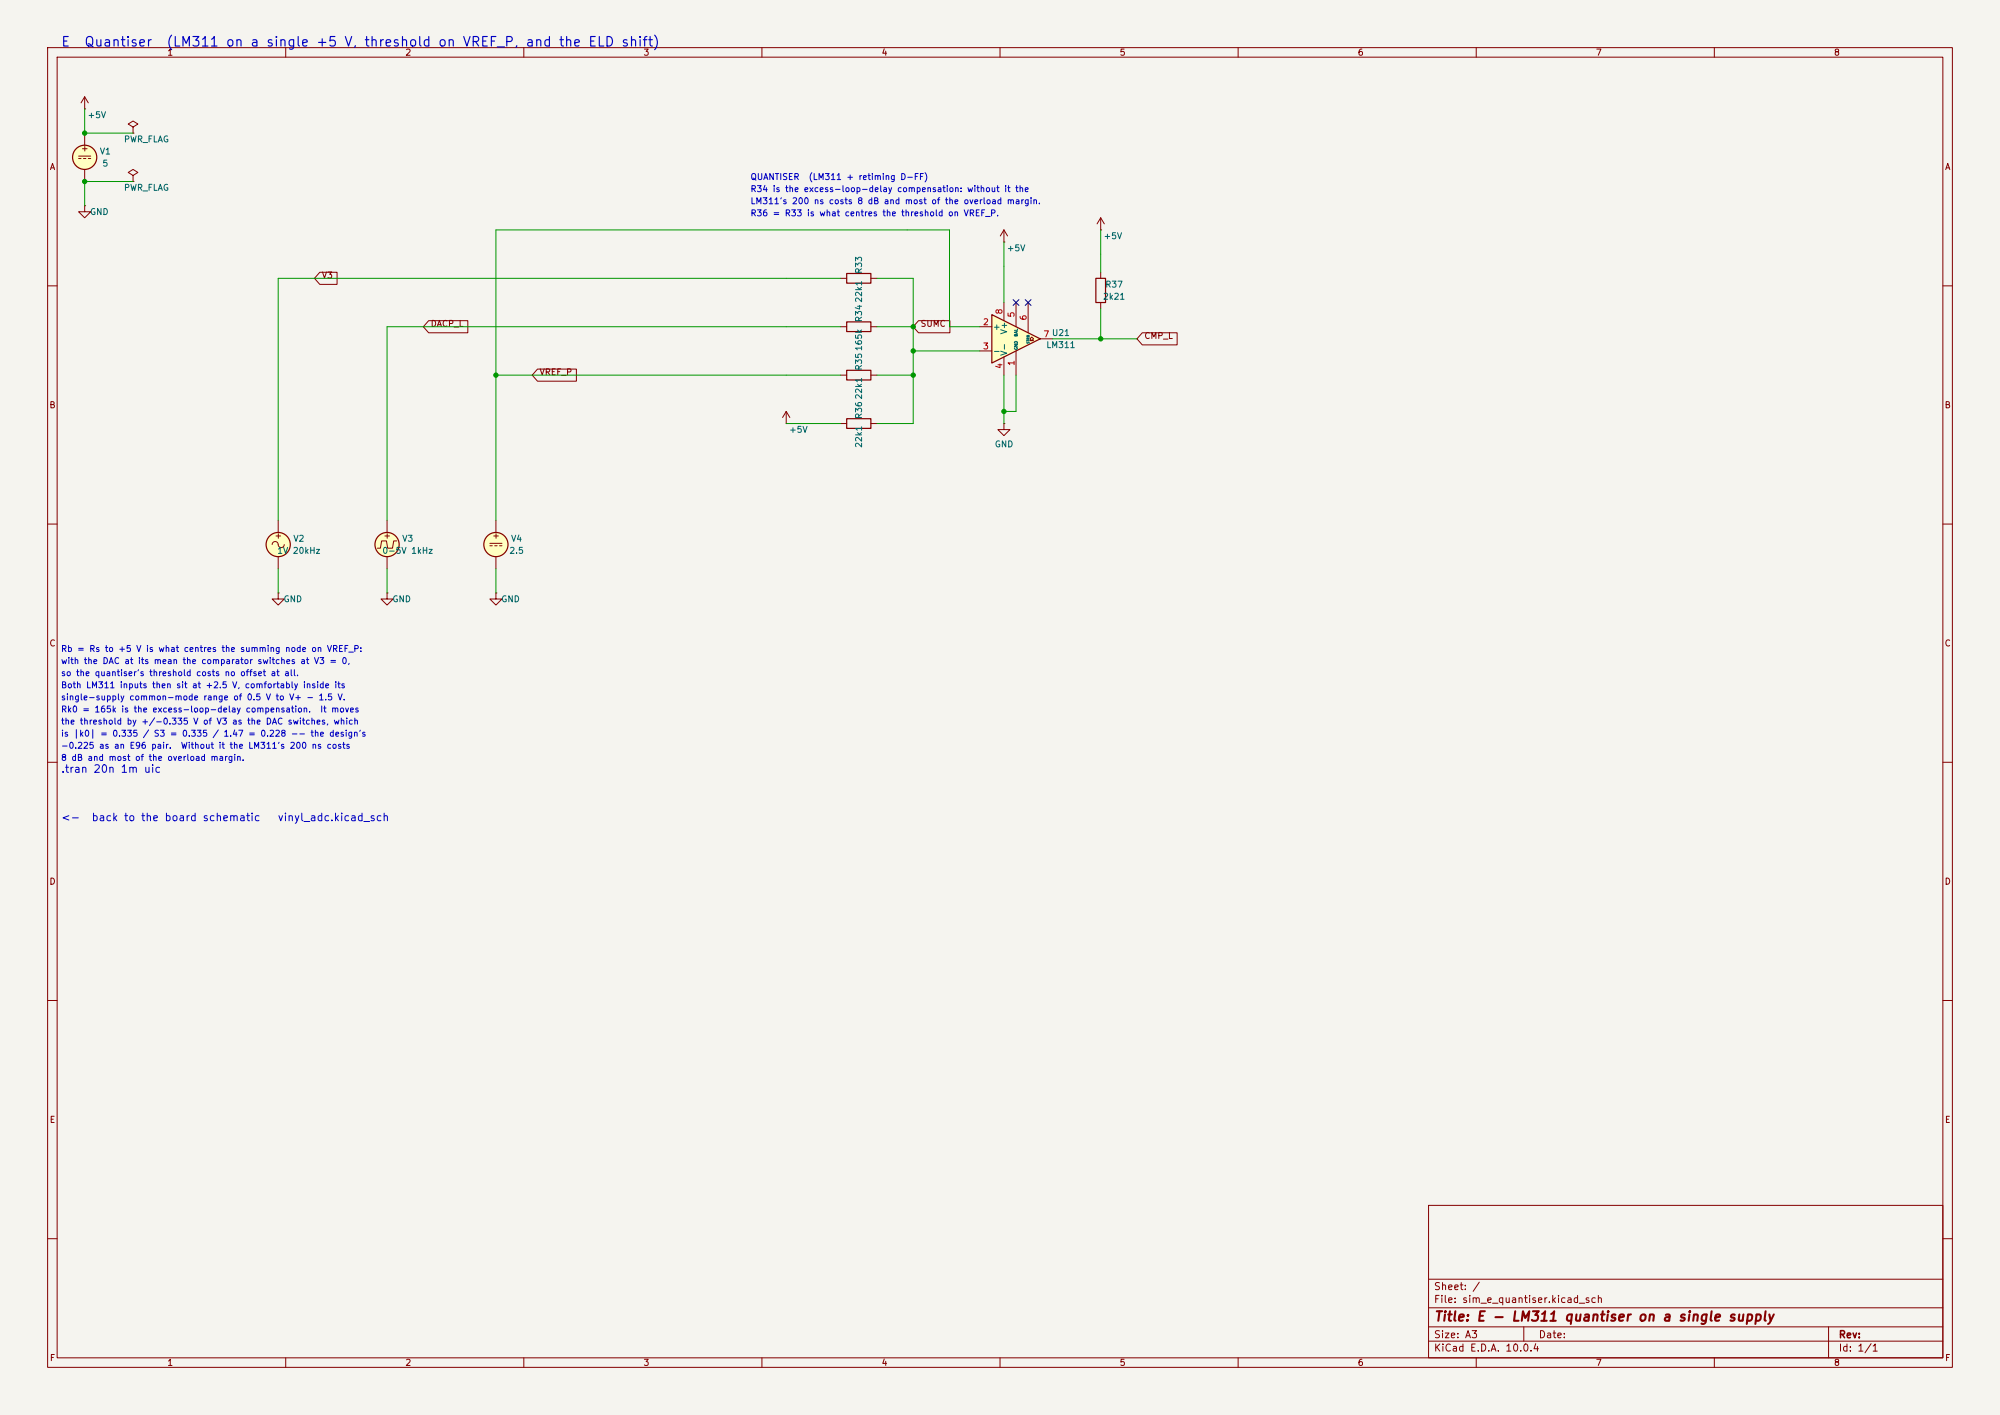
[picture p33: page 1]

E Quantiser (LM311 on a single +5 V, threshold on VREF_P, and the ELD shift)

QUANTISER (LM311 + retiming D-FF) so the quantiser's threshold costs no offset at all. .tran 20n 1m uic

R34 is the excess-loop-delay compensation: without it the

Rk0 = 165k is the excess-loop-delay compensation. It moves with the DAC at its mean the comparator switches at V3 = 0, Rb = Rs to +5 V is what centres the summing node on VREF_P: single-supply common-mode range of 0.5 V to V+ - 1.5 V. Both LM311 inputs then sit at +2.5 V, comfortably inside its

the threshold by +/-0.335 V of V3 as the DAC switches, which
is |k0| = 0.335 / S3 = 0.335 / 1.47 = 0.228 -- the design's

Sheet: /
File: sim_e_quantiser.kicad_sch
Title: E - LM311 quantiser on a single supply

Size: A3 | Rev:
KiCad E.D.A. 10.0.4 | Id: 1/1 | F Date:

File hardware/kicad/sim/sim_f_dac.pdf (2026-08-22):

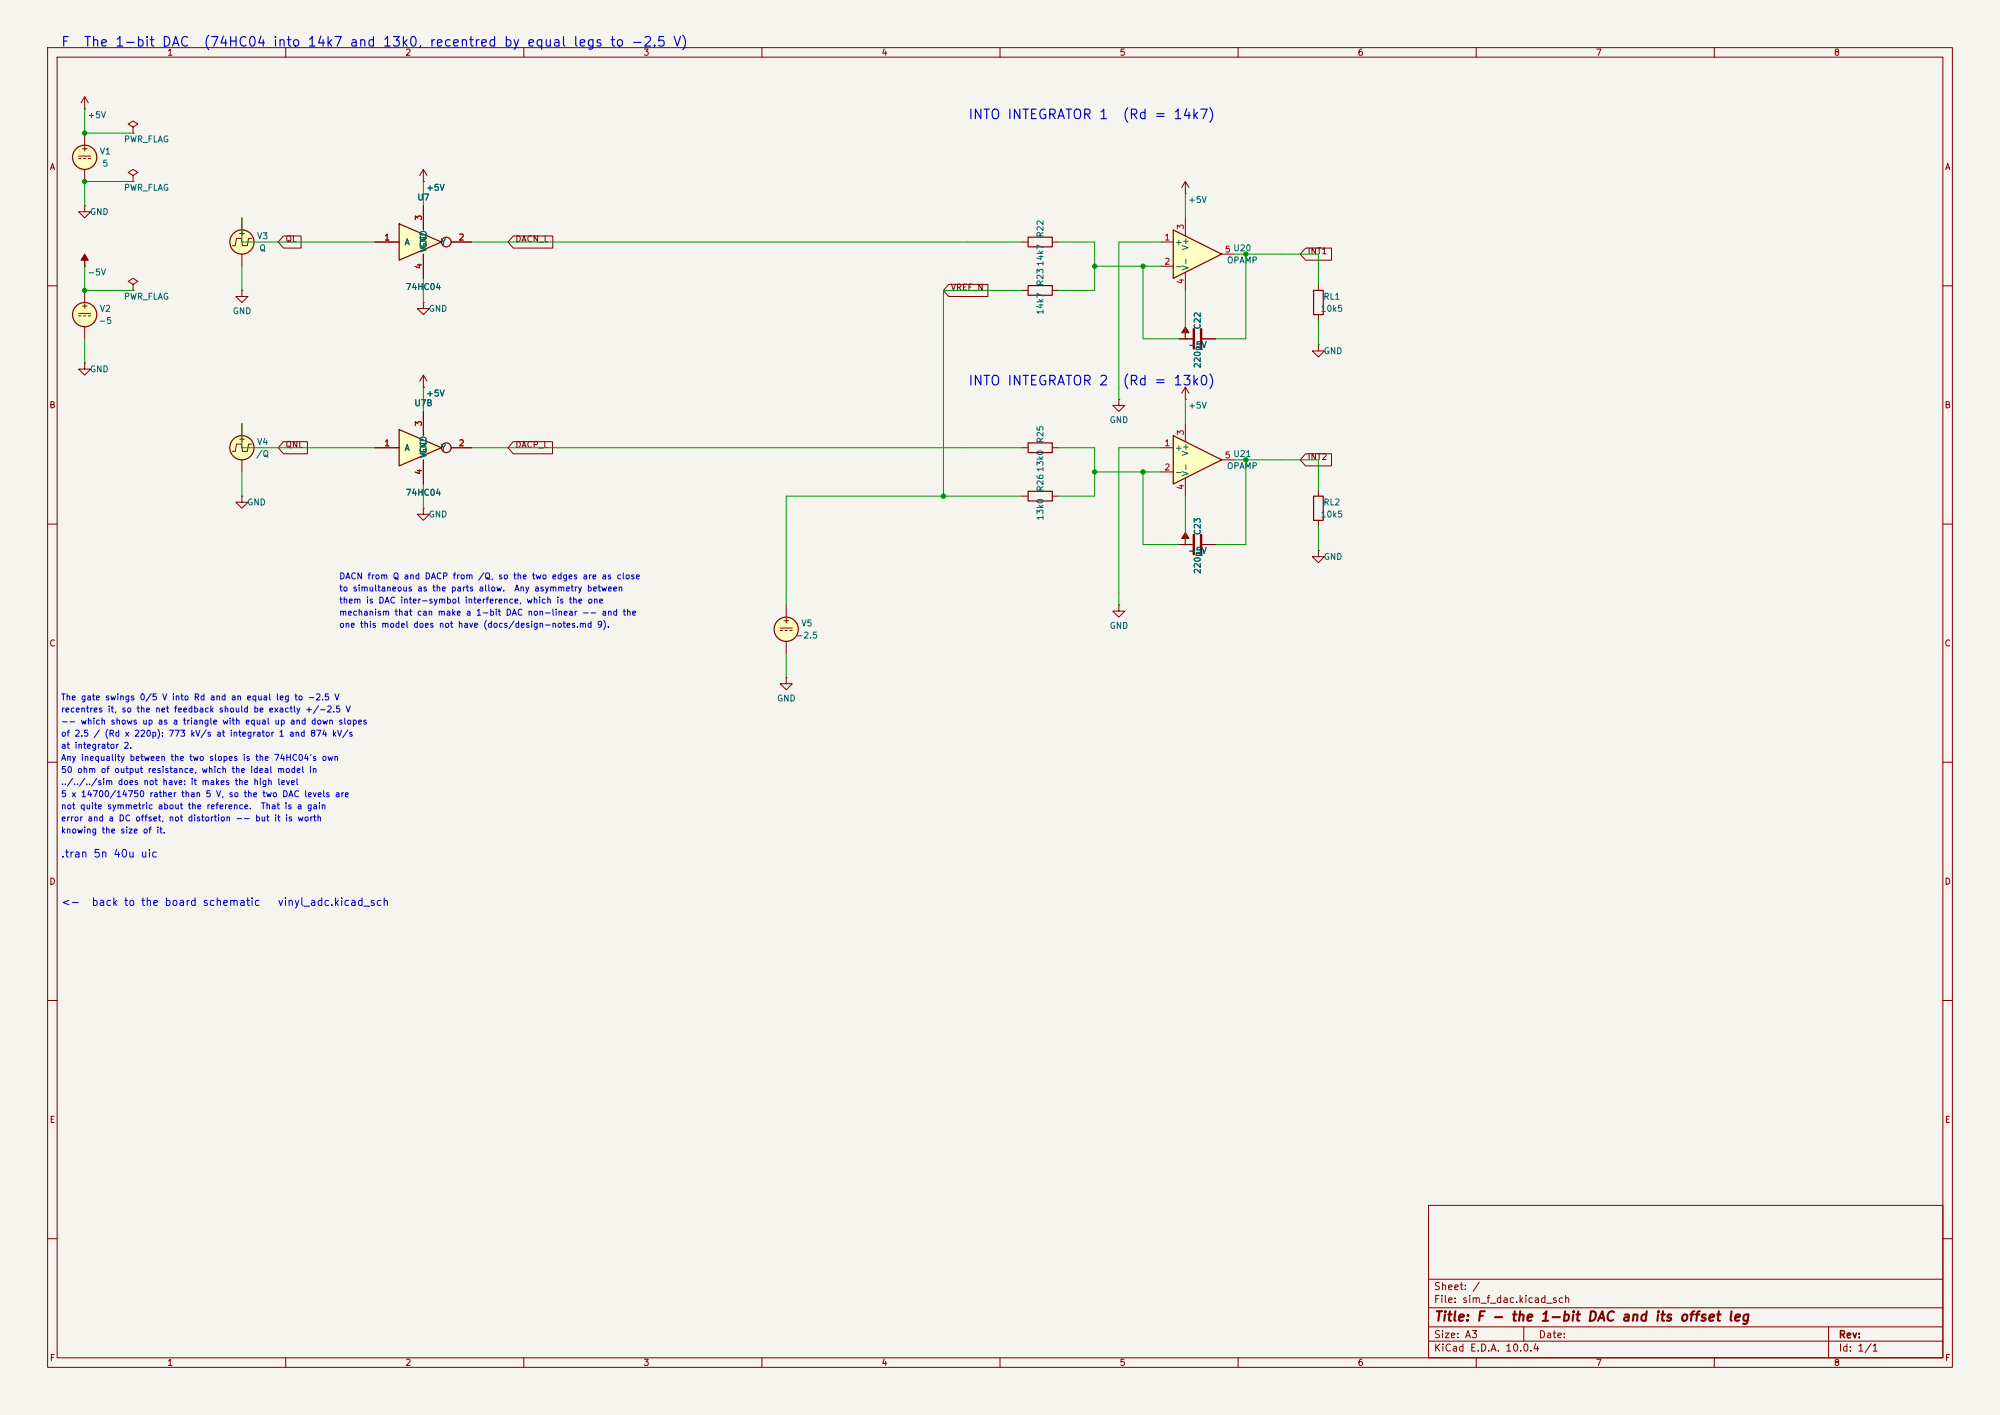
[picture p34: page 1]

F The 1-bit DAC (74HC04 into 14k7 and 13k0, recentred by equal legs to -2.5 V)

DACN from Q and DACP from /Q, so the two edges are as close one this model does not have (docs/design-notes.md 9). at integrator 2. The gate swings 0/5 V into Rd and an equal leg to -2.5 V

to simultaneous as the parts allow. Any asymmetry between
them is DAC inter-symbol interference, which is the one

of 2.5 / (Rd x 220p): 773 kV/s at integrator 1 and 874 kV/s 5 x 14700/14750 rather than 5 V, so the two DAC levels aremechanism that can make a 1-bit DAC non-linear -- and the

recentres it, so the net feedback should be exactly +/-2.5 V -- which shows up as a triangle with equal up and down slopes

Any inequality between the two slopes is the 74HC04's own 50 ohm of output resistance, which the ideal model in

not quite symmetric about the reference. That is a gain
knowing the size of it. .tran 5n 40u uic

Sheet: /
File: sim_f_dac.kicad_sch
Title: F - the 1-bit DAC and its offset leg

Size: A3 | Rev:
KiCad E.D.A. 10.0.4 | Id: 1/1 | F Date:

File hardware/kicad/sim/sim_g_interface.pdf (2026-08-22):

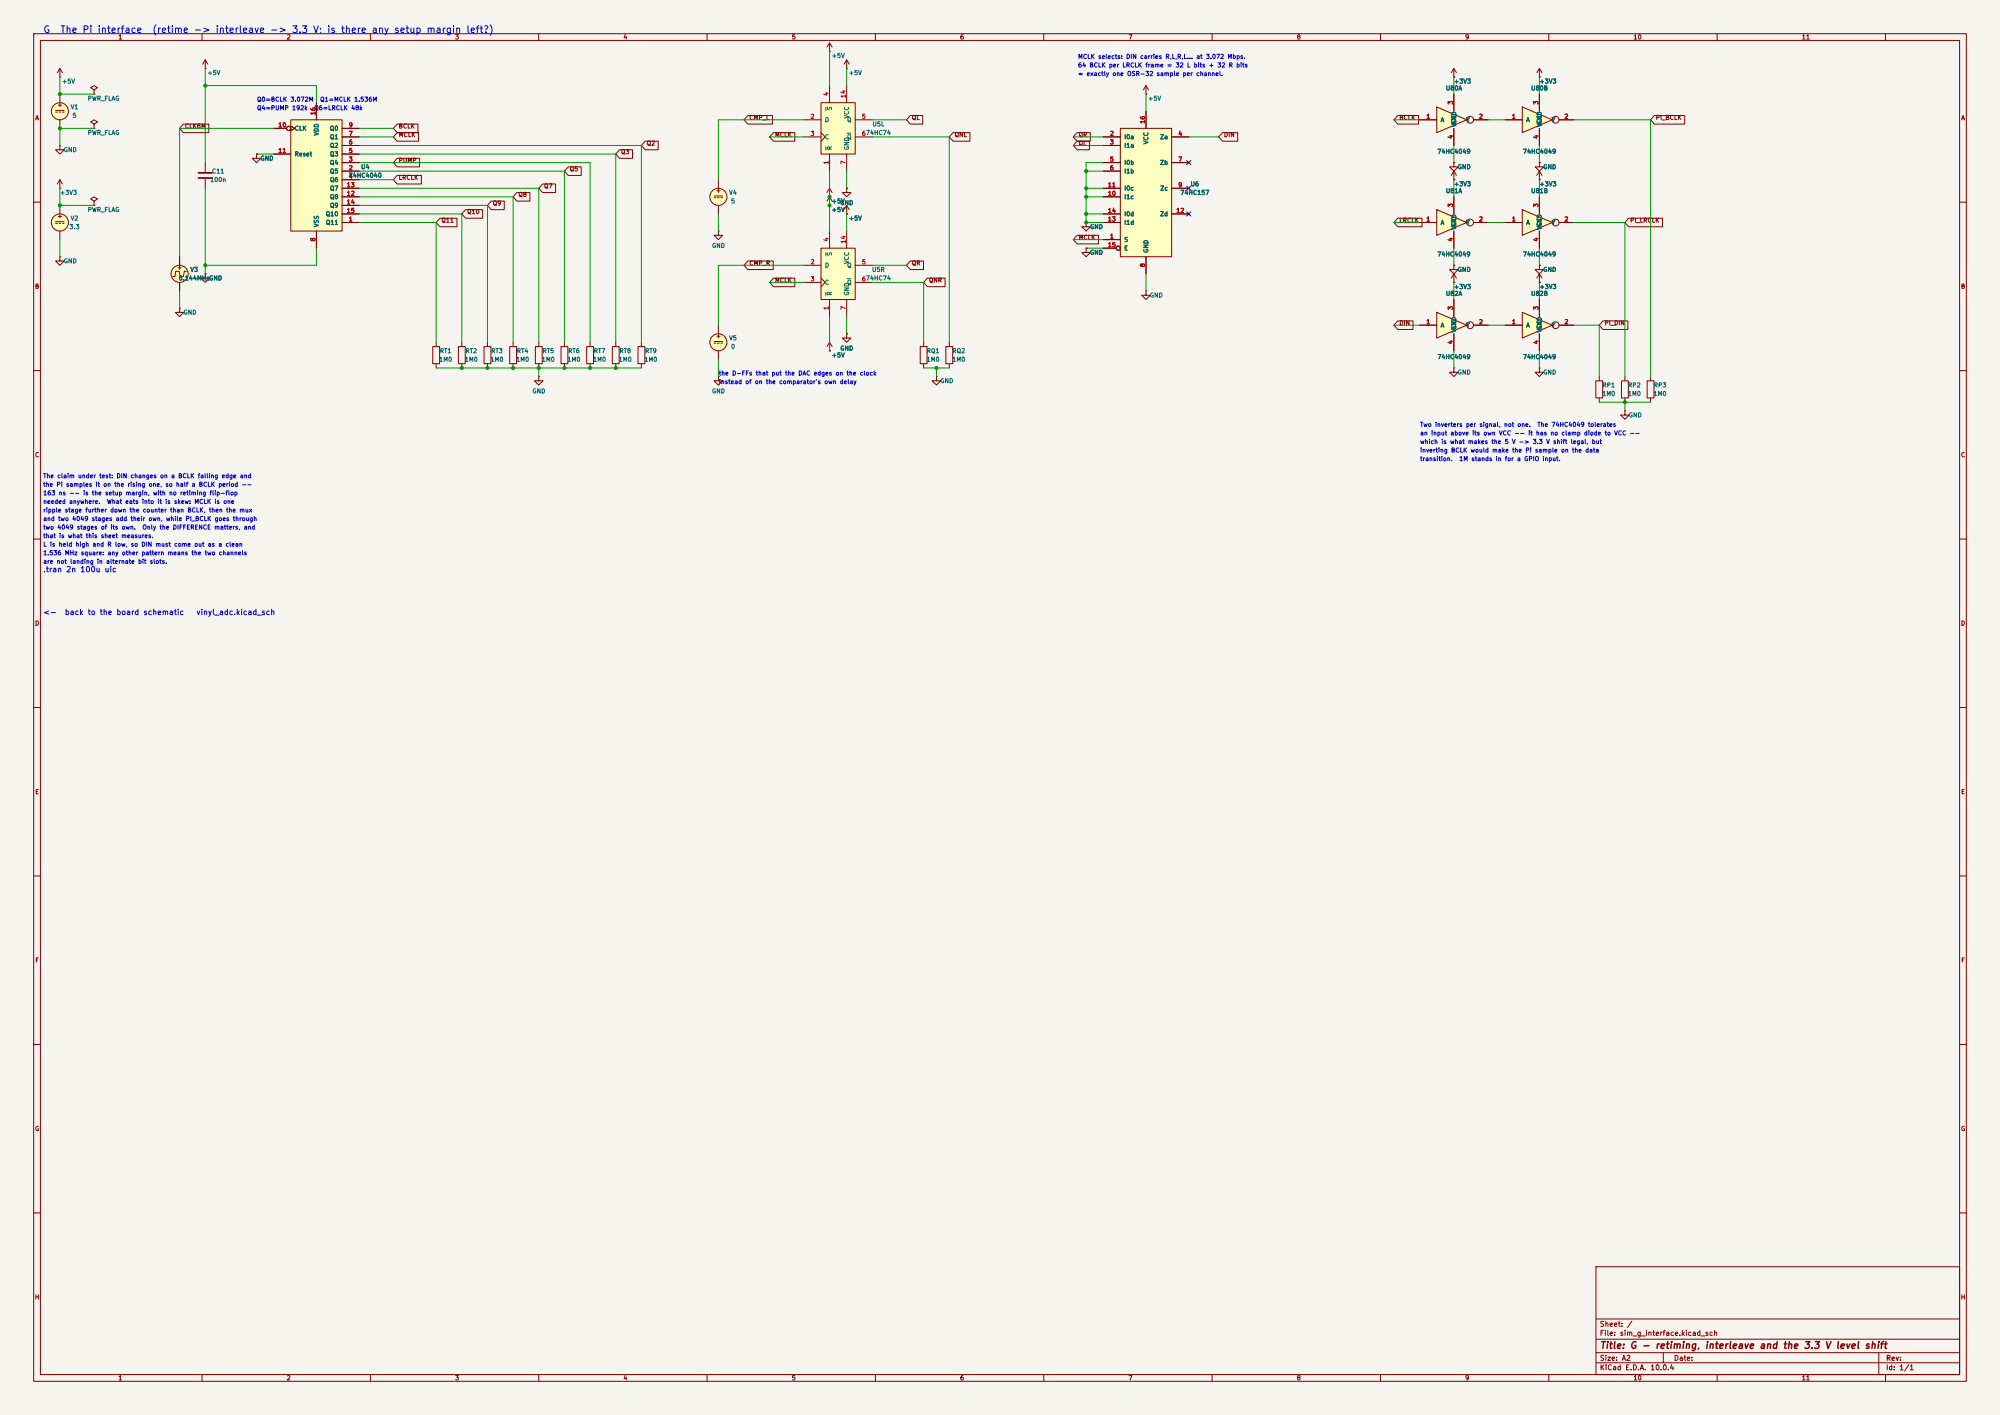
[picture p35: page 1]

Two inverters per signal, not one. The 74HC4049 tolerates an input above its own VCC -- it has no clamp diode to VCC --

which is what makes the 5 V -> 3.3 V shift legal, but
inverting BCLK would make the Pi sample on the data

transition. 1M stands in for a GPIO input. two 4049 stages of its own. Only the DIFFERENCE matters, and

The claim under test: DIN changes on a BCLK falling edge and
the Pi samples it on the rising one, so half a BCLK period --
163 ns -- is the setup margin, with no retiming flip-flop
that is what this sheet measures. needed anywhere. What eats into it is skew: MCLK is one
ripple stage further down the counter than BCLK, then the mux
and two 4049 stages add their own, while PI_BCLK goes through

are not landing in alternate bit slots. 1.536 MHz square: any other pattern means the two channels
.tran 2n 100u uic

Sheet: /
File: sim_g_interface.kicad_sch
Title: G - retiming, interleave and the 3.3 V level shift

Size: A2 | Rev:
KiCad E.D.A. 10.0.4 | Id: 1/1

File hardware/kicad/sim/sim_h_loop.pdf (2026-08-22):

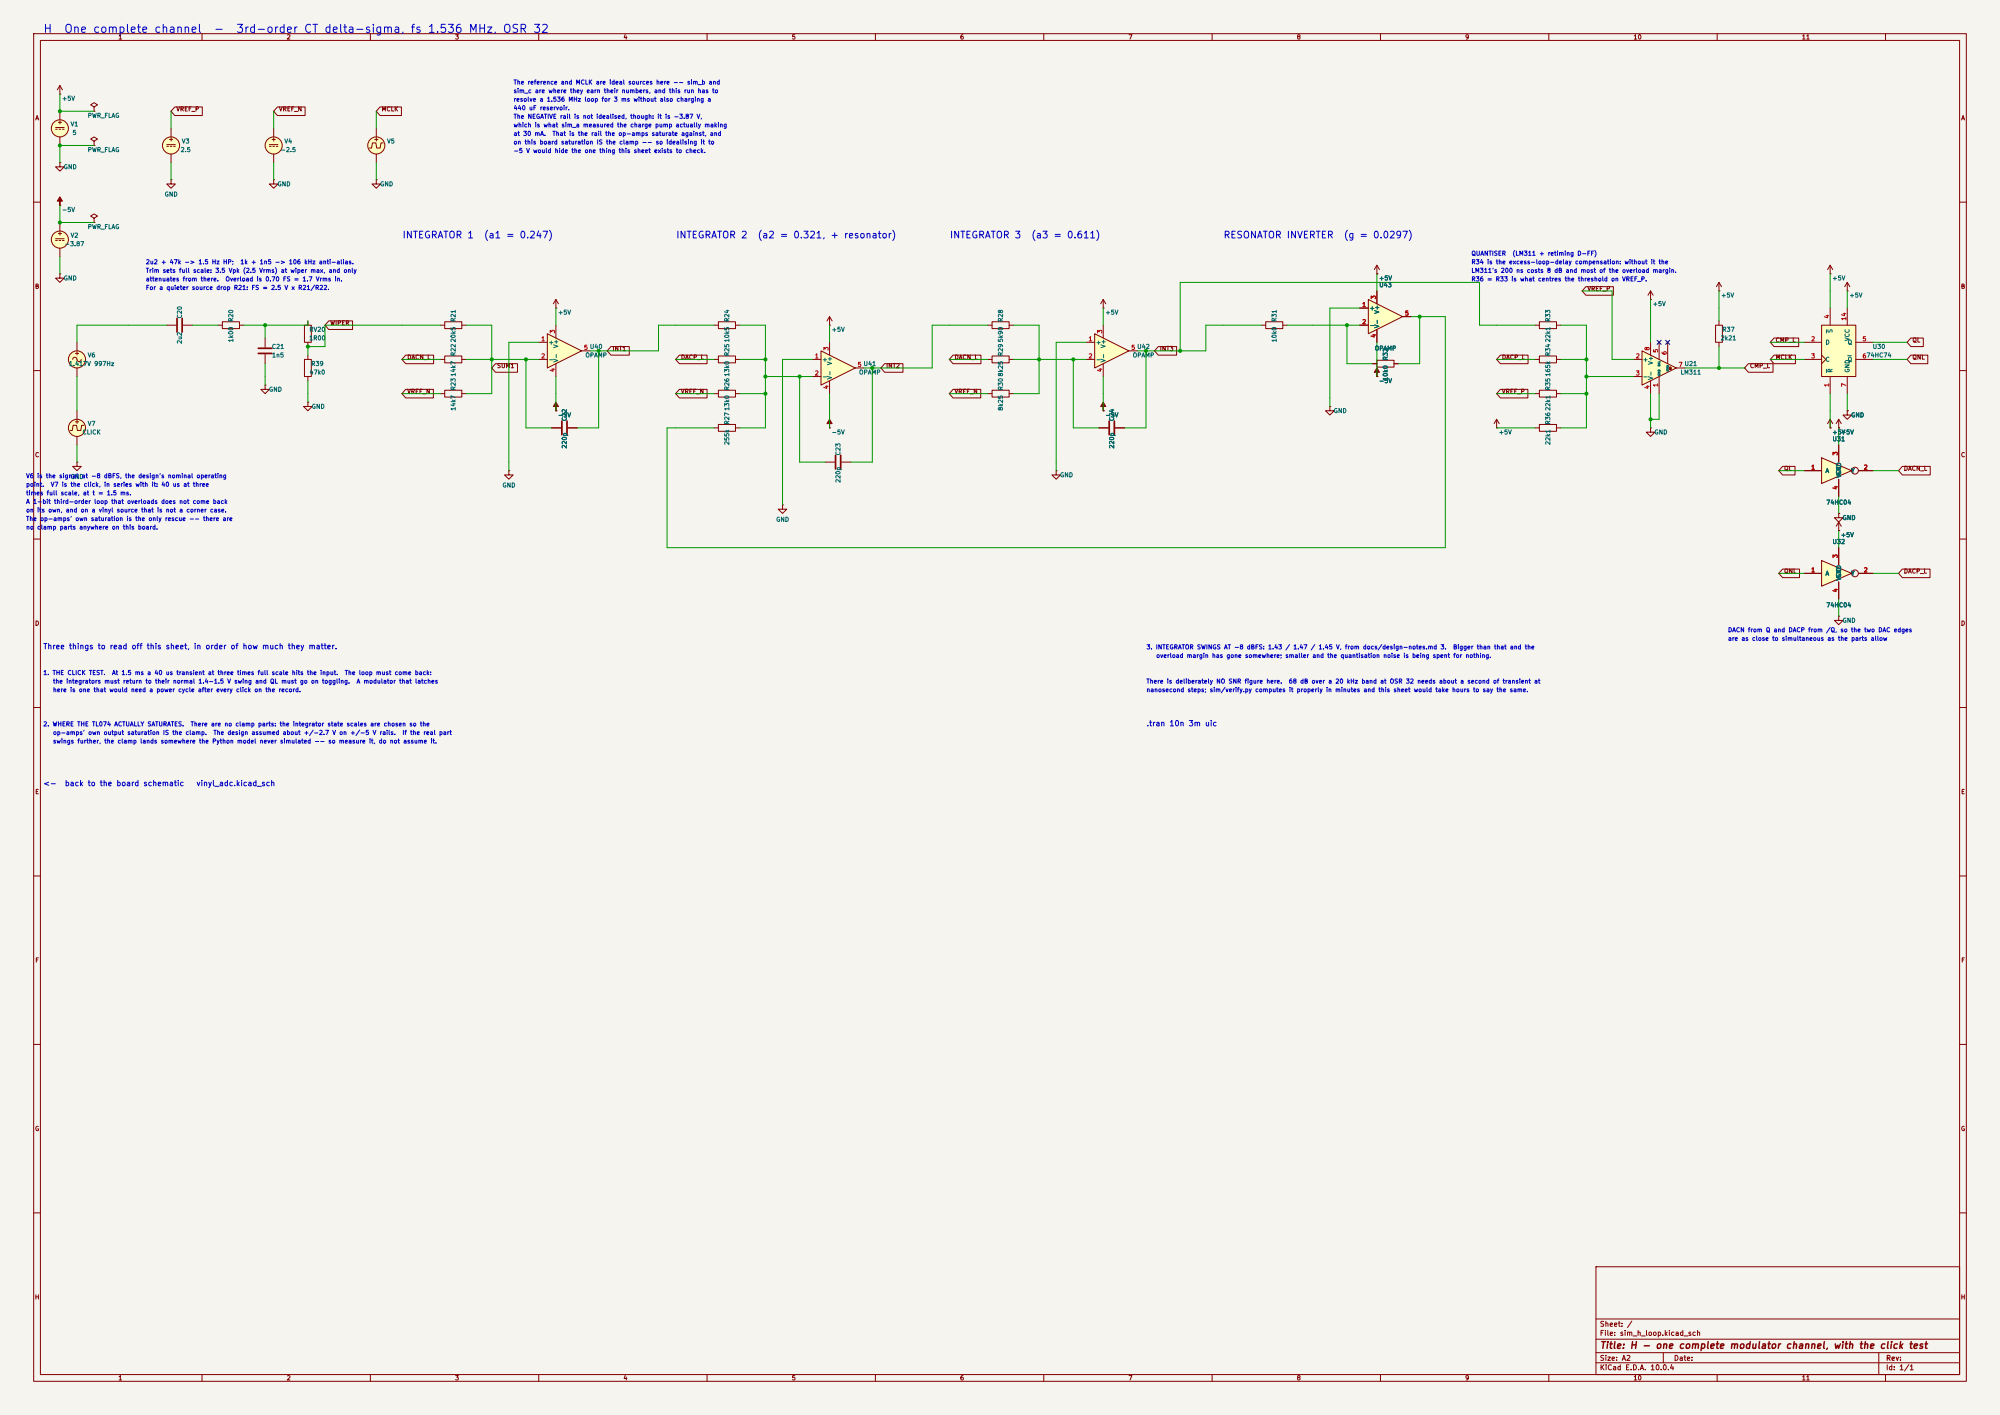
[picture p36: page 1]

H One complete channel - 3rd-order CT delta-sigma, fs 1.536 MHz, OSR 32

The reference and MCLK are ideal sources here -- sim_b and
sim_c are where they earn their numbers, and this run has to
resolve a 1.536 MHz loop for 3 ms without also charging a
The NEGATIVE rail is not idealised, though: it is -3.87 V,

Trim sets full scale: 3.5 Vpk (2.5 Vrms) at wiper max, and only 1. THE CLICK TEST. At 1.5 ms a 40 us transient at three times full scale hits the input. The loop must come back:

attenuates from there. Overload is 0.70 FS = 1.7 Vrms in.

V6 is the signal at -8 dBFS, the design's nominal operating
times full scale, at t = 1.5 ms. point. V7 is the click, in series with it: 40 us at three

no clamp parts anywhere on this board. The op-amps' own saturation is the only rescue -- there are

3. INTEGRATOR SWINGS AT -8 dBFS: 1.43 / 1.47 / 1.45 V, from docs/design-notes.md 3. Bigger than that and the overload margin has gone somewhere; smaller and the quantisation noise is being spent for nothing. There is deliberately NO SNR figure here. 68 dB over a 20 kHz band at OSR 32 needs about a second of transient at nanosecond steps; sim/verify.py computes it properly in minutes and this sheet would take hours to say the same. .tran 10n 3m uic

the integrators must return to their normal 1.4-1.5 V swing and QL must go on toggling. A modulator that latches

swings further, the clamp lands somewhere the Python model never simulated -- so measure it, do not assume it. op-amps' own output saturation IS the clamp. The design assumed about +/-2.7 V on +/-5 V rails. If the real part 2. WHERE THE TL074 ACTUALLY SATURATES. There are no clamp parts: the integrator state scales are chosen so the

Sheet: /
File: sim_h_loop.kicad_sch
Title: H - one complete modulator channel, with the click test

Size: A2 | Rev:
KiCad E.D.A. 10.0.4 | Id: 1/1

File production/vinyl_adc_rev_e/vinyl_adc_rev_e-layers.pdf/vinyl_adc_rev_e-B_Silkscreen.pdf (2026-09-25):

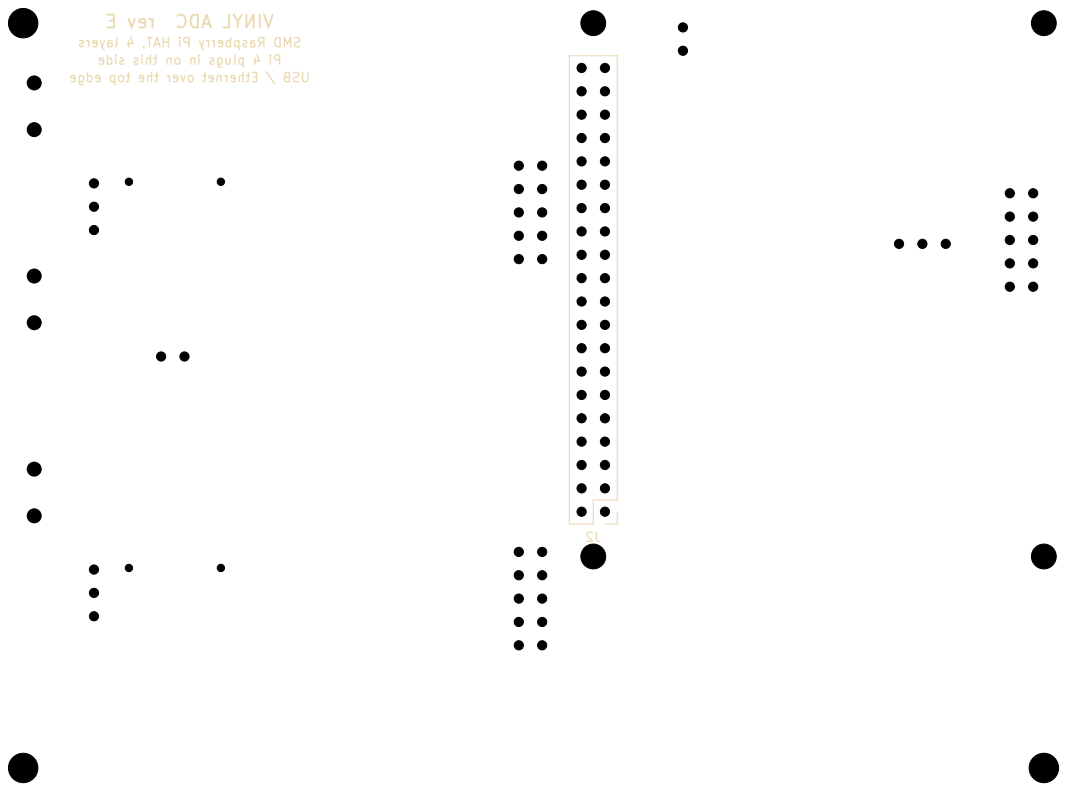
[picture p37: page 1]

layers 4 HAT, Pi Raspberry SMD side this on in plugs 4 Pi edge top the over Ethernet / USB E rev ADC VINYL

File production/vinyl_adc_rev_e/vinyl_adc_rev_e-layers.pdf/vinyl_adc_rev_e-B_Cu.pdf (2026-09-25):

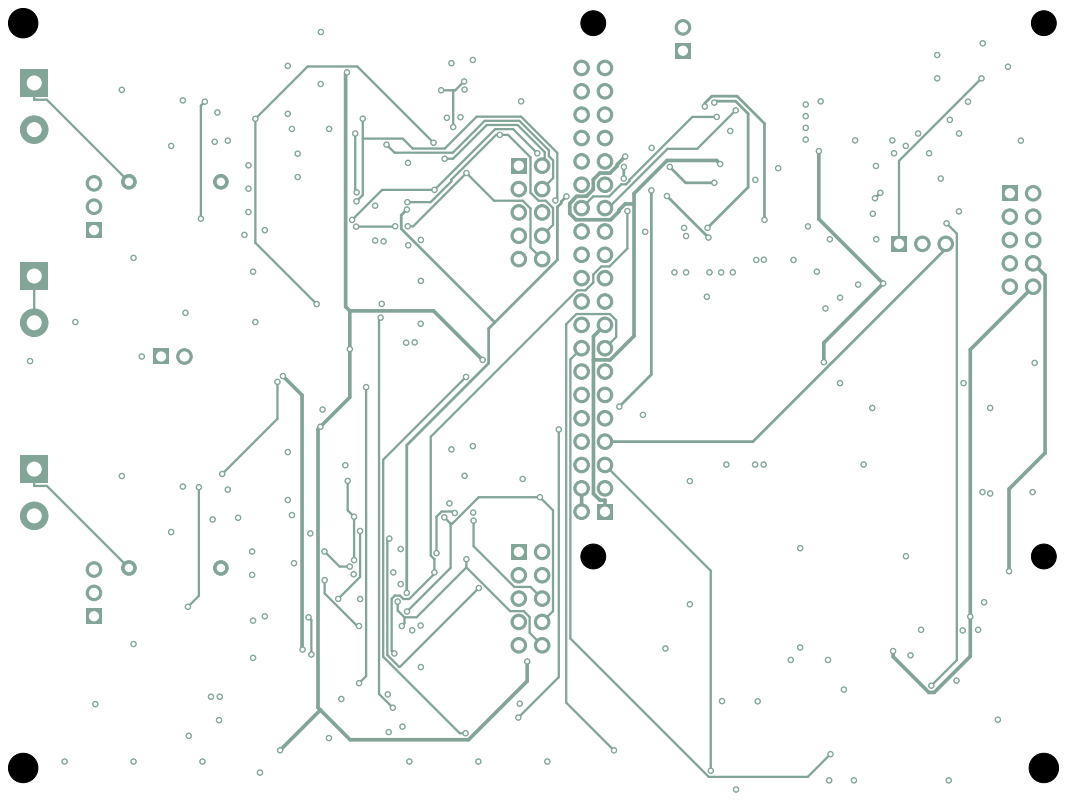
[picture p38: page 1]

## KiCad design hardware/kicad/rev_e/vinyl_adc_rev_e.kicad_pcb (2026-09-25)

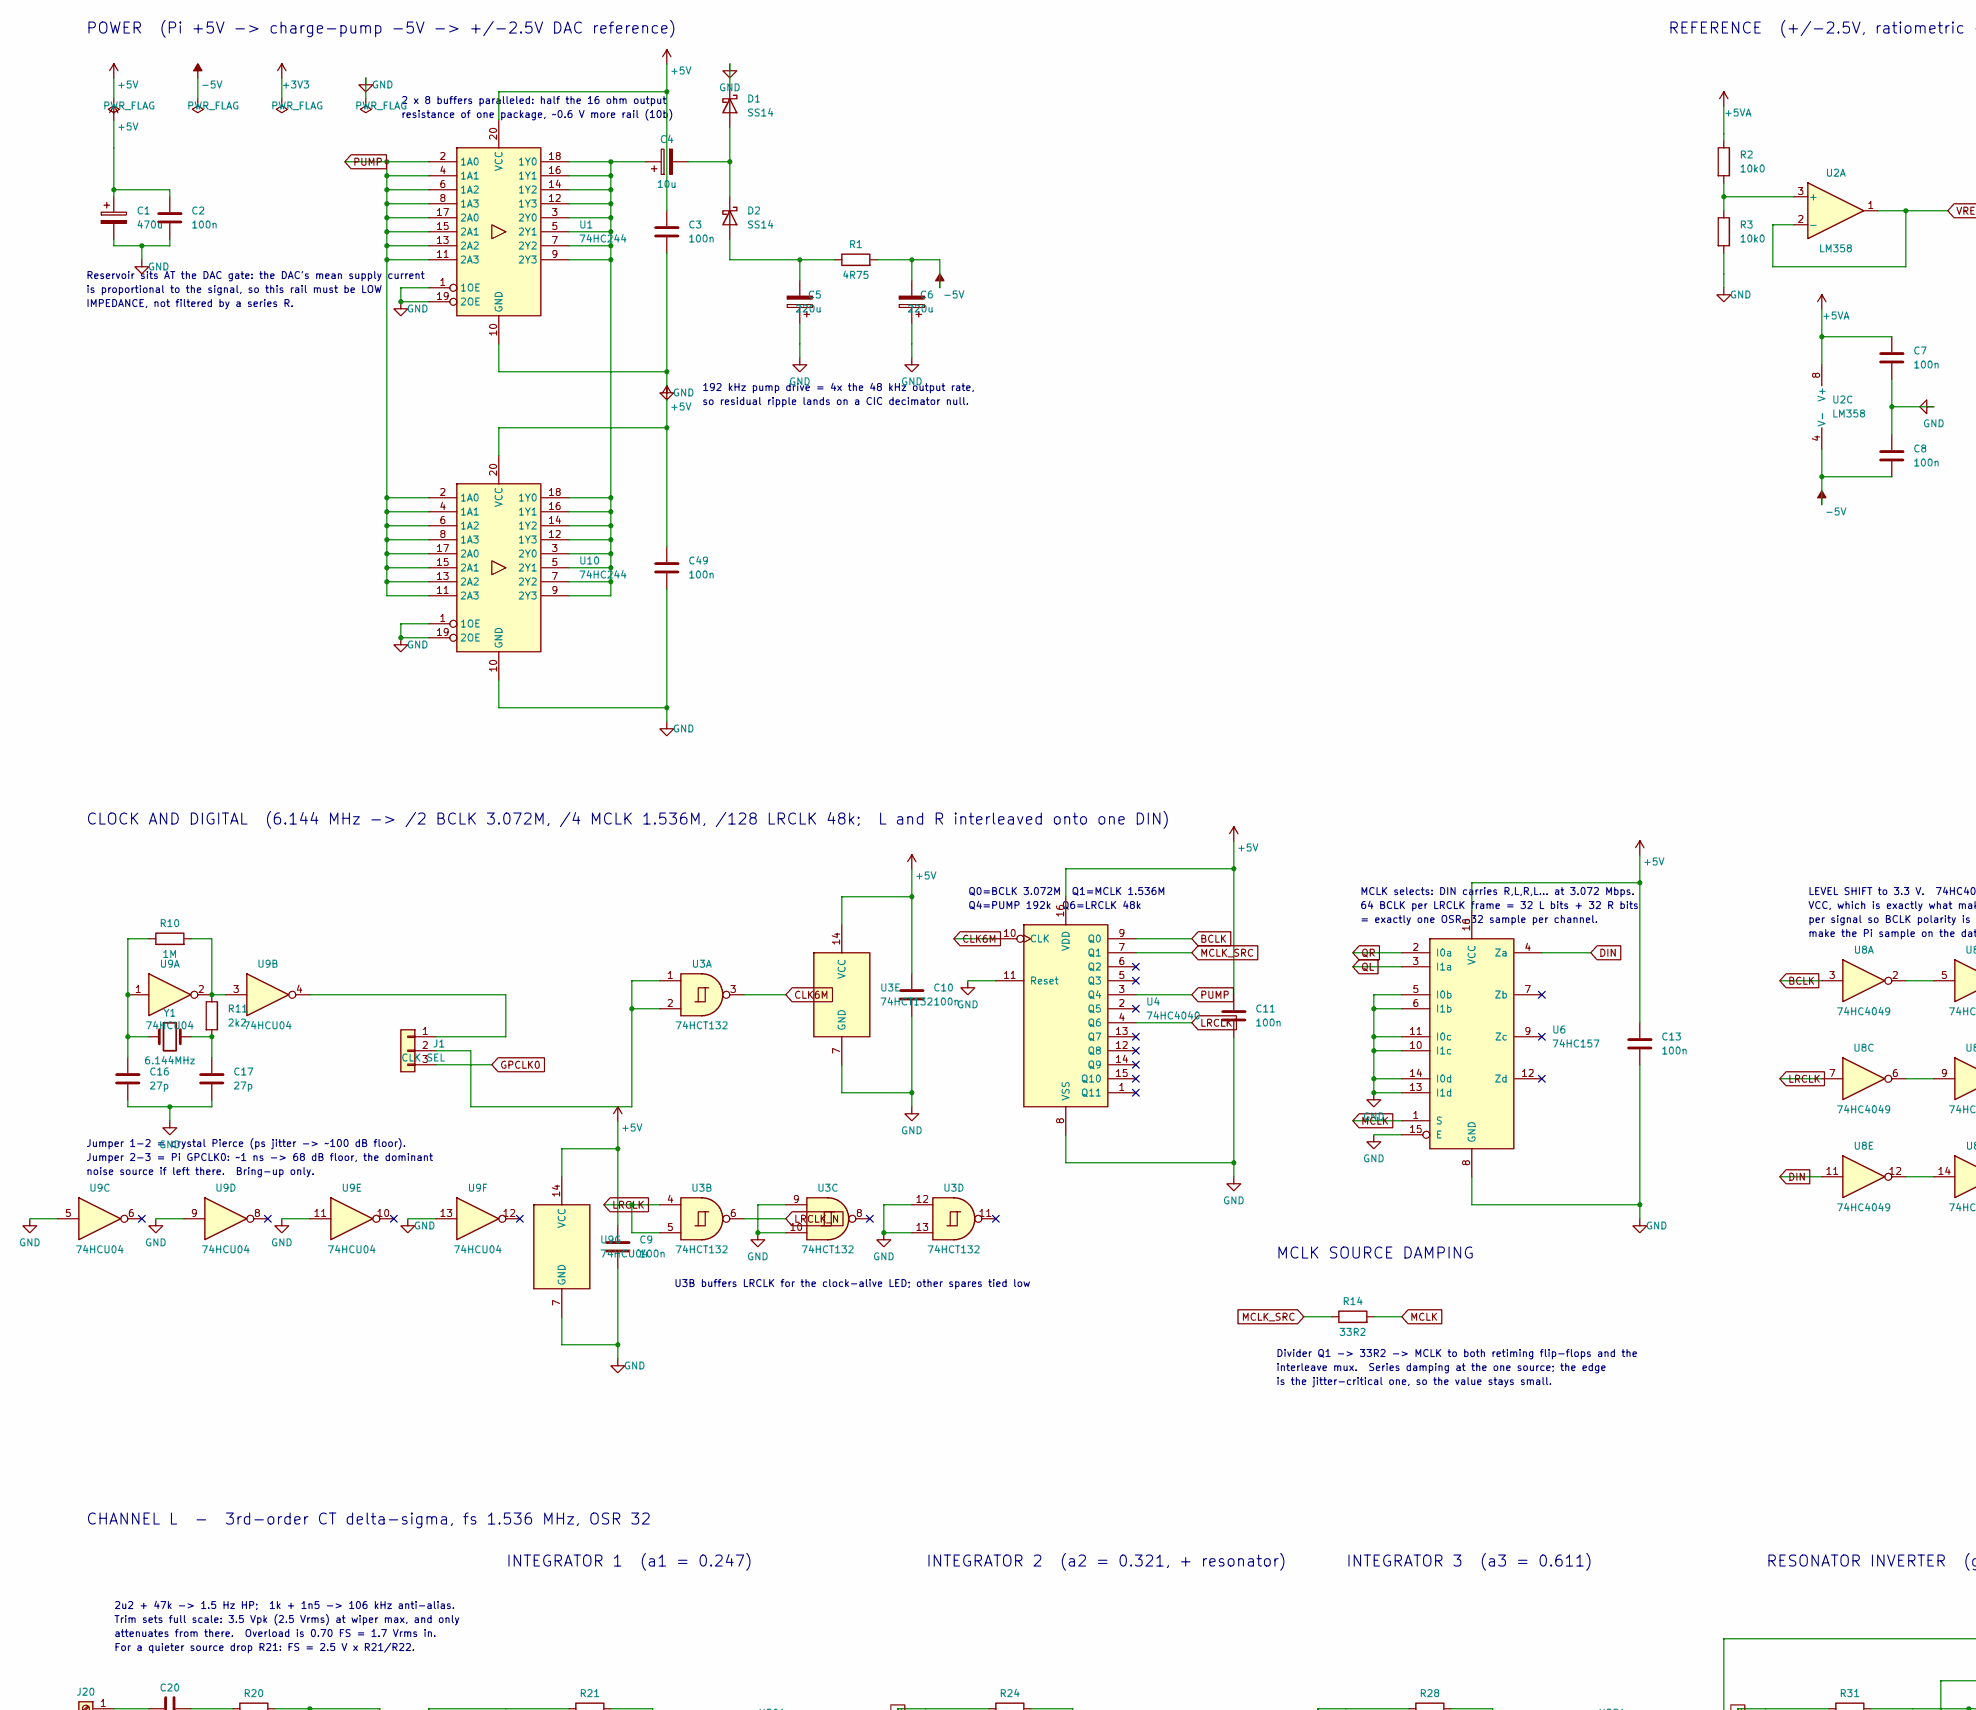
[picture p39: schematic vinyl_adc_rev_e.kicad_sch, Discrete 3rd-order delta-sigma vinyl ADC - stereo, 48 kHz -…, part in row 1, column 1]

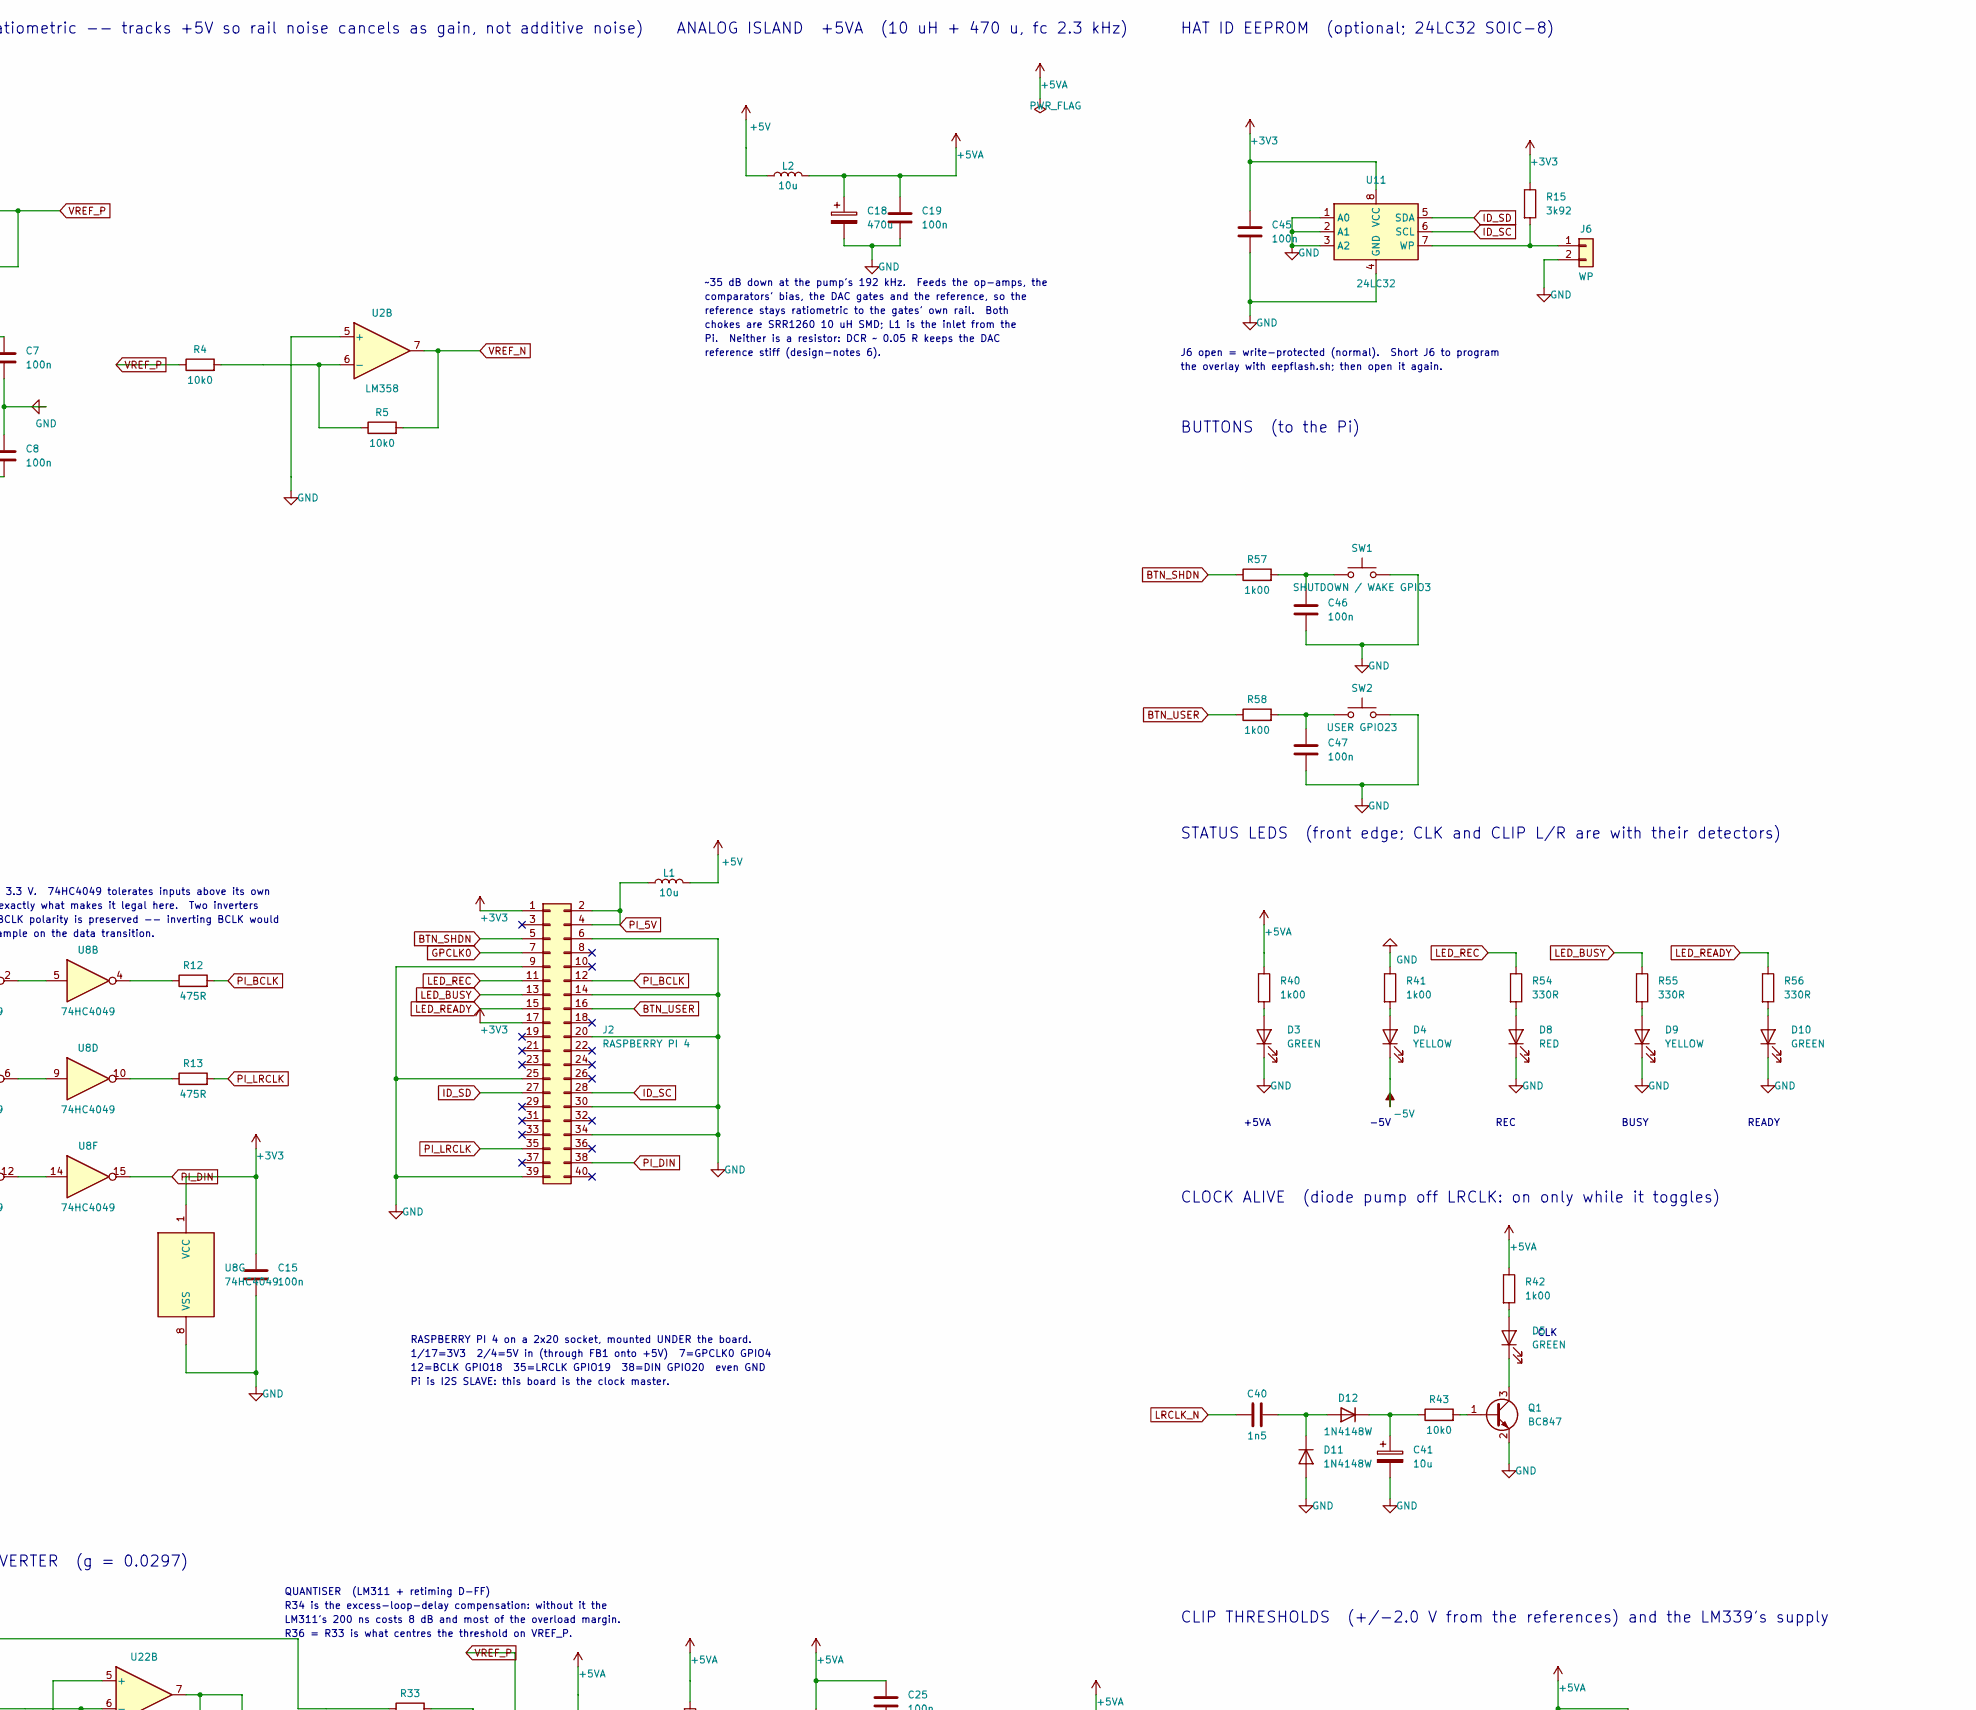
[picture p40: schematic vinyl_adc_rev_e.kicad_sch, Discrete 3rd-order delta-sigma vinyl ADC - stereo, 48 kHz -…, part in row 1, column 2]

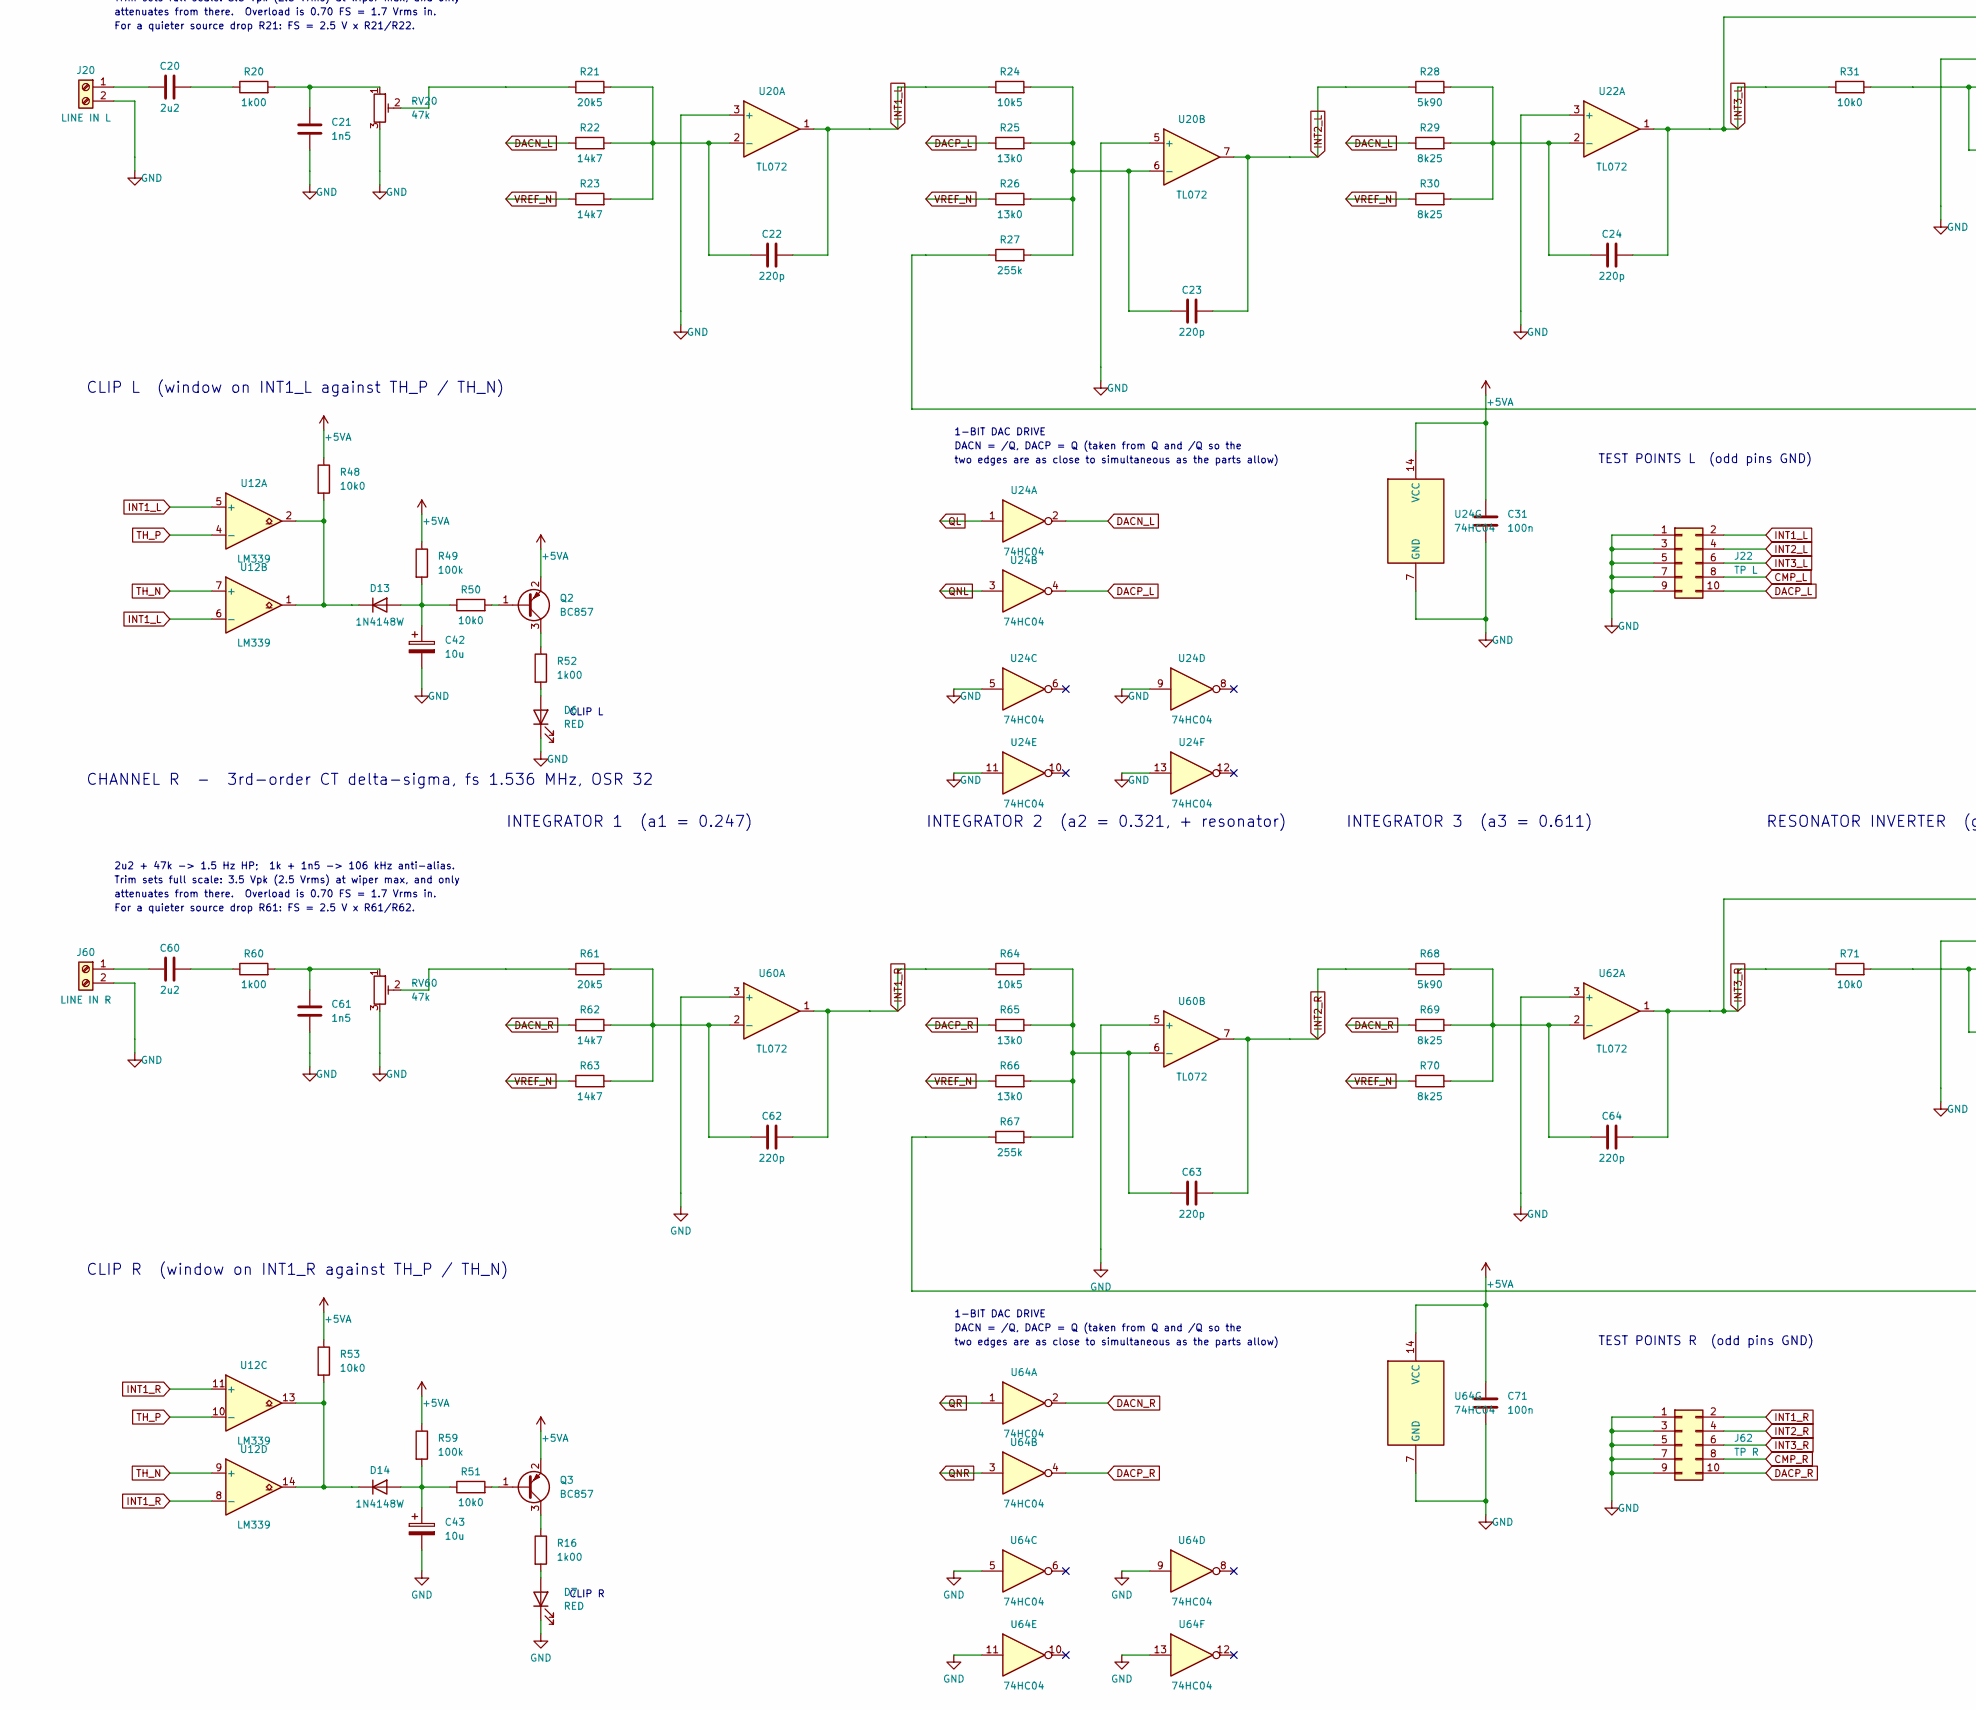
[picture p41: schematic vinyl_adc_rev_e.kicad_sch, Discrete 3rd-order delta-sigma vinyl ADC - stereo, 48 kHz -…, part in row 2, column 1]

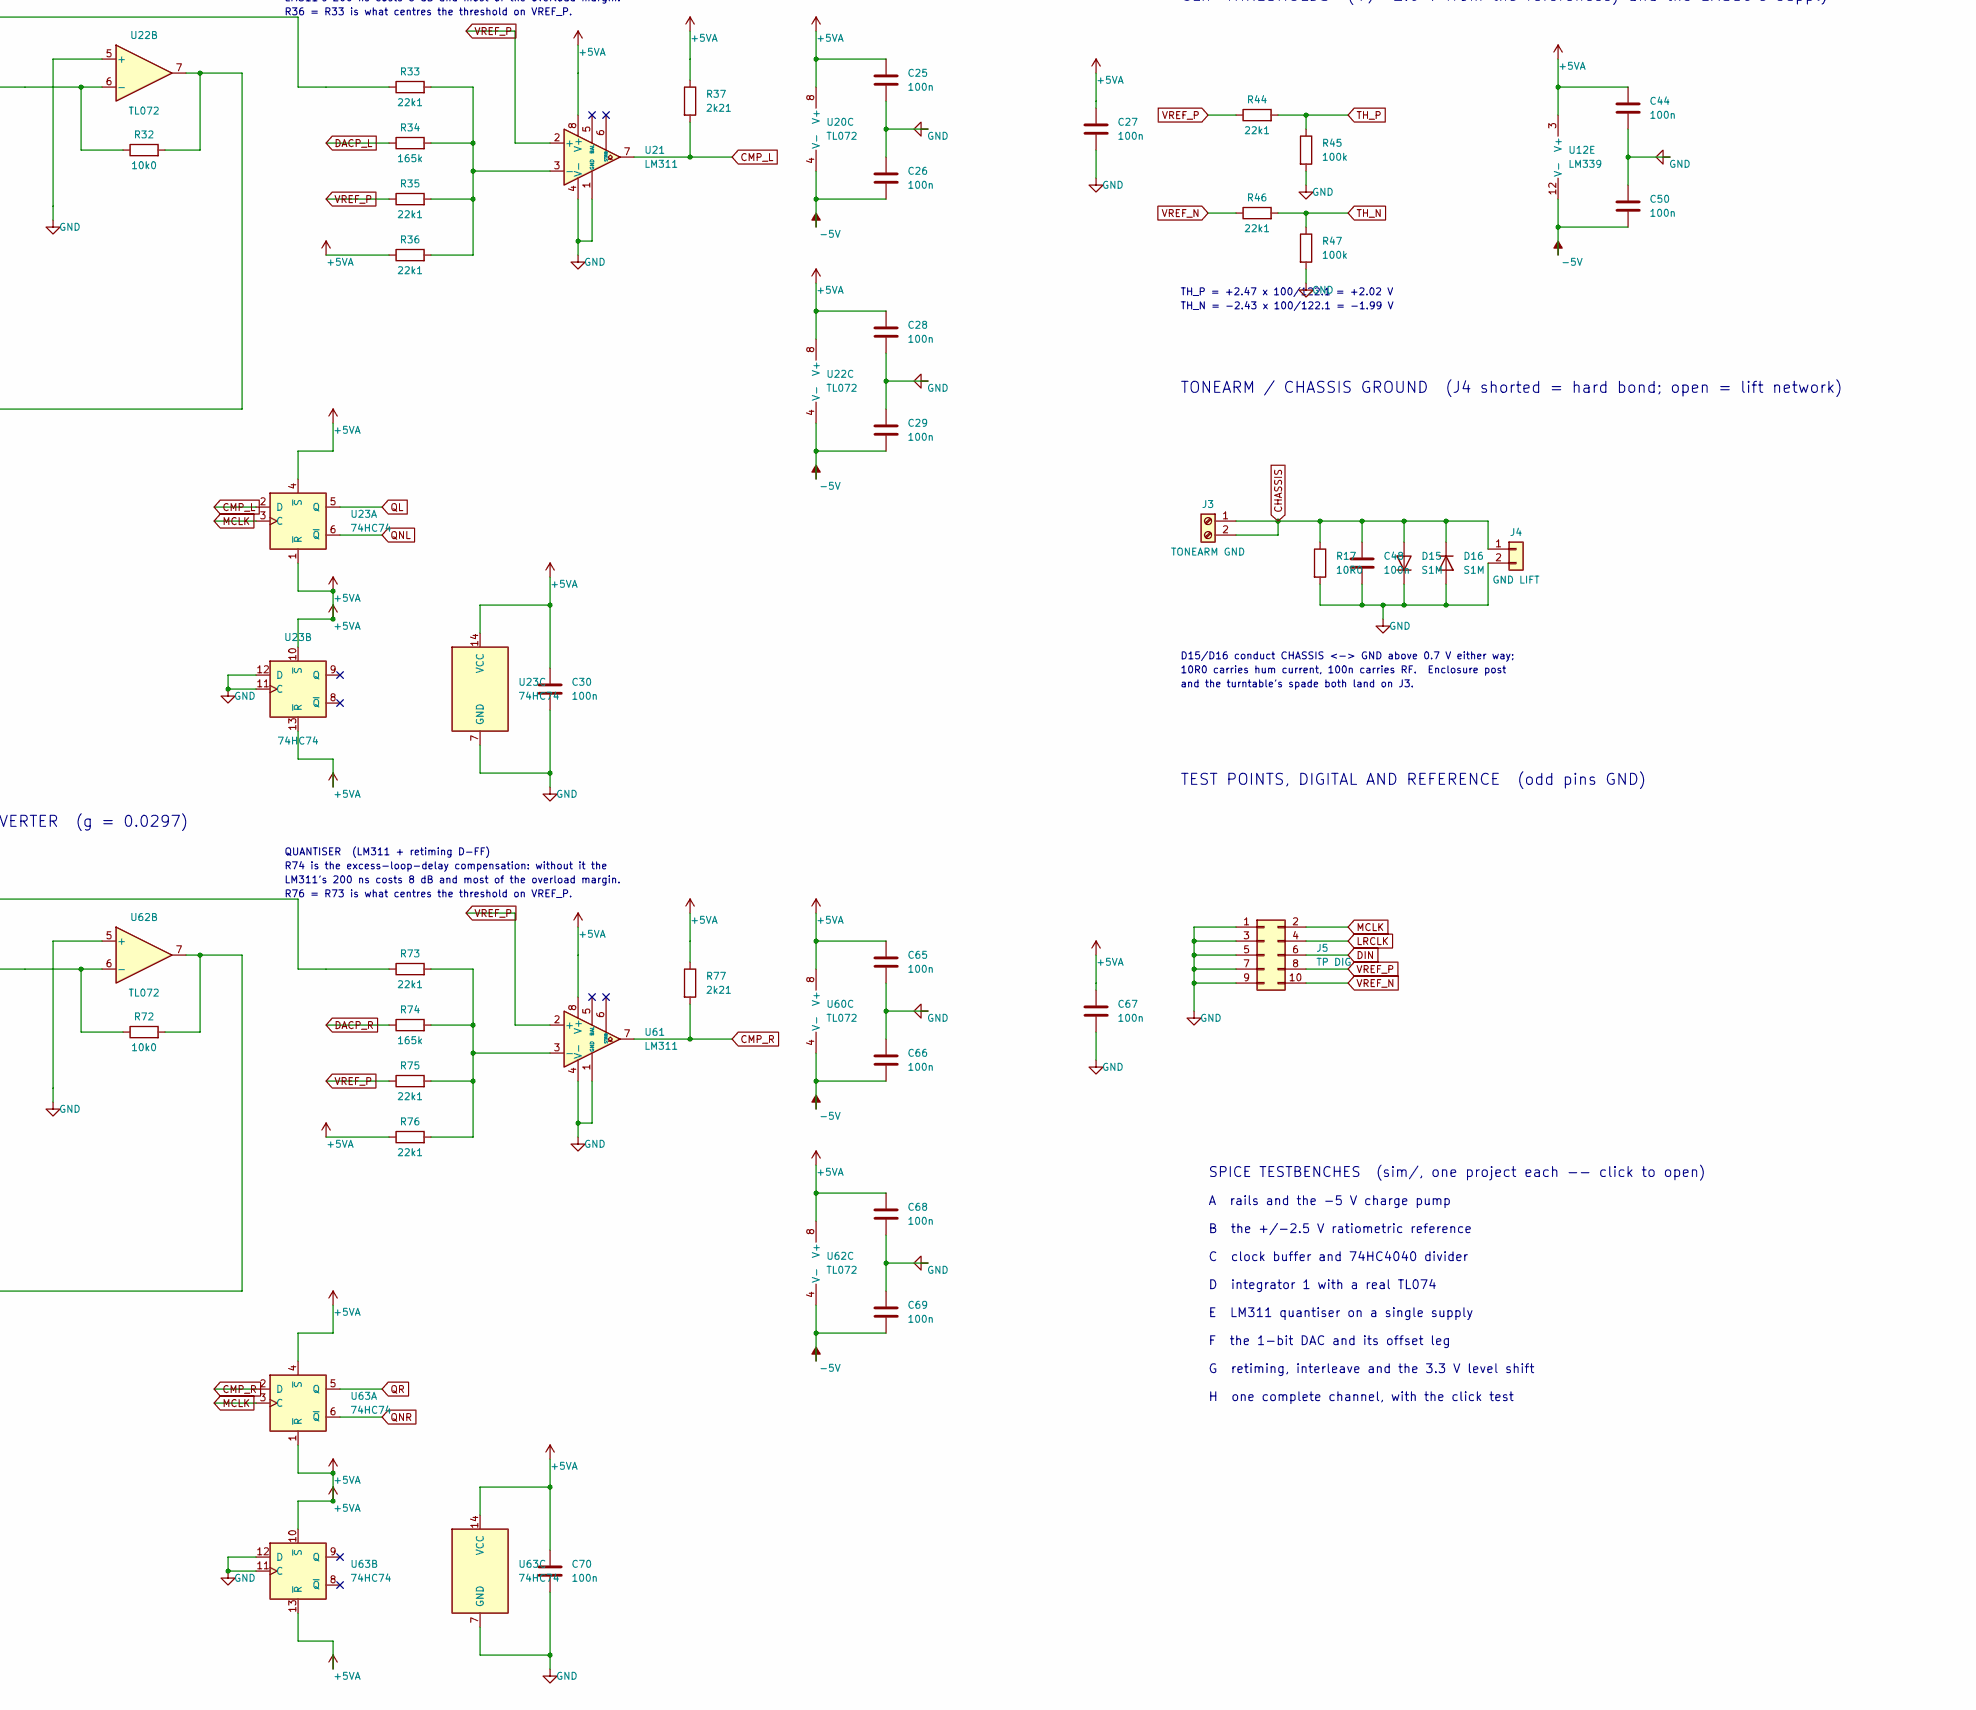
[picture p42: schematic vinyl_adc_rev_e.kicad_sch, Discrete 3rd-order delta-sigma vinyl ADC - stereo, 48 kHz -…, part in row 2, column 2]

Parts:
C1, C18: 470u; CP_Elec_8x10
C2, C3, C7, C8, C9, C10, C11, C13, C15, C19, C25, C26, C27, C28, C29, C30, C31, C44, C45, C46, C47, C48, C49, C50, C65, C66, C67, C68, C69, C70, C71: 100n; C_0805_2012Metric_Pad1.18x1.45mm_HandSolder
C4, C41, C42, C43: 10u; C_1206_3216Metric_Pad1.33x1.80mm_HandSolder
C5, C6: 220u; CP_Elec_6.3x7.7
C16, C17: 27p; C_0805_2012Metric_Pad1.18x1.45mm_HandSolder
C20, C60: 2u2; C_Rect_L11.0mm_W6.3mm_P10.00mm_MKT
C21, C40, C61: 1n5; C_0805_2012Metric_Pad1.18x1.45mm_HandSolder
C22, C23, C24, C62, C63, C64: 220p; C_0805_2012Metric_Pad1.18x1.45mm_HandSolder
D1, D2: SS14; D_SMA
D3, D5, D10: GREEN; LED_0805_2012Metric_Pad1.15x1.40mm_HandSolder
D4, D9: YELLOW; LED_0805_2012Metric_Pad1.15x1.40mm_HandSolder
D6, D7, D8: RED; LED_0805_2012Metric_Pad1.15x1.40mm_HandSolder
D11, D12, D13, D14: 1N4148W; D_SOD-123
D15, D16: S1M; D_SMA
J1: CLK SEL; PinHeader_1x03_P2.54mm_Vertical
J2: RASPBERRY PI 4; PinSocket_2x20_P2.54mm_Vertical
J3: TONEARM GND; TerminalBlock_bornier-2_P5.08mm
J4: GND LIFT; PinHeader_1x02_P2.54mm_Vertical
J5: TP DIG; PinHeader_2x05_P2.54mm_Vertical
J6: WP; PinHeader_1x02_P2.54mm_Vertical
J20: LINE IN L; TerminalBlock_bornier-2_P5.08mm
J22: TP L; PinHeader_2x05_P2.54mm_Vertical
J60: LINE IN R; TerminalBlock_bornier-2_P5.08mm
J62: TP R; PinHeader_2x05_P2.54mm_Vertical
L1, L2: 10u; L_Bourns_SRR1260
Q1: BC847; SOT-23
Q2, Q3: BC857; SOT-23
R1: 4R75; R_0805_2012Metric_Pad1.20x1.40mm_HandSolder
R2, R3, R4, R5, R31, R32, R43, R48, R50, R51, R53, R71, R72: 10k0; R_0805_2012Metric_Pad1.20x1.40mm_HandSolder
R10: 1M; R_0805_2012Metric_Pad1.20x1.40mm_HandSolder
R11: 2k2; R_0805_2012Metric_Pad1.20x1.40mm_HandSolder
R12, R13: 475R; R_0805_2012Metric_Pad1.20x1.40mm_HandSolder
R14: 33R2; R_0805_2012Metric_Pad1.20x1.40mm_HandSolder
R15: 3k92; R_0805_2012Metric_Pad1.20x1.40mm_HandSolder
R16, R20, R40, R41, R42, R52, R57, R58, R60: 1k00; R_0805_2012Metric_Pad1.20x1.40mm_HandSolder
R17: 10R0; R_0805_2012Metric_Pad1.20x1.40mm_HandSolder
R21, R61: 20k5; R_0805_2012Metric_Pad1.20x1.40mm_HandSolder
R22, R23, R62, R63: 14k7; R_0805_2012Metric_Pad1.20x1.40mm_HandSolder
R24, R64: 10k5; R_0805_2012Metric_Pad1.20x1.40mm_HandSolder
R25, R26, R65, R66: 13k0; R_0805_2012Metric_Pad1.20x1.40mm_HandSolder
R27, R67: 255k; R_0805_2012Metric_Pad1.20x1.40mm_HandSolder
R28, R68: 5k90; R_0805_2012Metric_Pad1.20x1.40mm_HandSolder
R29, R30, R69, R70: 8k25; R_0805_2012Metric_Pad1.20x1.40mm_HandSolder
R33, R35, R36, R44, R46, R73, R75, R76: 22k1; R_0805_2012Metric_Pad1.20x1.40mm_HandSolder
R34, R74: 165k; R_0805_2012Metric_Pad1.20x1.40mm_HandSolder
R37, R77: 2k21; R_0805_2012Metric_Pad1.20x1.40mm_HandSolder
R45, R47, R49, R59: 100k; R_0805_2012Metric_Pad1.20x1.40mm_HandSolder
R54, R55, R56: 330R; R_0805_2012Metric_Pad1.20x1.40mm_HandSolder
RV20, RV60: 47k; PinHeader_1x03_P2.54mm_Horizontal
SW1: SHUTDOWN / WAKE GPIO3; SW_SPST_PTS645Sx43SMTR92
SW2: USER GPIO23; SW_SPST_PTS645Sx43SMTR92
U1, U10: 74HC244; SOIC-20W_7.5x12.8mm_P1.27mm
U2: LM358; SOIC-8_3.9x4.9mm_P1.27mm
U3: 74HCT132; SOIC-14_3.9x8.7mm_P1.27mm
U4: 74HC4040; SOIC-16_3.9x9.9mm_P1.27mm
U6: 74HC157; SOIC-16_3.9x9.9mm_P1.27mm
U8: 74HC4049; SOIC-16_3.9x9.9mm_P1.27mm
U9: 74HCU04; SOIC-14_3.9x8.7mm_P1.27mm
U11: 24LC32; SOIC-8_3.9x4.9mm_P1.27mm
U12: LM339; SOIC-14_3.9x8.7mm_P1.27mm
U20, U22, U60, U62: TL072; SOIC-8_3.9x4.9mm_P1.27mm
U21, U61: LM311; SOIC-8_3.9x4.9mm_P1.27mm
U23, U63: 74HC74; SOIC-14_3.9x8.7mm_P1.27mm
U24, U64: 74HC04; SOIC-14_3.9x8.7mm_P1.27mm
Y1: 6.144MHz; Crystal_SMD_HC49-SD_HandSoldering

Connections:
BCLK: U4.9 (Q0), U8.3
BTN_SHDN: J2.5, R57.1
BTN_USER: J2.16, R58.1
CHASSIS: C48.1, D15.2 (A), D16.1 (K), J3.1, J3.2, J4.1, R17.1
CLK6M: U3.3, U4.10 (CLK)
CMP_L: J22.8, R37.2, U21.7, U23.2 (D)
CMP_R: J62.8, R77.2, U61.7, U63.2 (D)
DACN_L: R22.1, R29.1, U24.2
DACN_R: R62.1, R69.1, U64.2
DACP_L: J22.10, R25.1, R34.1, U24.4
DACP_R: J62.10, R65.1, R74.1, U64.4
DIN: J5.6, U6.4 (Za), U8.11
GPCLK0: J1.3, J2.7
ID_SC: J2.28, U11.6 (SCL)
ID_SD: J2.27, U11.5 (SDA)
INT1_L: C22.2, J22.2, R24.1, U12.5 (+), U12.6 (-), U20.1
INT1_R: C62.2, J62.2, R64.1, U12.8 (-), U12.11 (+), U60.1
INT2_L: C23.2, J22.4, R28.1, U20.7
INT2_R: C63.2, J62.4, R68.1, U60.7
INT3_L: C24.2, J22.6, R31.1, R33.1, U22.1
INT3_R: C64.2, J62.6, R71.1, R73.1, U62.1
LED_BUSY: J2.13, R55.1
LED_READY: J2.15, R56.1
LED_REC: J2.11, R54.1
LRCLK: J5.4, U3.4, U3.5, U4.4 (Q6), U8.7
LRCLK_N: C40.1, U3.6
MCLK: J5.2, R14.2, U6.1 (S), U23.3 (C), U63.3 (C)
MCLK_SRC: R14.1, U4.7 (Q1)
unnamed: C16.1, R10.1, U9.1, Y1.1
unnamed: C17.1, R11.2, Y1.2
unnamed: C20.2, R20.1
unnamed: C21.1, R20.2, RV20.1
unnamed: C46.1, R57.2, SW1.1
unnamed: C47.1, R58.2, SW2.1
unnamed: C60.2, R60.1
unnamed: C61.1, R60.2, RV60.1
unnamed: C4.2, D1.2 (A), D2.1 (K)
unnamed: C5.2, D2.2 (A), R1.1
unnamed: D3.2 (A), R40.2
unnamed: D4.2 (A), R41.2
unnamed: D5.2 (A), R42.2
unnamed: D5.1 (K), Q1.3 (C)
unnamed: D6.2 (A), R52.2
unnamed: D7.2 (A), R16.2
unnamed: D8.2 (A), R54.2
unnamed: D9.2 (A), R55.2
unnamed: D10.2 (A), R56.2
unnamed: C40.2, D11.1 (K), D12.2 (A)
unnamed: C41.1, D12.1 (K), R43.1
unnamed: C42.1, D13.2 (A), R49.2, R50.1
unnamed: D13.1 (K), R48.2, U12.1, U12.2
unnamed: C43.1, D14.2 (A), R51.1, R59.2
unnamed: D14.1 (K), R53.2, U12.13, U12.14
unnamed: J1.1, U9.4
unnamed: J1.2, U3.1, U3.2
unnamed: J6.1, R15.2, U11.7 (WP)
unnamed: C20.1, J20.1
unnamed: C60.1, J60.1
unnamed: Q1.1 (B), R43.2
unnamed: Q2.1 (B), R50.2
unnamed: Q2.3 (C), R52.1
unnamed: Q3.1 (B), R51.2
unnamed: Q3.3 (C), R16.1
unnamed: R10.2, R11.1, U9.2, U9.3
unnamed: R12.1, U8.4
unnamed: R13.1, U8.10
unnamed: R21.1, RV20.2
unnamed: R27.1, R32.2, U22.7
unnamed: R61.1, RV60.2
unnamed: R67.1, R72.2, U62.7
unnamed: C4.1, U1.3 (2Y0), U1.5 (2Y1), U1.7 (2Y2), U1.9 (2Y3), U1.12 (1Y3), U1.14 (1Y2), U1.16 (1Y1), U1.18 (1Y0), U10.3 (2Y0), U10.5 (2Y1), U10.7 (2Y2), U10.9 (2Y3), U10.12 (1Y3), U10.14 (1Y2), U10.16 (1Y1), U10.18 (1Y0)
unnamed: R2.2, R3.1, U2.3 (+)
unnamed: R4.2, R5.1, U2.6 (-)
unnamed: U8.2, U8.5
unnamed: U8.6, U8.9
unnamed: U8.12, U8.14
unnamed: C22.1, R21.2, R22.2, R23.2, U20.2 (-)
unnamed: C23.1, R24.2, R25.2, R26.2, R27.2, U20.6 (-)
unnamed: R33.2, R34.2, R35.2, R36.2, U21.3 (-)
unnamed: C24.1, R28.2, R29.2, R30.2, U22.2 (-)
unnamed: R31.2, R32.1, U22.6 (-)
unnamed: C62.1, R61.2, R62.2, R63.2, U60.2 (-)
unnamed: C63.1, R64.2, R65.2, R66.2, R67.2, U60.6 (-)
unnamed: R73.2, R74.2, R75.2, R76.2, U61.3 (-)
unnamed: C64.1, R68.2, R69.2, R70.2, U62.2 (-)
unnamed: R71.2, R72.1, U62.6 (-)
PI_5V: J2.2, J2.4, L1.1
PI_BCLK: J2.12, R12.2
PI_DIN: J2.38, U8.15
PI_LRCLK: J2.35, R13.2
PUMP: U1.2 (1A0), U1.4 (1A1), U1.6 (1A2), U1.8 (1A3), U1.11 (2A3), U1.13 (2A2), U1.15 (2A1), U1.17 (2A0), U4.3 (Q4), U10.2 (1A0), U10.4 (1A1), U10.6 (1A2), U10.8 (1A3), U10.11 (2A3), U10.13 (2A2), U10.15 (2A1), U10.17 (2A0)
QL: U6.3 (I1a), U23.5 (Q), U24.1
QNL: U23.6 (~Q), U24.3
QNR: U63.6 (~Q), U64.3
QR: U6.2 (I0a), U63.5 (Q), U64.1
TH_N: R46.2, R47.1, U12.7 (+), U12.9 (+)
TH_P: R44.2, R45.1, U12.4 (-), U12.10 (-)
VREF_N: J5.10, R5.2, R23.1, R26.1, R30.1, R46.1, R63.1, R66.1, R70.1, U2.7
VREF_P: J5.8, R4.1, R35.1, R44.1, R75.1, U2.1, U2.2 (-), U21.2 (+), U61.2 (+)

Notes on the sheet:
POWER (Pi +5V -> charge-pump -5V -> +/-2.5V DAC reference)
Reservoir sits AT the DAC gate: the DAC's mean supply current
is proportional to the signal, so this rail must be LOW
IMPEDANCE, not filtered by a series R.
2 x 8 buffers paralleled: half the 16 ohm output
resistance of one package, ~0.6 V more rail (10b)
192 kHz pump drive = 4x the 48 kHz output rate,
so residual ripple lands on a CIC decimator null.
REFERENCE (+/-2.5V, ratiometric -- tracks +5V so rail noise cancels as gain, not additive noise)
ANALOG ISLAND +5VA (10 uH + 470 u, fc 2.3 kHz)
~35 dB down at the pump's 192 kHz. Feeds the op-amps, the
comparators' bias, the DAC gates and the reference, so the
reference stays ratiometric to the gates' own rail. Both
chokes are SRR1260 10 uH SMD; L1 is the inlet from the
Pi. Neither is a resistor: DCR ~ 0.05 R keeps the DAC
reference stiff (design-notes 6).
CLOCK AND DIGITAL (6.144 MHz -> /2 BCLK 3.072M, /4 MCLK 1.536M, /128 LRCLK 48k; L and R interleaved onto one DIN)
Jumper 1-2 = crystal Pierce (ps jitter -> ~100 dB floor).
Jumper 2-3 = Pi GPCLK0: ~1 ns -> 68 dB floor, the dominant
noise source if left there. Bring-up only.
U3B buffers LRCLK for the clock-alive LED; other spares tied low
Q0=BCLK 3.072M Q1=MCLK 1.536M
Q4=PUMP 192k Q6=LRCLK 48k
MCLK selects: DIN carries R,L,R,L... at 3.072 Mbps.
64 BCLK per LRCLK frame = 32 L bits + 32 R bits
= exactly one OSR-32 sample per channel.
LEVEL SHIFT to 3.3 V. 74HC4049 tolerates inputs above its own
VCC, which is exactly what makes it legal here. Two inverters
per signal so BCLK polarity is preserved -- inverting BCLK would
make the Pi sample on the data transition.
RASPBERRY PI 4 on a 2x20 socket, mounted UNDER the board.
1/17=3V3 2/4=5V in (through FB1 onto +5V) 7=GPCLK0 GPIO4
12=BCLK GPIO18 35=LRCLK GPIO19 38=DIN GPIO20 even GND
Pi is I2S SLAVE: this board is the clock master.
MCLK SOURCE DAMPING
Divider Q1 -> 33R2 -> MCLK to both retiming flip-flops and the
interleave mux. Series damping at the one source; the edge
is the jitter-critical one, so the value stays small.
CHANNEL L - 3rd-order CT delta-sigma, fs 1.536 MHz, OSR 32
2u2 + 47k -> 1.5 Hz HP; 1k + 1n5 -> 106 kHz anti-alias.

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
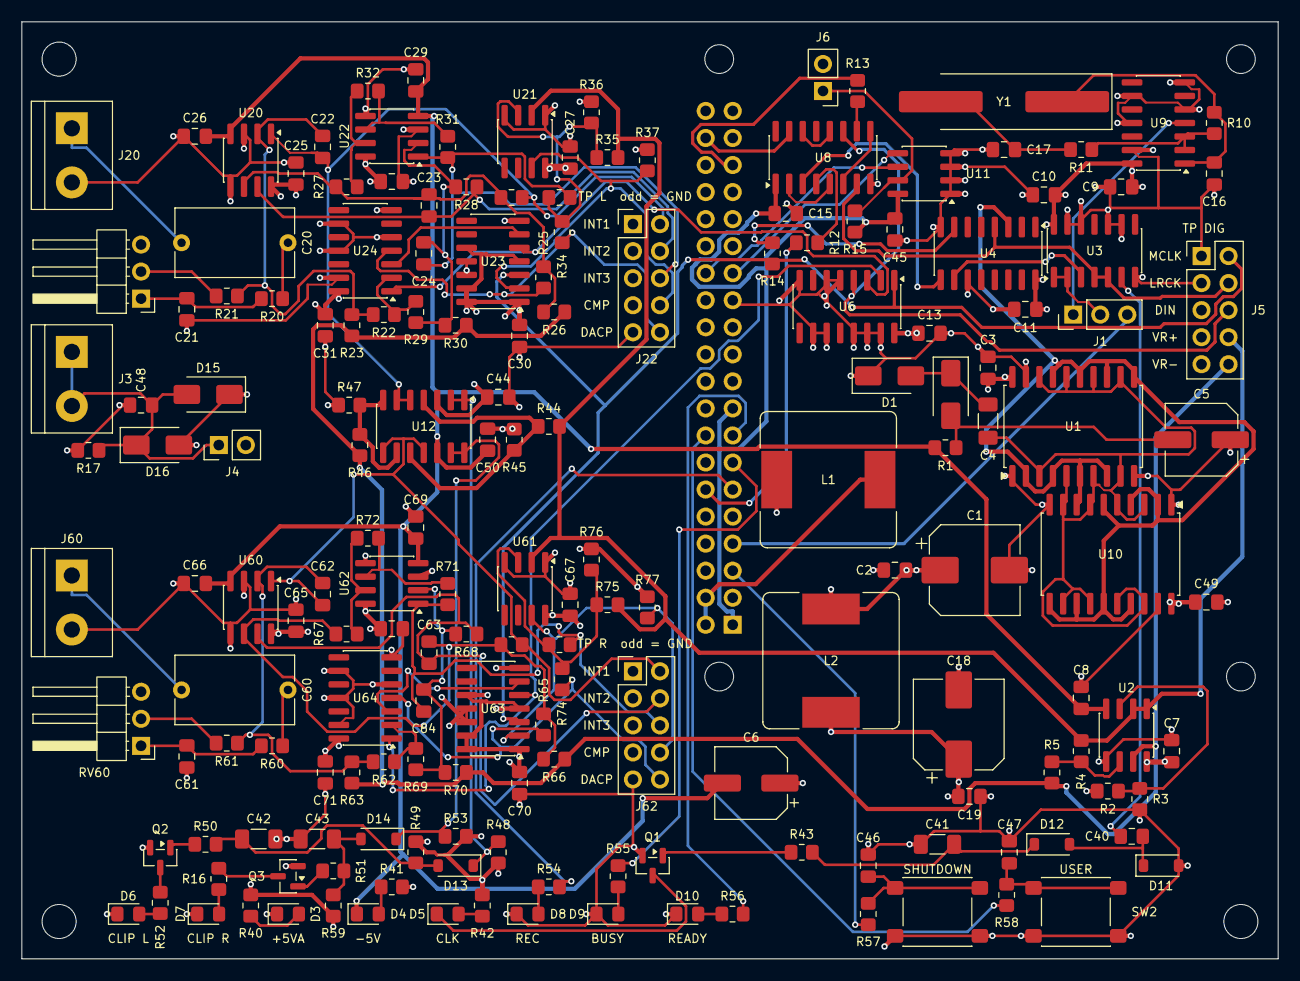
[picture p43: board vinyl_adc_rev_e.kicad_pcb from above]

Board: 4 copper layers, 118.0 x 88.0 mm, 184 parts (1 on the bottom side), 104 nets.

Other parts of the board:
H1, H2, H3: MountingHole_3.2mm_M3
H4, H5, H6, H7: MountingHole_2.7mm_M2.5

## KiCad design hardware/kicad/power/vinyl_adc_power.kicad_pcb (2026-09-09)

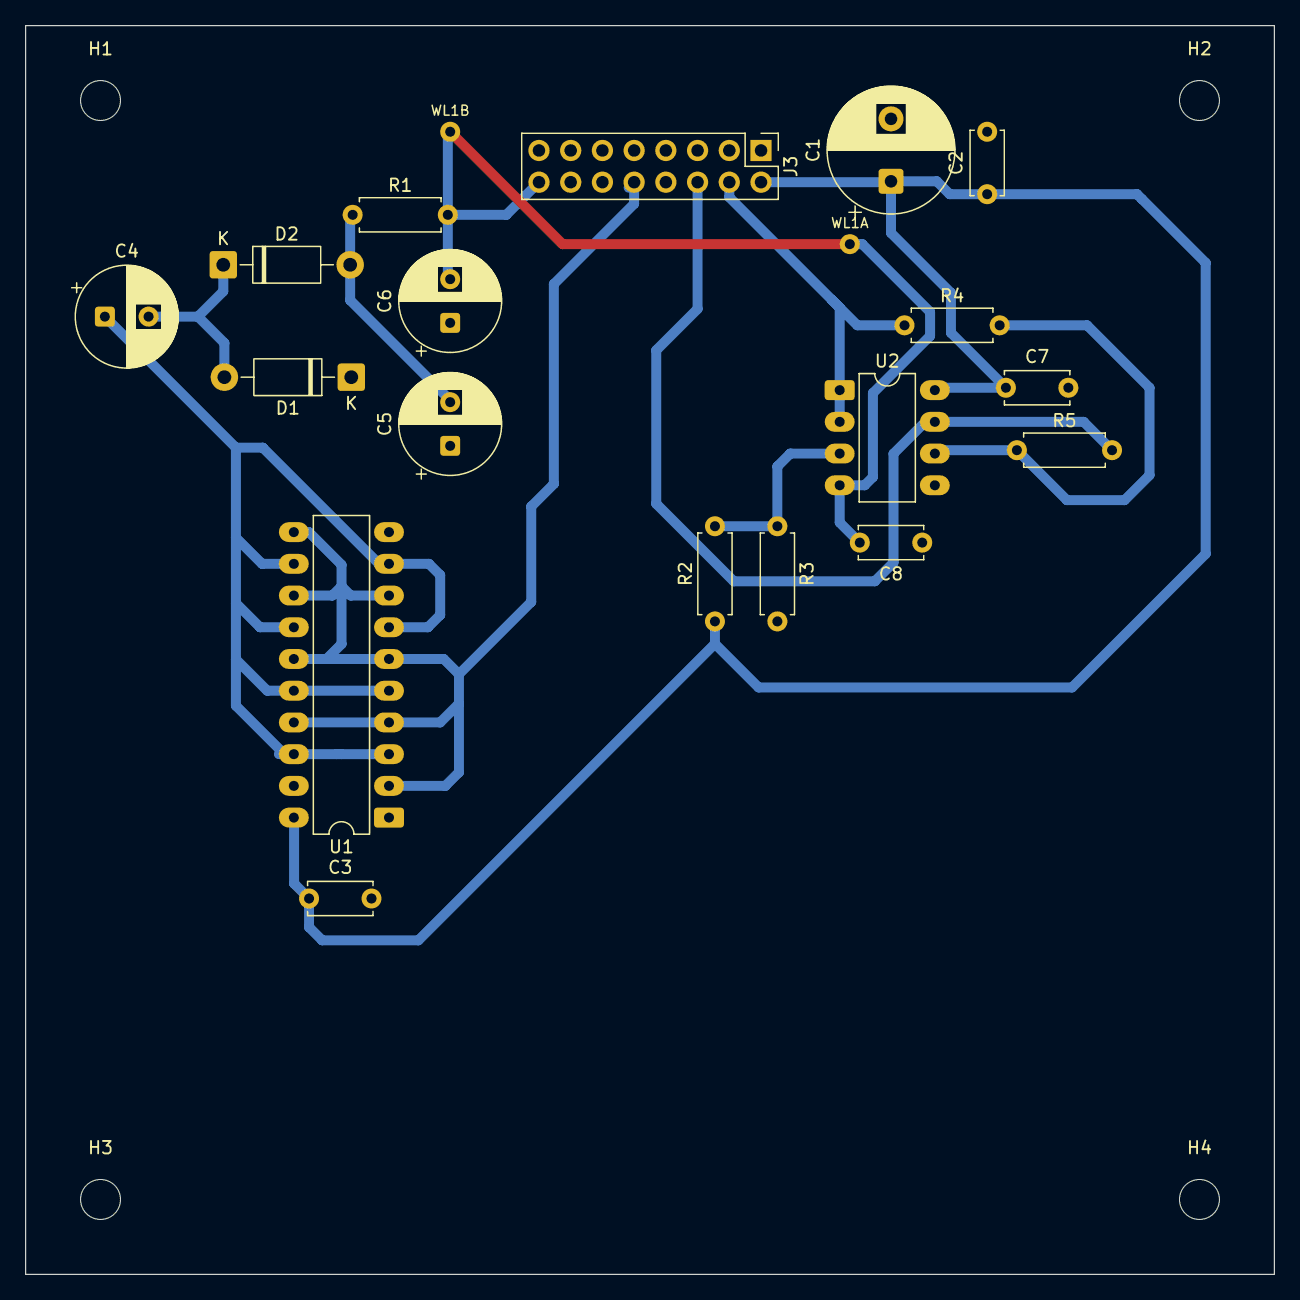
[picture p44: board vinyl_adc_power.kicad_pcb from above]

Board: 2 copper layers, 100.0 x 100.0 mm, 24 parts (0 on the bottom side), 11 nets.

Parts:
C1: 470u; CP_Radial_D10.0mm_P5.00mm
C2, C3, C7, C8: 100n; C_Disc_D5.0mm_W2.5mm_P5.00mm
C4: 10u; CP_Radial_D8.0mm_P3.50mm
C5, C6: 220u; CP_Radial_D8.0mm_P3.50mm
D1, D2: 1N5817; D_DO-41_SOD81_P10.16mm_Horizontal
H1, H2, H3, H4: MountingHole_3.2mm_M3
J3: 2x8 BUS; PinHeader_2x08_P2.54mm_Vertical
R1: 4R75; R_Axial_DIN0207_L6.3mm_D2.5mm_P7.62mm_Horizontal
R2, R3, R4, R5: 10k0; R_Axial_DIN0207_L6.3mm_D2.5mm_P7.62mm_Horizontal
U1: 74HC244; DIP-20_W7.62mm_LongPads
U2: TL072; DIP-8_W7.62mm_LongPads
WL1A, WL1B: -5V; WireLink_TH

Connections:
+5V: C1.1, C2.1, C3.1, C7.1, J3.2, R2.1, U1.20, U2.8
-5V: C6.2, C8.2, J3.16, R1.2, U2.4, WL1A.1, WL1B.1
GND: C1.2, C2.2, C3.2, C5.1, C6.1, C7.2, C8.1, D1.1, J3.1, J3.3, J3.5, J3.7, J3.9, J3.11, J3.13, J3.15, R3.2, U1.1, U1.10, U1.19, U2.5
unnamed: C4.2, D1.2, D2.1
unnamed: C5.2, D2.2, R1.1
unnamed: C4.1, U1.3, U1.5, U1.7, U1.9, U1.12, U1.14, U1.16, U1.18
unnamed: R2.2, R3.1, U2.3
unnamed: R4.2, R5.1, U2.6
PUMP: J3.10, U1.2, U1.4, U1.6, U1.8, U1.11, U1.13, U1.15, U1.17
VREF_N: J3.6, R5.2, U2.7
VREF_P: J3.4, R4.1, U2.1, U2.2

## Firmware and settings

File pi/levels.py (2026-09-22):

#!/usr/bin/env python3
"""Level-setting dashboard: set RV20 on each channel board with a record playing.

    python3 levels.py                                        # on the Pi, beside the ripper
    python3 levels.py --ripper http://vinyladc.local:8091    # from anywhere else

RV20 sets each channel's full scale, so it is a calibration rather than a property of the
converter, and it has never been set for the real source. Full scale measured on the bench is
10.41 Vpk; a phono stage delivers a fraction of a volt, which lands every rip near -23 dBFS on a
converter that only has 68 dB to give. Turning the trimmer up until the music peaks reach -6 dBFS
is worth about 13 dB of recording quality and costs one screwdriver. This page is the meter for
doing that.

It reads the ripper's /api/state rather than the capture card: the card has one reader and the
ripper owns it. Nothing about a running rip changes, and this can be started and stopped freely.

Two things this does that a plain peak meter does not:

*   **It tunes on a percentile, not the maximum.** A vinyl click runs far above the music. Trim so
    the loudest transient reaches -6 dBFS and every record ends up ten decibels too quiet. The
    number to set is the 95th percentile of the 100 ms peak buckets - the level the music actually
    keeps reaching - with the absolute maximum shown separately so clicks stay visible.

*   **It puts the ceiling at -3 dBFS, not 0.** This is a third-order delta-sigma loop, and it goes
    unstable before the arithmetic runs out: the simulation overloads at -3.1 dBFS input while
    -4.4 dBFS is still clean at 71.6 dB. Clicks above that are expected and survivable - the input
    clamp was added exactly so one click does not latch the loop - but the music must stay under.

It also holds the needle detector off while the page is open, because a record playing into the
input is precisely what tells the ripper to start recording a side.
"""
import argparse, json, math, threading, time, urllib.error, urllib.request
from http.server import ThreadingHTTPServer, BaseHTTPRequestHandler
from pathlib import Path

TARGET, TOL, CEILING = -6., 2., -3.      # aim, how close counts as set, where the modulator gives up
FLOOR = -60.                             # below this the needle is up
PCTL = 95                                # percentile of the 100 ms peak buckets that the trim follows


def db(linear):
    """dBFS of a linear peak, where 1.0 is digital full scale (the ripper normalises to +-1)."""
    return 20. * math.log10(max(float(linear), 1e-12))


def percentile(sorted_vals, q):
    """Linear-interpolated percentile of an already-sorted list; avoids a numpy import for one number."""
    if not sorted_vals:
        return None
    if len(sorted_vals) == 1:
        return sorted_vals[0]
    pos = (len(sorted_vals) - 1) * q / 100.
    lo = int(pos); hi = min(lo + 1, len(sorted_vals) - 1); f = pos - lo
    return sorted_vals[lo] * (1 - f) + sorted_vals[hi] * f


def verdict(music, over):
    """What to say about one channel: the words the person at the screwdriver needs."""
    if over:
        return 'over', 'Clipping — back it off'
    if music is None or music < FLOOR:
        return 'silent', 'No signal — drop the needle'
    if music > CEILING:
        return 'over', f'Too hot — back off {music - TARGET:.1f} dB'
    if music > TARGET + TOL:
        return 'hot', f'Back off {music - TARGET:.1f} dB'
    if music < TARGET - TOL:
        return 'low', f'Turn up {TARGET - music:.1f} dB'
    return 'ok', 'On target'


class Reader:
    """Polls the ripper and turns its state into the handful of numbers this page needs."""

    def __init__(self, base, window):
        self.base, self.window = base.rstrip('/'), window
        self.lock = threading.Lock()
        self.data = {'ok': False, 'error': 'connecting…', 'base': self.base}
        self.hold = True
        self.stop = threading.Event()

    def get(self, path, body=None):
        req = urllib.request.Request(self.base + path, data=json.dumps(body).encode() if body is not None else None,
                                     headers={'Content-Type': 'application/json'})
        with urllib.request.urlopen(req, timeout=4) as r:
            return json.loads(r.read() or b'{}')

    def loop(self):
        last_hold = 0.
        while not self.stop.is_set():
            try:
                state = self.get('/api/state')
                # keep the needle detector off: a record playing is exactly what starts a side
                if self.hold and time.time() - last_hold > 30:
                    try:
                        self.get('/api/hold', {'seconds': 90}); last_hold = time.time()
                    except Exception:
                        pass
                with self.lock:
                    self.data = self.reduce(state)
            except urllib.error.URLError as e:
                with self.lock:
                    self.data = {'ok': False, 'base': self.base,
                                 'error': f'No answer from the ripper at {self.base} ({e.reason}). Is vinyl-adc-ripper running?'}
            except Exception as e:
                with self.lock:
                    self.data = {'ok': False, 'base': self.base, 'error': repr(e)}
            self.stop.wait(0.25)

    def reduce(self, state):
        wave = state.get('wave') or {}
        step = float(wave.get('step_s') or 0.1)
        keep = max(1, int(round(self.window / step)))
        chans = []
        history = {'step_s': step, 'left': [], 'right': []}
        for key, name in (('left', 'Left'), ('right', 'Right')):
            buckets = [float(v) for v in (wave.get(key) or [])][-keep:]
            history[key] = [round(db(v), 1) for v in buckets]
            if buckets:
                ordered = sorted(buckets)
                music = db(percentile(ordered, PCTL))
                peak = db(ordered[-1])
                over = sum(1 for v in buckets if v >= 0.999)
            else:
                music = peak = None; over = 0
            kind, says = verdict(music, over)
            chans.append({'name': name, 'music': None if music is None else round(music, 1),
                          'max': None if peak is None else round(peak, 1),
                          'over': over, 'verdict': kind, 'says': says,
                          'delta': None if music is None or music < FLOOR else round(TARGET - music, 1)})
        meters = state.get('meters') or {}
        live = [round(float(v), 1) for v in (meters.get('peak_db') or [])] or None
        both = [c['music'] for c in chans]
        balance = round(both[0] - both[1], 1) if all(v is not None and v > FLOOR for v in both) else None
        return {'ok': True, 'base': self.base, 'status': state.get('status'), 'message': state.get('message') or '',
                'hold': round(float(state.get('hold') or 0.), 1), 'holding': self.hold,
                'mode': meters.get('mode'), 'live': live, 'window_s': self.window,
                'samples': len(history['left']), 'ch': chans, 'balance': balance,
                'target': TARGET, 'tol': TOL, 'ceiling': CEILING, 'floor': FLOOR, 'pctl': PCTL,
                'history': history}


def make_handler(reader):
    page = (Path(__file__).with_name('levels.html')).read_bytes

    class H(BaseHTTPRequestHandler):
        def log_message(self, *a):
            pass

        def reply(self, body, ctype='application/json', code=200):
            if not isinstance(body, bytes):
                body = json.dumps(body).encode()
            self.send_response(code); self.send_header('Content-Type', ctype)
            self.send_header('Content-Length', str(len(body))); self.send_header('Cache-Control', 'no-store')
            self.end_headers(); self.wfile.write(body)

        def do_GET(self):
            if self.path == '/':
                return self.reply(page(), 'text/html; charset=utf-8')
            if self.path.startswith('/api/levels'):
                with reader.lock:
                    return self.reply(reader.data)
            self.reply({'error': 'not found'}, code=404)

        def do_POST(self):
            body = json.loads(self.rfile.read(int(self.headers.get('Content-Length') or 0)) or b'{}')
            if self.path == '/api/holding':
                reader.hold = bool(body.get('on'))
                if not reader.hold:
                    try:
                        reader.get('/api/hold', {'seconds': 0})      # release it now rather than waiting it out
                    except Exception:
                        pass
                return self.reply({'ok': True, 'holding': reader.hold})
            if self.path == '/api/window':
                reader.window = max(5., min(60., float(body.get('seconds', 30))))
                return self.reply({'ok': True, 'window_s': reader.window})
            self.reply({'error': 'not found'}, code=404)

    return H


def main():
    p = argparse.ArgumentParser(description=__doc__.split('\n')[0])
    p.add_argument('--port', type=int, default=8092)
    p.add_argument('--ripper', default='http://127.0.0.1:8091')
    p.add_argument('--window', type=float, default=30., help='seconds of peak history the trim follows')
    a = p.parse_args()
    reader = Reader(a.ripper, a.window)
    threading.Thread(target=reader.loop, daemon=True).start()
    print(f'Level dashboard on http://0.0.0.0:{a.port}  (reading {a.ripper})')
    try:
        ThreadingHTTPServer(('0.0.0.0', a.port), make_handler(reader)).serve_forever()
    except KeyboardInterrupt:
        reader.stop.set()
        try:
            reader.get('/api/hold', {'seconds': 0})                  # never leave the ripper held off
        except Exception:
            pass
        print('\nhold released, bye')


if __name__ == '__main__':
    main()

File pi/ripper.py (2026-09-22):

#!/usr/bin/env python3
"""Vinyl ripper: records what the Vinyl ADC hears, splits it into tracks and hands finished albums to Jellyfin.

    python3 ripper.py                      # on the Pi; dashboard on http://vinyladc.local:8091
    python3 ripper.py --replay x.raw --fast --home /tmp/vinyl   # offline test with a saved capture

Flow: the needle drops -> the level rises -> a *side* is recorded to disk (with a few seconds of pre-roll) ->
the needle lifts -> the side is closed. If an album is selected in the dashboard (MusicBrainz search), the
side is matched to the next tracks of that album by duration, cut at the quiet gaps nearest the expected
boundaries, and when the album is complete (or on request) every track is normalised with one common gain,
encoded to 24-bit FLAC, tagged, given cover art and published in the outbox. A small puller on the media
server fetches the outbox and drops the album into the Jellyfin music library.

The audio path is: I2S words -> the two 1-bit modulator streams -> repair of stuck runs (a hardware fault
marker, never produced by music) -> CIC + FIR decimation to 48 kHz (decimate.py) -> DC removal.
Needs NumPy; `flac` and python3-mutagen for encoding and tagging.
"""
import argparse,collections,hashlib,json,queue,re,shutil,signal,subprocess,threading,time,urllib.error,urllib.parse,urllib.request
from collections import deque
from http.server import ThreadingHTTPServer,BaseHTTPRequestHandler
from pathlib import Path
import numpy as np
import decimate as d

FS=48000;BLOCK_FRAMES=24000;BLOCK_BYTES=BLOCK_FRAMES*8;CHUNK=4800           # 0.5 s blocks, 100 ms level chunks
UA='VinylADC-Ripper/0.1 ( https://github.com/MadsRudolph/vinyl-adc )'
# start_db and stop_db are ABSOLUTE dBFS, so they belong to one input-gain setting: move RV20 and they must be
# re-derived or the needle detector stops working. With the trimmers set for a phono stage (2026-09-20) silence
# reads about -57.6 dBFS on the treble-weighted detector while quiet music sits only ~9 dB above it, and at a
# 30 s window no threshold separates them: everything that stops on silence also cuts a record. Abbey Road's
# second side proved it, fragmenting into three. Sixty seconds does separate them, because a musical gap cannot
# fill a minute and a lifted needle can - measured over four real sides, the worst passage reaches 63 % of the
# window against the stop rule's 80 %, while silence reaches 100 %. Widening the window, not moving the
# threshold, is what bought the margin. -50 was the first attempt and it still cut Abbey Road's second side in
# three: a caution about the method, not just the number. Those sides had been closed by the 30 s rule, so none
# of them contained a 60 s silence to trigger a 60 s rule, and validating against them was circular. -54 is
# measured against sides that fragmented under the rule being replaced. See docs/test-and-verification.md 5b.
DEFAULTS={'start_db':-55.,'start_seconds':2.,'stop_db':-54.,'stop_seconds':60.,'preroll_seconds':2.5,'min_side_seconds':90.,'max_side_seconds':2400.,
          'gap_db':-63.,'gap_seconds':1.2,'snap_seconds':15.,'channel_mode':'auto','repair_stuck_runs':True,'target_peak_dbfs':-1.,'max_gain_db':24.,
          'identify':True,'identify_at_seconds':480.,'finalize_after_hours':3.,'min_free_gb':3.,
          'notify_url':''}          # a webhook that gets a JSON POST when a side starts, ends or lands in the library
ACOUSTID='https://api.acoustid.org/v2/lookup'

def db(x):return float(10*np.log10(x+1e-20))
def safe(name):return re.sub(r'\s+',' ',re.sub(r'[\\/:*?"<>|\x00-\x1f]','_',name)).strip(' .') or 'Unknown'

# ------------------------------------------------------------------ signal path
class Dsp:
    def __init__(self,cfg):
        self.cfg=cfg;h=d.compensating_fir();self.chain=[(d.Cic(),d.FirDecimator(h)) for _ in range(2)];self.dc=[None,None];self.last=[0.,0.];self.repaired=0
    def process(self,raw):
        words=np.frombuffer(raw,dtype='<u4').reshape(-1,2);out=[];health=[]
        for i,bits in enumerate(d.split_bits(words)):
            b=bits.view(np.int8);chg=np.flatnonzero(np.diff(b)!=0);mean_run=len(b)/(len(chg)+1);density=float(b.mean())
            if self.cfg['repair_stuck_runs'] and len(chg):
                starts=np.r_[0,chg+1];lens=np.diff(np.r_[starts,len(b)]);bad=np.flatnonzero(lens>=7)
                if 0<len(bad)<100:                      # a healthy loop never holds a level for 7 clocks; a broken one does it constantly
                    b=b.copy()
                    for k in bad:
                        s,n=starts[k],lens[k];b[s:s+n]=((1-b[s-1] if s else 0)+np.arange(n))%2
                    self.repaired+=len(bad)
            cic,fir=self.chain[i];y=fir.process(cic.process(b*2-1))
            m=float(y.mean());self.dc[i]=m if self.dc[i] is None else .9*self.dc[i]+.1*m
            out.append(y-self.dc[i])
            ok=.02<density<.98 and mean_run<4
            health.append({'ok':ok,'density':density,'mean_run':float(mean_run),'dc':self.dc[i],'verdict':'Healthy' if ok else ('Stuck bitstream' if not .02<density<.98 else 'Loop oscillating')})
        mode=self.cfg['channel_mode']
        if mode=='auto':mode='stereo' if health[0]['ok']==health[1]['ok'] else ('left' if health[0]['ok'] else 'right')
        if mode=='left':out[1]=out[0]
        elif mode=='right':out[0]=out[1]
        audio=np.vstack(out);n=audio.shape[1]//CHUNK;seg=audio[:,:n*CHUNK].reshape(2,n,CHUNK)
        diff=np.diff(np.concatenate((np.array(self.last)[:,None],audio),axis=1),axis=1)[:,:n*CHUNK].reshape(2,n,CHUNK);self.last=[float(audio[0,-1]),float(audio[1,-1])]
        level=10*np.log10((diff**2).mean(axis=2).max(axis=0)+1e-20)   # treble-weighted: ignores mains hum, follows music and groove noise
        return audio,{'mode':mode,'health':health,'level':level,'peaks':np.abs(seg).max(axis=2).T,
                      'rms_db':[db(float((a**2).mean())) for a in audio],'peak_db':[db(float(np.abs(a).max())**2) for a in audio]}
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

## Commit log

2026-08-22 Vinyl ADC: the schematic, and the SPICE benches that found it was wrong
    The board's charge pump was drawn with both Schottkys reversed. That makes it
    a voltage doubler, so the net called -5V simulates at +3.4 V and would have
    arrived on the V- pin of every op-amp on the board. sch_score, ERC, the
    netlist read-back and check_intent.py all passed it, because a diode wired
    the wrong way round is still a connected diode.
    Eight KiCad testbenches in hardware/kicad/sim/, one per block plus the whole
    modulator loop. sim_layout.py imports the board's own layout script and calls
    the same block functions with the bench's sheet, so every bench is the same
    drawing as the board rather than a re-creation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
    [sim_a_pump.kicad_sch, sim_b_reference.kicad_sch, sim_c_clock.kicad_sch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]
2026-08-22 Vinyl ADC: re-export the board PDF and netlist after the caption nudge
2026-08-23 Vinyl ADC: split the board four ways so the mill can cut it
    The one-board layout came out at 45 hand-soldered wire bridges, 17 vias and
    25 ground pads the pour could not reach. The cause is one number: 2.54 mm DIP
    pitch leaves 0.84 mm between pads, and a 1.0 mm track with 0.85 mm clearance
    needs 2.7. Nothing passes between adjacent pins on this process, so every
    connection goes round the outside of its package -- which makes routability a
    function of space per part. The one-board version was 0.37 parts/cm2.
    Three designs, four boards:
    common power in, charge pump, +/-2.5 V reference, quantiser, DAC gates
    channel one modulator: line in, three integrators, resonator, comparator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
    [vinyl_adc.kicad_sch, vinyl_adc_channel_l.kicad_pcb, vinyl_adc_channel_l.kicad_sch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]
2026-08-27 Vinyl ADC: rebuild as three stacking boards
    The four-board split fixed the ground plane and not the congestion --
    45 wire bridges became 42, and the bridge count barely moved however the
    blocks were arranged. So this moves the cut lines rather than adding more
    boards.
    Each channel board now carries its own 74HC74 and 74HC04, so the modulator
    loop closes on one board instead of crossing a ribbon. Measured on the old
    common board, 59 of its 84 F.Cu segments were per-channel CMP/DAC/Q traffic;
    that is what leaves with them. The TL074 becomes two TL072s per channel, so
    the integrator pairs can sit apart instead of seventeen resistors competing
    for one package's perimeter. What remains of the co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
    [vinyl_adc.kicad_sch, vinyl_adc_channel_l.kicad_pcb, vinyl_adc_channel_l.kicad_sch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]
2026-08-30 Vinyl ADC: cut the channel double-sided, restore the DRC rules
    The three boards were unjudgeable: a previous rebuild deleted every
    .kicad_dru, so all three reported bare clearance errors with no way to
    tell a real one from the documented exception. Restore them per the
    memberOfFootprint recipe -- all 116 hits turn out to be intra-footprint
    pad-to-pad at 0.840 mm against the 0.85 mm rule, on fixed 2.54 mm header
    pitch, and not one of them was real. The rules do override the board
    minimum in KiCad 10; checked rather than assumed.
    Netclass was 0.5/0.6 on all three, below the boards' own 0.85/0.8 minima,
    so anything that routed them would have laid copper the mill cannot cut.
    The channel artwo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
    [vinyl_adc_channel_l.kicad_pcb, vinyl_adc_digital.kicad_pcb]
2026-08-30 Vinyl ADC: channel artwork finished, and its production set
    VREF_N to J7 pin 6 is routed -- the one link FreeRouting would not close
    at 30 or 100 passes with the whole top layer free. The channel board is
    now 26/26 nets in one piece, both oracles agreeing at 0 unconnected, 0
    vias, 0 stranded pads.
    Its ground pour was in ten pieces: the GND zone had island removal set to
    Never, leaving nine floating fragments of 1.2 to 12.9 mm2, none carrying
    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
    [vinyl_adc_channel_l-B_Cu.gbl, vinyl_adc_channel_l-B_Mask.gbs, vinyl_adc_channel_l-Edge_Cuts.gm1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]
2026-09-03 Vinyl ADC: the digital and power layouts as fabricated
    The two boards milled on 2026-09-03, side by side on one sheet. Editor
    history folders are ignored from here on.
    [vinyl_adc_digital.kicad_pcb, vinyl_adc_power.kicad_pcb]
2026-09-03 Vinyl ADC: 3D-printable enclosure, acrylic top lid and manufacturing files
    - 3D-printable base enclosure (144 x 144 x 65 mm) with floor mounting pedestals for M3 heated inserts and underside counterbores
    - Outward M3 heat-set insert pockets (+/-64 mm) with 4.5+ mm solid plastic wall casing
    - Clear acrylic top lid (140 x 140 mm, R=6 mm) with concentric M3 screw holes
    - Calibrated SVG (72 pt/in) and 1:1 DXF for DTU GCC Spirit laser cutter (0.01 mm red cut strokes)
    - Watertight 2-manifold STL and native 3MF for PrusaSlicer with build plate origin alignment
    - Complete Blender assembly scene with real KiCad 3D PCB models and wiring
    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
    [vinyl_adc_enclosure.blend, vinyl_adc_enclosure_base.3mf, vinyl_adc_enclosure_base.stl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]
2026-09-03 Add project README with 3D assembly animation and video
    [vinyl_adc_enclosure.blend]
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2026-09-03 Comprehensive showcase upgrade: Interactive 3D Web Viewer, SPICE FFT spectrum, Pi wiring, and luxury engraved lid
    [vinyl_adc_plexiglass_top.dxf]
2026-09-03 Fix 3D web viewer camera framing, metric scale bounds, and add quick explode toggle
2026-09-03 Fix animation playback: merge 33 channels into unified Assembly track and fix Play/Pause JS state
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2026-09-09 Replace the unobtainable oscillator can with a crystal Pierce
    The 6.144 MHz can never turned up, but a bare 2-pin crystal did. The clock
    is now a Pierce oscillator -- unbuffered 74HCU04, Rf 1M, Rs 2k2, 27p loads --
    drawn by one shared blk_pierce so the digital board rev B, the plug-in
    module and the sim_i_pierce bench cannot drift apart.
    Rs is 2k2 and not the textbook 1k because the bench showed 1k lets the loop
    oscillate at ~30 MHz through the crystal's 5 pF holder capacitance, and a
    buffered 74HC04 re-lights that parasitic at any Rs; both findings are in
    design-notes section 5 and asserted by the bench (suite 55/55).
    The module (hardware/kicad/osc_module/) fills rev A's X1 socket: 40x44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
    [sim_i_pierce.kicad_sch, vinyl_adc.kicad_sch, vinyl_adc_channel_l.kicad_pcb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]
2026-09-09 Redesign enclosure as reinforced organic lattice with 40 mm extra height
    [m3_insert_fit_coupon.stl, original_assembly.blend, vinyl_adc_enclosure.blend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]
2026-09-09 finished digital addon board
    [temp-freerouting.dsn, vinyl_adc_digital.kicad_pcb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]
2026-09-09 Add wire links to digital board and export production files
    Board routed with WL pad pairs for the single-sided flow: 48 F.Cu
    segments across 6 nets become solder-in wire bridges. DRC clean,
    0 unconnected.
    Production set for the CNC mill (gerbers + Excellon drill, bits
    0.8/1.0/3.2 mm) plus laser DXFs: silk_top for the silkscreen pass and
    mask_bottom for UV solder mask ablation. The mask DXF is generated
    straight from the pad geometry as closed circles/polylines so xTool
    can fill-engrave it (kicad-cli only emits loose LINE segments); MASK
    layer = openings, EDGE layer = outline for registration only. Not
    mirrored - mirror in xTool with the board copper-side up.
    [vinyl_adc_digital-B_Cu.gbl, vinyl_adc_digital-B_Mask.gbs, vinyl_adc_digital-Edge_Cuts.gm1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]
2026-09-09 Set 0.1 mm solder mask expansion and regenerate production files
    Mask openings were exactly pad-sized, leaving no slack for laser-to-board
    registration when ablating the UV mask. 0.1 mm global expansion in board
    setup; mask_bottom.dxf and gerbers re-exported to match.
    [vinyl_adc_digital-B_Cu.gbl, vinyl_adc_digital-B_Mask.gbs, vinyl_adc_digital-Edge_Cuts.gm1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]
2026-09-09 Add solder mask ablation DXF and production files for osc module
    Same flow as the digital board: 0.1 mm global mask expansion for
    laser-to-board registration slack, mask_bottom.dxf generated from pad
    geometry as closed circles/polylines for xTool fill-engraving (MASK =
    openings, EDGE = outline for registration). Gerbers, drill, silk and
    copper DXFs re-exported to match. Not mirrored - mirror in xTool with
    the board copper-side up.
    [vinyl_adc_osc-B_Cu.gbl, vinyl_adc_osc-B_Mask.gbs, vinyl_adc_osc-Edge_Cuts.gm1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]
2026-09-16 Update bench guide and SDK tests for the rev B digital board
    Regenerate the PCB snapshot for the crystal Pierce digital board, accept
    vias only on wire-link anchors, derive wire links from drawn top routes,
    add --probe 10 for the BNC adapter fixture, drop the external W1 clock
    procedure from the guide and add the 16 September bench plan.
2026-09-16 Declare scope probe attenuation per channel
    The bench fixture has a 10x probe on scope 1 and a 1x probe on scope 2, so
    --probe now takes one value per channel (10,1) and the guide states the
    per-channel setting instead of assuming both probes at 10x.
2026-09-16 Add browser front end and resume support for the AD3 bench tests
    run.py gains an operator layer, case-insensitive confirmations and --resume,
    which carries the leading passed steps of an earlier run of the same board.
    gui.py serves a loopback page with the step wiring, one large READY/ON/OFF
    button and the current field, driving the same run.py logic.
2026-09-16 Record the AD3 V+ voltage and current readback in 3.3 V steps
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2026-09-16 Fail a stuck logic line on its swing instead of erroring; drop the V+ current hint
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2026-09-16 Correct the oscillator finding: unsoldered crystal leg, clocks now on frequency
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2026-09-16 Document the VREF_N headroom failure on the loaded pump rail and the LM358 fix
2026-09-16 Skip the PI_BCLK level check under the 1x probe in the data step; record the Pi-side stream capture
2026-09-16 Ignore KiCad DebugErc.log and drop the one that slipped into the bench folder
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2026-09-17 Ripper identifies records by fingerprint (AcoustID), sends idle albums by itself and manages disk space; bench audio-performance plan; puller replaces re-encoded files
    [ripper.py, test_ripper.py]
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2026-09-18 Ripper: a re-cut or reset counts as album activity for the idle send
    [ripper.py]
2026-09-18 Both channels working: the DACP_L short, and the first audio measurements
    The -5 V wires of §8.4 went on and the right channel did not change, so that
    hypothesis was real but not the whole fault. Underneath it, DACP_L was shorted
    to ground on the right board: no DAC feedback, every integrator into the rails,
    a 42 kHz limit cycle. Found by comparing the same node on the two boards - the
    gate output sat 236 mV above ground instead of swinging to +4.63 V, which is a
    74HC04 driving into a short rather than a dead one. Both channels now read
    third-order shaping and match to within 1 dB.
    Audio performance measured for the first time, after fixing two bugs in the
    bench code that made the first ru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
2026-09-18 figures_music.py: multi-resolution spectrogram, the passage's own level per pitch, a loudest-note lane and a beat lane
    Three FFT lengths centred on the same instants (171 ms below 250 Hz,
    85 ms to 1 kHz, 43 ms above) so bass notes resolve; the edges of the
    hard-cut excerpt are faded so they stop splattering. features() reads
    the bands, hits, per-column pitch classes and the clearest moment of
    each kind from the data; the export carries all of it for the page's
    interactive version, and the SVG draws the same layout.
2026-09-22 Rev C: the whole converter on one fabricated 4-layer board
    PCBWay offered free prototyping, so the four CNC-milled 100 mm boards are
    redrawn as one 170 x 120 mm four-layer through-hole board with the Pi 4
    plugged into its underside on a 2x20 socket. Same block functions as the
    reference sheet; check_rev_c.py proves the only changes are the LM358
    reference, the ferrite on the 5 V inlet and 475 R in BCLK/LRCLK, all from
    the September bench findings.
    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
    [vinyl_adc_rev_c-B_Cu.gbl, vinyl_adc_rev_c-B_Mask.gbs, vinyl_adc_rev_c-B_Silkscreen.gbo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]
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2026-09-22 Measure the idle floor with the turntable connected, and rule out ethernet
    Stylus up and platter stopped, the chain sits 21 dB above the converter's
    own shorted-input floor, so a rip now has about 49 dB of range against
    the converter's 68. What limits a record is no longer the converter.
    L/R coherence splits the floor cleanly: 0.99 below 200 Hz, which can only
    come from a shared ground, and 0.21 above it, which is per-channel and so
    belongs to the phono stage or the cartridge. They are close to equal in
    power, so fixing either alone buys under 4 dB.
    Ethernet is not the path. Unplugged for 37 s and read back out of the
    ripper's ring afterwards, the 50 Hz line moved 0.2 dB. That should have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
2026-09-22 Re-derive the needle detector thresholds for the new input gain
    The trimmers were set for a phono stage on 2026-09-20, +7 dB on where
    they had been. start_db and stop_db are absolute dBFS, so that one
    change put the noise floor above the -65 dBFS stop threshold and no side
    could ever end: two sides ran to the 40-minute cap and one recorded
    straight through a record flip.
    The replacement values are measured rather than shifted by 7 dB, because
    the window is narrower than it was. Silence reads -57.6 dBFS on the
    treble-weighted detector; stop at -53 keeps 93 % of silence under the
    80 % rule while the quietest 30 s of a sparse jazz side reaches only
    61 %. -52 and -54 each leave one margin in si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
    [ripper.py]
2026-09-22 Notify a webhook when a side starts, ends, or reaches the library
    Fires JSON at cfg['notify_url'] on three events, which on this setup is a
    Home Assistant webhook that pushes to the phone. Empty by default, so it
    is off unless configured.
    The side_finished payload carries the median left-right peak difference
    over the side and flags it above 4 dB. That is there because of today:
    the left channel's input came loose 33 minutes into a rip and nothing
    said so until the record was already in the library with three broken
    tracks. A phone buzzing 'the channels are 14 dB apart' would have caught
    it in the room.
    Sending is on its own thread and swallows every exception. A phone that
    cannot be reach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
    [ripper.py]
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2026-09-22 Resize the needle detector's windows when their seconds change
    start_seconds and stop_seconds size deques built in __init__, so setting
    them through /api/config changed a number nothing read: the stop test
    uses the deque's own maxlen. Rebuilding them on a config write makes the
    setting mean what it says without a restart.
    Found while working out why Abbey Road's side two kept fragmenting. A
    30 s window cannot separate a quiet passage from a lifted needle at this
    noise floor - every threshold that stops on silence also cuts the record
    - but a 60 s window can, because a musical gap cannot fill it and
    silence can.
    [ripper.py]
2026-09-22 Stop on a 60 s window at -50 dBFS, measured on four real sides
    At 30 s the detector could not tell a quiet passage from a lifted
    needle: every threshold that stopped on silence also cut a record, and
    Abbey Road's second side fragmented into three. The fix is the window,
    not the threshold. A musical gap cannot fill a minute; silence can.
    Over the four sides recorded today the worst passage reaches 63 % of a
    60 s window against the 80 % rule, while silence reaches 100 %. Both
    margins are double digit, which neither was at 30 s.
    Verified on the hardware with the needle up: the quiet counter ran past
    30 s to 60 and closed the side.
    [ripper.py]
2026-09-22 Stop at -54 dBFS: -50 still cut a side, and the earlier check was circular
    The 60 s window was validated against sides the 30 s rule had already
    closed, so none of them held a 60 s silence and nothing could trigger
    the rule being tested. It looked safe and was not: Abbey Road's second
    side came apart in three again, and Sun King fell across a boundary and
    was dropped, correctly, as a track the splitter only had 89 s of.
    Measured against those fragmented sides instead: at -54 the three
    pieces reach 64, 61 and 71 percent of the window against the 80 percent
    rule, while a finished side still closes. The margin at the closing end
    is thin, so the dashboard stop button remains the reliable answer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
    [ripper.py]
2026-09-25 Rev D and rev E: the converter as a 4-layer Pi HAT, through-hole and SMD
    With PCBWay making the board, the one-board converter becomes a Raspberry
    Pi HAT in two builds of the same circuit. Rev D uses only the DTU shop's
    through-hole parts; rev E uses common surface-mount parts. Both come from
    the reference sheet's blocks, and check_rev_d.py proves each netlist is
    the reference plus exactly the additions: the +5VA analog island, a
    second pump driver, the MCLK damper, eight status LEDs, two buttons, the
    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
    [vinyl_adc_rev_d-B_Cu.gbl, vinyl_adc_rev_d-B_Mask.gbs, vinyl_adc_rev_d-B_Silkscreen.gbo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]
2026-09-25 Rev D ready for PCBWay: printable silkscreen, every legend back
    The library footprints draw their outlines at 0.12 mm and the legends
    used 0.135 mm strokes, both below PCBWay's 0.15 mm silkscreen minimum,
    where lines can print broken or not at all. Every silkscreen stroke is
    now at least 0.15 mm.
    The new layout had also lost the labels that say what things are for:
    LINE IN L/R, TONEARM GND, TRIM L/R, BOND on J4, the write jumper J6,
    J1's 1-2 XTAL / 2-3 GPCLK, and the board title. They are placed next to
    their parts, clear of every outline, and the six references with no free
    spot are printed inside their outlines, under the body, where they can
    be read during assembly.
    DRC is still clean: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
2026-10-08 Ripper: Discogs collection as the record shelf
    Read the Discogs collection (token in ~/vinyl/discogs.token), map each
    record to a MusicBrainz release (Discogs link, barcode, then artist and
    title preferring vinyl with the same track count), cache it with covers
    and sync in short resumable steps on the job queue: at startup when a
    day old, nightly at 04:00 and on demand.
    Identification prefers releases on the shelf, then other pressings of
    an owned album, over other vinyl; the album in use still wins. The
    dashboard gets a My records cover grid (click to rip), sync status and
    a 'not in your Discogs collection' flag. CORS-open API for the Home
    Assistant dashboard: /api/collection, /api/collect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
2026-10-20 Rev D/E: clip comparators sink outside the window, not inside it
    Both LM339 sections had their inputs swapped, so each sank whenever INT1
    sat inside +/-2 V and the CLIP LEDs lit permanently. The gate had been
    written to the same wiring. The as-built rev D files are left as built.
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2026-10-20 Rev D: photos of the PCBWay boards, bench results on the crystal, vertical render shots and the short's build script
2026-10-23 Rev D enclosure, short v2 and channel L Gerbers
    Rev D enclosure: CAD scripts, spec, print files (STL/3MF/STEP/DXF) and the
    SolidCraft assembly with renders. Short v2: the Remotion project, voice/sfx
    scripts and PCB layer art (renders, audio and footage stay local). Channel L
    production Gerbers, bring-up log update and KiCad project tweaks.
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
